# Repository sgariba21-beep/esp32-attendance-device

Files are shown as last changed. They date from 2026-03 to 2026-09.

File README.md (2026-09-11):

# ESP32 Fingerprint Attendance System

Ghanaian schools and institutions still take attendance on paper. A teacher calls a register, marks each name by hand, then copies the totals into another book or a spreadsheet. Roll-call takes class time and the handwritten tallies are easy to miscount and slow to total across a term. This system replaces the register with a fingerprint scan.

An ESP32 device with an R503 fingerprint sensor records each scan, and a Next.js dashboard backed by Supabase handles reporting and the day-to-day management of devices and members. One cloud Supabase project serves every institution, with each tenant's data isolated from the rest. The hardware and software are complete; the first institutional deployment is pending.

---

## Why This Exists

- Ghanaian schools and small institutions track attendance on paper or not at all; the affordable end of the market has no biometric option tied to a reporting dashboard.
- ZKTeco and similar incumbents ship standalone terminals with no multi-tenant cloud dashboard and no remote device management.
- The system is built around term and academic-year structure, with institution type configurable as school, office, or shop.
- Each device is built from off-the-shelf parts at about GHS 1,000.
- The firmware and dashboard are AGPL-3.0 on GitHub; institutions can self-host or use the managed hosted service.

---

## Real-World Deployment

- Status: hardware and software complete; first institutional deployment pending
- Site: [institution name], [town/region]
- Enrolled members: [N]
- Running since: [start date]

Device installed at [institution name]

---

## Architecture

```
┌─────────────────────────────┐
│       ESP32 Devices         │
│  R503 fingerprint sensor    │
│  One device per unit        │
└────────────┬────────────────┘
             │ HTTPS (x-device-secret / x-bootstrap-secret)
             ▼
┌─────────────────────────────┐
│  Supabase Edge Functions    │
│  (cloud)                    │
│  log-attendance             │
│  mark-absent (pg_cron)      │
│  get-enrollment-job         │
│  update-enrollment-job      │
│  register                   │
│  assignment-poll            │
└────────────┬────────────────┘
             │ service role
             ▼
┌─────────────────────────────┐
│   Supabase PostgreSQL       │
│   (cloud)                   │
│   Multi-tenant schema       │
│   RLS policies (defence-in- │
│   depth; dormant for svc    │
│   role access)              │
└─────────────────────────────┘
             ▲
             │ server-side only (service role)
┌────────────┴────────────────┐
│     Next.js Dashboard       │
│     Deployed on Vercel      │
│  All Supabase calls are     │
│  server-side (no browser    │
│  exposure of keys)          │
└─────────────────────────────┘
```

---

## Tech Stack

| Layer | Technology |
|---|---|
| Firmware | Arduino (ESP32), FreeRTOS, R503 fingerprint library, SSD1306 OLED (Adafruit SSD1306 + GFX) |
| Database | Supabase (cloud PostgreSQL + Auth + Storage + pg_cron) |
| Edge functions | Deno (Supabase Edge Functions) |
| Dashboard | Next.js App Router, shadcn/ui, TailwindCSS |
| Dashboard PWA | Installable web app — `manifest.webmanifest` + a minimal service worker (installability only, no offline cache) and an in-app install prompt |
| Hosting | Vercel (dashboard) |

> **Note on Next.js:** This project uses a version with breaking API changes from standard Next.js. Middleware lives in `frontend/proxy.ts`, not `middleware.ts`. Read `frontend/AGENTS.md` before writing any Next.js code.

---

## Hardware

### Components

| Component | Spec |
|---|---|
| Microcontroller | ESP32 (dual-core, 240 MHz) |
| Fingerprint Sensor | R503 Capacitive |
| RTC Module | DS3231 |
| Display (optional) | SSD1306 0.96" 128×64 I²C OLED @ address 0x3C — the firmware runs headless if it is absent or fails to init |
| Carrier PCB | Custom 2-layer KiCad interconnect board — no active parts; seats the ESP32 module and provides keyed connectors for the R503 (JST-SH), the RTC + OLED I²C group, and a JST-GH 5 V input. Source in [`hardware/PCBs/`](hardware/PCBs/) |
| Enclosure | 3D-printed base + lid (+ an OLED bezel variant for display builds). FreeCAD source and print-ready 3MF in [`hardware/CAD files/`](hardware/CAD%20files/) |

### Wiring

| Signal | ESP32 Pin |
|---|---|
| R503 TX → ESP32 RX | GPIO 16 |
| R503 RX → ESP32 TX | GPIO 17 |
| DS3231 SDA | GPIO 21 |
| DS3231 SCL | GPIO 22 |
| OLED SDA | GPIO 21 (shared I²C bus with the DS3231) |
| OLED SCL | GPIO 22 (shared I²C bus with the DS3231) |

---

## Firmware Architecture

Single sketch: `firmware/ClassAttendance_Current_RTC/ClassAttendance_Current_RTC.ino`. Three FreeRTOS tasks pinned across the two cores.

### Tasks

| Task | Core | Responsibility |
|---|---|---|
| `FingerprintTask` | 1 | Scan loop, match against the local fid map, LED feedback, enrollment execution, captive-portal launch on master-finger scan. Writes each scan to SPIFFS then signals `NetworkTask` via binary semaphore. |
| `NetworkTask` | 0 | Provisioning, waiting on scan semaphore from `FingerprintTask`, rotate-then-process SPIFFS queue flush to `log-attendance`, NTP→RTC sync, WiFi reconnect, and a server-reachability watchdog that reboots the device after a sustained inability to reach the backend. |
| `EnrollmentTask` | 0 | Polls `get-enrollment-job`, hands jobs to `FingerprintTask`, reports results durably (retried until acknowledged), acts on the decommission signal (wipes identity and reboots into provisioning). |

Inter-task communication:

- `memQueueSem` is a binary semaphore used only as a signal: `FingerprintTask` gives it after writing a scan to SPIFFS; `NetworkTask` waits on it (or a 15 s periodic timeout) before calling `flushQueue()`. There is no in-memory scan queue.
- Enrollment jobs pass from `EnrollmentTask` to `FingerprintTask` through `currentEnrollJob`, guarded by `enrollMutex` and signalled by `enrollSem`.
- `spiffsMutex` serialises every SPIFFS access across all three tasks.

### Display (OLED)

An optional SSD1306 128×64 panel on the shared I²C bus. `display.begin()` is attempted once in `setup()`; on failure `displayAvailable = false` and the firmware runs headless with no behaviour change. There is no dedicated display task — rendering is driven from a Core-0-safe mailbox. Tasks post card state (idle clock, scan verdict, enrollment step, master-finger confirm, provisioning, OTA) into the mailbox and never touch the `display` object directly. Tier-2 status (queue depth, dropped-record count, degraded / offline) is overlaid on the idle screen; the panel sleeps after 120 s idle and wakes on the next event. The per-institution `member_name_display` setting (fetched via `get-enrollment-job`, cached in SPIFFS with `config_rev`) controls how much of a member's name a scan card shows.

### Offline queue

- **Durability-first:** each scan is written to `/queue.txt` in SPIFFS synchronously inside `FingerprintTask` before any network attempt. The scan is never held only in RAM.
- **Rotate-then-process:** when `NetworkTask` flushes, it atomically renames `/queue.txt` → `/queue_inflight.txt` under the lock, then releases the lock. `FingerprintTask` can keep appending to a fresh `/queue.txt` while the network send runs without holding `spiffsMutex`.
- **Crash recovery:** if power is cut mid-flush, `/queue_inflight.txt` is orphaned. On the next boot, `recoverInflightQueue()` runs before tasks start and merges it back into `/queue.txt`.
- On flush, 5xx/429/network errors keep a record for retry; 4xx drops it.
- Caps: 1000 entries, 256 KB, 7-day age. Oldest records are trimmed first.

### Scan IDs

Each scan gets a `scan_id` of `scan-YYYYMMDDhhmmss-<member-sid>`, with the timestamp read from the DS3231 RTC. The RTC clock survives reboots and power loss and is synced from NTP on boot and after each reconnect.

### OTA

- On boot, with WiFi up and assignment not pending, the device waits a random jitter of 0–120 s (seeded from hardware entropy) before checking for updates. This prevents a fleet-wide power blip from hitting GitHub's 60 req/hr unauthenticated rate limit simultaneously.
- The device GETs `releases/latest` from the GitHub API. Release tags must be `firmware-v<major>.<minor>.<patch>`. The tag version is compared against the compiled-in `FIRMWARE_VERSION`; only a strictly newer version flashes.
- The release's `.bin` asset is streamed through the `Update` library. The sensor LED holds red while writing, and the device reboots into the new image on success.

---

## Database Schema

All dashboard data access uses `createAdminClient()` (service role — bypasses RLS). RLS policies exist as defence-in-depth and will become load-bearing if authenticated client access is introduced.

```sql
-- Institution registry (one row per tenant)
-- type: 'school' | 'office' | 'shop'
-- theme_primary: hex brand colour injected as CSS custom properties server-side (no FOUC)
-- theme_preset: curated palette key (e.g. 'indigo', 'rose') or 'custom'; null → platform default
-- device_secret: shared bootstrap secret — TRANSITIONAL. Will be removed once all
--   devices have been re-provisioned with per-device secrets (devices.device_secret).
-- tracked_weekdays: smallint[] of ISO weekday numbers (1=Mon … 7=Sun) attendance is
--   tracked on. Replaces the removed skip_weekends boolean. log-attendance ignores
--   scans on other days; mark-absent generates no rows for them.
-- time_format: '12h' | '24h' — dashboard clock rendering only; stored times stay UTC / 24h.
-- track_lateness / expected_start_time / late_grace_minutes and
--   track_early_leaving / expected_end_time / early_leave_grace_minutes:
--   optional per-institution punctuality thresholds that drive attendance.punctuality.
-- member_name_display: 'full' | 'first' | 'initial_last' | 'sid' | 'none' — how much of a
--   member's name the device OLED shows on a scan card (enrollment always shows the full name).
-- currency: ISO-4217 display currency for the retail module (formatting only, no FX).
-- sell_products / sell_services / loyalty_enabled: shop-module switches.
-- status: 'active' | 'suspended' | 'deactivated' — non-active tenants are gated to /suspended.
-- config_rev: bigint bumped by the institutions_touch trigger on any row change; the device
--   polls it to know its cached device_config is stale. updated_at is bumped by the same trigger.
institutions    (id, name, type, logo_url, label_member, label_members, label_group,
                 label_unit, label_period, label_staff, label_staff_plural,
                 track_students, track_staff, student_scan_mode, staff_scan_mode,
                 tracked_weekdays, timezone, time_format, track_lateness,
                 expected_start_time, late_grace_minutes, track_early_leaving,
                 expected_end_time, early_leave_grace_minutes, member_name_display,
                 currency, sell_products, sell_services, loyalty_enabled, status,
                 device_secret, config_rev, created_at, updated_at,
                 theme_primary, theme_preset)

-- Members (students, staff, customers, etc.) — scoped to institution
-- member_type: 'student' | 'staff'  (default 'student')
-- sid is UNIQUE PER INSTITUTION (institution_id, sid), not globally
-- device_id FK is ON DELETE SET NULL (device deletion preserves member records)
members         (id, sid, fullname, group_name, unit_name, fin1, fin2, status, member_type,
                 device_id→devices SET NULL, institution_id, created_at)

-- One ESP32 per unit — scoped to institution
-- device_secret: per-device secret issued at provisioning time by /assignment-poll
-- revoked: true blocks the device from logging attendance (instant lockout)
-- provisioning_token: issued by /register, required by /assignment-poll (H7)
devices         (id, group_name, unit_name, display_name, mac, provisioning_token,
                 device_secret, revoked, institution_id)

-- Academic periods — scoped to institution (nullable for office/shop-type institutions)
periods         (id, term, year, status, start_date, end_date, institution_id)

-- Attendance records — scoped to institution
-- status: 'present' | 'absent'
-- scan_type: 'present' | 'time_in' | 'time_out'  (CHECK constraint — 'absent' is a status, not a scan_type)
-- punctuality: 'on_time' | 'late' | 'early_leave' | null — verdict fixed at scan time from the
--   institution's thresholds; null when tracking is off or the row is a mark-absent placeholder
-- date/time are stored in the INSTITUTION's timezone (log-attendance + mark-absent agree)
-- scan_id is UNIQUE PER INSTITUTION (institution_id, scan_id); dedup also on (member_id, date, scan_type)
-- device_id FK is ON DELETE SET NULL
attendance      (id, member_id→members, period_id→periods, device_id→devices SET NULL,
                 date, time, status, scan_type, punctuality, scan_id, institution_id)

-- Remote fingerprint enrollment queue
-- command: 'register' | 'delete' | 'clearall' | 'register-master' | 'delete-master'
-- member_id: FK→members (renamed from student_id). NULL for clearall / register-master / delete-master.
-- allow_overwrite: operator confirmed overwriting an already-occupied sensor slot
--   (register / register-master only). The device refuses an occupied slot unless this is true.
-- dispatched_at / attempts / last_error: dispatch tracking. get-enrollment-job re-delivers a job
--   stuck in_progress past a timeout and auto-fails it (with last_error) after a capped number of
--   attempts. The enrollment_jobs_status_guard trigger makes 'completed' / 'failed' terminal.
-- device_id FK is ON DELETE SET NULL
enrollment_jobs (id, device_id→devices SET NULL, member_id→members, finger_slot,
                 command, status, fid, note, allow_overwrite, dispatched_at, attempts,
                 last_error, institution_id, created_at)

-- Holidays (date ranges) — scoped to institution
-- recurring: true = matched by month/day every year (year-wrap ranges supported)
holidays        (id, label, start_date, end_date, recurring, institution_id)

-- Dashboard user roles — scoped to institution (platform_admin has null institution_id)
-- assigned_device_id: FK that pins a session to one device. REQUIRED for teacher/staff
--   (unresolved → they see nothing); OPTIONAL for admin (bound → records + enrollment
--   scoped to that device; unbound → whole institution). Preferred over the legacy
--   assigned_unit string; backfilled by migration. Resolved by dal.ts resolveDeviceScope().
profiles        (id→auth.users, role, assigned_unit, assigned_device_id→devices SET NULL,
                 institution_id)

-- Deferred SPIFFS-wipe queue — no FK, survives device row deletion
device_resets   (device_id UUID, created_at)

-- Polling watermark — one row per institution, updated by triggers on attendance,
-- members, devices, and periods. The dashboard polls /api/changes every 12 s and
-- calls router.refresh() only when last_change_at has advanced. Replaces the
-- previous SSE-based realtime stream (eliminated REPLICA IDENTITY FULL WAL amplification).
institution_activity  (institution_id PK→institutions, last_change_at timestamptz)
```

### Migrations

All migrations are in `backend/supabase/migrations/`. They must be reviewed and applied manually — do not auto-apply to cloud.

---

## Auth & RBAC

Authentication uses Supabase Auth (server-side only — all Supabase calls go through Next.js server components and API routes, never from the browser).

### Account Types

| Role | Scope | Access |
|---|---|---|
| `platform_admin` | Cross-institution (no institution_id) | All pages, bypasses all role gates, operates via service role. Responsible for creating institutions and bootstrapping first super_admin per institution. |
| `super_admin` | Institution-scoped | All pages — devices, enrollment, promotion, academic, members, attendance, user management. Can manage users within their institution but cannot create platform_admins. |
| `admin` | Institution-scoped (optionally device-scoped) | Members, academic, promotion, attendance — no devices or enrollment. May optionally be pinned to a single device via `assigned_device_id`; when pinned, attendance/members and enrollment are scoped to that device, otherwise the whole institution. |
| `teacher` | Institution-scoped, unit-scoped | Read-only attendance and members, filtered to their `assigned_device_id` (FK, with `assigned_unit` string-match fallback for unbackfilled profiles). |
| `staff` | Institution-scoped, unit-scoped | Same as teacher — read-only attendance and members, filtered to their unit. The `/staff` roster page is not visible in the nav for this role. |
| `cashier` | Institution-scoped (shop type) | Sales, Clients, and Catalog pages only. Intended for retail staff at shop-type institutions. Cannot access attendance, members, devices, or admin pages. |

### How it works

- `frontend/lib/supabase/dal.ts` exports `verifySession()`, `requireRole(...roles)`, `getInstitution(institutionId)`, `resolveInstitutionScope(session, institutionParam?)`, and `resolveDeviceScope(session)` (returns `{ mode: 'all' | 'device' | 'none' }` — the single device a session is pinned to, if any).
- `verifySession()` and `getInstitution()` are both `cache()`-wrapped — one DB hit per render cycle regardless of how many components call them.
- `requireRole()` calls `verifySession()` and redirects to `/unauthorized` if the role doesn't match. `platform_admin` bypasses all role checks.
- `resolveInstitutionScope()` enforces tenant scoping: platform_admin may pass an explicit institution param; all other roles are always locked to their own `institution_id` regardless of query params.
- **Fail-closed:** an authenticated user with no `profiles` row (or no role) is redirected to `/unauthorized` — it does **not** default to any role. Public sign-up is disabled in Supabase Auth; accounts are created only via `/users` and `/onboarding`.
- **Tenant ownership:** because the dashboard uses the service role (RLS bypassed), every mutating server action verifies the target record belongs to the caller's institution via `lib/supabase/ownership.ts` (`ownsRecord`). `platform_admin` is cross-tenant by design.
- The dashboard layout calls `verifySession()` and passes `role` to the sidebar and mobile nav, which filter nav items by role.
- `teacher` and `staff` are always device-scoped via `assigned_device_id` (FK, preferred) or `assigned_unit` (legacy string); an unresolved assignment means they see nothing, never everything. `admin` may optionally carry the same binding. Attendance and member data — and the CSV export (`/api/attendance/export`) — is filtered server-side to that device before rendering.
- Run `node scripts/check-rbac.mjs` (from `frontend/`) to verify every page under `(dashboard)` has a `requireRole(` call. Exits 1 with a list if any are ungated.

### Creating the first super_admin (per institution)

After creating an institution in Supabase, insert a profile row for the Supabase Auth user:

```sql
insert into profiles (id, role, institution_id)
values ('<auth-user-uuid>', 'super_admin', '<institution-uuid>');
```

Additional accounts are managed through the `/users` page in the dashboard.

---

## Dashboard Pages

### Attendance & roster (all institution types)

| Route | Access | Description |
|---|---|---|
| `/` | All roles | Overview — today's present/absent counts, attendance rate, and a recent-activity feed (last 8 scans). `teacher`/`staff` see only their unit. `platform_admin` sees a cross-tenant summary: institution count, active members, devices online, and total scans today. |
| `/attendance` | All roles | Attendance records with date, period, member, unit, status, and type filters. Per-member stats panel. Results paginated at 50 rows. `teacher`/`staff` see only their unit; a teacher with no device assigned sees an empty-state prompt to contact their administrator. Time-in/time-out pairs shown on a single row, with **Late** / **Early** badges when the institution has punctuality thresholds enabled. CSV export available. |
| `/members` | All roles except cashier | Member roster (non-staff). `teacher`/`staff` see only their unit, no edit controls. |
| `/staff` | super_admin, admin, platform_admin | Staff member roster. Visible only when `track_staff = true`. |
| `/devices` | super_admin, platform_admin | ESP32 device registry and provisioning — assign unregistered devices to units, revoke devices. Search + institution filter for platform_admin. Devices only enter via physical provisioning (no manual create). |
| `/academic` | super_admin, admin, platform_admin | Academic periods and holidays. Nav label is "Academic" (school), "Periods & Holidays" (office), or "Closed Days" (shop — holidays only). Supports recurring (yearly) holidays matched by month/day. |
| `/enrollment` | super_admin, platform_admin | Fingerprint enrollment job queue — `register`, `delete`, `clearall`, `register-master`, `delete-master` commands sent to devices, with retry / cancel controls for failed or stuck jobs (jobs stranded `in_progress` are also re-delivered and self-healed server-side). Validates member institution + device assignment before dispatching. Institution column for platform_admin. |
| `/promotion` | super_admin, admin, platform_admin | Bulk year-end promotion — moves members to the next group, resets finger slots, deactivates final-year members. School-type institutions only. |
| `/settings` | super_admin, platform_admin | Institution config — name, logo, brand colour, type, label overrides, per-type scan modes, tracked weekdays (7-day selector, replaces skip_weekends), late-arrival / early-departure thresholds, timezone, 12h/24h time display, name-shown-on-device, and (shop) currency / offerings / loyalty toggles. |
| `/institutions` | platform_admin | All institutions with member/device counts. Edit or delete any institution (deletion fans out SPIFFS wipe to all assigned devices). |
| `/institutions/[id]` | platform_admin | Edit a specific institution's settings. |
| `/onboarding` | platform_admin | Create a new institution and its first super_admin account. Includes timezone selector (Africa/Accra default) and neutral label presets for shop-type institutions. |
| `/users` | super_admin, admin, platform_admin | Dashboard account management. `admin` can view the list and change their own password only. `super_admin`/`platform_admin` can create, edit, and delete accounts. |
| `/unauthorized` | — | Shown when a user navigates to a page their role cannot access. |
| `/suspended` | — | Shown when a user's institution is suspended/deactivated. Lives outside `(dashboard)` to avoid re-entering `verifySession`. Sign-out is the only available action. |

### Retail / loyalty (shop-type institutions only)

| Route | Access | Description |
|---|---|---|
| `/sales` | super_admin, admin, cashier | Record sales transactions. Line-item entry with catalog lookup, optional staff assignment, per-sale note. Low-stock warning surfaced as a non-blocking alert after a successful sale. |
| `/clients` | super_admin, admin, cashier | Client roster with visit history and loyalty point balance. Search by name or phone. |
| `/catalog` | super_admin, admin, cashier | Products and services catalog. Stock quantity tracked for products; low-stock threshold warnings on the Reports page. |
| `/rewards` | super_admin, admin | Loyalty reward redemption and tier management. Gated additionally by `loyalty_enabled` on the institution. |
| `/reports` | super_admin, admin | Sales analytics — daily/weekly takings, revenue by client and staff member, popular items, visit frequency, low-stock products, loyalty rewards issued. CSV export for takings, client revenue, and staff revenue. |

### Screenshots

Dark-mode captures of the dashboard live in [`images/`](images/) — one set per
institution type (38 pages in all). See [`images/README.md`](images/README.md)
for the full index.

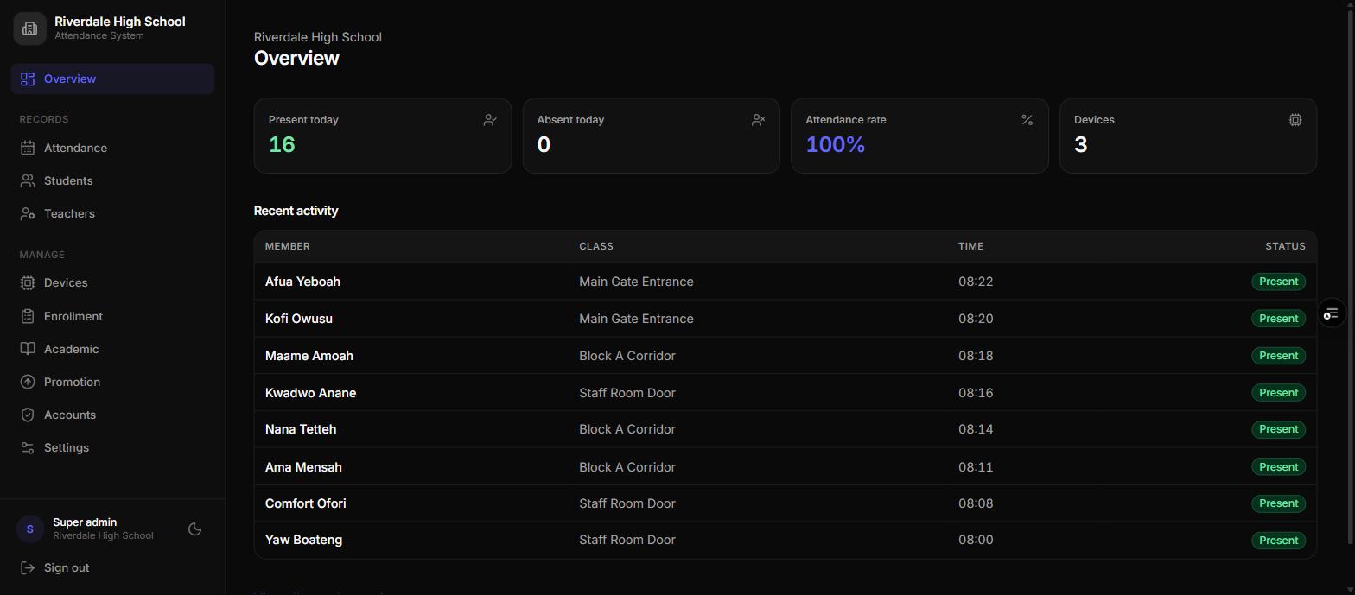
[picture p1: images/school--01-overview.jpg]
School — overview

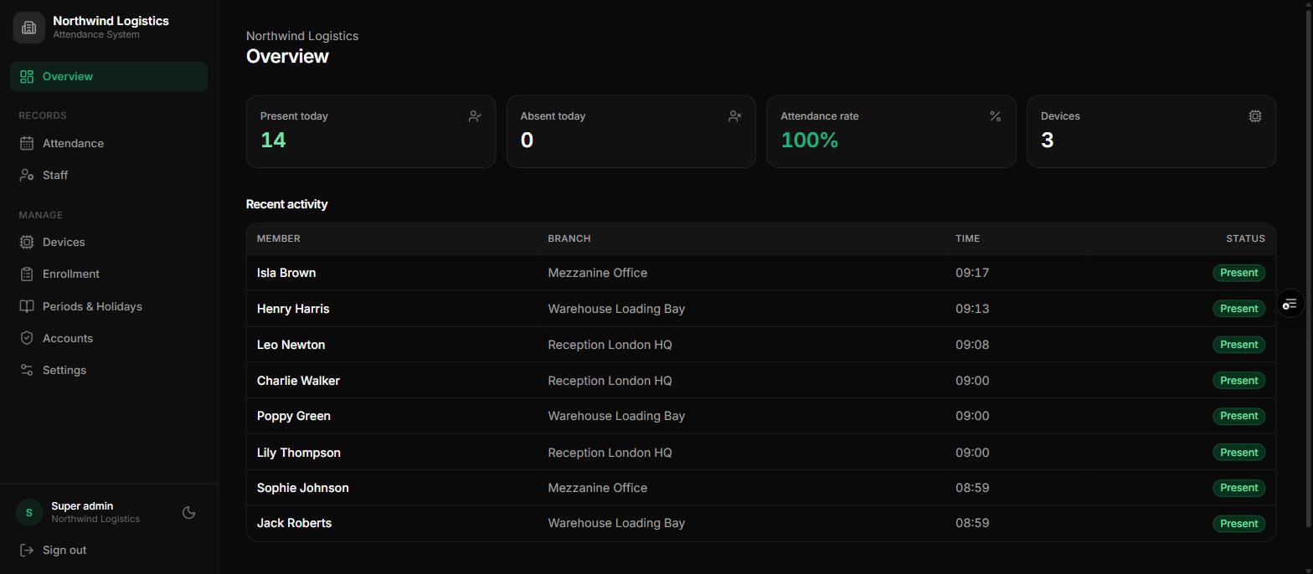
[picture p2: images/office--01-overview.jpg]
Office — overview

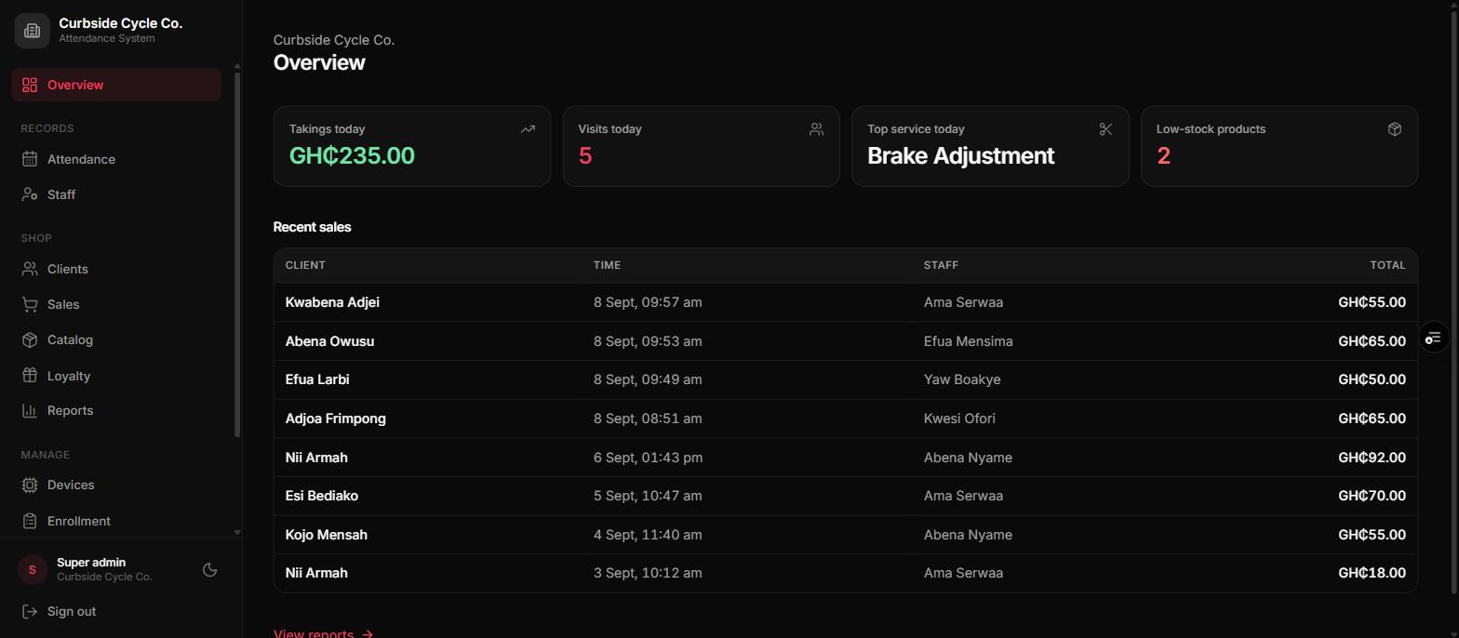
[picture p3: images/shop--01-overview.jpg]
Shop — overview with the retail module


> **Disclaimer — dummy data.** Every screenshot is taken from throwaway demo
> institutions (Riverdale High School, Northwind Logistics, Curbside Cycle Co.)
> created solely for documentation. All names, clients, sales, attendance
> records and figures shown are fabricated — not real people, and not the real
> institutions that use this system.

---

## Device Authentication & Provisioning

### Provisioning (new devices)

1. Device boots with no `device_identity.json` in SPIFFS.
2. Calls `POST /register` with its MAC address (`x-bootstrap-secret` header).
3. Receives a `device_id`, a `provisioning_token`, and `status: "pending"`. The device persists both to `provisioning.json` so a reboot keeps the token.
4. Shows yellow breathing LED and polls `POST /assignment-poll` every 5 s, sending `{ device_id, provisioning_token }`.
5. An admin assigns the device from the dashboard `/devices` page.
6. Poll returns `status: "assigned"` with `institution_id`, `device_secret` (per-device), `display_name` — **only if the provisioning_token matches** (otherwise 401).
7. Device writes `device_identity.json` to SPIFFS, deletes `provisioning.json`, and begins normal operation.

> **TLS:** the firmware validates server certificates (`certs.h` → `ROOT_CA_BUNDLE`, includes intermediates for WE1/Sectigo DV E36 — mbedTLS cannot do AIA fetching).
> The bootstrap secret lives in `secrets.h` (gitignored). Copy `secrets.example.h` → `secrets.h` and set the same value as the `BOOTSTRAP_SECRET` secret in Supabase Edge Functions.

### Normal operation

- Every scan: `POST /log-attendance` with `{ device_id, ... }` body and `x-device-secret: <per-device secret>` header. A transitional dual-path also accepts the legacy shared `institutions.device_secret` for devices not yet re-provisioned.
- Enrollment polling: `POST /get-enrollment-job` with `{ device_id }`, authenticated via per-device secret. A job left `in_progress` past a timeout (device rebooted, ack lost) is re-delivered, and auto-failed after a capped number of attempts.
- Enrollment result: `POST /update-enrollment-job` with `{ id, device_id, institution_id, status, ... }`, authenticated via per-device secret. `institution_id` is derived server-side from the device row — the body value is ignored. The device retries this report until it lands (firmware ≥ 1.10.0); the `enrollment_jobs_status_guard` trigger keeps a terminal `completed` / `failed` status from being pulled backwards by a late write.
- Decommission signal: if `get-enrollment-job` returns `decommissioned: true`, the device wipes its identity and reboots. The `device_resets` row persists until the device re-registers (not consumed on read — durable against race conditions).
- `pg_cron` calls `POST /mark-absent` daily with `x-cron-secret`. Processes institutions in batches of 8 concurrently. **Requires the `pg_net` extension** — enable it in the Supabase dashboard under Database → Extensions.

### Revoking a device

Set `devices.revoked = true` in the database. The device's next `log-attendance` call receives 401 immediately. For permanent decommission, also insert into `device_resets`.

### OTA

Firmware checks `https://api.github.com/repos/sgariba21-beep/esp32-attendance-device/releases/latest` on boot after a random jitter delay. Releases must be tagged `firmware-v<version>` (e.g. `firmware-v1.10.0`; current `FIRMWARE_VERSION` is `1.10.0`). The `.bin` asset is downloaded and flashed via the ESP32 `Update` library.

---

## Key Files

```
esp32-attendance-device/
├── README.md
├── docs/
│   ├── README.md                           ← index: which document is for whom, what to hand over
│   ├── for-clients/                        ← PDFs for institutions: role guides, type guides, privacy note
│   ├── for-operators/                      ← platform manual, technical docs, secret-rollout guide, e2e checklist
│   └── source/                             ← Markdown sources + build.py — edit these, not the PDFs
├── firmware/
│   └── ClassAttendance_Current_RTC/
│       ├── ClassAttendance_Current_RTC.ino ← ESP32 firmware (single sketch)
│       ├── certs.h                         ← ROOT_CA_BUNDLE (includes intermediates)
│       ├── secrets.example.h               ← template for secrets.h (gitignored)
│       └── secrets.h                       ← BOOTSTRAP_SECRET — gitignored, create from example
├── backend/
│   └── supabase/
│       ├── config.toml                     ← edge function config (verify_jwt = false for all)
│       ├── migrations/                     ← applied to cloud manually; do NOT auto-apply
│       └── functions/
│           ├── log-attendance/             ← dual-path auth: per-device + transitional shared secret
│           ├── mark-absent/                ← BATCH_SIZE=8 concurrent; recurring holiday support
│           ├── get-enrollment-job/         ← per-device auth; decommission signal is persistent
│           ├── update-enrollment-job/      ← per-device auth; institution derived from device row
│           ├── register/
│           └── assignment-poll/            ← issues per-device secret on first assignment
└── frontend/
    ├── proxy.ts                            ← Next.js middleware (NOT middleware.ts); matcher excludes
    │                                         /api, _next, and the PWA assets (manifest.webmanifest, sw.js, icons/)
    ├── next.config.ts                      ← sends Cache-Control: no-cache for /sw.js
    ├── AGENTS.md                           ← read before writing any Next.js code
    ├── scripts/
    │   ├── check-rbac.mjs                 ← CI guard: exits 1 if any dashboard page lacks requireRole
    │   └── generate-icons.mjs             ← regenerates the PWA icon set from the SVG source
    ├── app/
    │   ├── manifest.ts                    ← web app manifest, served at /manifest.webmanifest (platform branding only)
    │   ├── (auth)/login/                  ← password is NOT trimmed before submission
    │   ├── (dashboard)/
    │   │   ├── layout.tsx                 ← verifySession, generateMetadata (dynamic tab title)
    │   │   ├── (admin)/layout.tsx         ← route-group gate for admin-only pages
    │   │   ├── attendance/
    │   │   ├── members/
    │   │   ├── staff/
    │   │   ├── devices/
    │   │   ├── academic/
    │   │   ├── enrollment/
    │   │   ├── promotion/
    │   │   ├── settings/
    │   │   ├── institutions/[id]/
    │   │   ├── onboarding/
    │   │   ├── users/
    │   │   ├── sales/                     ← shop only; low-stock warning after sale
    │   │   ├── clients/                   ← shop only; visit history + loyalty balance
    │   │   ├── catalog/                   ← shop only; products + services
    │   │   ├── rewards/                   ← shop only; loyalty_enabled gate
    │   │   └── reports/                   ← shop only; takings, revenue, low-stock analytics
    │   ├── api/
    │   │   ├── signin/
    │   │   ├── signout/
    │   │   ├── enrollment-stream/         ← SSE stream for enrollment job updates (kept)
    │   │   ├── realtime-stream/           ← 410 tombstone — use /api/changes instead
    │   │   ├── changes/                   ← watermark poll endpoint (replaces SSE stream)
    │   │   ├── attendance/export/         ← CSV export with full filter parity
    │   │   └── reports/{takings,clients,staff}/export/  ← shop report CSV exports
    │   ├── suspended/                     ← institution suspended; sign-out only
    │   └── unauthorized/
    ├── lib/
    │   ├── types.ts                       ← shared TS types
    │   ├── theme.ts                       ← per-institution brand theming
    │   └── supabase/
    │       ├── dal.ts                     ← verifySession, requireRole, getInstitution,
    │       │                                 resolveInstitutionScope, resolveDeviceScope, UserRole
    │       └── server.ts                  ← createAuthClient, createAdminClient
    └── components/
        ├── sidebar.tsx
        ├── mobile-header.tsx
        ├── mobile-bottom-nav.tsx
        ├── theme-toggle.tsx
        ├── realtime-refresh.tsx           ← polls /api/changes every 12 s; router.refresh() on watermark advance
        ├── session-manager.tsx            ← inactivity timeout + sessionStorage guard
        ├── pwa/                           ← service-worker registration + in-app install prompt
        └── ui/
            └── single-select.tsx
```

---

## Phase Status

| Phase | Description | Status |
|---|---|---|
| 1 | Cloud deployment (single-tenant) | ✅ Complete |
| 2 | Multi-tenant schema + edge functions | ✅ Complete |
| 3 | Firmware provisioning flow | ✅ Complete |
| 4 | Frontend — de-brand, institution config, devices page, settings | ✅ Complete |
| 5 | Captive portal — WiFi-only | ✅ Complete |
| 6 | Retail / loyalty module — shop-type tenants, cashier role, sales/clients/catalog/rewards/reports | ✅ Complete |
| 7 | Security hardening — per-device secrets, SPIFFS-only durable queue, tenant isolation fixes, polling watermark | ✅ Complete |
| 8 | OLED display — device-side status screen: idle clock, scan / enrollment / portal / master-confirm cards, degraded & offline states | ✅ Complete |
| 9 | Reliability & reach — enrollment-job self-healing (re-delivery, retry/cancel, status guard), firmware server-reachability watchdog, per-institution tracked weekdays / time format / punctuality thresholds, installable PWA | ✅ Complete |

---

## Roadmap

- [x] Installable PWA (add-to-home-screen) — native iOS/Android app still TBD
- [ ] GES-formatted report exports
- [ ] SMS attendance notifications
- [ ] Analytics dashboard with term-over-term trends
- [ ] Offline-first mobile enrollment app
- [ ] Multi-device per unit support

---

## Contributing

See [CONTRIBUTING.md](CONTRIBUTING.md) for the repo layout and local setup steps for the frontend and firmware.

---

## License

AGPL-3.0. See [LICENSE](LICENSE).

Network use of a modified version requires releasing source under the same license. Contact sgariba21@gmail.com for commercial licensing or self-hosting arrangements.

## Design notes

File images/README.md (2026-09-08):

# Dashboard screenshots — demo institutions

Dark-mode captures of the live dashboard (`esp32-attendance-device-y9cs.vercel.app`),
one set per institution type. Taken 2026-09-08 against three throwaway demo
tenants seeded in the production Supabase project alongside the real ones (the
real institutions are untouched and never appear in these shots — every capture
was taken while signed in as the demo tenant's own `super_admin`, which the app
hard-scopes to that tenant). All 18 `shop--*` shots plus the two settings shots
were re-taken after the `7bd44ab` "drop salon vocabulary" cleanup reached the
live deployment, so nothing here reads "stylist".

Filenames: `<type>--<nn>-<page>.jpg`. JPEG because that is what the capture path
produces; ~1250–1570 px wide.

## The demo institutions

| Type | Name | Timezone | Currency | Brand | Admin login |
|---|---|---|---|---|---|
| `school` | Riverdale High School | Africa/Accra | GHS | Indigo `#6366f1` | `riverdale.admin@example.com` |
| `office` | Northwind Logistics | Europe/London | GBP | Emerald `#10b981` | `northwind.admin@example.com` |
| `shop`  | Curbside Cycle Co. | Africa/Accra | GHS | Rose `#f43f5e` | `curbside.admin@example.com` |

Each was created through the platform-admin **Create institution** flow, then
seeded via SQL: ~8–26 members, 3 devices, an active + a past period, 1–2
holidays, 5 enrolment jobs, and ~12–18 days of attendance history plus a partial
current day. Riverdale and Northwind track late arrivals / early departures;
Curbside adds the full retail module — 15 clients, 8 products, 6 services, 26
sales, 3 loyalty rules with 5 issuances.

## Inventory

### school/ — Riverdale High School (11)
| File | Page |
|---|---|
| `school--01-overview.jpg` | Overview |
| `school--02-attendance.jpg` | Attendance (records) |
| `school--03-students.jpg` | Students |
| `school--04-teachers.jpg` | Teachers |
| `school--05-devices.jpg` | Devices |
| `school--06-enrollment.jpg` | Enrollment |
| `school--07-academic-terms.jpg` | Academic → Terms |
| `school--08-academic-holidays.jpg` | Academic → Holidays |
| `school--09-promotion.jpg` | Promotion (empty state — see notes) |
| `school--10-accounts.jpg` | Accounts |
| `school--11-settings.jpg` | Settings (identity + branding) |

### office/ — Northwind Logistics (9)
| File | Page |
|---|---|
| `office--01-overview.jpg` | Overview |
| `office--02-attendance.jpg` | Attendance (records) |
| `office--03-staff.jpg` | Staff |
| `office--04-devices.jpg` | Devices |
| `office--05-enrollment.jpg` | Enrollment |
| `office--06-periods.jpg` | Periods & Holidays → Quarters |
| `office--07-holidays.jpg` | Periods & Holidays → Holidays |
| `office--08-accounts.jpg` | Accounts |
| `office--09-settings.jpg` | Settings (identity + branding) |

### shop/ — Curbside Cycle Co. (18)
| File | Page |
|---|---|
| `shop--01-overview.jpg` | Overview |
| `shop--02-attendance.jpg` | Attendance (records) |
| `shop--03-staff.jpg` | Staff |
| `shop--04-clients.jpg` | Clients |
| `shop--05-sales.jpg` | Sales |
| `shop--06-catalog-products.jpg` | Catalog → Products |
| `shop--07-catalog-services.jpg` | Catalog → Services |
| `shop--08-loyalty-rules.jpg` | Loyalty → Rules |
| `shop--09-loyalty-history.jpg` | Loyalty → History |
| `shop--10-reports-takings.jpg` | Reports → Takings |
| `shop--11-reports-by-staff.jpg` | Reports → By staff |
| `shop--12-reports-items.jpg` | Reports → Items |
| `shop--13-reports-low-stock.jpg` | Reports → Low stock |
| `shop--14-devices.jpg` | Devices |
| `shop--15-enrollment.jpg` | Enrollment |
| `shop--16-closed-days.jpg` | Closed Days |
| `shop--17-accounts.jpg` | Accounts |
| `shop--18-settings.jpg` | Settings (identity + branding; "Shop type tracks staff") |

## Notes

- **Promotion (school):** shows the "no devices set up" empty state. The
  promotion calculator derives the form ladder from *device* `group_name`s
  (expecting `Form 1`, `Form 2`, …); the demo's devices are named by physical
  location (`Main Gate`, `Block A`, …), so no ladder is inferred. Real content
  would need devices organised per year-group.
- **Accounts** pages show a single account each — the tenant's first
  `super_admin`. Additional accounts can only be added through the in-app
  "Add account" flow.
- `member_name_display` and a couple of `discount`-driven zero-total sales were
  left at defaults / tidied; nothing else was hand-corrected.

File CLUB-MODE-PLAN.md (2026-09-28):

# Club Mode — Session-Based Attendance

**Status:** Phases 1 and 2 **live in cloud** (2026-09-26) and verified end to end.
Phase 3 migrations **live in cloud** (2026-09-27); dashboard on `club-mode`.
Phase 4 backend **live in cloud** (2026-09-28): migration applied, `log-attendance` v17
and `get-enrollment-job` v16 deployed, verified over HTTPS. Firmware 1.11.0 built but
**not released** (no `firmware-v1.11.0` tag) and not yet tested on hardware.
**Target:** A 4th institution type, `club`, whose unit of attendance is a *meeting*
rather than a *day*.

<!-- Do NOT auto-apply any migration in this document to cloud. Review first. -->

---

## 1. The problem

The system today assumes every tenant takes attendance **every tracked weekday**.
That assumption is load-bearing in four places:

| Where | What it assumes |
|---|---|
| `attendance` unique constraint `(member_id, date, scan_type)` — [20260614140000](backend/supabase/migrations/20260614140000_add_scan_type_and_device_mode.sql) | One attendance event per member per day. Two meetings on the same day collide; the second is swallowed as a duplicate scan. |
| `institutions.tracked_weekdays` | Attendance happens on a fixed weekly pattern. Cannot express "2nd Saturday monthly", let alone "this one Thursday". |
| `log-attendance` weekday gate — [index.ts:164](backend/supabase/functions/log-attendance/index.ts:164) | A scan on an untracked day is **silently discarded**. An impromptu meeting's scans vanish. |
| `mark-absent` daily `pg_cron` | Every active member is marked absent on every tracked day. A club meeting weekly would accrue six false absences a week. |

A club, society, committee, co-op or training cohort meets weekly, monthly, or on
no schedule at all; may run for years or dissolve in a term; and wants to know
*who came to the meetings that actually happened*.

The fix is to make a **meeting** a first-class row that attendance hangs off.

---

## 2. Decisions already taken

Recorded so they are not relitigated at implementation time.

| Decision | Choice | Consequence |
|---|---|---|
| How a meeting starts | **Scheduled in the dashboard**, plus **opened at the device** by a master finger for impromptu ones | No first-scan auto-open. Phase 4 firmware is required only for the ad-hoc path. |
| How a meeting ends | Scheduled meetings carry their own end time; ad-hoc ones close on a second master press; hard end-of-day backstop | Needs a sweep job more frequent than the current daily cron. |
| Ad-hoc master press while offline | **Must work offline** (decided at Phase 1 start). Mechanism deferred to Phase 4 | Phase 1 deliberately adds no constraint that would preclude it — see §8 B. |
| Do absences exist | **Per-tenant setting** (`institutions.track_absences`) | Some clubs enforce attendance, some do not. One flag, not two code paths. |
| Scoping | **New institution type `club`** | Mirrors how `shop` was added. A school cannot host a club inside its own tenant — accepted. |
| Scan with no meeting open | **Reject**, device shows "No meeting open" | Device must know meeting state locally. See §6 and Open Decision A. |
| Periods / seasons | **Clubs have no periods** | Lifecycle handled by the existing `institutions.status` (`active` / `suspended` / `deactivated`). |
| Hardware | Device only, same as now | No manual / phone check-in path. Not in scope. |

---

## 3. Why this is safe for existing tenants

Every attendance row that exists today has `meeting_id IS NULL`. The day-keyed
unique constraint is replaced by two keys that use **NULL semantics** to tell the
modes apart:

```sql
-- daily-mode (school / office / shop): meeting_id is always NULL, and
-- NULLS NOT DISTINCT makes those NULLs equal -> exactly the old key.
-- club: one row per meeting per day.
unique nulls not distinct (member_id, date, scan_type, meeting_id)

-- club: one row per member per meeting per scan type. Default NULLS DISTINCT,
-- so daily rows (NULL meeting_id) never collide -> constrains club rows only.
unique (meeting_id, member_id, scan_type)
```

No backfill, no data migration, no behaviour change for any live tenant. This is
the property the whole plan turns on — if it stops holding, stop and re-plan.

> **Correction to the first draft of this plan.** It proposed *partial* indexes
> (`… where meeting_id is null`). That would have broken production:
> [mark-absent](backend/supabase/functions/mark-absent/index.ts) upserts with
> `onConflict: "member_id,date,scan_type"`, which PostgREST sends as
> `ON CONFLICT (member_id, date, scan_type) DO NOTHING`. Postgres only accepts a
> partial index as the conflict arbiter if the `ON CONFLICT` clause repeats its
> `WHERE` predicate, and PostgREST cannot send one — so every tenant's nightly
> absence run would have errored (error `42P10`), silently, because mark-absent
> reports per-institution failures as strings inside a `200`. Both keys above are
> non-partial, so PostgREST can target them by column list. `NULLS NOT DISTINCT`
> needs Postgres 15+; cloud runs 17. Verified locally — see §7 Phase 1.
>
> The old `(member_id, date, scan_type)` key is **kept** in Phase 1 for the same
> reason, and dropped in Phase 2 only after mark-absent is redeployed with the new
> conflict target.

Two further pieces of existing machinery this plan leans on:

- **The device already polls every 10 s.** `get-enrollment-job` is polled on
  `ENROLL_POLL_MS = 10000` ([firmware:68](firmware/ClassAttendance_Current_RTC/ClassAttendance_Current_RTC.ino:68))
  and its response already carries `device_config_*` fields behind a `config_rev`
  staleness check ([get-enrollment-job:118](backend/supabase/functions/get-enrollment-job/index.ts:118)).
  Meeting state rides on a channel that already exists.
- **Fingerprint roles are free-form strings.** `fidMapRole` is a per-fid `String`
  in the SPIFFS fid map ([firmware:222](firmware/ClassAttendance_Current_RTC/ClassAttendance_Current_RTC.ino:222)),
  persisted as `fid,uniqueId,role,name` CSV. A second master finger is a new role
  value plus one new branch at [firmware:2779](firmware/ClassAttendance_Current_RTC/ClassAttendance_Current_RTC.ino:2779) —
  not a redesign.

---

## 4. Data model

### 4.1 New table: `meetings`

```sql
meetings (
  id                   uuid primary key default gen_random_uuid(),
  institution_id       uuid not null references institutions(id) on delete cascade,
  device_id            uuid references devices(id) on delete set null,
  title                text,
  starts_at            timestamptz not null,  -- scheduled start, or open time for ad-hoc
  ends_at              timestamptz,           -- scheduled end; null on an open ad-hoc meeting
  opened_at            timestamptz,           -- actual
  closed_at            timestamptz,           -- actual
  origin               text not null check (origin in ('scheduled','device')),
  status               text not null check (status in ('scheduled','open','closed','cancelled')),
  absences_written_at  timestamptz,           -- idempotency guard for the close sweep
  created_at           timestamptz not null default now()
)
```

**Why `timestamptz` and not the `date` + `time` pair used by `attendance`?**
Because meeting assignment must be resolved by *instant containment* (§5), and the
existing local-wall-clock columns cannot express a range unambiguously across DST
or a timezone edit. `attendance.date` / `attendance.time` are **left exactly as they
are**, so every existing report, filter and CSV export keeps working untouched.

`device_id` uses `ON DELETE SET NULL`, matching the deliberate pattern on
`attendance` and `members` — deleting a device must never destroy history.

As built, the table also carries integrity CHECKs: `ends_at >= starts_at` (`>=` so
an ad-hoc meeting opened and closed in the same second is still closable); a
scheduled meeting must have `ends_at`; `status = 'open'` requires `opened_at`;
`status = 'closed'` requires `closed_at`; titles are NULL or 1–120 non-blank
characters. It deliberately does **not** check that `origin = 'device'` implies a
`device_id` — that would make `DELETE FROM devices` fail, because `SET NULL` would
violate it.

Also deliberately left out until Phase 4, because they depend on how the offline
master press is replayed (§8 B): "at most one open meeting per device", and an
idempotency key for replayed device events. *Phase 4:* the key is
`meetings.device_ref` with `UNIQUE (device_id, device_ref)`; "one open ad-hoc meeting
per device" is enforced by `device_meeting_event()` (a newer one closes an older one
at its open time), not by a constraint, because events may arrive in any order.

### 4.2 New table: `meeting_schedules` (Phase 3)

Recurrence rules, materialised into `meetings` rows ahead of time. Attendance
carries a real FK, so meetings cannot be computed on the fly.

```sql
meeting_schedules (
  id                uuid primary key default gen_random_uuid(),
  institution_id    uuid not null references institutions(id) on delete cascade,
  device_id         uuid references devices(id) on delete set null,
  title             text,
  freq              text not null check (freq in ('weekly','monthly_nth_weekday')),
  interval_n        smallint not null default 1,  -- every N weeks
  weekday           smallint check (weekday between 1 and 7),  -- ISO, 1 = Mon
  nth               smallint,                     -- monthly: 1..5, or -1 = last
  start_time        time not null,
  duration_minutes  integer not null default 120,
  active            boolean not null default true,
  created_at        timestamptz not null default now()
)
```

Deliberately **not** full RRULE. Weekly, every-N-weeks, and monthly-nth-weekday
cover the real cases; a general recurrence engine is a trap at this scale.

### 4.3 Altered: `attendance`

```sql
alter table attendance
  add column meeting_id uuid references meetings(id);   -- default NO ACTION
```

**Changed from the first draft, which used `ON DELETE CASCADE`.** Cascade would let
one mistaken delete silently erase a meeting's attendance. The FK now mirrors
`attendance.member_id` (NO ACTION): a meeting that has attendance **cannot be
deleted** until its rows are removed deliberately. The dashboard offers
`status = 'cancelled'` instead, and a "delete" of a meeting with scans must be an
explicit two-step (Phase 3).

NO ACTION rather than RESTRICT matters: NO ACTION is checked at the *end* of the
statement, so `DELETE FROM institutions` — which cascades to both `meetings` and
`attendance` — still succeeds. RESTRICT would fire mid-cascade and block it.

### 4.4 Altered: `institutions`

```sql
-- widen the type CHECK (the same move 20260620120000 made for 'shop')
check (type in ('school', 'office', 'shop', 'club'))

alter table institutions
  add column track_absences            boolean not null default true,
  add column meeting_preroll_minutes   integer not null default 30,
  add column meeting_postroll_minutes  integer not null default 30,
  add column meeting_autoclose_minutes integer not null default 240;
```

`track_absences` defaults `true`; `/onboarding` sets it `false` when creating a
`club`. As built it is **club-only**: the close sweep reads it, `mark-absent` does
not, so school / office / shop keep getting daily absences regardless. Extending it
to daily-mode tenants would be a separate, deliberate decision.

The minute columns carry sanity bounds: pre/post-roll `0–240`, auto-close `15–1440`.

Pre-roll and post-roll widen a scheduled meeting's acceptance window so early
arrivals and stragglers still count. Auto-close is the backstop for an ad-hoc
meeting nobody closed.

### 4.5 Watermark triggers

`meetings` must fire the existing `touch_institution_activity()` function
([20260628120200](backend/supabase/migrations/20260628120200_institution_activity_watermark.sql)),
or the dashboard's 12 s poll will not refresh when a meeting opens or closes:

```sql
create trigger trg_activity_meetings
after insert or update or delete on public.meetings
for each row execute function public.touch_institution_activity();
```

The function's deleted-institution guard
([20260904120000](backend/supabase/migrations/20260904120000_touch_institution_activity_skip_deleted_institution.sql))
already covers the `ON DELETE CASCADE` from institutions.

---

## 5. Meeting resolution — the core algorithm

For a scan from device `D` at instant `T` (parsed from the device timestamp by the
existing `parseInstant`, [log-attendance:17](backend/supabase/functions/log-attendance/index.ts:17)):

```
1. Candidate meetings := meetings where institution_id = D.institution_id
                           and (device_id = D.id or device_id is null)
                           and status in ('scheduled','open','closed')

2. Match the first whose window contains T:
     scheduled → starts_at - preroll  <=  T  <=  ends_at + postroll
     device    → opened_at            <=  T  <=  coalesce(closed_at, now())

3. No match → 200 with code "no_meeting_open" and no scan_type
   (NOT a 4xx — see "Response contract" in §7 Phase 2)

4. Insert attendance with meeting_id set, and date/time computed in the
   institution timezone exactly as today.
```

**This is the step that makes the offline queue correct.** Scans live in SPIFFS and
flush on reconnect — sometimes days later. Resolving against "whatever meeting is
open right now" would file a Saturday scan into Monday's meeting. Resolving by
timestamp containment files it correctly, and requires that **a scan be allowed to
land in an already-closed meeting**.

That in turn interacts with absences: if the close sweep already wrote an absent
placeholder, a late-arriving scan must overwrite it. The existing code already does
exactly this — the "overwrote absent placeholder" branch at
[log-attendance:293](backend/supabase/functions/log-attendance/index.ts:293) — so it is
a re-key from `date` to `meeting_id`, not new logic.

Overlapping meetings are prevented at write time: reject creating a meeting whose
window (including pre/post-roll) overlaps another for the same device. Simpler than
disambiguating at scan time.

---

## 6. How the device knows a meeting is open

The device renders scan verdicts **locally**, from the fid map — it does not wait for
a server response before showing a result, and it writes to SPIFFS before any network
attempt. So "reject with *No meeting open*" cannot be a server-side decision alone;
the device has to know.

Solution: extend the existing `get-enrollment-job` poll response with meeting state.
Bump `DEVICE_CONFIG_VERSION` from `1` to `2`
([get-enrollment-job:17](backend/supabase/functions/get-enrollment-job/index.ts:17)):

```jsonc
{
  "job": null,
  "device_config_ver": 2,
  "device_config_rev": 41,
  "device_config_meeting_open": true,
  "device_config_meeting_id": "…uuid…",
  "device_config_meeting_title": "Weekly Circle",  // truncated for the 128×64 OLED
  "device_config_meeting_ends_at": 1789234567      // epoch seconds, RTC-comparable
}
```

Worst-case latency between an organiser opening a meeting and the device accepting
scans is one poll interval — 10 s. Acceptable, but the OLED should show a
transitional state rather than a hard refusal during that window.

**Offline behaviour is the exception.** An offline device cannot know. It must accept
and queue the scan; the server resolves it by timestamp on flush, so scans for a
*scheduled* meeting land correctly and only genuinely orphaned scans are dropped.
This is deliberately inconsistent with the online path — see Open Decision A.

**As built (Phase 4)** the shape differs from the sketch above: the state rides in a
nested `meeting_state` object, so the flat `device_config_*` keys — and
`DEVICE_CONFIG_VERSION` — are unchanged and older firmware simply ignores it. The
device also does **not** refuse scans locally: online, the server's verdict
(`no_meeting_open`) comes back within the existing 4 s correlation window and is shown
as **NO MEETING**; offline, scans are saved (§8 A).

```jsonc
"meeting_state": {                 // clubs; other tenants get {"club": false}
  "club": true,
  "autoclose_min": 240,            // the idle rule the DEVICE applies (§8 B)
  "open_ref": "m66f7a3c1-3f2a",    // this device's ad-hoc meeting the server has open
  "open_opened_at": 1790550000,
  "live": {                        // resolve_meeting(now) for this device, or null
    "title": "Weekly Circle", "origin": "scheduled", "ref": null,
    "starts_at": 1790546400, "ends_at": 1790553600
  }
}
```

---

## 7. Phases

Each phase is independently reviewable. **Phase 3 is the value cut point:** a club
running scheduled meetings is fully functional with *no firmware change at all*. Only
impromptu meetings need Phase 4. Given devices are in the field and OTA is one-way,
this ordering is the point of the plan, not an accident of it.

### Phase 1 — Schema (invisible; zero behaviour change)

**Built, and applied to cloud** 2026-09-26 ~20:00 UTC via `apply_migration`, recorded
in the cloud history as `20260926200055`, `20260926200119`, `20260926200202`. Three
files in `backend/supabase/migrations/`, applied in order:

| File | Contents |
|---|---|
| `20260926120000_club_type_and_meeting_settings.sql` | Widen `institutions_type_check` to include `'club'`; add `track_absences`, `meeting_preroll_minutes`, `meeting_postroll_minutes`, `meeting_autoclose_minutes` |
| `20260926120100_meetings.sql` | `meetings` table + CHECKs + indexes, **and** its RLS policy, explicit grants, and watermark trigger |
| `20260926120200_attendance_meeting_id.sql` | `attendance.meeting_id` (NO ACTION FK); **adds** the two new unique keys; **keeps** the old one |

Deviations from the first draft of this plan, and why:

- **3 files, not 5.** RLS and the watermark trigger live in the same file as the
  table. This project auto-grants new tables to `anon` / `authenticated`, so applying
  the table without RLS — even briefly, between two files — would expose it through
  the Data API.
- **Explicit `GRANT`s to `service_role`.** Supabase stops auto-granting new public
  tables on 2026-10-30; applying after that without them would leave the edge
  functions with "permission denied for table meetings".
- **No constraint *swap* in Phase 1** — additive only (see §3). Nothing is dropped,
  so there is no window without dedup protection, and nothing to do `CONCURRENTLY`.
  (`CREATE INDEX CONCURRENTLY` also cannot run inside a transaction, which is how
  `apply_migration` and the SQL editor run a file.) Lock time is milliseconds at
  current volume (~1k attendance rows).

**Apply** each file as one unit, in order, via the SQL editor or `apply_migration`.

**Verify:**

```sql
-- old key kept, both new keys present (expect 3 rows)
select conname, pg_get_constraintdef(oid) from pg_constraint
 where conrelid = 'public.attendance'::regclass
   and conname in ('attendance_member_date_scan_type_unique',
                   'attendance_member_date_scan_type_meeting_key',
                   'attendance_meeting_member_scan_type_key');

-- every existing row is daily-mode (expect 0)
select count(*) from attendance where meeting_id is not null;

-- meetings is locked down (expect true / true)
select relrowsecurity from pg_class where oid = 'public.meetings'::regclass;
select has_table_privilege('service_role', 'public.meetings', 'insert');
```

**Tested** (2026-09-26) on PGlite — real Postgres (18.3) compiled to WASM — against
a replica of the live cloud schema generated from its catalog: exact columns,
defaults, constraints, indexes, trigger functions, and triggers for `institutions`,
`devices`, `members`, `periods`, `attendance`, `institution_activity`. Baseline data
was seeded on the *current* schema, then each file applied in its own transaction,
as in cloud. 43 checks, all passing, including: today's mark-absent statement still
dedups; the Phase 2 conflict target works both before and after the old key is
dropped; dropping the old key first reproduces `42P10`; the partial-index design
reproduces `42P10`; every meeting CHECK; meeting, device, and whole-institution
delete paths; the watermark trigger. A mutation run (CASCADE FK, plain UNIQUE
instead of `NULLS NOT DISTINCT`) fails 5 of the checks, so the suite does detect
regressions.

*Not* tested: a from-scratch `supabase db reset` of the full migration chain (local
Docker Desktop was crashing on start), and the PostgREST layer itself — the tests
issue the SQL PostgREST generates for `upsert(…, { onConflict, ignoreDuplicates })`,
not the HTTP call. Cloud runs Postgres 17; nothing used here differs between 17 and 18.

**Verified in cloud after apply:**
- All verify queries above pass: 3 keys, 0 rows with `meeting_id`, RLS on, grants in place.
- `EXPLAIN` (no `ANALYZE`, so nothing written) of mark-absent's exact statement
  resolves its conflict arbiter to `attendance_member_date_scan_type_unique`, so the
  nightly run is unaffected. The Phase 2 target
  `(member_id, date, scan_type, meeting_id)` already resolves to
  `attendance_member_date_scan_type_meeting_key`.
- Security advisors identical before and after. Performance advisors add only
  "unused index" notices for the three empty-table `meetings` indexes. There is no
  unindexed-FK notice for `attendance.meeting_id`: the club key covers it.
- `meetings` has no legacy `"service role full access"` policy, unlike older tables,
  and needs none: cloud `service_role` has `BYPASSRLS`.

### Phase 2 — Backend

**Built, tested, and deployed to cloud** (2026-09-26) — see the runbook below.
Purely server-side. Decisions taken at the start of Phase 2:

- **`toggle-meeting` and the poll's meeting fields moved to Phase 4.** Both exist
  only for firmware, and their contracts (device timestamps, replay idempotency,
  whether an offline device needs the upcoming schedule cached) are exactly what
  the offline master-press design decides (§8 B).
- **Meeting logic lives in Postgres**, not a new edge function: set-based,
  transactional, and testable against the replica. pg_cron calls the sweep
  directly — no pg_net hop, no cron secret.
- **Expected attendees** of a meeting are the members enrolled on its device
  (fingerprints live on the sensor — nobody else can physically scan in); for an
  unbound meeting, all active tracked members.
- **Club punctuality** is measured against the meeting's own `starts_at` /
  `ends_at` with the institution's grace minutes, at whole-minute granularity like
  the daily path. Ad-hoc meetings are never judged (no scheduled start).
- **Scheduled meetings never flip to `open`**: "live" means inside the window.
  Only device meetings use `open`.

| File | What it does |
|---|---|
| `20260926130000_meeting_functions.sql` | `resolve_meeting(institution, device, instant)` (§5 algorithm, overlap precedence: bound > unbound, core window > roll, latest start); `close_due_meetings(now)` sweep; device-delete guard trigger + `meetings.device_deleted_at` |
| `20260926130100_drop_old_attendance_dedup_key.sql` | Drops `attendance_member_date_scan_type_unique`. Guarded: refuses to run if the replacement key is missing |
| `20260926130200_close_meetings_cron.sql` | `cron.schedule('close-meetings', '*/15 * * * *', …)` |
| `20260926130300_close_due_meetings_whole_seconds.sql` | Replaces `close_due_meetings` with one change: absent rows' `time` truncated to whole seconds (found by the live test) |
| `functions/mark-absent/index.ts` | Skips `type = 'club'`; `onConflict: "member_id,date,scan_type,meeting_id"` with `meeting_id: null` explicit |
| `functions/log-attendance/club.ts` *(new)* | The whole club scan path. `index.ts` branches to it right after the timestamp conversion, before the weekday / holiday / period gates; the daily path is otherwise untouched |

**The sweep** (`close_due_meetings`): closes scheduled meetings once
`ends_at + post-roll` passes; closes ad-hoc meetings at the *earlier* of their idle
deadline (last scan + auto-close) and local midnight — `closed_at` is that moment,
not the sweep time, so offline scans taken before it still resolve in; then writes
absences for every closed, unprocessed meeting. It is the **only** writer of club
absences, so meetings closed by any path (sweep, dashboard, device) get them.
`absences_written_at` means "absence pass done" and is set even when nothing was
written, so turning `track_absences` on later never floods past meetings. Tenants
with a timezone Postgres doesn't recognise are skipped, not allowed to fail the run.

**The device-delete guard.** `meetings.device_id` is `SET NULL`, and NULL means
"unbound", which the resolver lets any device match. Unguarded, deleting a device
would turn every meeting it hosted — including historic ones — into a trap for
other devices' late-flushed scans. A deleted device can never authenticate again,
so the guard (a `BEFORE DELETE` trigger, because the `SET NULL` action runs before
any `AFTER` trigger could find the rows) stamps `device_deleted_at` on all its
meetings, which the resolver then never matches; cancels its future ones; closes
any under way; and marks their absence pass done unwritten (the same delete
SET-NULLs `members.device_id`, so who was expected is unknowable). It skips itself
mid-cascade from `DELETE FROM institutions`, like the watermark trigger does.

**Response contract with the device** (firmware ≥ 1.10.0, unchanged —
[firmware:653](firmware/ClassAttendance_Current_RTC/ClassAttendance_Current_RTC.ino:653),
[firmware:2108](firmware/ClassAttendance_Current_RTC/ClassAttendance_Current_RTC.ino:2108)):
`200` + `scan_type` → PRESENT / TIME IN / TIME OUT; `200` without `scan_type` →
NOT LOGGED; `4xx` → ERROR **and counted as lost data** in the OLED banner; `5xx` →
kept queued and retried. So "no meeting open" is `200` + `code: "no_meeting_open"`
(the first draft's 409 would have shown ERROR and inflated "N lost"), and a failed
meeting lookup is `500` so the scan is retried, not dropped. With today's firmware a
club therefore already gets a sensible device experience: scans inside a meeting
show PRESENT, scans outside show NOT LOGGED.

**Also fixed in passing:** `log-attendance`'s institution `select` was built by
string concatenation, which supabase-js types as `GenericStringError` — 16
pre-existing type errors. It is now one literal (identical at runtime), and all
three function files pass `deno check` with zero errors.

**Tested** (local — Docker Desktop is down, so PGlite + Deno):

- SQL on PGlite against the cloud replica, club tenant in Africa/Nairobi (UTC+3) to
  exercise real offset math: Phase 1 regression 43/43, Phase 2 69/69, twice. Covers
  window edges (pre/post-roll ±1 min), overlap precedence, early close, legacy
  no-device path, tenant isolation, every sweep branch (idle deadline, local
  midnight, absences on/off with no retro-flood, time_in_out, suspended tenant,
  invalid timezone), the device guard, and institution delete through the guard.
  A mutation run removing the resolver's deleted-device filter, the timezone guard,
  and the cascade guard fails 12 checks. The drop-key guard refuses to run without
  Phase 1 and leaves the old key intact.
- `club.ts`: 14 Deno unit tests with a recording fake client — every response the
  firmware can see, the legacy auth path, time-in/out sequencing per meeting,
  placeholder overwrite, duplicates, and error → 500.

**Deploy runbook — in this order; each step is safe on its own:**

| # | Step | Verify |
|---|---|---|
| 1 | Apply `20260926130000_meeting_functions.sql` | ✅ **done** 2026-09-26: grants, trigger, column in place; sweep on empty table returns zeros |
| 2 | Deploy `mark-absent` (`--no-verify-jwt`) | ✅ **v15.** Throwaway *daily* tenant tracking all 7 days; triggered via `pg_net` exactly as the cron does: `marked 1 absent`, no `insert error`; real tenants `day not tracked — skipped`; club test tenant skipped. Re-triggered: still one row (conflict path) |
| 3 | Apply `20260926130100_drop_old_attendance_dedup_key.sql` — **only after step 2** | ✅ Old key gone; re-triggered mark-absent: no error, still one row — daily dedup now rests on the `NULLS NOT DISTINCT` key alone |
| 4 | Apply `20260926130200_close_meetings_cron.sql` | ✅ `close-meetings` job active, runs as `postgres` |
| 5 | Deploy `log-attendance` (`--no-verify-jwt`; ships `index.ts` + `club.ts` + `deno.json`) | ✅ **v15.** Real HTTPS scans with a test device secret: daily scan overwrote its absent placeholder; duplicate and same-`scan_id` retry → `Duplicate scan ignored`; club scan inside a meeting → logged with `meeting_id`; between meetings → `no_meeting_open` (200); wrong secret → 401; unknown member → 404. The **first real cron run** (23:15 UTC) closed the past test meeting and wrote absences for both members; then a scan timestamped *inside* that closed meeting (a late offline flush) → `overwrote absent placeholder` in the right meeting |
| 5a | Apply `20260926130300_close_due_meetings_whole_seconds.sql` | ✅ Fix for a bug the live run exposed: sweep absences carried the meeting start's microseconds (`21:09:49.949243`) where every other row is `HH:MM:SS`. Now truncated; re-verified live (`23:16:48.148` start → `23:16:48`) and in PGlite (a check that fails without the fix) |
| 6 | Delete both test tenants | ✅ Cascaded cleanly through meetings, the device guard and the watermark trigger; nothing left; real data unchanged (3 tenants, 973 attendance rows) |
| 7 | Advisors before/after | ✅ Security lints identical to the pre-Phase-1 baseline; none mention the new functions |

Two gotchas for whoever deploys edge functions here:

- The Supabase MCP deploy tool **defaults to `verify_jwt: true`**. Devices send no
  JWT, so that default would lock every device out. Always pass `false` /
  `--no-verify-jwt`.
- Via the MCP deploy tool, `import_map_path` must be passed explicitly as
  `deno.json`; otherwise it reuses the previous version's absolute
  `file:///tmp/…` path and the deploy is rejected. The CLI reads it from
  `config.toml` and is unaffected.

### Phase 3 — Dashboard (the value cut point)

**Built and tested locally** (2026-09-27). **Migrations applied to cloud** 2026-09-27
~19:45 UTC via `apply_migration` (140000 then 140100). UI not yet deployed (Vercel prod
tracks `oled-integration`, not `club-mode`). Decisions at the
start of Phase 3: schedules are **end-and-recreate** (not editable), and the club
overview is **meeting-centred**.

**Database** — `20260926140000_meeting_schedules.sql` (+ `…140100` cron):

| Piece | What it does |
|---|---|
| `meeting_schedules` | Recurrence rule: weekly / every N weeks (1–12) / monthly Nth weekday (1st–4th, last); local start time + length; `starts_on` / optional `ends_on`; optional device. RLS, grants, watermark trigger in the same file |
| `meetings.schedule_id` | Which rule generated an occurrence; `UNIQUE (schedule_id, starts_at)` (one-offs unconstrained, NULLS DISTINCT) |
| `generate_scheduled_meetings(schedule?, now?, horizon=56)` | Materialises occurrences in the club's LOCAL time (`(day + time) AT TIME ZONE tz` — 10:00 stays 10:00 across DST). Never before today, never past `ends_on`, never an occurrence that has **already ended** (a schedule made at 09:00 for 08:00–09:00 today would otherwise be closed at once with everyone absent). `generated_through` means a deleted occurrence ("skip") is never re-created. Skips non-active tenants and unknown timezones |
| `end_meeting_schedule(schedule)` | Deactivates; deletes not-yet-started occurrences, cancels any that already hold a (pre-roll) scan; history untouched |
| `meeting_attendance_counts(institution, since)` | Present / absent per meeting, arrival rows only (time-in/out member counted once). Aggregated in Postgres because the Data API caps responses at 1000 rows — client-side counting would silently undercount |
| Device-delete guard (replaced) | Now also **deactivates** the device's schedules. `meeting_schedules.device_id` is SET NULL, not CASCADE: CASCADE was tried and failed in PGlite — the meetings.device_id SET NULL firing alongside it re-checks `schedule_id` against the just-deleted schedule |
| `generate-meetings` cron | Daily 00:10 UTC; the dashboard also generates a new schedule's first 8 weeks immediately |

**Dashboard:**

| Area | As built |
|---|---|
| `/meetings` *(new)* | Live-now cards (present / expected, Close now, Cancel, View scans), Upcoming (Edit, Cancel, Delete — "Skip" for a recurring occurrence), Recurring (End), Past 60 days (present / absent, status incl. "Closing…" while awaiting the sweep, Rename, Delete only if no attendance, link to its attendance). Refreshes every minute so meetings move section on their own |
| Meeting rules (server actions) | Can't create/move a meeting that has already ended; overlap check on core times per device (pre/post-roll overlaps are allowed — back-to-back meetings); only the title can change once a meeting has started; delete refused if attendance exists (offers Cancel); close only once started; close never writes absences (the sweep is the only writer). Device-pinned admins only see / act on their device's meetings. Local times ↔ UTC via `lib/zoned-time.ts`, which matches Postgres `AT TIME ZONE` exactly, DST gap and fold included |
| `/attendance` + CSV | Meeting filter + column for clubs; time-in/out pairing keyed by meeting (two meetings in one day no longer merge); Summary tab per meeting, with a rate only once the meeting's absence pass has run. Also fixed the file's 17 pre-existing rules-of-hooks errors (early return above the hooks) |
| Overview `/` | Clubs: Live now / Next meeting, Last meeting rate, pooled average over the last 10 rated meetings, active members, recent activity |
| `/settings` | Club type; Meetings section (record absences, early arrival, late check-in, auto-close — clamped to the DB bounds); weekday picker and fixed expected times hidden for clubs (lateness is measured from each meeting's own start / end) |
| `/onboarding` | Club / Society type; presets Member / Members / Group / Venue / Organiser(s); absences off by default |
| Nav, guards | Meetings for clubs (sidebar, mobile More sheet, header); Academic hidden and `/academic` redirects clubs to `/meetings`; `/promotion` refuses clubs |
| Devices | Delete confirmation says how many upcoming meetings will be cancelled and schedules stopped |

**Tested:** PGlite SQL — Phase 1 43/43, Phase 2 69/69 (before and after the Phase 3
schema), Phase 3 38/38 twice (weekly, fortnightly, first Monday, last Friday, New York
across the 1 Nov DST change, horizon rollover, skip-not-recreated, end schedule, counts,
device and institution delete). Deno unit tests for `zoned-time` + `meetings` 8/8
(incl. DST gap / fold matched against Postgres). `tsc` clean; `next build` passes (all
28 routes); ESLint 43 → 26 errors with nothing new. PostgREST query shapes validated
against the live API with the public key (and failing controls). *Not* tested: the
pages in a browser — they need a signed-in club account (see checklist, §11).

**Verified in cloud after apply:** RLS on with its one policy; all four functions
executable by `service_role` only (not `anon` / `authenticated`); device guard now
deactivates schedules; `generate-meetings` job active at `10 0 * * *` next to
`close-meetings` and `mark-absent-daily`. A smoke test in a rolled-back transaction
(throwaway New York club, 28 Oct): weekly Saturday 10:00 → 8 meetings, 31 Oct 14:00Z
then 7 Nov 15:00Z (DST change handled); last-Monday 19:00 → 1 inside the horizon
(30 Nov = 1 Dec 00:00Z); re-run created 0; a deleted occurrence was not re-created;
ending the weekly schedule removed 7; deleting the device cancelled the rest and
deactivated both schedules. Afterwards: no test rows, 3 tenants, 973 attendance rows
(unchanged); advisors unchanged.

### Phase 4 — Firmware and ad-hoc meetings

**Backend live** (2026-09-28, steps 1–2 of the deploy order below); firmware built,
not released. Decided at the start of Phase 4 (§8): **self-describing
events** for the offline press, **confirm-to-close** (open = one press; close = press,
then press again within 8 s), and offline scans with no known meeting are **saved**.

**How an ad-hoc meeting works.** The session-master press flips the device's own
state at once, online or offline, and names the meeting (`mtgRef`, e.g.
`m66f7a3c1-3f2a`: open epoch + random). The open event, the close event and *every
scan taken during the meeting* carry that ref and the open time through the ordinary
SPIFFS queue to `log-attendance`. Whichever reaches the server first creates the
meeting, so replay order, retries and lost replies can neither lose a meeting nor
create two, and the queue's re-append-at-the-end retry path needed no change. The
device applies the idle rule (last scan + `meeting_autoclose_minutes`) and the
local-midnight backstop itself, because only it sees scans still queued offline, and
reports the close stamped with the deadline. The server's sweep keeps only the
midnight backstop, for a device that died mid-meeting; a close only ever moves
`closed_at` earlier, so the device's later, truer close always wins.

**Database** — `20260928120000_device_meetings.sql`:

| Piece | What it does |
|---|---|
| `meetings.device_ref` | The device's id for the meeting; CHECK `^[A-Za-z0-9-]{4,64}$`; `UNIQUE (device_id, device_ref)` |
| `device_meeting_event(device, ref, opened_at, closed_at?)` | Create-if-missing, apply a close (`least()`), idempotent, advisory-locked per device. A new meeting closes an earlier still-open one at its open time; a late event for an earlier meeting is created closed at the later one's open time. `NULL` unless the device is in an **active club** |
| `resolve_device_scan(inst, device, at, ref, opened_at)` | Ensures the ref's meeting exists and files the scan there if its time is inside it (beating an overlapping scheduled meeting); otherwise `resolve_meeting` |
| `device_meeting_state(device, now?)` | The poll's `meeting_state` (§6) |
| `close_due_meetings` | Step (b) is now the **midnight backstop only** (idle rule moved to the device). Step (b) runs in a `MATERIALIZED` CTE: flattened into the UPDATE, the planner evaluated `AT TIME ZONE` before the timezone filter and one bad zone failed the whole sweep (caught by the Phase 2 regression suite) |
| `enrollment_jobs.command` | + `register-session-master`, `delete-session-master` |

**Edge functions:**

| Function | Change |
|---|---|
| `log-attendance` | `meeting_action: open\|close` events (need `device_id`, `meeting_ref`, `meeting_opened_at`, `timestamp` → 400 otherwise; 200 `not_club` / `meeting_ignored` when there's nothing to do; 500 on RPC error so the device retries). Scans may carry `meeting_ref` + `meeting_opened_at` → `resolve_device_scan` (a malformed ref is ignored, never loses the scan) |
| `get-enrollment-job` | `meeting_state` on every poll (one RPC for club devices; `{club:false}` for others, no query). `register-session-master` jobs carry their name like master jobs. Fixed a pre-existing `deno check` error (`job.member` cast) |

**Firmware 1.11.0:**

| Item | As built |
|---|---|
| `session_master` role | New `fidMapRole` value; enrolled by `register-session-master`, removed by `delete-session-master` |
| Press | First press: **OPENED** (or **END MTG?** if one is open → same finger within 8 s → **CLOSED · N present**; another finger cancels and is processed normally; timeout → **KEPT OPEN**). Refuses with **SCHEDULED · title · Until HH:MM** while a scheduled meeting is live (per a poll < 90 s old, or not yet past its end), **NO CLUB** for a non-club device, **NO CLOCK** on an RTC that was never set. The config master's double press → portal is untouched |
| Meeting state | `/meeting_state.json` (tmp + rename): open, ref, open time, last scan, fids seen, acked, club flag, auto-close minutes. Survives reboots; wiped on decommission |
| Reconcile with the poll | `open_ref` = our ref → acked; acked and then missing → closed/cancelled in the dashboard → **CLOSED · Closed in dashboard**, nothing queued. An open ref newer than anything we know (state lost) is adopted so the finger can close it |
| Auto-close | Earlier of (last scan or open) + auto-close minutes and local midnight, stamped with that deadline → **CLOSED · Meeting auto-closed** |
| Idle screen | Clubs get a meeting line: `Open 18:05 - 12 in` / `Till 20:00 Weekly Circle` / `No meeting` (under the offline banner when that shows) |
| Verdict | Server code `no_meeting_open` → **NO MEETING** (was NOT LOGGED) |
| Size | 1,261,112 bytes = 96% of the 1,310,720-byte app partition (+10.4 KB; ~49 KB left) |

**Dashboard:** `/enrollment` offers **Reg. / Del. session master** for club devices only
(per device, so a platform admin across tenants sees them where they apply; the
server action refuses them for non-clubs). Slot-occupancy checks cover session masters
too. Meetings opened at the device already appear on `/meetings` as "Ad-hoc meeting"
(Phase 3), with Close now / Cancel reaching the device within one poll.

**Tested:** PGlite — Phases 1–3 suites before the migration (43/69/38), Phase 2 again
after it with the idle-close expectations switched to the midnight backstop (70/70),
Phase 3 after it (38/38), Phase 4 72/72 twice (idempotent open, scan-before-open,
close-before-open, delayed events between meetings, `least()` closes, clamp, scheduled
overlap, dashboard close / cancel, non-club / suspended / unassigned devices, poll
state, midnight backstop with absences and a late device close, device delete,
grants). Deno: 24/24 (`club_test.ts`: + ref validation, `resolve_device_scan` routing,
event handling); `deno check` clean on both functions. Firmware compiles (arduino-cli,
ESP32 core 3.3.7, same FQBN as the IDE build) with no new warnings; the device-side
midnight arithmetic matched a reference on 56 cases across ±14 h zones. `tsc` clean;
ESLint unchanged (the enrollment folder's 4 errors are the pre-existing ones).
*Not* tested: anything on real hardware (§11).

**Deploy order** (each step safe on its own):

1. Apply `20260928120000_device_meetings.sql` — additive; the sweep change only
   affects device meetings, and none exist yet.
2. Deploy `log-attendance` and `get-enrollment-job` (`--no-verify-jwt`). Current
   firmware ignores `meeting_state` and never sends events or refs.
3. Release firmware: tag `firmware-v1.11.0`. OTA compares against the compiled-in
   version and only flashes a strictly newer one. A 1.10 device that receives a
   session-master job fails it as `unknown-cmd` — harmless.

**Deployed 2026-09-28 ~00:00 UTC:** step 1 via `apply_migration`; step 2 via
`supabase functions deploy … --no-verify-jwt --use-api` (uploads the exact repo files;
`log-attendance` v17 after a follow-up that makes the event reply name the meeting's
resulting state — a late replayed open of a closed meeting had answered "Meeting
opened"). Both `verify_jwt=false`. **Verified in cloud:**
- Database: column, key, widened CHECK, grants (service_role only), new sweep in
  place; a rolled-back smoke test (scan-before-open, idempotent open, poll state, close,
  later close ignored, school device → `{club:false}` and no meeting).
- Over HTTPS with throwaway "ZZ E2E" club + school tenants (deleted afterwards): poll
  before / while open / after close carried the right `meeting_state`; open event →
  replayed open → same meeting; scan with the ref → PRESENT in it; the same scan
  retried → duplicate; close event → closed at the device's time; a late replayed open
  left it closed; a scan with no meeting → `no_meeting_open`; bad ref and unknown
  action → 400; wrong secret → 401; school poll → `{"club": false}`, school event →
  `not_club`.
- Afterwards: 4 tenants, 973 attendance rows, 0 meetings (unchanged); security
  advisors unchanged. No real device polled in the preceding 24 h, so live-fleet
  traffic on the new versions is still to be observed.

---

## 8. Open decisions

**A — Online/offline inconsistency in scan refusal.**
Online, the device refuses a scan when no meeting is open. Offline, it accepts and
queues. This is the least-lossy option and preserves the durability-first design, but
it means the same action gives two different results depending on WiFi. The
alternative — refuse when offline too — loses every scan of a meeting held during an
outage. *Recommendation:* accept the inconsistency, and make the OLED say
"Queued — offline" so it is visible rather than silent.
*Decided at Phase 4 start: save it* (the existing **SAVED · Offline** card). Online,
the refusal is the server's verdict (**NO MEETING**), not a local check.

**B — How the ad-hoc master press works offline.** *Decided: it must work offline.*
*Mechanism decided at Phase 4 start: self-describing events* — the device names the
meeting and every open / close / scan message carries the name and open time, so any
of them can create it (§7 Phase 4). How it answers each point below: events go through
the scan queue with RTC timestamps; `UNIQUE (device_id, device_ref)` + create-if-
missing is the idempotency; ordering stops mattering because a scan can create its
own meeting; the device tracks "open" itself; the device owns the idle / midnight
close and the server keeps only a midnight backstop, with closes merged by `least()`;
a scan's own meeting beats an overlapping scheduled one, and the session master won't
open over a scheduled meeting it knows is live. The original questions:

- **Queueing.** Open/close presses become durable SPIFFS events, like scans, and are
  replayed on reconnect with their RTC timestamps — so `toggle-meeting` must accept
  a device timestamp, not stamp `now()`.
- **Idempotency.** A replayed press whose ack was lost must not open a second
  meeting. Likely a device-generated event id (as `scan_id` does for scans), stored
  on `meetings`.
- **Ordering.** Scans taken during an offline meeting are queued *after* its open
  event and must land inside it. Either replay controls before scans, or rely on
  timestamp resolution (§5) and allow a scan to arrive before its meeting exists
  (a short server-side retry, or leave it queued on the device until the meeting
  exists).
- **Local state.** Offline, the device must track "meeting open" itself so it
  accepts scans, which also resolves most of Open Decision A.
- **Reconciliation.** The server may auto-close or end-of-day-close a meeting that
  the device, offline, still thinks is open; or a scheduled meeting may overlap an
  offline ad-hoc one.

Phase 1 was built to leave all of this open: it adds no "one open meeting per
device" constraint and no idempotency column. Both are additive when this is
decided.

---

## 9. Risks and gotchas

- **The old-key drop (Phase 2 step 2)** is the step that can break production:
  applied before mark-absent is redeployed, every tenant's nightly absence run fails
  with `42P10`, reported only inside a `200` response. Follow the Phase 2 order.
- **Deleting a meeting with attendance is refused by the database** (NO ACTION FK).
  Intended — the UI must offer Cancel rather than surface a raw FK error.
- **A deleted host device would turn its meetings into unbound ones** — *resolved in
  Phase 2* by the device-delete guard and `meetings.device_deleted_at` (§7 Phase 2).
  The residual cost: a device deleted mid-meeting leaves that meeting without
  absences.
- **Offline ad-hoc meetings vs the server's auto-close.** The sweep closes an ad-hoc
  meeting at its idle deadline using only the scans the *server* has seen. If a
  device opens a meeting online and then loses WiFi for longer than
  `meeting_autoclose_minutes`, scans it keeps taking offline land after the
  meeting's `closed_at` and are rejected when they flush. *Resolved in Phase 4:* the
  device applies the idle rule itself; the server keeps only the midnight backstop.
  Residual: a device offline *across* local midnight still has its meeting cut at
  midnight — by both sides, consistently.
- **DST and timezone edits.** Meeting windows are `timestamptz`; a tenant changing
  `institutions.timezone` shifts the local rendering of already-scheduled meetings.
  Decide whether existing rows re-anchor or hold their instant — probably hold, and
  warn in `/settings`.
- **Meetings with `device_id IS NULL`** (institution-wide) match any device in the
  tenant. Fine for single-device clubs; revisit if a club ever runs two devices at one
  meeting.
- **10 s poll latency** means an organiser who opens a meeting in the dashboard and
  immediately scans may be refused once. Show a transitional OLED state.
- **`DEVICE_CONFIG_VERSION` 1 → 2**: old firmware must tolerate unknown fields, and new
  firmware must tolerate a `ver: 1` server during a partial rollout. Check the existing
  parse path before assuming it degrades gracefully. *Avoided in Phase 4:* the version
  is unchanged; meeting state is a separate nested `meeting_state` key that 1.10
  ignores, and 1.11 keeps its last view when a server doesn't send it.
- **Flash headroom.** 1.11.0 is 96% of the 1.25 MB OTA app partition (~49 KB left).
  The next big firmware feature may need a partition-scheme change, which cannot be
  done over OTA.

---

## 10. Explicitly out of scope

- Manual / phone check-in with no device.
- Clubs nested inside a school tenant (a school wanting a club needs a second tenant).
- Seasons or periods for clubs.
- Full RRULE recurrence.
- Any change to school / office / shop behaviour.

---

## 11. Per-phase test checklist

**Phase 1** — after applying to cloud: run the §7 Phase 1 verify queries; the next
nightly `mark-absent` run returns `marked N absent` / `all tracked members present`
for every tenant, with no `insert error`; a school scan still logs, and a duplicate
scan is still rejected.

**Phase 2** — scan inside a scheduled window lands with `meeting_id`; scan outside
returns `no_meeting_open`; **a scan whose timestamp is 3 days old lands in the correct
closed meeting, not the current one**; a late scan overwrites its absent placeholder;
two meetings on one day both accept the same member; `mark-absent` skips club tenants.

**Phase 3** — automated checks are in §7 Phase 3. Browser click-test, as a platform
admin and then as the new club's super admin (needs the Phase 3 migrations applied, and
a dashboard pointed at cloud — local `.env.local` targets a local Supabase stack):

1. Onboarding: create a Club / Society — labels come out Member / Group / Venue /
   Organiser; Settings shows the Meetings section, no weekday picker, absences off.
2. Nav: Meetings present; Academic absent; `/academic` redirects to `/meetings`;
   `/promotion` → unauthorized.
3. Create a one-off meeting starting in ~5 minutes → it appears under Upcoming, then
   (within a minute of its pre-roll opening) under Live now.
4. Try to create one that overlaps it on the same device → "Overlaps …" error; one
   that already ended → refused.
5. Create a weekly recurring meeting → "N meetings scheduled"; they list under
   Upcoming with the recurring icon; Skip one; End the schedule → future ones gone.
6. Scan in on a real device during the live meeting → present count rises (≤ 12 s);
   Close now → "Closing…" in Past, then Closed with absences within 15 min (if on).
7. Attendance page: Meeting filter narrows to that meeting; Meeting column shows its
   name; Summary shows one row per meeting; CSV has a Meeting column.
8. Overview: Live now / Next meeting / Last meeting / Average cards.
9. Devices: the delete dialog for the club's device mentions the upcoming meetings.
10. A school tenant: nothing changed — no Meetings, Academic present, attendance and
    overview exactly as before.

`check-rbac.mjs` still exits 1 on `app/(dashboard)/page.tsx` — pre-existing (the
overview deliberately uses `verifySession()` so every role can see it); `/meetings`
passes.

**Phase 4** — on a real device running 1.11.0, in a club tenant, after the migration
and both edge functions are live:

1. Enrollment → **Reg. session master** is offered for the club's device only; enrol
   a finger → the job completes.
2. Session master once → **OPENED**; within ~12 s `/meetings` shows a live "Ad-hoc
   meeting"; the idle line reads `Open HH:MM - 0 in`.
3. Member scans → **PRESENT**, the live count rises, the idle line counts them.
4. Session master → **END MTG?**; wait 8 s → **KEPT OPEN**. Again, then again within
   8 s → **CLOSED · N present**; `/meetings` shows it closed.
5. With no meeting open, a member scan → **NO MEETING** (not NOT LOGGED).
6. The *config* master: double press still opens the captive portal.
7. **Offline:** disconnect WiFi (or the router's uplink). Open with the session master,
   scan 2 members (**SAVED · Offline**), close it. Reconnect → the queue drains and
   the meeting appears with its offline open/close times and both members present.
8. **Offline longer than auto-close** (the old §9 failure): set auto-close to 15 min,
   open online, go offline, scan a member every ~10 min for 30 min, reconnect → one
   meeting, still open, every scan inside it (the old server rule would have closed
   it 15 min after the last scan it had seen).
9. Power-cycle mid-meeting → still open after boot (idle line), and closes normally.
10. Close from the dashboard (**Close now**) while it's open → the device shows
    **CLOSED · Closed in dashboard** within ~10 s.
11. Set Settings → auto-close to 15 min, open, scan once, wait 16 min → the device
    shows **Meeting auto-closed**; `/meetings` shows it ended 15 min after the scan.
12. During a scheduled meeting's window, session master → **SCHEDULED · title · Until
    HH:MM**, nothing opened.
13. A school device on 1.11.0: scanning, the idle screen and the portal are unchanged
    (no meeting line).

Add the passing cases to [docs/for-operators/e2e-testing-checklist.md](docs/for-operators/e2e-testing-checklist.md)
as each phase lands.

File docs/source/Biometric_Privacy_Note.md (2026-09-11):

# Biometric Privacy Note
:kicker: Policy note
:subtitle: How fingerprints are captured, stored, and protected -- and how to have them removed
:audience: Institution administrators, data-protection officers, and anyone asked to enrol
:version: Version 2.0 | September 2026
:accent: #0f766e
:series: privacy
:output: clients

<<<TOC>>>

## 1. In short

>> The system identifies people by fingerprint without ever keeping a picture of one, and without putting fingerprint data in the cloud.

::: can What the system keeps
- A mathematical template of the finger, inside the scanner's sensor chip
- A slot number (1--127) in the cloud, saying which sensor slot belongs to which person
- Attendance records: who scanned, where, and when
:::
::: cannot What it never keeps
- A fingerprint image -- anywhere, at any time
- Any fingerprint data in the cloud database
- A way to read a template back out of the sensor
:::

You can decline to enrol, and you can ask for your fingerprint to be deleted at any time (section 5).

## 2. What happens when you enrol

1. An administrator starts an enrollment for you on the dashboard. It's sent to the scanner for your class, team, or department.
2. You place the same finger on the sensor twice. Two captures make the template reliable.
3. The sensor's own chip turns the image into a template -- a compact numeric description of the ridge pattern -- and discards the image at once. The image is never stored, sent, or logged.
4. The template is saved in the sensor's memory under a slot number.
5. The scanner tells the dashboard whether it worked. That report contains no fingerprint data.

When you scan later, the sensor compares your finger with the templates it holds and answers with a slot number. Only that number travels further.

## 3. What is stored, and where

<!-- cols: 26 40 34 -->
| Where | What is stored | What is not |
| --- | --- | --- |
| The scanner's sensor chip | Fingerprint templates, in the sensor's own internal format | Images |
| The scanner's memory | A list linking each slot number to a person: their ID, role, and name | Templates or images |
| The cloud database -- people | Two slot numbers per person, e.g. *3* and *7* | Templates, images, or anything derived from them |
| The cloud database -- attendance | Who, when, which scanner, and the scan's reference | Any biometric data |

**The cloud holds only small whole numbers that point to sensor slots.** Even someone with full access to the database could not rebuild a fingerprint from them.

## 4. How it is protected

- **Templates can't be exported.** The sensor stores them in a proprietary format, and the scanner's software can only enrol, search, and delete -- never read a template out.
- **Each scanner has its own secret key.** The server accepts records only from scanners that present it, so one compromised scanner exposes nothing about the others.
- **Lost or stolen scanners can be blocked** by the platform operator instantly, and told to wipe themselves the next time they connect.
- **All traffic is encrypted.** Scanners check the server's identity before sending anything.
- **Each institution's data is kept apart.** Staff of one institution can't see another's people or records, and a scan can only ever be matched within its own institution.
- **Names on screen are adjustable.** Your institution can show a full name, a first name, initials, an ID, or nothing on the scanner's screen after a scan -- useful where a queue can read it.

## 5. Your choices and rights

<!-- cols: 22 78 -->
| Right | How it works |
| --- | --- |
| **Be informed** | You should be told, before enrolling, what this note describes: the template stays on the sensor, and only a slot number goes to the cloud. |
| **Access** | An administrator can show you which slot numbers are linked to you. There is no fingerprint data to show beyond that. |
| **Deletion** | An administrator opens your record and presses **Delete** beside each fingerprint. The scanner erases that template from the sensor and the slot number is removed from the database. |
| **Objection** | You may decline to enrol. The system has no check-in without a fingerprint, so your institution will record your attendance another way -- a paper register, for example. |

> [!NOTE] Being marked **Inactive** -- as leavers are -- stops your attendance being recorded but does not erase your fingerprints. Ask for deletion as well if you want them removed.

## 6. How long things are kept

<!-- cols: 30 70 -->
| Data | Kept until |
| --- | --- |
| **Fingerprint templates** | Deleted as above, overwritten by a new enrollment in the same slot, or erased when an administrator runs **Clear all** on that scanner. |
| **Attendance records** | Your institution decides. The platform doesn't delete them automatically. |
| **Scans waiting to upload** | Normally minutes. A scanner that stays offline keeps them for up to 7 days (or 1,000 scans), then drops the oldest. |
| **The scanner's local log** | Rotated automatically once it reaches its size limit. |

> [!WARNING] When a school promotes its students, their links to last year's scanners are cleared, but the templates themselves stay on those scanners until the slots are reused. Institutions should run **Clear all** on each scanner after promotion, and before any scanner is retired, moved, or passed to another organisation.

## 7. Questions and requests

For questions, or to ask for your fingerprint to be deleted, speak to your institution's administrator first. You can also contact the platform operator at sgariba21@gmail.com.

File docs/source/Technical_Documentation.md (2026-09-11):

# Technical Documentation
:kicker: Technical reference
:subtitle: Multi-tenant biometric attendance and retail platform -- firmware, backend, and dashboard
:audience: Developers and the platform operator
:version: Version 3.1 | September 2026 | Firmware 1.10.0
:accent: #334155
:series: technical
:output: operators
:toc_depth: 2

<<<TOC>>>

<<<PAGEBREAK>>>

## 1. Project overview

>> The ESP32 Fingerprint Attendance System is a multi-tenant biometric attendance and retail platform. ESP32 scanners with an R503 capacitive fingerprint sensor record attendance at the unit level -- a classroom, an office section, a shop counter. A Next.js dashboard backed by one cloud Supabase project provides reporting, device provisioning, remote enrollment, institution configuration, and -- for shop tenants -- a point-of-sale and loyalty module.

The system replaces paper roll-calls with a tamper-resistant fingerprint scan. Records are timestamped in the institution's own timezone; absences are filled in automatically each evening by a scheduled job. Scanners keep working through WiFi outages by queueing scans to on-board flash.

### 1.1 Key capabilities

- **Biometric identification** -- R503 capacitive sensor, up to 127 fingerprint slots per scanner, on-sensor matching in about 0.3 s.
- **Multi-tenant** -- one deployment serves any number of school, office, and shop institutions with strict per-tenant isolation.
- **Per-member-type scan modes** -- present / absent (one scan marks the day) or time in / time out (paired scans), set separately for students and staff.
- **Punctuality** -- optional late-arrival and early-departure thresholds stamp each scan `on_time`, `late`, or `early_leave`.
- **Tracked weekdays** -- an explicit Monday-to-Sunday set; scans on untracked days are ignored and generate no absences.
- **Offline resilience** -- every scan is written to SPIFFS before any network attempt; a rotate-then-process queue survives reboots and power loss.
- **Automatic absence marking** -- pg_cron invokes `mark-absent` daily; it respects holidays, tracked weekdays, and periods.
- **On-device OLED** -- an optional SSD1306 128 x 64 screen shows a live status card; the firmware runs headless without it.
- **Remote enrollment** -- jobs queued on the dashboard are collected, executed, and reported by the scanner; stuck jobs are re-delivered and self-heal.
- **OTA updates** -- scanners check GitHub Releases at boot (after a random delay) and install a strictly newer build.
- **Academic calendar** -- terms or periods, plus recurring and one-off holidays.
- **Retail and loyalty** (shops) -- clients, a products-and-services catalog, point of sale, and a punch-card loyalty module with redemption at the till.
- **Role-based access** -- six roles with institution- and device-scoped visibility.
- **Installable PWA** -- the dashboard installs to a home screen or desktop.

## 2. System architecture

Three tiers: the ESP32 firmware, the Supabase backend (PostgreSQL, Edge Functions, pg_cron), and the Next.js dashboard on Vercel. Scanners talk only to the edge functions, over HTTPS. The dashboard talks only to PostgreSQL, server-side, through the service role.

### 2.1 Components

<!-- cols: 22 30 48 -->
| Tier | Technology | Role |
| --- | --- | --- |
| ESP32 firmware | Arduino / FreeRTOS, one sketch | Scan, queue to flash, drive the OLED, provision, and self-update over HTTPS |
| R503 sensor | UART, capacitive | Capture, template storage, and matching -- entirely on the sensor |
| DS3231 RTC | I2C | Wall-clock time across reboots and outages; re-synced from NTP on boot and reconnect |
| SSD1306 OLED | I2C, optional | Status display; shares the I2C bus with the RTC |
| Supabase Edge Functions | Deno / TypeScript | HTTPS API for provisioning, attendance, enrollment, and the daily absence job |
| Supabase PostgreSQL | PostgreSQL 17, pg_cron, pg_net | Multi-tenant store; schedules and drives absence marking |
| Next.js dashboard | App Router, shadcn/ui, Tailwind CSS | The admin interface; all Supabase access server-side |
| Vercel | Hosting | Dashboard deployment |

### 2.2 Data flow for one scan

1. A finger is scanned. The R503 matches it to a stored template and returns a slot number (FID) and a confidence score.
2. The firmware resolves the FID to a member through `fid_map.csv`, appends the scan to `/queue.txt` in SPIFFS, and signals the network task.
3. The network task renames `/queue.txt` to `/queue_inflight.txt` and POSTs each record to `/log-attendance` with the scanner's `x-device-secret` header.
4. `/log-attendance` authenticates the scanner, resolves the member within its institution, applies tracked-weekday, scan-mode, and punctuality rules, deduplicates, and inserts an `attendance` row.
5. A trigger bumps `institution_activity.last_change_at`. The dashboard polls `/api/changes` every 12 s and refreshes only when that watermark advances.
6. Each evening pg_cron calls `mark-absent` through `net.http_post()`, which inserts absences for every active member with no present scan that day, per institution and timezone.

## 3. Hardware

A scanner is built from off-the-shelf modules on a custom passive carrier PCB, in a 3D-printed enclosure. Unit cost is roughly GHS 1,000.

### 3.1 Bill of materials

<!-- cols: 20 45 35 -->
| Item | Part / spec | Notes |
| --- | --- | --- |
| Microcontroller | ESP32 dev module -- dual-core Xtensa LX6, 240 MHz, 4 MB flash, WiFi | Seats in two 15-pin headers on the carrier |
| Fingerprint sensor | R503 capacitive -- UART, 127 slots, ~0.3 s match, ring LED | 6-pin JST-SH 1.0 mm cable |
| RTC module | DS3231 -- I2C, TCXO, battery-backed, +/-2 ppm | 6-pin 2.54 mm header; shares I2C with the OLED |
| Display (optional) | SSD1306 0.96" 128 x 64 OLED, I2C address 0x3C | Firmware runs headless if absent |
| Carrier PCB | Custom 2-layer interconnect board (KiCad) | No active parts |
| Enclosure | 3D-printed base and lid, plus an OLED bezel variant | FDM, PLA or PETG |
| Power | 5 V USB supply into the carrier's JST-GH 1.25 mm input | 3V3 comes from the ESP32 module's regulator |

### 3.2 Carrier PCB

A 2-layer KiCad design in `hardware/PCBs/Attendance System_v1/`, with an earlier revision in `_v0`. It has no active silicon and no regulator of its own: it seats the ESP32 module and provides keyed, polarised connectors so the sensor, RTC, OLED, and power can't be mis-plugged. It distributes 5 V, 3V3, and GND and routes the UART to the R503 and the shared I2C bus.

<!-- cols: 14 38 48 -->
| Ref | Connector | Purpose |
| --- | --- | --- |
| J1 / J2 | 2 x 1x15, 2.54 mm pin socket | ESP32 dev-module headers |
| J3 | 1x6, JST-SH 1.0 mm vertical | R503 sensor -- VCC, TX, RX, GND, touch |
| J4 | 1x6, 2.54 mm pin socket | DS3231 + SSD1306 -- shared SDA/SCL, 3V3, GND; DS3231 32K and SQW broken out |
| J5 | 1x2, JST-GH 1.25 mm vertical | 5 V power input |

The DS3231's 32K and SQW outputs are broken out but unused by the firmware.

### 3.3 Enclosure

Designed in FreeCAD (`hardware/CAD files/Fingerprint Device Enclosure.FCStd`), exported to 3MF, and sliced in Bambu Studio:

- **Base** -- holds the carrier PCB and ESP32; the front face carries the R503 aperture and the power-cable entry.
- **Lid** -- closes over the base; the overall envelope is about 80 x 74 x 50 mm.
- **OLED outer shell** -- a framed window, about 36 x 35 x 7 mm, for the display on OLED builds.

Print in PLA or PETG. The sensor sits flush behind the front aperture and the lid clips on.

### 3.4 Wiring

<!-- cols: 50 50 -->
| Signal | ESP32 pin |
| --- | --- |
| R503 TX -> ESP32 RX | GPIO 16 |
| R503 RX -> ESP32 TX | GPIO 17 |
| DS3231 and OLED SDA | GPIO 21 (shared I2C bus) |
| DS3231 and OLED SCL | GPIO 22 (shared I2C bus) |

The R503 runs on hardware UART `Serial2` at 8N1. The DS3231 (0x68) and SSD1306 (0x3C) share one bus brought up with `Wire.begin(21, 22)`.

## 4. Firmware

One Arduino sketch: `firmware/ClassAttendance_Current_RTC/ClassAttendance_Current_RTC.ino`, `FIRMWARE_VERSION` 1.10.0. Three FreeRTOS tasks are pinned across the two cores.

### 4.1 Task model

<!-- cols: 20 8 72 -->
| Task | Core | Responsibility |
| --- | --- | --- |
| FingerprintTask | 1 | Scan loop, FID resolution, LED feedback, enrollment execution, and launching the captive portal on a confirmed master-finger scan. Writes each scan to SPIFFS, then signals NetworkTask. |
| NetworkTask | 0 | Provisioning, the queue flush to `/log-attendance`, NTP-to-RTC sync, WiFi reconnect, and the reachability watchdog (4.4). |
| EnrollmentTask | 0 | Polls `/get-enrollment-job` every 10 s, hands jobs to FingerprintTask, reports results until acknowledged, and acts on the decommission signal. |

`memQueueSem`, a binary semaphore, signals "a scan was persisted"; there is no in-RAM scan queue. Enrollment jobs pass through `currentEnrollJob` under `enrollMutex`, and `spiffsMutex` serialises every SPIFFS access. Display state crosses cores through a mailbox -- tasks never touch the display object directly.

### 4.2 Offline queue

- Each scan is written to `/queue.txt` synchronously, inside FingerprintTask, before any network attempt.
- On flush, NetworkTask atomically renames `/queue.txt` to `/queue_inflight.txt` under the lock and releases it, so new scans append to a fresh file while the send runs.
- If power fails mid-flush, `recoverInflightQueue()` merges the orphaned in-flight file back into `/queue.txt` on the next boot, before tasks start.
- A 2xx drops the record. 5xx, 429, and network errors keep it for retry. Any other 4xx -- the server answered and rejected the payload -- drops it and doesn't count against reachability.
- Caps: 1,000 entries, 256 KB, and 7 days; the oldest records go first, in a sweep every 5 minutes.

Each scan carries a `scan_id` of the form `scan-YYYYMMDDhhmmss-<member-sid>`, timestamped from the DS3231. It is unique per institution and also deduplicated on member, date, and scan type.

### 4.3 OLED display

If `display.begin()` succeeds, the render path draws a size-2 headline on row 0 and size-1 lines on rows 24, 36, and 48 of the 128 x 64 panel:

- **Idle** -- the clock, the device's display name, and its link state: `Online`, `Offline`, or `No server` (WiFi associated but HTTPS failing). A degraded banner on row 48 shows the queue depth and any dropped records.
- **Scan verdicts** -- `SCANNED` while awaiting the server, then `PRESENT`, `TIME IN`, `TIME OUT`, or `NOT LOGGED` (accepted but not counted); `SAVED` / Offline when queued; `COOLDOWN`, `NO MATCH`, `NOT MAPPED`, `SCAN ERROR`.
- **Enrollment** -- `PRESS 1/2`, `REMOVE`, `PRESS 2/2`, `ENROLLED`, and the failures `MISMATCH`, `TIMED OUT`, `BAD SCAN`, `OCCUPIED`, `STORE FAIL`.
- **Master finger** -- `CONFIRM?`, `CONFIRMED`, `CANCELLED`.
- **Lifecycle** -- `PENDING` with the MAC, `REJECTED`, `REVOKED`, `RESET`, `SETUP`, and `OTA UPDATE`.

The name on a scan card follows the institution's `member_name_display` setting. The panel sleeps after 120 s idle and wakes on the next event. If it is missing or fails to initialise, every draw is a no-op.

### 4.4 Server-reachability watchdog

On a live WiFi link, `postJSON*()` feeds a health counter. After 5 consecutive failed POSTs the scanner is "server unreachable": it forces a WiFi re-association every 60 s, and after 5 minutes unreachable it calls `ESP.restart()` to clear a wedged network stack. A 4xx counts as reachable. An unrecoverable TLS-arena or low-heap condition also triggers a reboot.

### 4.5 SPIFFS layout

<!-- cols: 36 64 -->
| File | Contents |
| --- | --- |
| `/device_identity.json` | `device_id`, `institution_id`, the per-device `device_secret`, and `display_name`, written after assignment |
| `/provisioning.json` | `device_id` and `provisioning_token` during the pending window; deleted once assigned |
| `/fid_map.csv` | `fid,uniqueId,role,name` -- the slot-to-member map used to resolve a scan |
| `/queue.txt`, `/queue_inflight.txt` | The durable attendance queue and its in-flight rotation |
| `/scan_log.txt` | A rolling, size-capped local scan log |
| Device config cache | Per-institution device settings such as `member_name_display`, with their `config_rev` |
| WiFi credentials | The SSID and password captured by the captive portal |

## 5. Network and security

### 5.1 TLS certificate validation

Every HTTPS connection uses `WiFiClientSecure` with `setCACert(ROOT_CA_BUNDLE)`. The bundle in `certs.h` must contain each host's full chain -- root **and** intermediates -- because mbedTLS on the ESP32 can't fetch missing intermediates (no AIA).

<!-- cols: 34 66 -->
| Host | Chain in the bundle |
| --- | --- |
| Supabase (`*.supabase.co`) | leaf -> WE1 (Google Trust Services) -> GlobalSign ECC Root CA R4 |
| GitHub API (`api.github.com`) | leaf -> Sectigo Public Server Auth CA DV E36 -> Sectigo Root E46 |
| GitHub release CDN | leaf -> R12 (Let's Encrypt) -> ISRG Root X1 (the root alone suffices) |

### 5.2 Authentication secrets

<!-- cols: 30 31 39 -->
| Secret | Stored | Used for |
| --- | --- | --- |
| `BOOTSTRAP_SECRET` | `secrets.h` (gitignored, compiled in); edge-function secret | `x-bootstrap-secret` on `/register` and `/assignment-poll` -- before assignment only |
| `device_secret` | SPIFFS `/device_identity.json`; `devices.device_secret` | `x-device-secret` on every operational call. A transitional path still accepts the legacy shared `institutions.device_secret`. |
| `provisioning_token` | SPIFFS `/provisioning.json`; `devices.provisioning_token` | Binds `/assignment-poll` to the scanner that registered, preventing secret harvesting |
| `CRON_SECRET` | Supabase Vault (`cron_secret`) and the edge-function secret | `x-cron-secret` on `/mark-absent`. Kong strips the Authorization header, so a Bearer token can't be used. |
| `SUPABASE_SERVICE_ROLE_KEY` | Vercel environment | The dashboard's server-side admin client |

### 5.3 Tenant isolation

The dashboard uses the service role, so RLS is bypassed and isolation is enforced in application code. `resolveInstitutionScope()` locks every non-platform role to its own `institution_id` and ignores query parameters; every mutating server action calls `ownsRecord(table, id, session)` before touching a row. `platform_admin` is cross-tenant by design. RLS policies exist as dormant defence in depth. On the device side, `/log-attendance` resolves the member only within the authenticated scanner's institution, so a scan can't cross tenants.

## 6. Database schema

All tables are in `public`. `institution_id` is the tenant key on every scoped table, with `ON DELETE CASCADE`. Migrations live in `backend/supabase/migrations/` and are applied to cloud by hand after review.

### 6.1 Core tables

<!-- cols: 24 40 36 -->
| Table | Key columns | Notes |
| --- | --- | --- |
| `institutions` | id, name, type, timezone, `label_*`, student and staff scan modes, `tracked_weekdays`, `time_format`, lateness and early-leave settings, `member_name_display`, currency, `sell_products`, `sell_services`, `loyalty_enabled`, status, `device_secret`, `config_rev`, theme | One row per tenant; type is school, office, or shop. `config_rev` is bumped by a trigger on any change, and scanners poll it to refresh cached config. |
| `members` | id, sid, fullname, group_name, unit_name, fin1, fin2, status, member_type, device_id, institution_id | member_type is student or staff; sid is unique per institution; device_id is `ON DELETE SET NULL`. |
| `devices` | id, group_name, unit_name, display_name, mac, provisioning_token, device_secret, revoked, institution_id | One scanner per institution, group, and unit. `display_name` is generated from group and unit. `revoked = true` gives an instant 401. |
| `periods` | id, term, year, status, start_date, end_date, institution_id | Academic or reporting periods. |
| `attendance` | id, member_id, period_id, device_id, date, time, status, scan_type, punctuality, scan_id, institution_id | status is present or absent; scan_type is present, time_in, or time_out; punctuality is on_time, late, early_leave, or null. Date and time are in the institution's timezone. |
| `enrollment_jobs` | id, device_id, member_id, finger_slot, command, status, fid, note, allow_overwrite, dispatched_at, attempts, last_error, institution_id, created_at | command is register, delete, clearall, register-master, or delete-master. A status guard makes completed and failed terminal. |
| `holidays` | id, label, start_date, end_date, recurring, institution_id | Recurring holidays match by month and day every year, including ranges that wrap the year end. |
| `profiles` | id (-> auth.users), role, assigned_unit, assigned_device_id, institution_id, member_id | Dashboard roles. `assigned_device_id` is required for teacher and staff and optional for admin. |
| `device_resets` | device_id, created_at | Deferred-wipe queue. No foreign key, so it survives device deletion; not consumed on read. |
| `institution_activity` | institution_id, last_change_at | Polling watermark maintained by triggers; backs `/api/changes`. |

### 6.2 Retail and loyalty tables (shops)

<!-- cols: 30 70 -->
| Table | Purpose |
| --- | --- |
| `clients` | Customers: name and phone, the phone unique per tenant. Separate from members; no fingerprint. |
| `products`, `services` | Sellable catalog items, soft-deleted through `active`; products also carry stock. |
| `client_attendance` | One visit row per client per day. |
| `transactions`, `transaction_items` | A sale and its lines. Lines snapshot the item name and unit price. Written atomically by the create-sale function, with discount and reward linkage. |
| `rewards` | Loyalty rules: reward kind and payload, condition type, threshold, window, repeatable. |
| `rewards_log` | Issuance and redemption records. `transaction_id` links a redeemed reward to its sale; a guard prevents double redemption. |

## 7. Provisioning and operation

### 7.1 First boot of a new scanner

1. It boots with no `/device_identity.json`. On the very first boot it also clears SPIFFS and restarts.
2. It connects to saved WiFi, or opens the captive portal `Attendance-Setup` at 192.168.4.1.
3. It syncs time over NTP into the DS3231.
4. It POSTs its MAC to `/register` with `x-bootstrap-secret`. The function creates an unassigned `devices` row and returns `device_id`, a `provisioning_token`, and `pending`. The scanner saves both and breathes yellow.
5. It polls `/assignment-poll` every 5 s with its id and token.
6. The platform admin assigns it to an institution on the Devices page.
7. `/assignment-poll` returns `assigned`, the `institution_id`, the per-device `device_secret`, and the display name -- only if the token matches.
8. The scanner writes `/device_identity.json`, deletes `/provisioning.json`, and enters normal operation. The super admin then gives it a group and unit.

### 7.2 Normal operation

- **Every scan:** queued to SPIFFS, then POSTed to `/log-attendance` with `x-device-secret`.
- **Enrollment:** `/get-enrollment-job` every 10 s; results POSTed to `/update-enrollment-job` and retried until acknowledged.
- **Configuration:** `/get-enrollment-job` also returns `member_name_display`, the display name, and `config_rev`; the scanner refreshes its cache when `config_rev` advances.
- **OTA:** checked at boot after a 0--120 s random delay (section 10).
- **Master finger:** one scan shows `CONFIRM?`; a second scan of the same finger within 8 s reopens the captive portal.

### 7.3 Enrollment job lifecycle

A job is created `pending`. `/get-enrollment-job` hands it to the scanner and moves it to `in_progress`, stamping `dispatched_at` and incrementing `attempts`. The scanner enrols the finger and POSTs the result; `/update-enrollment-job` moves it to `completed` with the FID, or `failed` with `last_error`. If the result is lost -- flaky TLS, or a reboot between `storeModel()` and the POST -- the job is re-delivered on a later poll, and auto-failed after a capped number of attempts. The `enrollment_jobs_status_guard` trigger stops a late or raced write from pulling a terminal job back to `in_progress`. The dashboard offers Retry and Cancel for stuck jobs, and Re-queue (optionally with overwrite) for failed ones.

### 7.4 Revocation and decommissioning

Set `devices.revoked = true` for an instant lockout: the scanner's next `/log-attendance` call gets a 401. For a permanent wipe, insert a `device_resets` row -- deleting a device on the dashboard does this. `/get-enrollment-job` then returns `decommissioned: true` on every poll (the row isn't consumed, so it survives races), and the scanner wipes its identity and reboots into provisioning.

## 8. Edge functions

Six Deno functions under `backend/supabase/functions/`. All are configured `verify_jwt = false` and do their own authentication.

<!-- cols: 21 19 22 38 -->
| Function | Caller | Auth | Purpose |
| --- | --- | --- | --- |
| `/register` | Scanner, first boot | `x-bootstrap-secret` | Create an unassigned device row and issue a provisioning token |
| `/assignment-poll` | Scanner, while pending | `x-bootstrap-secret` + token | Once assigned, return the device secret, institution, and display name |
| `/log-attendance` | Scanner, every scan | `x-device-secret` | Authenticate, resolve the member in-tenant, apply the rules, dedupe, insert |
| `/get-enrollment-job` | Scanner, every 10 s | `x-device-secret` | Return the next job and device config; re-deliver stuck jobs; signal decommission |
| `/update-enrollment-job` | Scanner, after enrolling | `x-device-secret` | Record completed or failed, and the FID; institution derived from the device row |
| `/mark-absent` | pg_cron, 21:00 UTC daily | `x-cron-secret` | Insert absences per institution and timezone; batches of 8 institutions; needs pg_net |

The cron job reads the project URL and cron secret from Vault (`supabase_project_url`, `cron_secret`) each time it fires, so no credential appears in migration history.

## 9. Dashboard

Next.js App Router, on a version with breaking changes from stock Next.js: middleware lives in `frontend/proxy.ts`, not `middleware.ts`. Every Supabase call is server-side through the service role.

### 9.1 Roles and scope

<!-- cols: 17 27 56 -->
| Role | Scope | Access |
| --- | --- | --- |
| `platform_admin` | Every institution | All pages; creates institutions and their first super admin. |
| `super_admin` | One institution | Every page, including devices, enrollment, settings, and accounts. |
| `admin` | One institution, or one device | People, periods, promotion, attendance, the shop module; views accounts and changes only their own password. Device-bound admins are scoped to that device and may register or delete fingerprints on it. |
| `teacher` / `staff` | One device | Read-only attendance and roster for that device. An unresolved assignment shows an empty state, never everything. |
| `cashier` | One shop | Clients, sales, and the catalog (view only). |

`dal.ts` exports `verifySession()`, `requireRole(...)`, `getInstitution()`, `resolveInstitutionScope()`, and `resolveDeviceScope()`. `verifySession()` is `cache()`-wrapped and sends suspended or deactivated tenants to `/suspended`. `node scripts/check-rbac.mjs` fails CI if any dashboard page lacks a `requireRole(` call.

### 9.2 Pages

<!-- cols: 30 70 -->
| Route | Description |
| --- | --- |
| `/` | Overview -- today's present and absent counts, rate, and recent scans; takings and stock for shops; a cross-tenant summary for platform admins. |
| `/attendance` | Records, Summary, and By-member tabs; date, period, type, status, member, and unit filters; Late / Early badges; CSV export. |
| `/members`, `/staff` | Rosters with add, CSV import, edit, fingerprints, and activate / deactivate. |
| `/devices` | Pending assignment (platform), pending setup, configure, rename, delete. |
| `/academic` | Periods and holidays -- "Academic", "Periods & Holidays", or "Closed Days" by type. |
| `/enrollment` | Job queue: register, delete, clear all, register and delete master; Retry, Cancel, Re-queue, overwrite. |
| `/promotion` | Year-end bulk promotion; schools only. |
| `/settings` | Identity, branding, labels, scan modes, tracked weekdays, punctuality, timezone, time format, name on device, and shop modules. |
| `/sales`, `/clients`, `/catalog`, `/rewards`, `/reports` | The retail and loyalty module; shops only. |
| `/institutions`, `/onboarding` | Tenant management; platform admins only. |
| `/users` | Accounts: email search and role filter. |
| `/unauthorized`, `/suspended` | Role-denied and tenant-suspended screens. |

### 9.3 Installable PWA

A web manifest (`app/manifest.ts`, served as `/manifest.webmanifest`) and a minimal service worker (`public/sw.js`) make the dashboard installable. The worker only passes requests through -- it never caches, so the authenticated dashboard can't serve stale data -- and is itself served no-cache. `proxy.ts` excludes `/api` and the PWA assets so a signed-out browser can still read them. The in-app install prompt lives in `components/pwa/`.

## 10. OTA firmware updates

At boot, with WiFi up and no assignment pending, the scanner waits a random 0--120 s (from hardware entropy) so a fleet-wide power cut doesn't hit GitHub's unauthenticated rate limit at once. It then fetches `releases/latest` from `api.github.com/repos/sgariba21-beep/esp32-attendance-device`.

Tags must be `firmware-v<major>.<minor>.<patch>` (`OTA_TAG_PREFIX`). Only a version strictly newer than the compiled `FIRMWARE_VERSION` installs. The release's first `.bin` asset is streamed through the ESP32 `Update` library while the sensor light breathes red, and the scanner reboots into the new image. The API and CDN hosts must be in the TLS bundle (section 5.1).

## 11. Key file locations

<!-- cols: 50 50 -->
| Path | Purpose |
| --- | --- |
| `firmware/ClassAttendance_Current_RTC/ClassAttendance_Current_RTC.ino` | The firmware sketch |
| `firmware/ClassAttendance_Current_RTC/certs.h` | TLS root and intermediate bundle |
| `firmware/ClassAttendance_Current_RTC/secrets.h` | `BOOTSTRAP_SECRET` -- gitignored; copy from `secrets.example.h` |
| `hardware/PCBs/Attendance System_v1/` | Carrier PCB (KiCad); `_v0` is the earlier revision |
| `hardware/CAD files/` | Enclosure source (FreeCAD) and print-ready 3MF parts |
| `backend/supabase/functions/` | The six edge functions |
| `backend/supabase/migrations/` | Schema migrations -- applied to cloud by hand |
| `backend/supabase/config.toml` | Edge-function config (`verify_jwt = false` for all) |
| `frontend/proxy.ts` | Next.js middleware (not `middleware.ts`) |
| `frontend/lib/supabase/dal.ts` | Session, role, and scope helpers |
| `frontend/lib/supabase/ownership.ts` | `ownsRecord()` -- the per-tenant ownership check |
| `frontend/app/manifest.ts`, `frontend/public/sw.js` | PWA manifest and service worker |
| `docs/source/` | Sources for this document and every manual, plus the build script |
| `docs/for-clients/`, `docs/for-operators/` | The built PDFs, and the operator runbooks |

> [!NOTE] This document is built from `docs/source/Technical_Documentation.md`. Update it whenever firmware contracts, the schema, or the edge-function API change, then rebuild with `python build.py`.

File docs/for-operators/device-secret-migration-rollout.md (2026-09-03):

# Device-Secret Migration Rollout Guide (T20m)

<!-- Do NOT auto-apply to cloud; run after review. -->

This guide covers the safe sequence for migrating from the shared `institutions.device_secret`
to per-device secrets (`devices.device_secret`). Follow these steps in order; out-of-order
deployment will cause devices to fail log-attendance until they complete re-provisioning.

---

## Background

**Before this migration:** every device in an institution shared the same secret stored in
`institutions.device_secret`. A compromised device exposed the secret for all devices in
that institution.

**After this migration:** each device has a unique `devices.device_secret` issued at
provisioning time (during `/assignment-poll`). The shared secret is kept as a fallback during
the transition period and removed once all devices are re-provisioned.

---

## Step 1 — Apply backend migrations (schema)

Apply the migration files in timestamp order. **Do not apply to cloud automatically.**

```
20260628120000_per_device_secret.sql          -- adds devices.device_secret, devices.revoked
20260628120100_profiles_assigned_device_fk.sql -- adds profiles.assigned_device_id + backfill
20260628120200_institution_activity_watermark.sql -- polling watermark triggers
20260628120300_realtime_cleanup.sql           -- remove REPLICA IDENTITY FULL from unused tables
```

Review each file header, then apply via the Supabase SQL editor or `supabase db push` in a
maintenance window.

**Verify:**
```sql
-- Each should return the new column
select id, device_secret, revoked from devices limit 5;
select id, assigned_device_id from profiles limit 5;
select * from institution_activity;
```

---

## Step 2 — Deploy updated edge functions

Deploy all six edge functions in one shot (they are backwards-compatible with both old
firmware and new firmware during the transition):

```
assignment-poll      -- issues per-device secret on first assignment
log-attendance       -- dual-path: device_id header path + legacy institution secret path
get-enrollment-job   -- authenticates via devices.device_secret
update-enrollment-job -- authenticates via devices.device_secret + derives institution from device
mark-absent          -- batched (BATCH_SIZE=8), no auth change
register             -- MAC-based device registration, x-bootstrap-secret (unchanged, redeploy for parity)
```

The `log-attendance` function supports **both** auth paths simultaneously during the rollout:
- New firmware: sends `device_id` in body + `x-device-secret: <per-device-secret>` header
- Old firmware: sends `institution_id` in body + `x-device-secret: <shared-secret>` header

Do not remove the legacy path until all devices are re-provisioned.

---

## Step 3 — OTA firmware update

Tag a new firmware release on GitHub Releases with the `firmware-v<major>.<minor>.<patch>`
prefix (matches `OTA_TAG_PREFIX` in the sketch) and attach the new binary.
Devices will check for updates on the next boot (after a randomised 0–120 s jitter).

New firmware changes relevant to this migration:
- `queueAndSignal()` replaces `sendOrQueuePayload()` — SPIFFS-only queue, no memory queue
- Attendance payload now includes `device_id`
- `reportEnrollUpdate` payload now includes `device_id`
- `pollAssignment()` stores the per-device secret it receives from `/assignment-poll`

Monitor serial logs for `"Assigned! institution_id="` to confirm devices received their
per-device secrets. Devices that are already assigned will **not** automatically get a
per-device secret via OTA alone — they need re-provisioning (Step 4).

---

## Step 4 — Re-provision each device (delete + re-add in dashboard)

For each device that is already assigned (i.e., `devices.device_secret IS NULL`):

1. In the dashboard, go to **Devices** → select the device → **Delete**.
   - This triggers the decommission flow: the device wipes its identity on next
     `get-enrollment-job` poll and reboots into provisioning mode.
2. Power-cycle the device if it doesn't self-reboot within ~2 minutes.
3. The device will call `/register` (new MAC-based registration) and wait for assignment.
4. In the dashboard, **Add device** with the same display name / group / unit, then assign it.
5. On next `/assignment-poll`, the device receives its unique `devices.device_secret` and
   stores it in SPIFFS. `log-attendance` will now use the per-device path.

**Batch re-provisioning:** process one institution at a time. Devices continue scanning with
the legacy path while awaiting re-provisioning.

---

## Step 5 — Remove the transitional (legacy) path

Once `devices.device_secret IS NULL` returns zero rows for all institutions:

```sql
select count(*) from devices where device_secret is null and revoked = false;
-- Must return 0 before proceeding
```

Then remove the legacy fallback in `log-attendance/index.ts` (the `TRANSITION` block) and
redeploy the function. At this point, any old-firmware device will start getting 401s —
ensure all devices have received the OTA before removing the transition path.

---

## Rollback

- If edge function deploy causes issues: re-deploy the previous function versions from git.
- If a device gets stuck in provisioning loop: check `devices` table for duplicate MACs;
  delete the orphaned row and let the device re-register.
- Schema migrations cannot be automatically rolled back — keep the `devices.device_secret`
  column even if reverting edge functions (it is nullable and harmless if unused).

---

## Revoking a compromised device

```sql
-- Immediately blocks the device from logging attendance
update devices set revoked = true where id = '<device-uuid>';
```

The device will receive a 401 on its next scan. To permanently decommission, also insert
into `device_resets` (the get-enrollment-job path returns `decommissioned: true` persistently
once a row exists there).

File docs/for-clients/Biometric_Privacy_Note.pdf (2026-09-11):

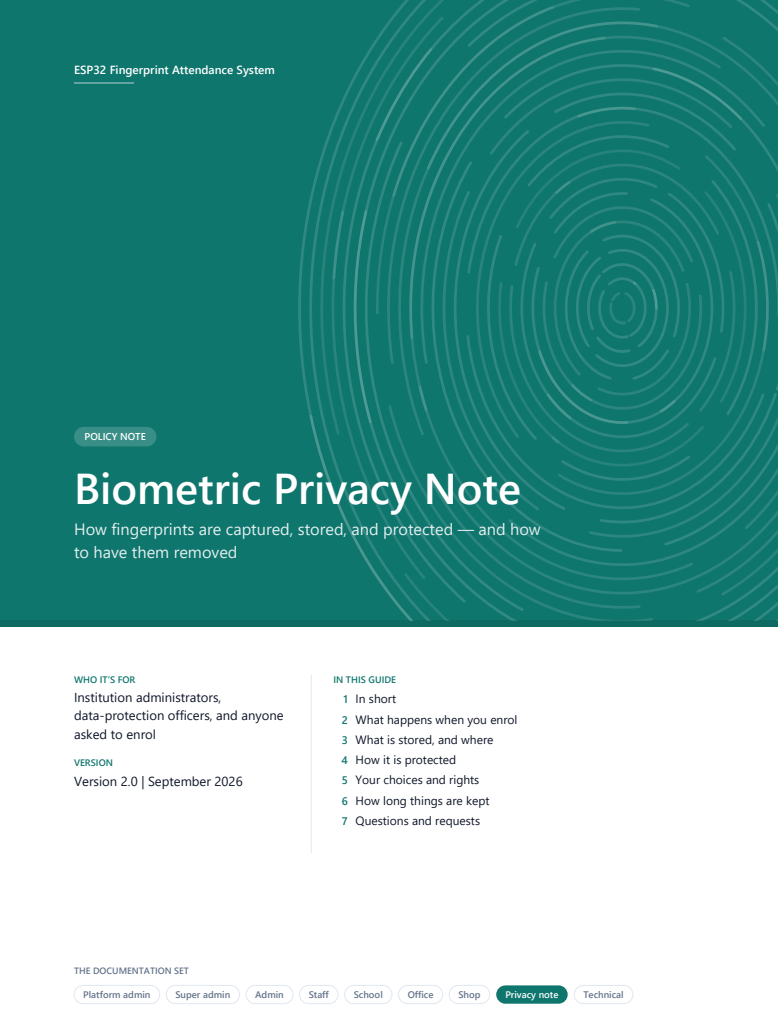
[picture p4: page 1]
VERSION Version 2.0 | September 2026; Platform admin; Super admin; Admin; Staff; School; Office; Shop; Privacy note; Technical

ESP32 Fingerprint Attendance System

POLICY NOTE
Biometric Privacy Note

How fingerprints are captured, stored, and protected — and how
to have them removed

WHO IT’S FOR
Institution administrators,
data-protection officers, and anyone
asked to enrol

IN THIS GUIDE
1 In short
2 What happens when you enrol
3 What is stored, and where
4 How it is protected
5 Your choices and rights
6 How long things are kept
7 Questions and requests

THE DOCUMENTATION SET

## Contents

## 1 In short

The system identifies people by fingerprint without ever keeping a picture of one, and without putting fingerprint data in the cloud.

What the system keeps

A mathematical template of the finger, inside the scanner's sensor chip

A slot number (1–127) in the cloud, saying which sensor slot belongs to which person

Attendance records: who scanned, where, and when

What it never keeps

A fingerprint image — anywhere, at any time

Any fingerprint data in the cloud database

A way to read a template back out of the sensor

You can decline to enrol, and you can ask for your fingerprint to be deleted at any time (section 5).

## 2 What happens when you enrol

1 An administrator starts an enrollment for you on the dashboard. It's sent to the scanner for your class, team, or department.

2 You place the same finger on the sensor twice. Two captures make the template reliable.

3 The sensor's own chip turns the image into a template — a compact numeric description of the ridge pattern — and discards the image at once. The image is never stored, sent, or logged.

4 The template is saved in the sensor's memory under a slot number.

5 The scanner tells the dashboard whether it worked. That report contains no fingerprint data.

When you scan later, the sensor compares your finger with the templates it holds and answers with a slot number. Only that number travels further.

Biometric Privacy Note

ESP32 Fingerprint Attendance System | Page 1 of 3

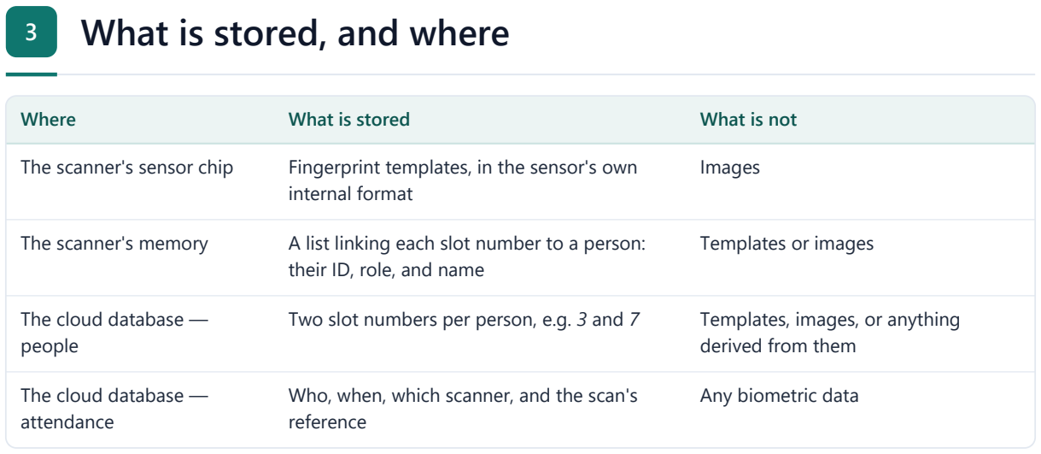
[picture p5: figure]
3 What is stored, and where; Where; What is stored; What is not; internal format; Images; their ID, role, and name; Templates or images; The cloud database — people; derived from them; The cloud database — attendance; reference; Any biometric data

The scanner's sensor chip | Fingerprint templates, in the sensor's own
The scanner's memory | A list linking each slot number to a person:
Two slot numbers per person, e.g. 3 and 7 | Templates, images, or anything

Who, when, which scanner, and the scan's

The cloud holds only small whole numbers that point to sensor slots. Even someone with full access to the database could not rebuild a fingerprint from them.
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

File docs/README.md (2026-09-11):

# Documentation

Everything written about the system, sorted by who reads it. The PDFs are
generated -- to change one, edit its source in [`source/`](source/) and rebuild.

```
docs/
├── for-clients/     hand these to institutions
├── for-operators/   for whoever runs the platform
└── source/          Markdown sources + the build script
```
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

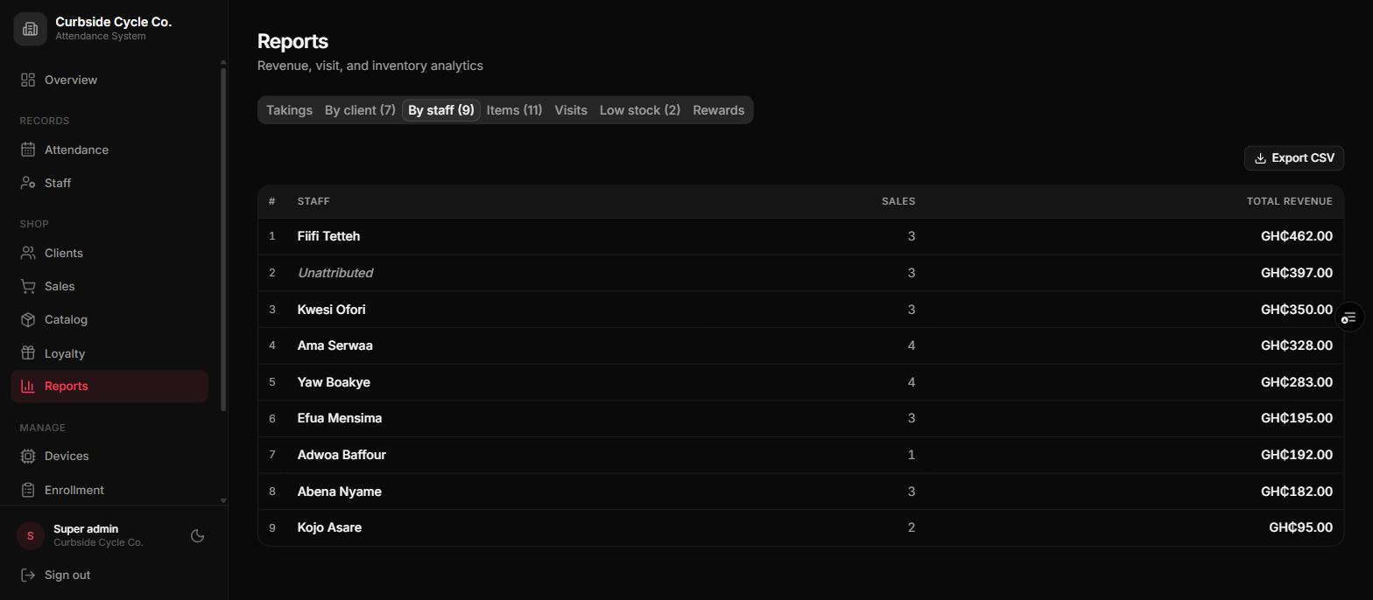
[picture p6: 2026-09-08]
images/shop--11-reports-by-staff.jpg

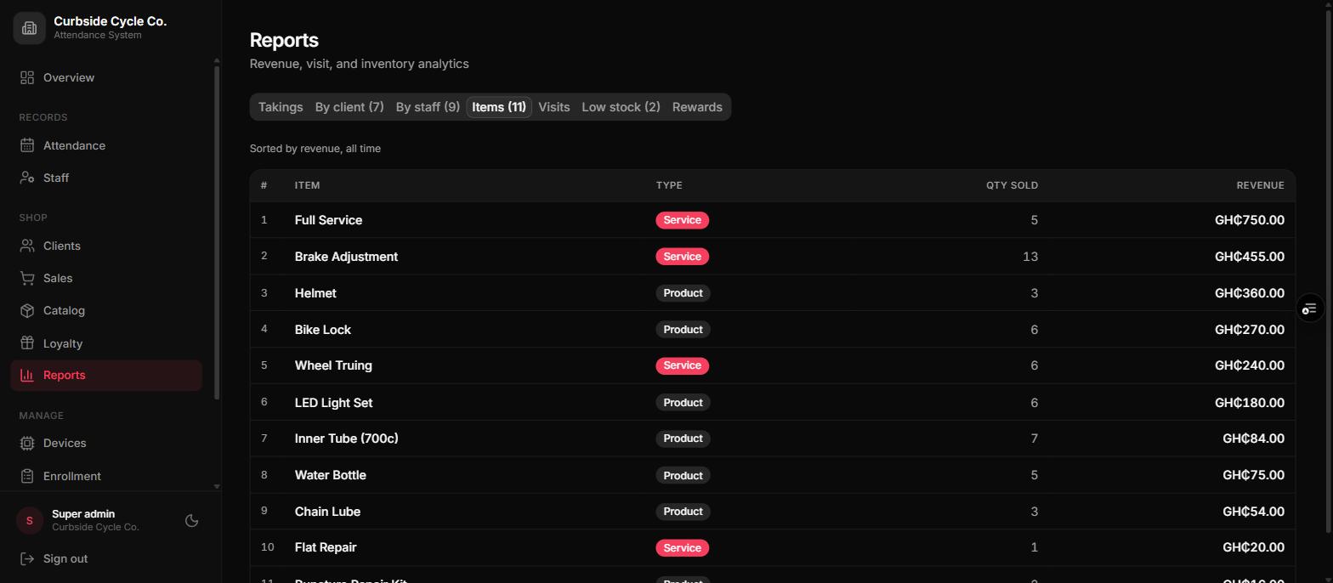
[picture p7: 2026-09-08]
images/shop--12-reports-items.jpg

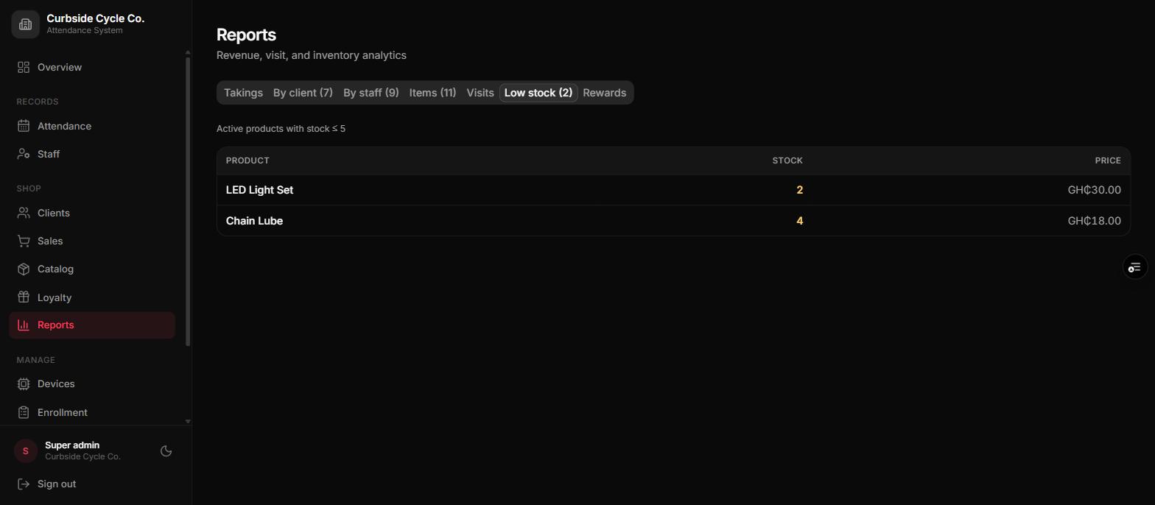
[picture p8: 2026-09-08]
images/shop--13-reports-low-stock.jpg

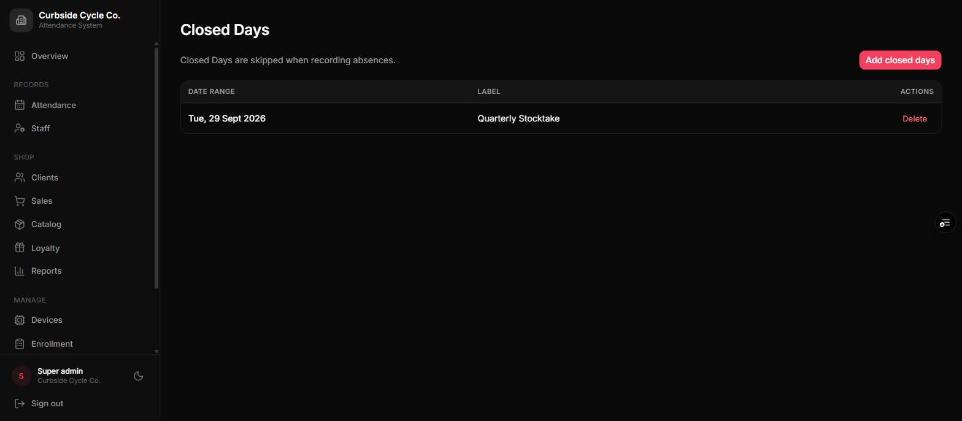
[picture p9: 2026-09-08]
images/shop--16-closed-days.jpg

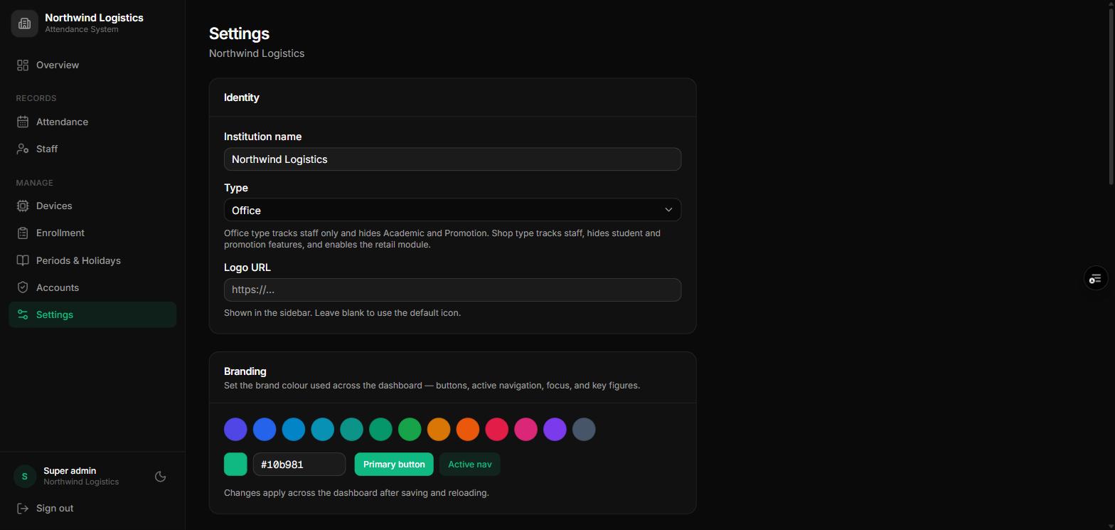
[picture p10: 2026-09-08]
images/office--09-settings.jpg

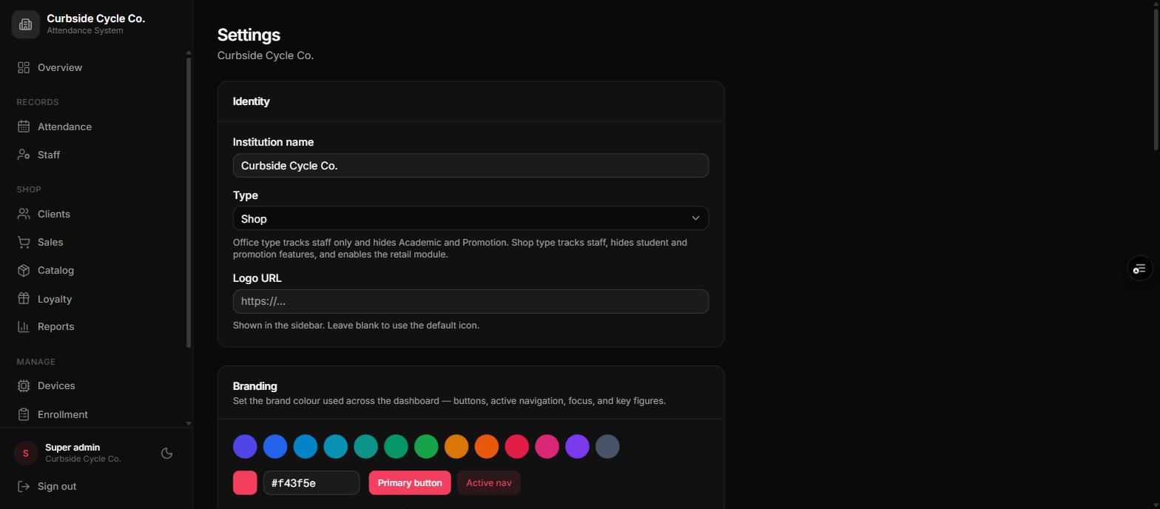
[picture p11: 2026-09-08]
images/shop--18-settings.jpg

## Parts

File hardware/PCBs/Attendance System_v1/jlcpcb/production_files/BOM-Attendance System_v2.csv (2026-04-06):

Comment | Designator | Footprint | LCSC | Quantity
Conn_01x06_Socket | J3 | JST_SH_BM06B-SRSS-TB_1x06-1MP_P1.00mm_Vertical |  | 1
Conn_01x15_Socket | J2 | PinSocket_1x15_P2.54mm_Vertical |  | 1
Conn_01x15_Socket | J1 | PinSocket_1x15_P2.54mm_Vertical |  | 1
Conn_01x02_Socket | J5 | JST_GH_BM02B-GHS-TBT_1x02-1MP_P1.25mm_Vertical |  | 1
Conn_01x06_Socket | J4 | PinSocket_1x06_P2.54mm_Vertical |  | 1

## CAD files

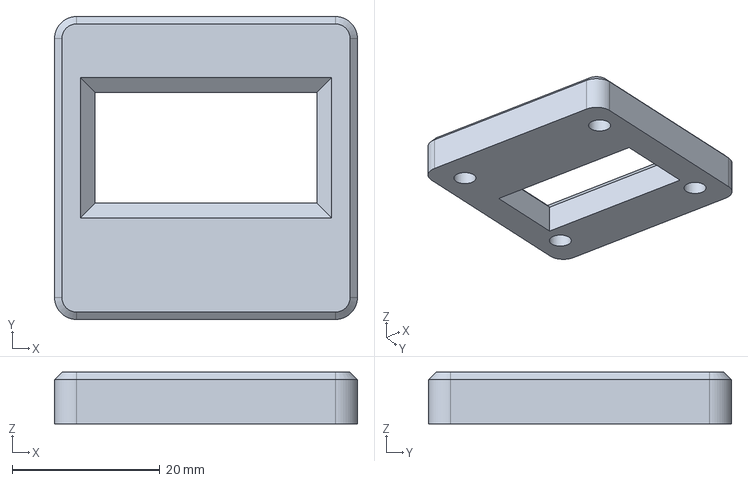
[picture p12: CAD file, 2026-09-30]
hardware/CAD files/Fingerprint Device Enclosure.FCStd
41.0 x 41.0 x 7.00 mm

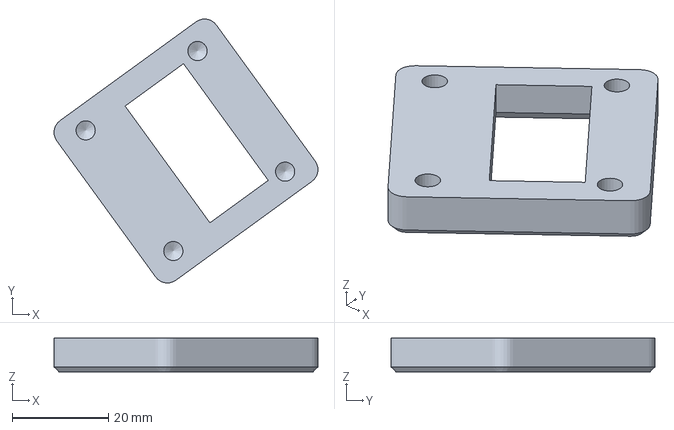
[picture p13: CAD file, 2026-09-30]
hardware/CAD files/Fingerprint Device Enclosure-OLED_Outer_Shell.3mf
54.9 x 54.9 x 7.00 mm

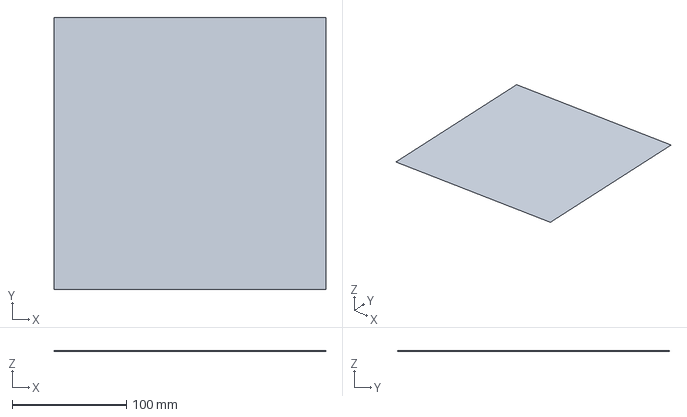
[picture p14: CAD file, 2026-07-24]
hardware/CAD files/Fingerprint Device Enclosure-Base.3mf
237.8 x 237.8 x 0.2 mm

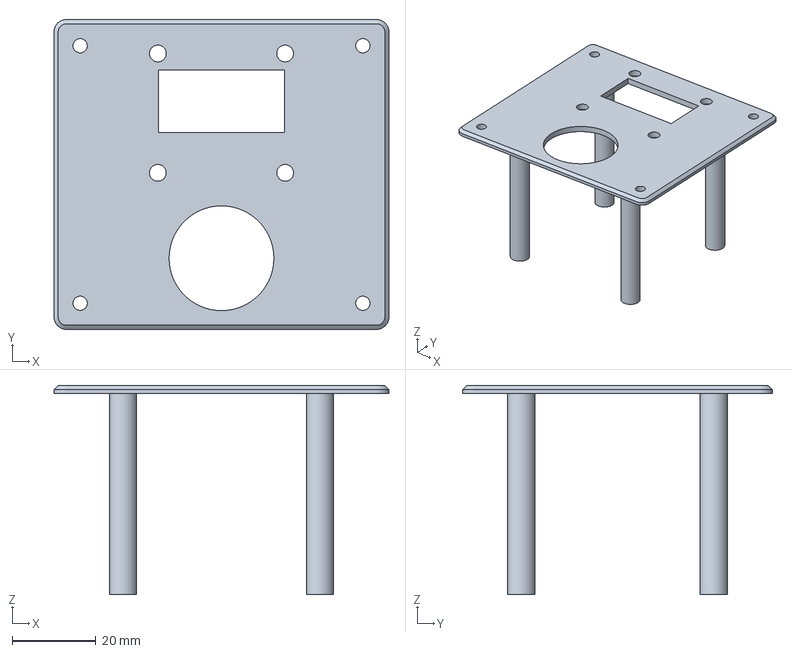
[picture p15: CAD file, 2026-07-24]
hardware/CAD files/Fingerprint Device Enclosure-Lid.3mf
80.0 x 74.0 x 50.0 mm

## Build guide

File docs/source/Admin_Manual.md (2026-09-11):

# Administrator Manual
:kicker: Role guide
:subtitle: Running the day-to-day: people, periods, holidays, attendance, and year-end
:audience: Administrators within an institution
:version: Version 3.0 | September 2026
:accent: #1d4ed8
:series: admin
:output: clients

<<<TOC>>>

## 1. At a glance

>> As an admin you keep the records right from day to day: you add and update people, set up periods and holidays, check and export attendance, and run the year-end promotion in a school. Device set-up, settings, and accounts belong to your super admin.

::: can
- Add, edit, import, and deactivate members and staff
- Manage periods and holidays (or closed days)
- View, filter, and export attendance
- Run year-end promotion (schools)
- In a shop: clients, sales, catalog, loyalty, reports
- See the account list and change your own password
:::
::: cannot
- Set up, rename, or delete scanners
- Change institution settings or labels
- Create, edit, or delete accounts
- Change anyone else's password
- Enrol fingerprints -- unless your account is tied to one unit (section 5)
:::

> [!TIP] This guide covers what your **role** can do. Read it alongside the guide for your kind of organisation -- the School, Office, or Shop manual -- which explains how the system fits your day.

### 1.1 Two kinds of admin account

Your super admin chose one of these when creating your account:

<!-- cols: 30 70 -->
| Account | What you see and manage |
| --- | --- |
| **Whole institution** | Every unit's people and records. This is the usual kind. |
| **Tied to one unit** | Only that unit's people and records -- and you can enrol fingerprints on its scanner. A padlock chip on the Attendance page shows which unit. |

### 1.2 Words used in this guide

Your institution may have renamed these under Settings, so your screens might say *Student*, *Form*, *Class*, or *Term* instead.

<!-- cols: 20 50 30 -->
| Word | Meaning | A school might say |
| --- | --- | --- |
| **Member** | A person whose attendance is recorded | Student |
| **Staff** | People on the second roster, if your institution keeps one | Teacher |
| **Group** | A set of units | Form, Grade, or Year |
| **Unit** | One place people scan -- each has its own scanner | Class |
| **Period** | A stretch of time you report on | Term |
| **Active** | Included in attendance and absence marking | -- |

## 2. Signing in and finding your way

1. Open the dashboard address your super admin gave you.
2. Enter your email and password, then press **Sign in**.

The first page is **Overview**: today's present and absent counts, the attendance rate, and the most recent scans. The menu on the left groups everything else under **Records**, **Shop** (shops only), and **Manage**, and shows only pages your role can open.

On a phone, the menu is a bar along the bottom -- **Overview**, **Attendance**, your roster, and **More**. Press **Install app** in the menu to add the dashboard to your home screen; on an iPhone use Safari's Share icon, then **Add to Home Screen**.

> [!NOTE] The dashboard signs you out after **10 minutes** without activity, and when you close the browser. Pages refresh by themselves as new scans arrive.

## 3. Members and staff

Go to **Members** (or **Staff** for the second roster -- both work the same way).

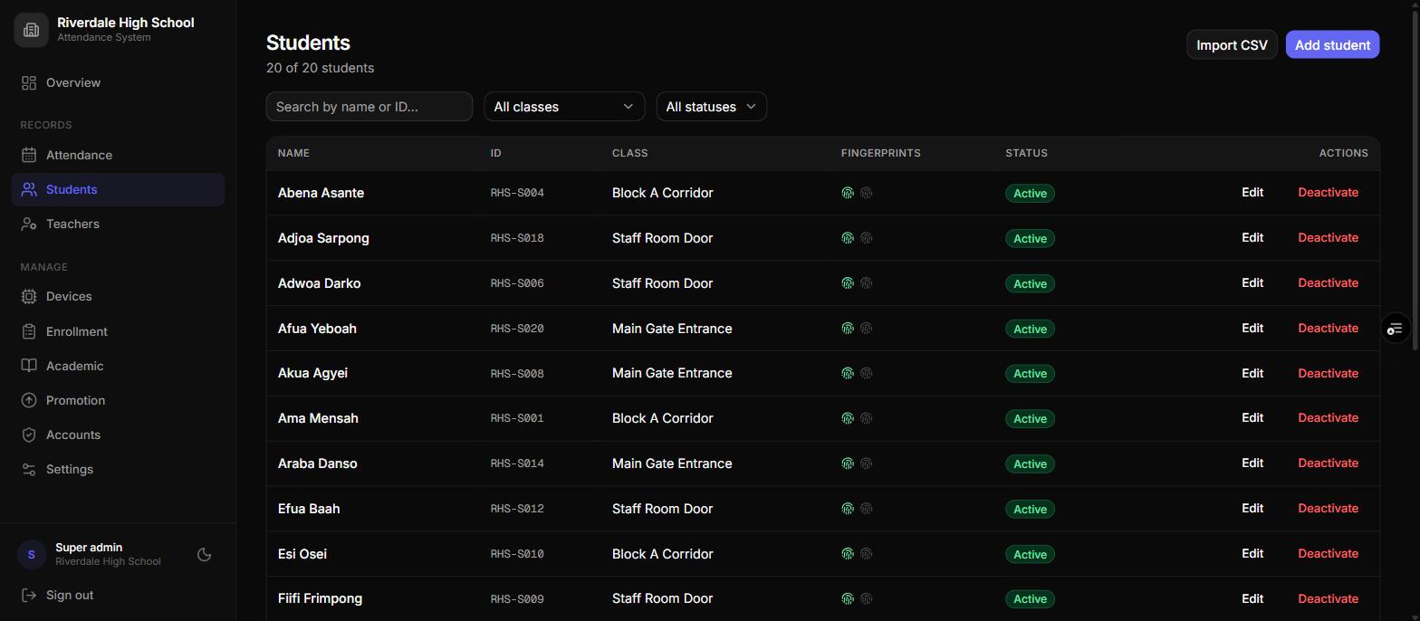
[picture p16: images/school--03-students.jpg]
The Members page, here renamed Students. Screenshots use demo data in dark mode.


### 3.1 Adding one person

1. Press **Add member**.
2. Enter their **Full name** and **ID** -- the school or staff number you already use.
3. Choose their **Unit**. The list shows each scanner as group and unit, e.g. *Form 2 Science*.
4. Press **Add member**.

The next screen offers to enrol fingerprints straight away. If your account is tied to their unit you can do it there (section 5); otherwise press **Done** and ask your super admin to enrol them.

### 3.2 Importing a spreadsheet

1. Press **Import CSV**, then download the template.
2. Fill in one row per person with the columns `sid` (ID), `fullname`, and the unit.
3. Write the unit the way the dashboard shows it, e.g. *Form 2 Science*. The unit name alone also works when it's unique.
4. Upload the file. A preview marks each row as ready or explains the problem -- a missing field, or a unit it can't find -- before anything is saved.
5. Confirm.

> [!NOTE] **Imported people start Inactive**, because they have no fingerprints yet. Activate each person once they're enrolled -- only active people are counted in attendance and absence marking.

### 3.3 Editing someone

Press the edit icon on their row to change the name, ID, or unit. The **Fingerprints** panel shows which sensor slots hold their fingers.

### 3.4 Leavers

Press **Deactivate** on their row. They stop being marked absent from that day, and their full history stays available in reports and exports. Press **Activate** to bring them back.

There is no delete button for people -- deactivating keeps the history, which you'll want for reports.

## 4. Periods and holidays

The page is called **Academic** in a school, **Periods & Holidays** in an office, and **Closed Days** in a shop (holidays only).

### 4.1 Periods

1. Press **Add term** (the button uses your institution's word for a period).
2. Enter the **Term** name, the **Year** -- e.g. *2026* or *2025/2026* -- and the start and end dates.
3. Save, then press **Set active** on its row.

Keep exactly one period active. Each scan is filed under whichever period was active at the time, and reports default to it.

### 4.2 Holidays

1. Open the **Holidays** tab and press **Add holiday**.
2. Enter a **Label** and a **Start date**. Add an **End date** for a break of several days.
3. Tick **Repeats every year** for fixed dates such as Independence Day. Leave it unticked for dates that move, such as Easter.
4. Save.

Nobody is marked absent on a holiday. Weekends don't need adding -- your super admin sets which weekdays count under **Days tracked** in Settings.

> [!TIP] Add the whole period's holidays when you create the period. A missed holiday produces a full roster of false absences that someone then has to explain.

## 5. Enrolling fingerprints (unit-tied admins)

If your account is tied to one unit, **Enrollment** appears in your menu and you can register or delete fingerprints on that unit's scanner. Otherwise your super admin does this.

1. Press **New job**.
2. Choose **Register**, the person, and **Finger 1** or **Finger 2**. The sensor slot is filled in for you.
3. Queue the job, then have the person at the scanner.
4. They press the finger when the screen says "PRESS 1/2", lift it at "REMOVE", and press the same finger again at "PRESS 2/2".
5. "ENROLLED" on the screen and **Completed** on the dashboard mean it worked.

You can also do this from the person's edit screen: the **Fingerprints** panel has an enrol button for an empty finger and **Delete** for a stored one. The Super Administrator Manual covers failed and stuck jobs in detail.

## 6. Attendance

Go to **Attendance**.

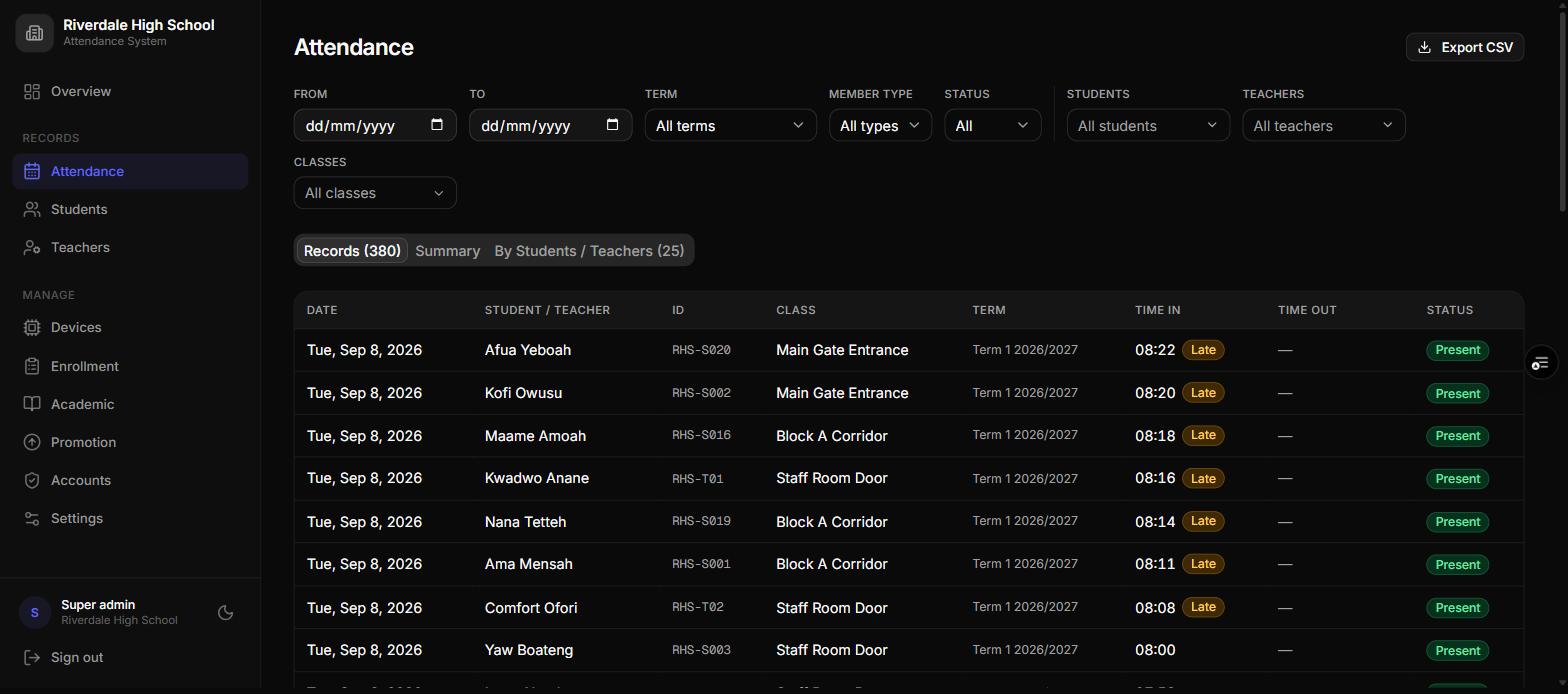
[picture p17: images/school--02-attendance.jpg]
The Attendance page with its filters and tabs.


<!-- cols: 22 78 -->
| Tab | What it shows |
| --- | --- |
| **Records** | One row per person per day: date, name, ID, unit, period, time or time in / time out, and status. |
| **Summary** | Present and absent totals, and the attendance percentage, per unit and period. |
| **By member** | Each person's days present and absent, their rate, and when they were last seen. |

Narrow the list with **From** / **To**, **Period**, **Member type**, **Status**, and the people and unit pickers. If your institution flags punctuality, late arrivals carry a **Late** badge and early departures an **Early** badge.

To export, set your filters and press **Export CSV**. The file opens in Excel or Google Sheets and contains exactly what the filters show.

> [!NOTE] Nobody marks absences by hand. Each evening the system adds an **Absent** record for every active person who didn't scan, skipping holidays and untracked weekdays. Scans saved by an offline scanner upload later and correct those records.

## 7. Year-end promotion (schools)

**Promotion** moves every active student up one group -- *Form 1* to *Form 2*, and so on. Students in the final group are deactivated instead.

1. Go to **Promotion** and read the preview: each card shows how many students move from one group to the next.
2. Check the warning list. A student is skipped if there's no scanner for their next group with the same unit name -- ask your super admin to set it up first.
3. Press **Apply promotion**, read the summary, and press **Confirm**.

> [!WARNING] Promotion can't be undone. **Export the year's attendance first.** Promoted students' fingerprint links are cleared, so each one must be **enrolled again** on their new class's scanner before they can scan.

The School Manual explains how the dashboard works out the order of groups.

## 8. Shop duties

In a shop your menu also has **Clients**, **Sales**, **Catalog**, **Loyalty**, and **Reports**. The Shop Manual covers them in full:

- **Clients** -- your customers, keyed by a unique phone number, with visit history and loyalty progress
- **Sales** -- record what was sold, to whom, and by which staff member
- **Catalog** -- products and services, with prices and product stock
- **Loyalty** -- reward rules, and issuing rewards to clients who have earned them
- **Reports** -- takings, top clients, revenue per staff member, best sellers, visits, low stock, and rewards

## 9. Accounts

**Accounts** lists everyone who can sign in to your institution's dashboard. Search by email or filter by role.

To change **your own** password, press the key icon on your row and enter a new one of at least 8 characters. Everything else on this page -- new accounts, role changes, other people's passwords -- is done by your super admin.

## 10. The scanner, at a glance

::: screens
PRESENT | Ama Mensah | **Recorded.** May say "TIME IN" or "TIME OUT".
SAVED | Ama Mensah | Offline | **Saved offline**; uploads when the internet returns.
NOT LOGGED | Ama Mensah | **Not counted** -- holiday, untracked day, or duplicate.
NO MATCH | **Not recognised.** Try again, finger flat.
NOT MAPPED | See admin | **No person linked** to that finger on this scanner.
08:14 | Form 2 Science | Offline | 3 queued | **No internet.** 3 scans waiting to upload.
:::

| Light | Meaning |
| --- | --- |
| Solid blue | Ready and online |
| Solid purple | Ready, but no WiFi |
| Green flash | Scan accepted |
| Red flash | Not recognised |
| Solid yellow | Waiting for a finger during enrollment |
| Breathing yellow | Waiting to be set up |
| Breathing red | Installing an update -- do not unplug |

## 11. Getting help

<!-- cols: 50 50 -->
| Problem | Who to ask |
| --- | --- |
| Someone needs fingerprints enrolled | Your super admin (or you, if tied to their unit) |
| A scanner isn't working or shows an odd screen | Your super admin |
| A new account, a role change, or someone else's password | Your super admin |
| A setting or label needs changing | Your super admin |
| A whole day shows everyone absent | Check holidays first, then ask your super admin to check the scanner |

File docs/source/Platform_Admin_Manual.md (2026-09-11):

# Platform Administrator Manual
:kicker: Operator guide
:subtitle: Deploying, onboarding, and maintaining the attendance platform
:audience: The platform administrator -- the developer or operator who runs the service
:version: Version 3.0 | September 2026 | Firmware 1.10.0
:accent: #b45309
:series: platform
:output: operators
:toc_depth: 2

<<<TOC>>>

<<<PAGEBREAK>>>

## 1. Introduction

>> This manual is for whoever runs the platform: one cloud deployment that serves every institution. You deploy the backend and dashboard, build and flash scanners, onboard institutions, and keep secrets and certificates current.

`platform_admin` is the only role that sees every institution. Protect its credentials accordingly. For the design behind what follows -- schema, edge-function contracts, firmware internals -- see the **Technical Documentation** alongside this manual.

### 1.1 Roles at a glance

<!-- cols: 22 38 40 -->
| Role | Scope | Created by |
| --- | --- | --- |
| `platform_admin` | Every institution | You, in SQL (section 3.3) |
| `super_admin` | One institution, full control | You at onboarding; then other super admins |
| `admin` | One institution, or one unit of it | A super admin |
| `teacher` / `staff` | One unit, read-only | A super admin |
| `cashier` | One shop: clients, sales, catalog | A super admin |

### 1.2 Institution types

<!-- cols: 16 42 42 -->
| Type | Adds | Hides |
| --- | --- | --- |
| `school` | Academic terms, year-end promotion | -- |
| `office` | Periods and holidays | Promotion |
| `shop` | Clients, sales, catalog, loyalty, reports, the cashier role | Promotion, academic terms, the student roster |

## 2. How the system fits together

Three tiers, all yours:

- **ESP32 firmware** -- one Arduino sketch, flashed over USB once and updated over the air after that
- **Supabase** -- PostgreSQL 17, six Deno edge functions, pg_cron, and pg_net
- **Next.js dashboard** -- on Vercel; every Supabase call runs server-side, so no key ever reaches a browser

All traffic is HTTPS. Scanners validate server certificates against a CA bundle compiled into the firmware (section 4.3).

### 2.1 How scanners authenticate

Each scanner holds its **own** secret, issued when it is first assigned and stored in `devices.device_secret`. A compromised scanner exposes only itself. `devices.revoked = true` is the server-side kill switch: the edge functions refuse that scanner immediately, whether or not the physical unit is ever wiped.

> [!NOTE] Older builds shared one `institutions.device_secret` per institution. That column survives only as a transitional fallback until every scanner has re-provisioned -- see `docs/for-operators/device-secret-migration-rollout.md`.

## 3. Initial deployment

### 3.1 Supabase

1. Create a Supabase project.
2. Enable the **pg_net** and **pg_cron** extensions (Database -> Extensions). The nightly absence job can't call `net.http_post()` without pg_net.
3. Store the two values the nightly job reads from Vault at run time:

```sql
select vault.create_secret('https://<ref>.supabase.co', 'supabase_project_url');
select vault.create_secret('<a long random string>', 'cron_secret');
```

4. Run every migration in `backend/supabase/migrations/`, in filename order. The last cron migration schedules `mark-absent-daily` at **21:00 UTC**.
5. Deploy the edge functions and set their secrets. `CRON_SECRET` must equal the Vault `cron_secret`; `BOOTSTRAP_SECRET` must equal the one in the firmware's `secrets.h`.

```bash
cd backend/supabase
supabase functions deploy --project-ref <ref>
supabase secrets set --project-ref <ref> BOOTSTRAP_SECRET=<value> CRON_SECRET=<value>
```

`SUPABASE_URL` and `SUPABASE_SERVICE_ROLE_KEY` are provided to functions automatically.

> [!WARNING] Migrations carry a "do not apply to cloud blind" header for a reason. Read each one before applying -- several widen a constraint that must land before the matching dashboard deploy, and a few are order-sensitive.

> [!NOTE] `mark-absent` works out "today" in each institution's own timezone, so it must run after the last scan of the day and before local midnight everywhere you operate. 21:00 UTC suits West Africa and Europe; reschedule in a new migration if you onboard institutions far from UTC.

### 3.2 Vercel

1. Import the repository into Vercel with `frontend` as the root directory, and confirm which branch Production deploys from.
2. Set exactly three environment variables: `NEXT_PUBLIC_SUPABASE_URL`, `NEXT_PUBLIC_SUPABASE_ANON_KEY`, and `SUPABASE_SERVICE_ROLE_KEY`.
3. Deploy.

### 3.3 Your platform admin account

Create your user in Supabase Auth, copy its UUID, and give it the platform role:

```sql
insert into profiles (id, role) values ('<your-auth-user-uuid>', 'platform_admin');
```

A platform admin has no institution. Signed in, you see **Institutions** and **Create institution** in the menu, and every page can be filtered by institution.

## 4. Firmware

### 4.1 Prerequisites

- Arduino IDE 2.x with the Espressif **ESP32** board package
- Libraries: **Adafruit Fingerprint Sensor Library**, **RTClib**, **Adafruit GFX Library**, **Adafruit SSD1306**, and **ArduinoJson** (version 7)
- WiFi, HTTPS, the web server, DNS, SPIFFS, and OTA updates come with the ESP32 core -- nothing extra to install
- A USB cable

### 4.2 secrets.h

Copy `firmware/ClassAttendance_Current_RTC/secrets.example.h` to `secrets.h` (gitignored). It defines one value, which must match the edge functions' `BOOTSTRAP_SECRET`:

```c
#define BOOTSTRAP_SECRET "your_bootstrap_secret_here"
```

**There is no compile-time WiFi.** A factory-fresh scanner broadcasts `Attendance-Setup` (password `setup1234`) with a setup page at `192.168.4.1`, and whoever is on site enters the real network. You never need a client's WiFi password to build their scanner. After that first boot, only an enrolled master finger can reopen the portal.

> [!WARNING] Enrol a master finger on every scanner before it leaves your hands, and make sure the client enrols their own. Without one, a WiFi change means the scanner comes back to you for reflashing -- the most common avoidable support call.

### 4.3 certs.h

`certs.h` holds `ROOT_CA_BUNDLE`, the PEM bundle mbedTLS validates against. It must contain every certificate in each chain, not just the roots:

<!-- cols: 45 55 -->
| Certificate | Needed for |
| --- | --- |
| WE1 (Google Trust Services) intermediate | Supabase |
| GlobalSign ECC Root CA R4 | Supabase |
| Sectigo Public Server Auth CA DV E36 | GitHub API -- OTA release checks |
| Sectigo Public Server Auth Root E46 | GitHub API |
| ISRG Root X1 | GitHub's download CDN -- OTA binaries |

**mbedTLS can't fetch missing intermediates (no AIA).** If a server omits one from its handshake and it isn't in the bundle, the connection fails with a misleading "connection refused". To capture a live chain when refreshing, in PowerShell:

```powershell
$req = [Net.HttpWebRequest]::Create("https://<ref>.supabase.co")
$req.GetResponse() | Out-Null
$req.ServicePoint.Certificate
```

### 4.4 Flashing

1. Open `ClassAttendance_Current_RTC.ino`.
2. Board: **ESP32 Dev Module**. Select the COM port.
3. Upload.
4. Watch the Serial Monitor at 115200 baud to confirm it boots.

The current version is **1.10.0**. Bump `FIRMWARE_VERSION` on every release -- OTA compares against it (section 7).

## 5. Onboarding an institution

### 5.1 Creating it

1. Go to **Create institution**.
2. Enter the **Name**, choose the **Type** -- School, Office, or Shop / Retail -- and set the **Timezone** (an IANA name such as *Africa/Accra*).
3. Choose which member types are tracked and each one's scan mode. All of this can be changed later in Settings.
4. Enter the first super admin's **Full name**, **Email**, and a **Temporary password** of at least 8 characters.
5. Press **Create**.

Everything else -- labels, currency, branding, modules, holidays -- the super admin sets up. Hand over the dashboard address, the credentials, and the right manuals (section 5.3).

### 5.2 Attaching scanners

Scanners only ever enter the system by powering on: a new one calls `/register` and waits, showing "PENDING" and breathing yellow.

1. Go to **Devices**. New scanners are listed under **Pending assignment**, by MAC address.
2. Press **Assign** and choose the institution. The scanner receives its own secret on its next poll and turns solid blue.
3. The institution's super admin then sees it under **Pending setup** and gives it a group and unit.

To take a scanner out of service, see section 6.1.

### 5.3 What to hand each client

The client PDFs are in `docs/for-clients/`.

<!-- cols: 16 84 -->
| Type | Give them |
| --- | --- |
| School | `School_Manual.pdf`, `Super_Admin_Manual.pdf`, `Admin_Manual.pdf`, `Staff_Manual.pdf`, `Biometric_Privacy_Note.pdf` |
| Office | `Office_Manual.pdf`, `Super_Admin_Manual.pdf`, `Admin_Manual.pdf`, `Staff_Manual.pdf`, `Biometric_Privacy_Note.pdf` |
| Shop | `Shop_Manual.pdf`, `Super_Admin_Manual.pdf`, `Admin_Manual.pdf`, `Biometric_Privacy_Note.pdf` |

The type guide explains *what the system does for their kind of organisation*; the role guides explain *what each login can do*. The privacy note answers the question every school and data-protection officer asks about fingerprints.

### 5.4 Creating a super admin by hand

If you'd rather use SQL: create the user in Supabase Auth, copy the UUID, then

```sql
insert into profiles (id, role, institution_id)
values ('<uuid>', 'super_admin', '<institution-uuid>');
```

### 5.5 Institution lifecycle

<!-- cols: 20 80 -->
| Status | Effect |
| --- | --- |
| `active` | Normal operation. |
| `suspended` | Temporary -- e.g. non-payment. Every user is sent to `/suspended`. Toggled from the **Institutions** page. |
| `deactivated` | Long-term offboarding. Behaves like `suspended`; data is kept for export. Set it in SQL. |

Suspension is enforced in the dashboard's `verifySession()`, not by RLS, because the dashboard reads through the service role. It doesn't touch scanners -- they carry on and resume normally when the institution is reactivated.

**Deleting** an institution, from its page under **Institutions**, takes three confirmations. It removes all its people, attendance, periods, holidays, enrollment jobs, and accounts, and queues a wipe for each of its scanners. It can't be undone.

## 6. Secrets and scanner security

### 6.1 Per-scanner secrets

Each scanner's secret is minted by `assignment-poll` when it is first assigned, stored in `devices.device_secret`, and kept on the scanner in SPIFFS.

- **Block a scanner now:** set `devices.revoked = true`. Its next call is refused (401) and its screen shows "REVOKED".
- **Wipe and re-provision it:** delete it from the **Devices** page (or insert a `device_resets` row). On its next poll it erases its identity and registers again as new, then receives a fresh secret when reassigned.

Prefer revoking over a hard delete when a scanner is lost or stolen: revocation is immediate, whereas the wipe only lands if the scanner ever connects again.

### 6.2 BOOTSTRAP_SECRET

Compiled into the firmware and used only before a scanner is assigned. To rotate it, update `secrets.h` and the functions' `BOOTSTRAP_SECRET` together, then reflash or release over the air. Already-assigned scanners are unaffected; unassigned ones on the old value can't register until updated.

### 6.3 CRON_SECRET

The cron job reads the secret from Vault each time it fires, so there's nothing to reschedule. Update the `cron_secret` entry in Vault and set the same value as the functions' `CRON_SECRET`, in that order and close together.

## 7. Over-the-air releases

Scanners check GitHub Releases each time they boot, after a random 0--120 second delay so a power cut doesn't send them all at once. They install only a strictly newer version.

1. In Arduino IDE: **Sketch -> Export Compiled Binary**.
2. Create a GitHub release tagged `firmware-v<version>` -- e.g. `firmware-v1.11.0` -- higher than the current `FIRMWARE_VERSION`.
3. Attach the compiled `.bin`. The scanner installs the release's first `.bin` asset, so attach exactly one.
4. Scanners update on their next boot.

There's no forced push. During the update the screen shows "OTA UPDATE" and "Do not unplug", and the light breathes red.

## 8. Database

- **Migrations** live in `backend/supabase/migrations/`. Apply new ones in the SQL editor, in filename order, after reading them. Never re-run old ones except when building a fresh database.
- **Backups:** Supabase takes daily backups on Pro and above, with point-in-time restore from its dashboard. For extra safety, take on-demand `pg_dump` exports with the connection string.
- **Raw data:** the SQL and table editors have full service-role access. There is no undo for destructive SQL.

## 9. Troubleshooting

<!-- cols: 30 28 42 -->
| Symptom | Likely cause | Fix |
| --- | --- | --- |
| "Bootstrap HTTP client error: connection refused" | TLS chain failure | Check `certs.h` has every intermediate (section 4.3). Try `setInsecure()` briefly to prove reachability. |
| 404 "Device not found" on the provisioning poll | No `devices` row for that MAC, or no `provisioning_token` | Check the table; confirm the provisioning-token migration ran. |
| mark-absent: "schema net does not exist" | pg_net not enabled | Enable it under Database -> Extensions. |
| mark-absent returns 401 | Vault `cron_secret` and the functions' `CRON_SECRET` differ | Set them to the same value (section 6.3). |
| No absences appear at all | Cron job missing, or Vault secrets absent | Check `select * from cron.job` and the Vault entries. |
| "unauthorized" after signing in | No `profiles` row, or the wrong role | Insert or correct the profile for that auth user. |
| Users sent to `/suspended` | `institutions.status` isn't `active` | Set it back to `active` if that wasn't intended. |
| Scanner stuck on "PENDING" | Never assigned | Assign it under **Devices -> Pending assignment**. |
| Scanner shows "REJECTED" or "REVOKED" | Its secret is refused, or `revoked` is true | Check `devices.revoked`; re-provision if needed. |
| Idle screen says "No server" | WiFi works but HTTPS calls fail | Usually TLS or DNS. It re-associates every 60 s and reboots after 5 minutes unreachable; scans stay queued. |
| Re-registers after every SPIFFS clear | The clear ran after `loadProvisioning()` cached the id | The clear must be the first thing in `setup()`, followed by `ESP.restart()`. |
| OTA fails fetching GitHub releases | ISRG Root X1 or a Sectigo certificate missing | Ensure all five certificates are in `ROOT_CA_BUNDLE`. |
| Enrollment jobs fail as "OCCUPIED" after promotion | Old prints still on the sensor | The job's **+ overwrite** action, or a **Clear all** job on that scanner. |

## 10. Pre-handover checklist

Run through this before you leave a client's site.

- [ ] Institution created with the right **type** and **timezone**
- [ ] Super admin signed in and changed the temporary password
- [ ] Settings done: labels, scan modes, days tracked, punctuality, time display, branding (and currency and modules for a shop)
- [ ] Current period active, and its holidays or closed days entered
- [ ] Every scanner assigned, configured with a group and unit, and showing solid blue
- [ ] **A master finger enrolled on every scanner** -- and the client knows whose it is
- [ ] The client has enrolled at least one person themselves, unaided
- [ ] A real scan recorded and found on the dashboard
- [ ] For shops: catalog loaded, a test sale recorded, and a cashier login working
- [ ] Manuals and the privacy note handed over (section 5.3)
- [ ] The client knows how to reach you

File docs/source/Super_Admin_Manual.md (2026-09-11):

# Super Administrator Manual
:kicker: Role guide
:subtitle: Scanners, enrollment, settings, and accounts -- full control of your institution
:audience: Super administrators -- the owner account of an institution
:version: Version 3.0 | September 2026
:accent: #4338ca
:series: super_admin
:output: clients
:toc_depth: 2

<<<TOC>>>

<<<PAGEBREAK>>>

## 1. At a glance

>> As super admin you own your institution's set-up: its scanners, its fingerprints, its settings, and who can sign in. Everything an admin can do, you can do too.

::: can
- Set up, rename, and delete scanners
- Enrol and delete fingerprints, including master fingers
- Add, import, edit, and deactivate people
- Manage periods, holidays, and tracked weekdays
- View and export all attendance
- Change settings, labels, branding, and modules
- Create, edit, and delete accounts -- including other super admins
:::
::: cannot Only your platform administrator can
- Add a brand-new scanner to your institution
- Reflash a scanner, or update its firmware
- Block a lost or stolen scanner instantly
- Restore access if every super admin is locked out
- Create or remove whole institutions
:::

> [!TIP] This guide covers what your **role** can do. Read it alongside the guide for your kind of organisation -- the School, Office, or Shop manual.

### 1.1 Words used in this guide

You can rename most of these under **Settings -> Custom labels** (section 10). This guide uses the defaults.

<!-- cols: 20 50 30 -->
| Word | Meaning | A school might say |
| --- | --- | --- |
| **Member** | A person whose attendance is recorded | Student |
| **Staff** | People on the second roster, if you keep one | Teacher |
| **Group** | A set of units | Form, Grade, or Year |
| **Unit** | One place people scan -- one scanner per unit | Class |
| **Period** | A stretch of time you report on | Term |
| **Enrollment** | Saving someone's fingerprint on a scanner | -- |
| **Master finger** | An admin's finger that reopens a scanner's WiFi setup | -- |

## 2. Signing in and finding your way

Open the dashboard address, enter your email and password, and press **Sign in**. There is no self-service password reset: another super admin can reset yours from **Accounts**, or your platform administrator can if you're the only one.

The Overview page -- today's counts and the latest scans. Screenshots use demo data in dark mode.

The menu groups pages under **Records**, **Shop** (shops only), and **Manage**:

<!-- cols: 30 70 -->
| Page | What it's for |
| --- | --- |
| **Overview** | Today's present and absent counts, attendance rate, and the latest scans. Shops see takings, visits, and stock warnings. |
| **Attendance** | Every attendance record, with filters, totals, and CSV export. |
| **Members** and **Staff** | Your rosters. |
| **Clients**, **Sales**, **Catalog**, **Loyalty**, **Reports** | The retail module -- shops only. |
| **Devices** | Your scanners. |
| **Enrollment** | Fingerprint jobs sent to scanners. |
| **Academic** | Periods and holidays. Called **Periods & Holidays** in an office and **Closed Days** in a shop. |
| **Promotion** | Year-end promotion -- schools only. |
| **Accounts** | Who can sign in, and with which role. |
| **Settings** | Names, labels, branding, attendance rules, and modules. |

On a phone, the menu becomes a bottom bar with **More** for everything else. **Install app** in the menu adds the dashboard to a home screen (on an iPhone: Safari's Share icon, then **Add to Home Screen**). For security, the dashboard signs you out after **10 minutes** without activity and when the browser closes.

## 3. First-time set-up, in order

Work through these once. Later steps depend on earlier ones.

1. **Settings** -- name, logo, timezone, labels, what you track, and the days you track (section 10).
2. **Periods and holidays** -- create the current period, press **Set active**, and add its holidays (section 7).
3. **Scanners** -- give each new scanner its group and unit (section 4.1).
4. **WiFi** -- connect each scanner to your network on site (section 4.4).
5. **Master finger** -- enrol one on every scanner before anything else goes wrong (section 4.5).
6. **People** -- add them one by one or import a spreadsheet (section 5).
7. **Fingerprints** -- enrol everyone, then activate them (section 6).
8. **Accounts** -- create logins for your admins, teachers or supervisors, and cashiers (section 11).

## 4. Scanners

### 4.1 How a new scanner joins

A new scanner can't join your institution by itself -- your platform administrator attaches it first. The whole journey looks like this:

1. The scanner is powered on for the first time. Its screen shows "PENDING" with its hardware address, and the light breathes yellow.
2. Your platform administrator assigns it to your institution. The light turns solid blue.
3. It appears on your **Devices** page under **Pending setup**, marked *Not configured*.
4. Press **Configure** and enter its **Group** and **Unit** -- e.g. *Form 2* and *Science*. The preview shows how it will be named.
5. Press **Save changes**. The scanner shows its new name on screen within a minute, and you can now add people to that unit.

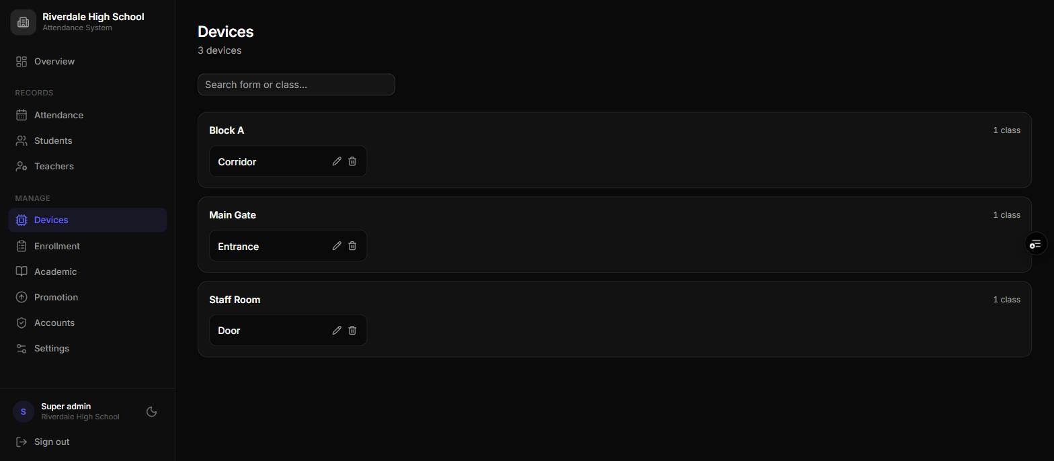
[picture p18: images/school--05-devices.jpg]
The Devices page: scanners grouped by group, each with edit and delete icons.


> [!TIP] Name groups so they sort in order -- *Form 1*, *Form 2*, *Form 3* -- and reuse the same unit names in every group, e.g. *Science* and *Arts*. Year-end promotion relies on both (section 9).

### 4.2 Renaming a scanner

Press the pencil icon on its tile, change the group or unit, and press **Save changes**. The name on the scanner's screen follows automatically.

### 4.3 Deleting a scanner

Press the bin icon on its tile and confirm with **Delete device**.

> [!WARNING] Everyone assigned to that scanner loses their unit and can't scan until you give them a new one. The physical scanner wipes its identity on its next connection and starts again as a new, unassigned device. Attendance history is kept. Only delete a scanner you are retiring or rebuilding.

### 4.4 First-time WiFi setup

A factory-fresh scanner has no WiFi saved, so it opens its own setup network the first time it boots.

1. Power on the scanner. The screen shows "SETUP" and the light blinks purple.
2. On a phone or laptop, join the WiFi network **Attendance-Setup** with the password **setup1234**.
3. If a setup page doesn't open by itself, browse to `http://192.168.4.1`.
4. Enter your WiFi name and password and press **Save & Connect**. The scanner saves them and restarts.
5. Reconnect your phone to your normal WiFi.

The setup network only opens by itself on that very first boot. After that, only a master finger can reopen it. Keep the setup password within your admin team.

### 4.5 Enrolling a master finger -- do this on day one

A master finger is an admin's finger that reopens WiFi setup later -- when you move a scanner or change your WiFi password. It never records attendance.

1. Go to **Enrollment** and press **New job**.
2. Choose the command **Reg. master**.
3. Choose the scanner, and type a **Name** for whose finger it is, e.g. *Principal*.
4. Queue the job. At the scanner, press the finger when asked, lift it, and press it again.

> [!WARNING] Enrol a master finger on **every** scanner while it still has a working connection. Without one, a WiFi change means the scanner has to go back to your platform administrator to be reflashed.

### 4.6 Changing the WiFi later

1. At the scanner, scan the master finger. The screen shows "CONFIRM?".
2. Scan the same finger again within 8 seconds. The screen shows "CONFIRMED" and the light flashes yellow five times. A different finger, or waiting too long, cancels safely.
3. The **Attendance-Setup** network opens. Follow steps 2--5 of section 4.4.

### 4.7 What the screen tells you

When nobody is scanning, the screen shows the clock, the scanner's name, and its connection. The third line matters most when something is wrong:

::: screens
08:14 | Form 2 Science | Online | **Online.** Everything is working.
08:14 | Form 2 Science | No server | **No server.** WiFi works but the server can't be reached; scans are saved.
08:14 | Form 2 Science | Offline | 3 queued | **Offline.** Three scans are saved and will upload.
PENDING | 24:6F:28:A1:B2:C3 | **Not yet assigned.** Contact your platform administrator.
SETUP | Attendance-Setup | 192.168.4.1 | **WiFi setup is open** (section 4.4).
OTA UPDATE | Do not unplug | **Updating.** Leave it on; it restarts by itself in 1--3 minutes.
:::

After a scan:

<!-- cols: 34 66 -->
| Screen shows | What it means |
| --- | --- |
| "SCANNED" and a name | Recognised; checking with the server. Resolves within a second or two. |
| "PRESENT", "TIME IN", or "TIME OUT" | Recorded. |
| "SAVED", a name, and "Offline" | Recognised with no internet. Stored and uploaded automatically later. |
| "NOT LOGGED" | The server accepted the scan but didn't count it -- a holiday, an untracked weekday, no active period, or already recorded today. |
| "COOLDOWN" and a name | Same person scanned again within a minute. Normal. |
| "NO MATCH" | Fingerprint not recognised. Try again; if it keeps happening, re-enrol that finger. |
| "NOT MAPPED" and "See admin" | The finger is stored on the sensor but no person is linked to it on this scanner -- usually after promotion or a deleted person. Re-enrol or delete that slot. |
| "SCAN ERROR" | The scan couldn't be processed. Try again. |
| "REJECTED" or "REVOKED" | The server refuses this scanner. Contact your platform administrator. |
| "RESET" and "Re-provisioning" | The scanner was deleted and is wiping itself to start again. |

### 4.8 What the light tells you

| Light | Meaning |
| --- | --- |
| Solid blue | Ready and online. Normal. |
| Solid purple | Ready, but no WiFi. Scans are saved for later. |
| Blinking purple | WiFi setup is open. |
| Green flash | Scan accepted, or a task succeeded. |
| Red flash | Not recognised, or a task failed. |
| Solid yellow | Waiting for a finger -- during enrollment, or for the second master scan. |
| Five quick yellow flashes | Master finger confirmed; WiFi setup is opening. |
| Breathing yellow | Waiting to be assigned by your platform administrator. |
| Breathing red | Installing a firmware update -- do not unplug. |

## 5. Members and staff

### 5.1 Adding one person

1. Go to **Members** (or **Staff**) and press **Add member**.
2. Enter their **Full name**, their **ID**, and choose their **Unit**.
3. Press **Add member**. The next screen offers **Enroll fingerprints now?** -- queue Finger 1 and Finger 2 from there, or press **Done** and do it later.

### 5.2 Importing a spreadsheet

Press **Import CSV** and download the template. Fill in one row per person with the columns `sid` (ID), `fullname`, and the unit -- written as the dashboard shows it, e.g. *Form 2 Science*. Upload it: a preview flags any row with a missing field or a unit it can't match before anything is saved.

> [!NOTE] **Imported people start Inactive**, because they have no fingerprints yet. Enrol each person, then press **Activate**. Only active people count towards attendance and absence marking.

### 5.3 Editing, fingerprints, and leavers

Press the edit icon to change a person's name, ID, or unit. The **Fingerprints** panel lists their stored fingers by sensor slot: **Delete** removes one from the scanner; an empty finger can be enrolled from there.

To retire someone, press **Deactivate**. They stop being marked absent and their history is kept. People are never deleted from the dashboard.

## 6. Fingerprint enrollment

Enrollment is remote: you queue a job on the dashboard, and the scanner picks it up within about ten seconds and walks the person through it.

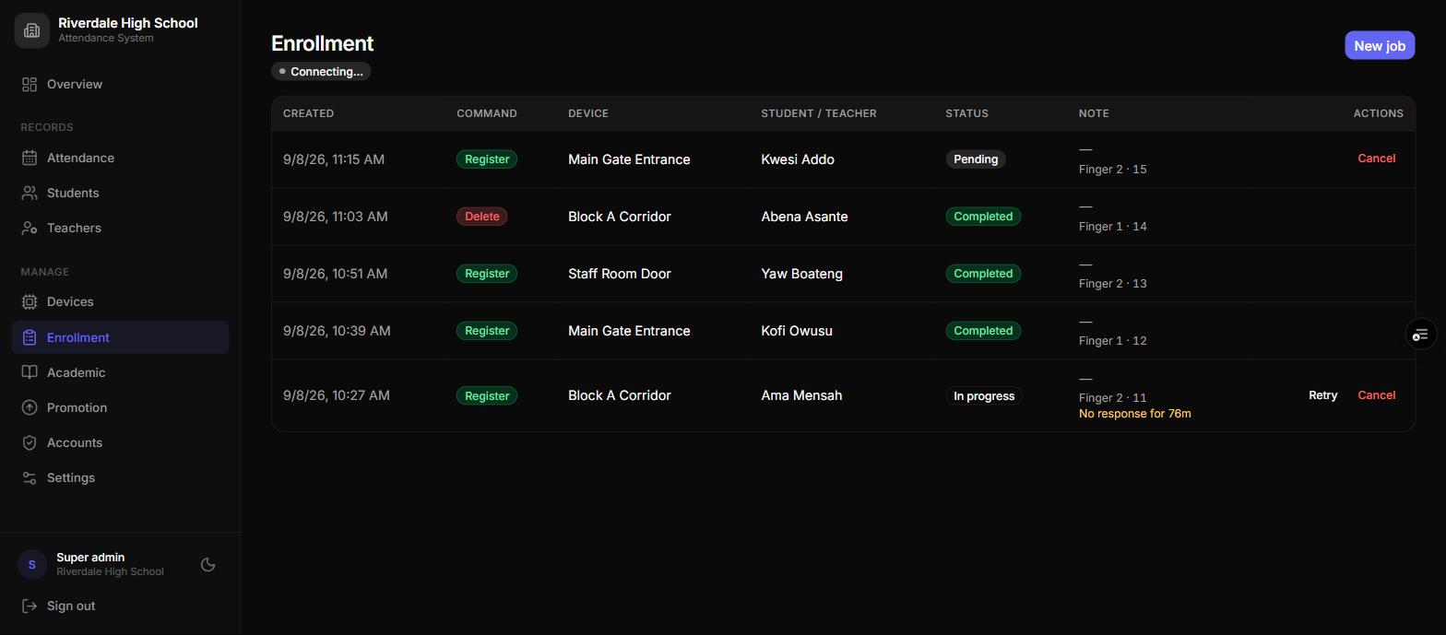
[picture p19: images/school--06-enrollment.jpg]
The Enrollment page. The row at the bottom shows a stuck job with its Retry and Cancel actions.


### 6.1 Queuing a job

Press **New job** and fill in:

<!-- cols: 28 72 -->
| Field | What to enter |
| --- | --- |
| **Command** | What the scanner should do -- see the table below. |
| **Device** | The scanner the person will use -- their unit's scanner. |
| **Member** | Who is enrolling. For a master finger you type a **Name** instead. |
| **Finger slot** | **Finger 1** or **Finger 2**. Enrol two fingers so a cut or plaster doesn't lock someone out. |
| **Sensor slot (1--127)** | Where the print is stored on the sensor. Filled in with the next free slot -- leave it. |
| **Allow overwriting an occupied slot** | Only tick this when you are deliberately replacing a stored print. You'll be asked to confirm. |

<!-- cols: 22 78 -->
| Command | What it does |
| --- | --- |
| **Register** | Saves a new fingerprint for a person. |
| **Delete** | Removes one stored fingerprint from the scanner. |
| **Reg. master** | Saves a master finger (section 4.5). |
| **Del. master** | Removes the master finger. |
| **Clear all** | Erases **every** fingerprint on that scanner, including the master. |

### 6.2 At the scanner

The person must be at the scanner while the job runs. The screen guides them:

::: screens 4
PRESS 1/2 | Kofi Owusu | **Press** the finger flat.
REMOVE | Kofi Owusu | **Lift** the finger.
PRESS 2/2 | Kofi Owusu | **Press** the same finger again.
ENROLLED | Kofi Owusu | **Done.** The light flashes green.
:::

If it goes wrong, the screen says why: "MISMATCH" (the two presses weren't the same finger), "TIMED OUT" (nobody pressed in time), "BAD SCAN" (a poor image), or "OCCUPIED" (the slot already holds a print and overwriting wasn't allowed).

### 6.3 Job status and fixing problems

<!-- cols: 22 78 -->
| Status | Meaning |
| --- | --- |
| **Pending** | Waiting for the scanner to collect it. |
| **In progress** | The scanner has it; the person should be scanning. |
| **Completed** | The fingerprint is saved. |
| **Failed** | It didn't work. The **Note** column says why. |

<!-- cols: 36 64 -->
| You see | Do this |
| --- | --- |
| "No response for 12m" under a job | The scanner lost the job or its connection. Press **Retry** to send it again, or **Cancel**. |
| **Pending** for a long time | The scanner is off or offline. Check its screen; **Cancel** if you queued it by mistake. |
| **Failed** | Press **Re-queue** to try again once the person is back at the scanner. |
| **Failed** with an occupied slot | Press **+ overwrite** to retry and replace what's in that slot -- only if that print no longer belongs to anyone. |

The badge beside the page title shows whether the page is receiving live updates.

## 7. Periods, holidays, and tracked days

- **Periods:** press **Add term**, enter the name, year, and dates, save, then press **Set active** on its row. Keep exactly one active -- each scan is filed under the active period.
- **Holidays:** on the **Holidays** tab press **Add holiday**, enter a label and dates, and tick **Repeats every year** for fixed dates. Nobody is marked absent on a holiday.
- **Tracked days:** under **Settings -> Days tracked**, select the weekdays that count. Scans on other days are ignored and no absences are added, so a Monday-to-Friday institution simply leaves Saturday and Sunday unselected.

## 8. Attendance

**Attendance** has three tabs -- **Records**, **Summary** (totals per unit and period), and **By member** (each person's totals and last scan) -- and filters for dates, period, member type, status, people, and units. With punctuality flags on, late arrivals carry a **Late** badge and early departures an **Early** badge. **Export CSV** downloads exactly what the filters show.

> [!NOTE] Each evening the system adds an **Absent** record for every active person who didn't scan, skipping holidays and untracked days. Scans saved by an offline scanner upload later and correct those records.

## 9. Year-end promotion (schools)

**Promotion** moves every active student to the next group -- students in the last group are deactivated instead. The dashboard works out the order by sorting your group names (*Form 1* before *Form 2* before *Form 10*), and moves each student to the scanner with the **same unit name** in the next group. A student whose next group has no matching unit is skipped and listed as a warning.

1. Go to **Promotion** and review the preview and any warnings.
2. Add any missing scanners first, so nobody is skipped.
3. Export the year's attendance.
4. Press **Apply promotion**, then **Confirm**.

> [!WARNING] Promotion can't be undone, and it clears promoted students' fingerprint links -- **every promoted student must be enrolled again** on their new scanner. Their old prints stay on last year's scanners, so a new enrollment may fail as "OCCUPIED": use **+ overwrite** on that job, or run **Clear all** on each scanner first and then re-enrol everyone, including the master finger.

## 10. Settings

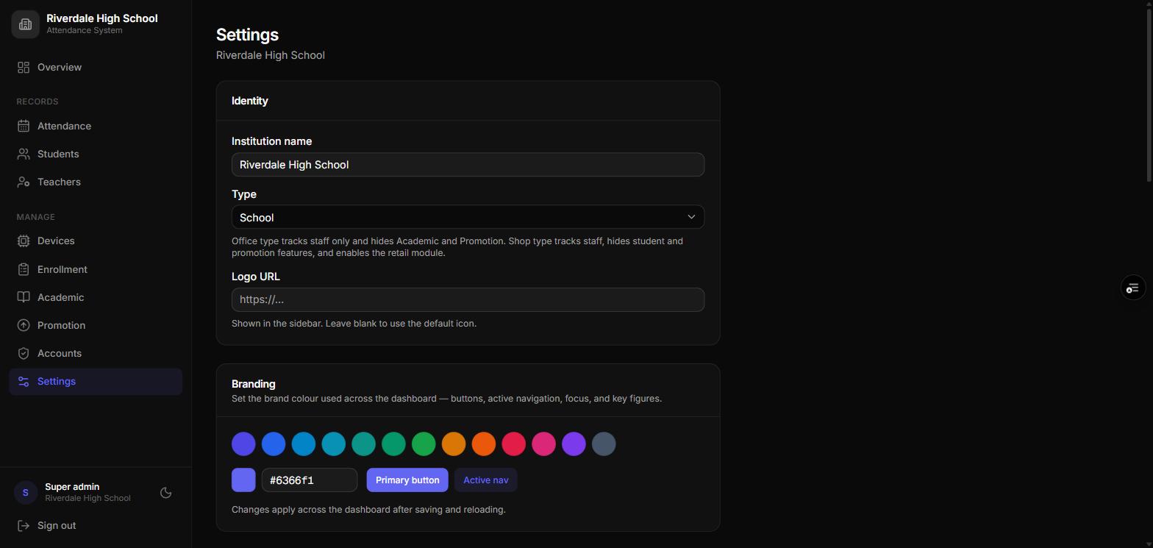
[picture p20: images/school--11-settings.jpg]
Settings, showing the Identity and Branding sections.


<!-- cols: 30 70 -->
| Setting | What it controls |
| --- | --- |
| **Institution name** | Shown at the top of the menu. |
| **Type** | School, Office, or Shop -- decides which pages and modules exist. Talk to your platform administrator before changing it on a live institution. |
| **Logo URL** | A web link to your logo image, shown in the menu. Leave blank for the default icon. |
| **Branding** | Pick a preset colour or enter your own. Colours buttons, active menu items, and key figures after you save and reload. |
| **Custom labels** | Your own words for Member, Group, Unit, Period, and Staff -- used everywhere, including CSV headings. |
| **Track students** / **Track staff** | Which rosters exist, each with a **Scan mode**: *Present / Absent* (one scan a day) or *Time In / Time Out* (first scan in, second out). |
| **Days tracked** | The weekdays that count. Untracked days record nothing and generate no absences. |
| **Flag late arrivals** | Set an **Expected start time** and a **Grace period**. Arrivals after start plus grace are marked **Late**. |
| **Flag early departures** | Set an **Expected end time** and a **Grace period**. Time-out scans before end minus grace are marked **Early**. Time In / Time Out mode only. |
| **Timezone** | When your day starts and ends -- e.g. *Africa/Accra*. |
| **Time display** | 24-hour (13:30) or 12-hour (1:30 PM) on the dashboard. Exports always stay 24-hour. |
| **Name shown on device screen during a scan** | Full name, first name, initial + last name, ID number only, or no name. Enrollment always shows the full name. |
| **Currency**, **Sell services**, **Sell products**, **Enable loyalty rewards** | The retail module -- shops only. See the Shop Manual. |

> [!TIP] "Name shown on device screen" is a privacy control. Where a queue can read the screen, *first name* or *initial + last name* avoids showing everyone's full name.

## 11. Accounts

### 11.1 Creating an account

1. Go to **Accounts** and press **Add account**.
2. Enter their **Email** and an initial **Password** of at least 8 characters.
3. Choose a **Role** (see below).
4. For a teacher or staff account, choose their **Assigned unit** -- it limits everything they see. For an admin it's optional: leave it blank for the whole institution, or pick a unit to limit them to it.
5. For a cashier, you can link the login to their **Staff** record, so the person who clocks in and the person at the till are the same entry.
6. Press **Add account** and give them the address and password.

### 11.2 Roles

<!-- cols: 22 78 -->
| Role | What they can do |
| --- | --- |
| **Super Admin** | Everything in this guide. |
| **Admin** | People, periods, holidays, attendance, promotion, and the shop module. Sees Accounts but can only change their own password. Tied to a unit, they can also enrol fingerprints on its scanner. |
| **Teacher** or **Staff** | Read-only attendance and roster for their assigned unit. Schools call the role *Teacher*; offices and shops *Staff*. |
| **Cashier** | Shops only: clients, sales, and viewing the catalog. No reports, staff, or settings. |

### 11.3 Managing accounts

- **Edit** (pencil) changes someone's role, assigned unit, or linked staff record. Email addresses can't be changed -- create a new account instead.
- **Change password** (key icon) works on your own account and on any admin, teacher, staff, or cashier account. Another super admin changes their own.
- **Delete** (bin icon) removes the account and its access immediately.

You can't delete your own account, and the dashboard won't delete or demote your institution's last super admin.

## 12. Getting help

Everything in this guide you can do yourself. Contact your platform administrator for:

- A new scanner that needs attaching to your institution
- A scanner showing "REJECTED" or "REVOKED", or one that never leaves "PENDING"
- A scanner that needs reflashing -- for example, WiFi changed and no master finger was enrolled
- A lost or stolen scanner that must be blocked straight away
- Access for your only super admin account

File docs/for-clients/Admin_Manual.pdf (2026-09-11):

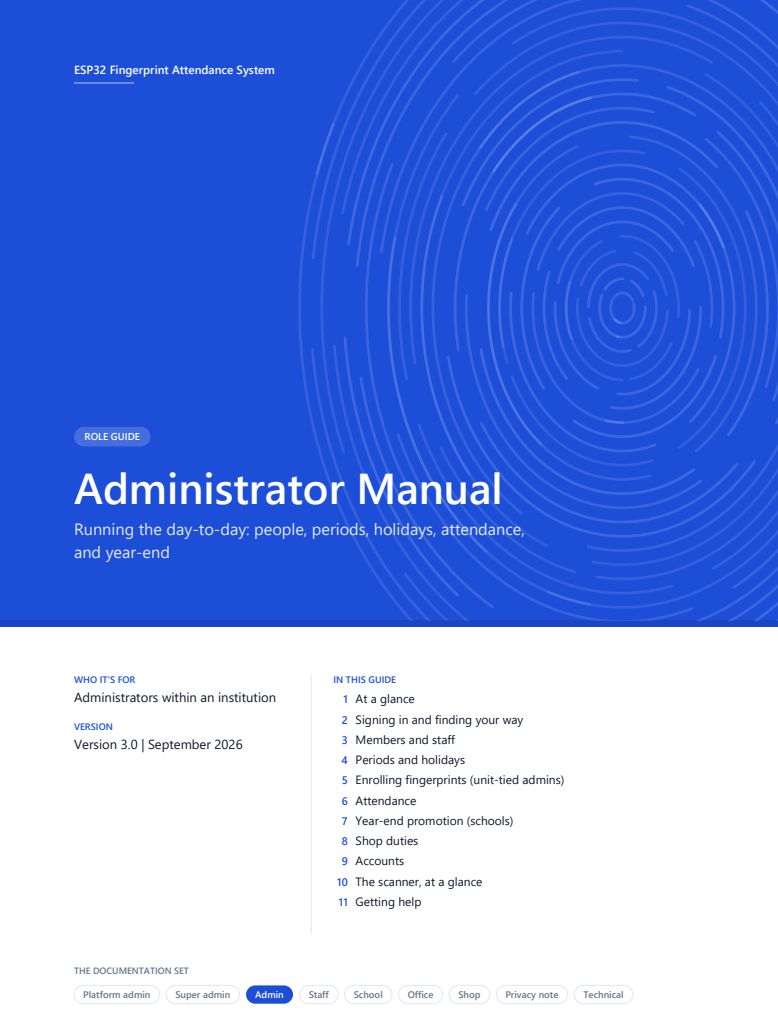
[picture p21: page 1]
Administrator Manual; ROLE GUIDE; VERSION Version 3.0 | September 2026; Platform admin; Super admin; Admin; Staff; School; Office; Shop; Privacy note; Technical

ESP32 Fingerprint Attendance System

Running the day-to-day: people, periods, holidays, attendance,
and year-end

WHO IT’S FOR
Administrators within an institution

IN THIS GUIDE
1 At a glance
2 Signing in and finding your way
3 Members and staff
4 Periods and holidays
5 Enrolling fingerprints (unit-tied admins)
6 Attendance
7 Year-end promotion (schools)
8 Shop duties
9 Accounts
10 The scanner, at a glance
11 Getting help

THE DOCUMENTATION SET

## Contents

## 1 At a glance

As an admin you keep the records right from day to day: you add and update people, set up periods and holidays, check and export attendance, and run the year-end promotion in a school. Device set-up, settings, and accounts belong to your super admin.

You can

Add, edit, import, and deactivate members and staff

Manage periods and holidays (or closed days)

View, filter, and export attendance

Run year-end promotion (schools)

In a shop: clients, sales, catalog, loyalty, reports

See the account list and change your own password

You can’t

Set up, rename, or delete scanners

Change institution settings or labels

Create, edit, or delete accounts

Change anyone else's password

Enrol fingerprints — unless your account is tied to one unit (section 5)

TIP
This guide covers what your role can do. Read it alongside the guide for your kind of organisation — the School, Office, or Shop manual — which explains how the system fits your day.

### 1.1 Two kinds of admin account

Your super admin chose one of these when creating your account:

Administrator Manual

ESP32 Fingerprint Attendance System | Page 1 of 7

Account | What you see and manage
Whole institution | Every unit's people and records. This is the usual kind.
Tied to one unit | Only that unit's people and records — and you can enrol fingerprints on its
scanner. A padlock chip on the Attendance page shows which unit.

### 1.2 Words used in this guide

Your institution may have renamed these under Settings, so your screens might say Student, Form, Class, or Term instead.

Word | Meaning | A school might say
Member | A person whose attendance is recorded | Student
Staff | People on the second roster, if your institution keeps one | Teacher
Group | A set of units | Form, Grade, or Year
Unit | One place people scan — each has its own scanner | Class
Period | A stretch of time you report on | Term
Active | Included in attendance and absence marking | —

## 2 Signing in and finding your way

1 Open the dashboard address your super admin gave you.

2 Enter your email and password, then press Sign in.

The first page is Overview: today's present and absent counts, the attendance rate, and the most recent scans. The menu on the left groups everything else under Records, Shop (shops only), and Manage, and shows only pages your role can open.

On a phone, the menu is a bar along the bottom — Overview, Attendance, your roster, and More. Press Install app in the menu to add the dashboard to your home screen; on an iPhone use Safari's Share icon,

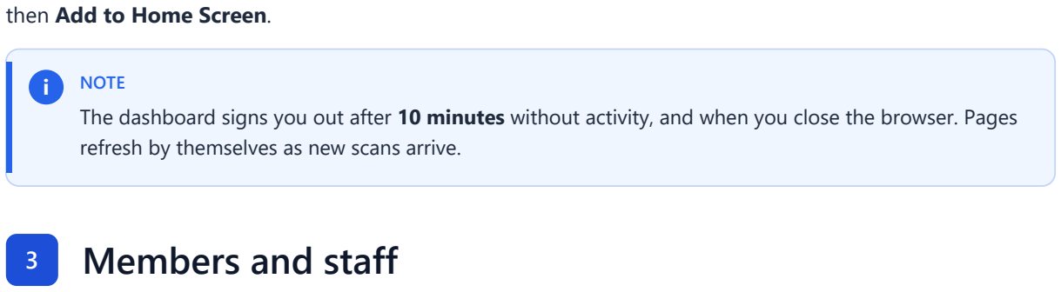
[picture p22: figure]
then Add to Home Screen.; NOTE; 3 Members and staff

The dashboard signs you out after 10 minutes without activity, and when you close the browser. Pages refresh by themselves as new scans arrive.

Go to Members (or Staff for the second roster — both work the same way).

Administrator Manual | At a glance

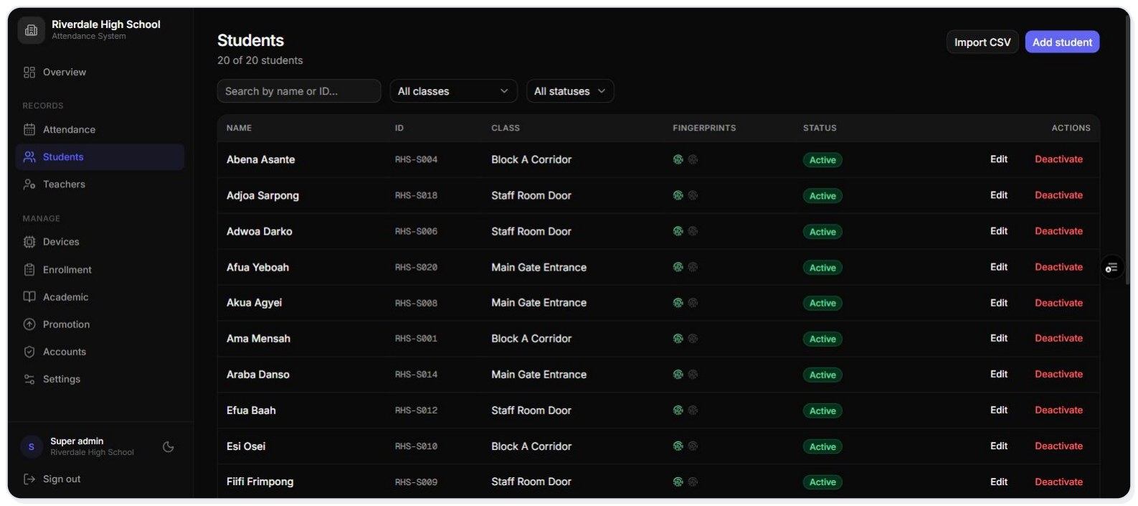
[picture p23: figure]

Figure 1 The Members page, here renamed Students. Screenshots use demo data in dark mode.

### 3.1 Adding one person

1 Press Add member.

2 Enter their Full name and ID — the school or staff number you already use.

3 Choose their Unit. The list shows each scanner as group and unit, e.g. Form 2 Science.

4 Press Add member.

The next screen offers to enrol fingerprints straight away. If your account is tied to their unit you can do it there (section 5); otherwise press Done and ask your super admin to enrol them.

### 3.2 Importing a spreadsheet

1 Press Import CSV, then download the template.

2 | Fill in one row per person with the columns | sid | (ID), | fullname | , and the unit.

3 Write the unit the way the dashboard shows it, e.g. Form 2 Science. The unit name alone also works
| when it's unique.

4 Upload the file. A preview marks each row as ready or explains the problem — a missing field, or a unit
| it can't find — before anything is saved.

5 Confirm.

i

NOTE
Imported people start Inactive, because they have no fingerprints yet. Activate each person once they're enrolled — only active people are counted in attendance and absence marking.

### 3.3 Editing someone

Press the edit icon on their row to change the name, ID, or unit. The Fingerprints panel shows which sensor slots hold their fingers.

Administrator Manual | Members and staff

### 3.4 Leavers

Press Deactivate on their row. They stop being marked absent from that day, and their full history stays available in reports and exports. Press Activate to bring them back.

There is no delete button for people — deactivating keeps the history, which you'll want for reports.

## 4 Periods and holidays

The page is called Academic in a school, Periods & Holidays in an office, and Closed Days in a shop (holidays only).

### 4.1 Periods

1 Press Add term (the button uses your institution's word for a period).

2 Enter the Term name, the Year — e.g. 2026 or 2025/2026 — and the start and end dates.

3 Save, then press Set active on its row.

Keep exactly one period active. Each scan is filed under whichever period was active at the time, and reports default to it.

### 4.2 Holidays

1 Open the Holidays tab and press Add holiday.

2 Enter a Label and a Start date. Add an End date for a break of several days.

3 Tick Repeats every year for fixed dates such as Independence Day. Leave it unticked for dates that move, such as Easter.

4 Save.

Nobody is marked absent on a holiday. Weekends don't need adding — your super admin sets which weekdays count under Days tracked in Settings.

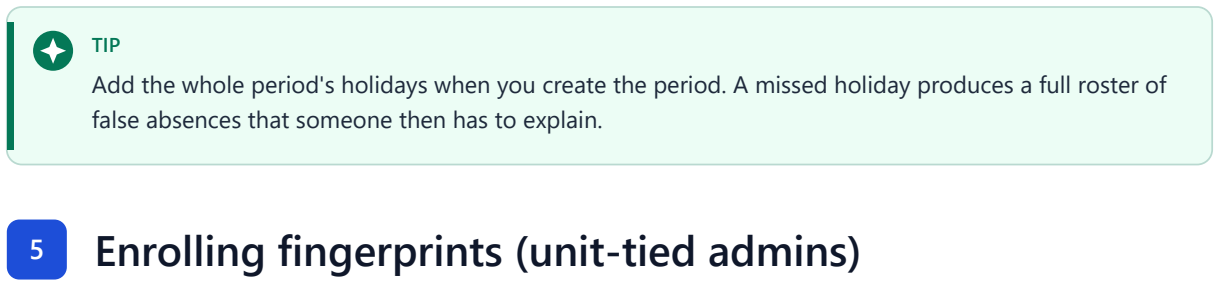
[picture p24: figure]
TIP

Add the whole period's holidays when you create the period. A missed holiday produces a full roster of false absences that someone then has to explain.

## 5 Enrolling fingerprints (unit-tied admins)

If your account is tied to one unit, Enrollment appears in your menu and you can register or delete fingerprints on that unit's scanner. Otherwise your super admin does this.

1 Press New job.

2 Choose Register, the person, and Finger 1 or Finger 2. The sensor slot is filled in for you.

3 Queue the job, then have the person at the scanner.

Administrator Manual | Members and staff

4 | They press the finger when the screen says | PRESS 1/2 | , lift it at | REMOVE | , and press the same finger
again at | PRESS 2/2 | .
5 | ENROLLED | on the screen and Completed on the dashboard mean it worked.

You can also do this from the person's edit screen: the Fingerprints panel has an enrol button for an empty finger and Delete for a stored one. The Super Administrator Manual covers failed and stuck jobs in detail.

## 6 Attendance

Go to Attendance.

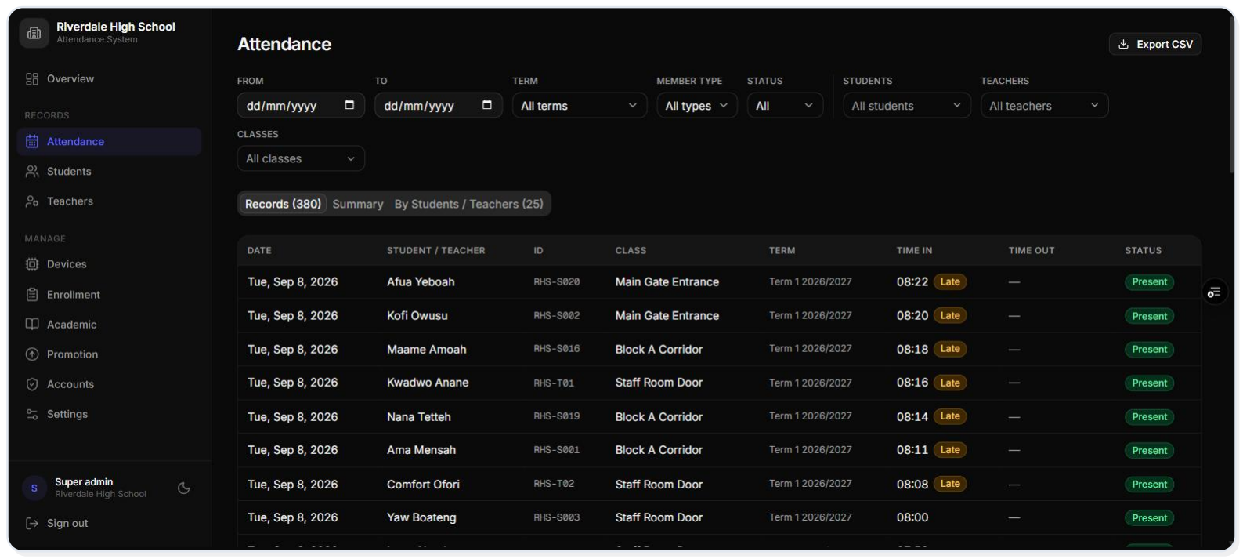
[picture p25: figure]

Figure 2 The Attendance page with its filters and tabs.

Tab | What it shows
Records | One row per person per day: date, name, ID, unit, period, time or time in / time out, and status.
Summary | Present and absent totals, and the attendance percentage, per unit and period.
By member | Each person's days present and absent, their rate, and when they were last seen.

Narrow the list with From / To, Period, Member type, Status, and the people and unit pickers. If your institution flags punctuality, late arrivals carry a Late badge and early departures an Early badge.

To export, set your filters and press Export CSV. The file opens in Excel or Google Sheets and contains exactly what the filters show.

i

NOTE
Nobody marks absences by hand. Each evening the system adds an Absent record for every active person who didn't scan, skipping holidays and untracked weekdays. Scans saved by an offline scanner upload later and correct those records.
Administrator Manual | Enrolling fingerprints (unit-tied admins)

## 7 Year-end promotion (schools)

Promotion moves every active student up one group — Form 1 to Form 2, and so on. Students in the final group are deactivated instead.

1 Go to Promotion and read the preview: each card shows how many students move from one group to the next.

2 Check the warning list. A student is skipped if there's no scanner for their next group with the same unit name — ask your super admin to set it up first.

3 Press Apply promotion, read the summary, and press Confirm.

!

IMPORTANT
Promotion can't be undone. Export the year's attendance first. Promoted students' fingerprint links are cleared, so each one must be enrolled again on their new class's scanner before they can scan.

The School Manual explains how the dashboard works out the order of groups.

## 8 Shop duties

In a shop your menu also has Clients, Sales, Catalog, Loyalty, and Reports. The Shop Manual covers them in full:

- Clients — your customers, keyed by a unique phone number, with visit history and loyalty progress
- Sales — record what was sold, to whom, and by which staff member
- Catalog — products and services, with prices and product stock
- Loyalty — reward rules, and issuing rewards to clients who have earned them
- Reports — takings, top clients, revenue per staff member, best sellers, visits, low stock, and rewards

## 9 Accounts

Accounts lists everyone who can sign in to your institution's dashboard. Search by email or filter by role.

To change your own password, press the key icon on your row and enter a new one of at least 8 characters. Everything else on this page — new accounts, role changes, other people's passwords — is done by your super admin.

Administrator Manual | Attendance

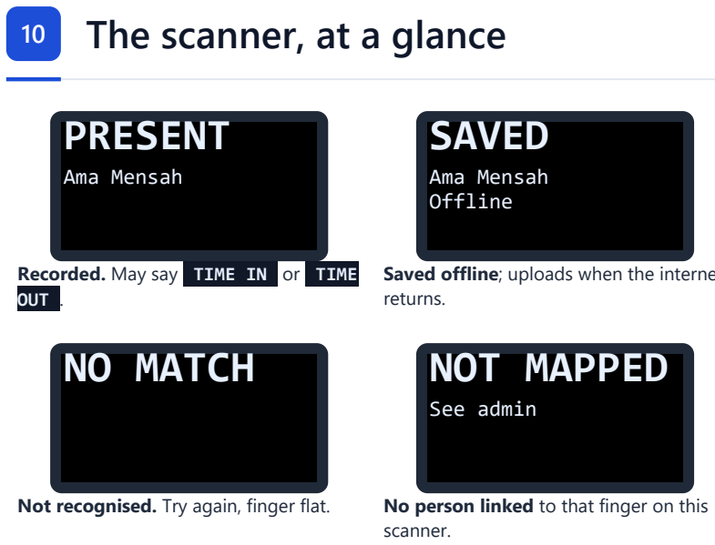
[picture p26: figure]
10 The scanner, at a glance; PRESENT; Ama Mensah; Recorded. May say; TIME IN; TIME; OUT; SAVED; Ama Mensah Offline; returns.; NO MATCH; Not recognised. Try again, finger flat.; See admin; No person linked to that finger on this scanner.

Saved offline; uploads when the internet

# NOT LOGGED

Ama Mensah

Not counted — holiday, untracked day, or duplicate.

# NOT MAPPED

08:14

Form 2 Science
Offline
3 queued

No internet. 3 scans waiting to upload.

Light | Meaning
Solid blue | Ready and online
Solid purple | Ready, but no WiFi
Green flash | Scan accepted
Red flash | Not recognised
Solid yellow | Waiting for a finger during enrollment
Breathing yellow | Waiting to be set up
Breathing red | Installing an update — do not unplug

## 11 Getting help

Problem | Who to ask
Someone needs fingerprints enrolled | Your super admin (or you, if tied to their unit)
A scanner isn't working or shows an odd screen | Your super admin
A new account, a role change, or someone else's password | Your super admin
A setting or label needs changing | Your super admin
A whole day shows everyone absent | Check holidays first, then ask your super admin to check the scanner
Administrator Manual | Accounts

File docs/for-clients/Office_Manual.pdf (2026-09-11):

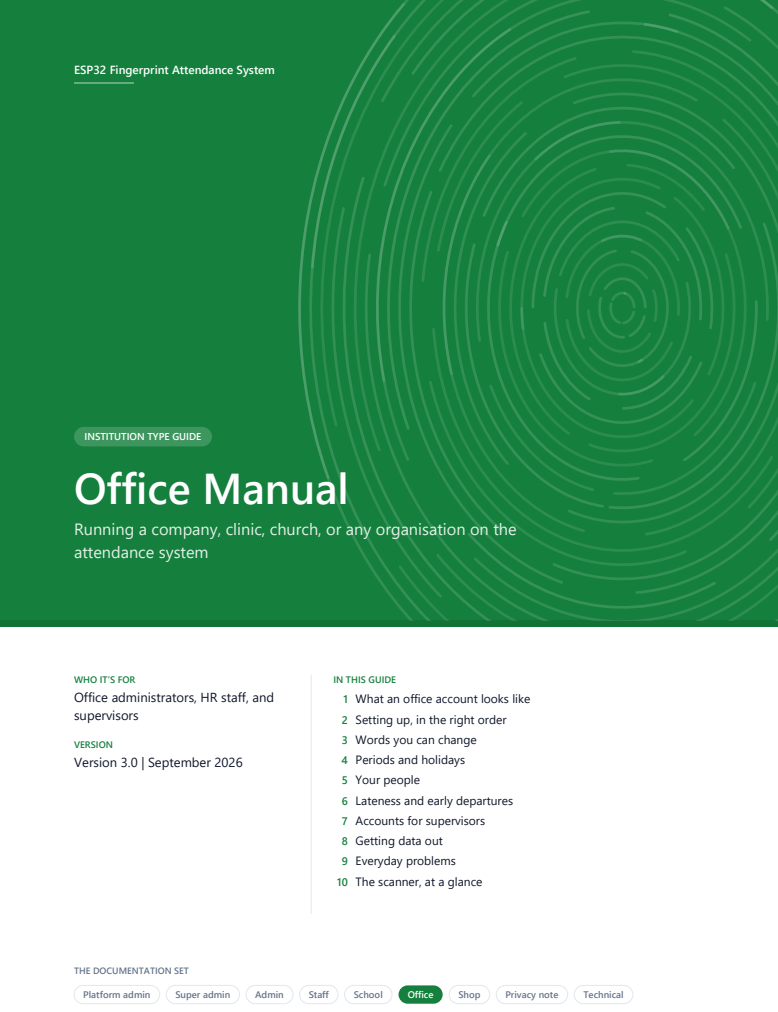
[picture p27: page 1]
VERSION Version 3.0 | September 2026; Platform admin; Super admin; Admin; Staff; School; Office; Shop; Privacy note; Technical

ESP32 Fingerprint Attendance System

INSTITUTION TYPE GUIDE
Office Manual

Running a company, clinic, church, or any organisation on the
attendance system

WHO IT’S FOR
Office administrators, HR staff, and
supervisors

IN THIS GUIDE
1 What an office account looks like
2 Setting up, in the right order
3 Words you can change
4 Periods and holidays
5 Your people
6 Lateness and early departures
7 Accounts for supervisors
8 Getting data out
9 Everyday problems
10 The scanner, at a glance

THE DOCUMENTATION SET

## Contents

## 1 What an office account looks like

An office account records the people who work for you by fingerprint. It's the general-purpose type — for a company, clinic, NGO, church, factory, or any organisation that needs a reliable record of who was in, and when.

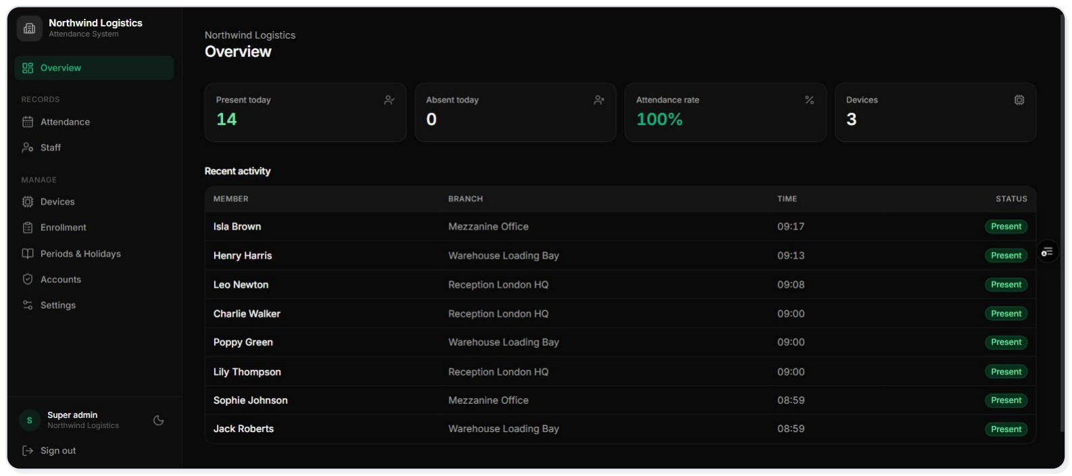
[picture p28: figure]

Figure 1 The Overview page of a demo office. Screenshots use demo data in dark mode.

Your menu has:

- Overview — present and absent today, the attendance rate, and the latest scans
- Attendance — every record, with filters, totals, and export
- Staff and / or Members — your people

Office Manual

ESP32 Fingerprint Attendance System | Page 1 of 7

- Devices and Enrollment — the scanners and the fingerprints on them
- Periods & Holidays — reporting periods and non-working days
- Accounts and Settings

There are no academic terms and no year-end promotion — those are school-only.

### 1.1 Two ways to record a day

Set under Settings → Scan mode. It's the most important choice you'll make.

Mode | How it works | Choose it when
Present / Absent | One scan marks the person present for the day. | You only need to know who came in.
Time In / Time Out | The first scan is arrival, the second is departure. Both appear on one row. | You need hours, lateness, or early departures.

You can set a different mode for each roster — members and staff.

TIP
Start with Present / Absent unless you have a concrete reason to track hours. It's quicker at the door, and you can switch later.

## 2 Setting up, in the right order

### 1 Settings — name, logo, timezone, scan mode, and Days tracked (leave Saturday and Sunday

unselected if you're a Monday-to-Friday operation).

2 Periods & Holidays — create your current reporting period, press Set active, and add public holidays.

3 Devices — give each scanner its department and location, e.g. Operations and Warehouse.

4 Staff — add your people, or import them from a spreadsheet.

5 Enrollment — enrol each person's fingerprints, then activate them.

6 Accounts — create logins for HR, department heads, and supervisors.

!

IMPORTANT
Choose your scan mode before you enrol anyone. Switching mid-period leaves two different shapes of record in the same report.

## 3 Words you can change

The defaults are Member, Group, Unit, and Period. Rename them under Settings → Custom labels:

Office Manual | What an office account looks like

Default | An office usually says
Member / Members | Employee / Employees
Group | Department or Division
Unit | Team, Branch, or Site
Period | Quarter, Month, or Year

The new words appear everywhere, including CSV headings. Nothing about the data changes.

### 3.1 One roster or two

Two rosters are available, each switched on under Settings:

- Most offices use one roster for everybody — turn on Track staff only. The Members page then disappears.
- Use both for two genuinely different groups — say, a clinic's employees on one roster and volunteers on the other, each with its own scan mode.

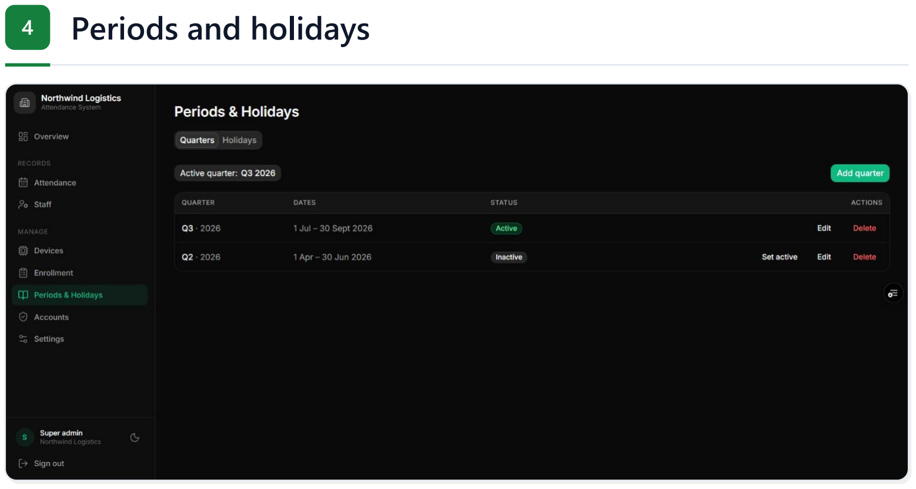
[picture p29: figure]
4 Periods and holidays

Figure 2 Periods & Holidays in a demo office, with the period renamed Quarter.

### 4.1 Periods

A period is simply a reporting bucket — a quarter, a month, or a year, whatever matches how you report. Press Add on the first tab, enter a name, year, and dates, save, then press Set active on its row. Keep exactly one active; each scan is filed under it.

### 4.2 Holidays

On the Holidays tab, add every non-working day: public holidays, company shutdowns, stocktaking days. Nobody is marked absent on them. Tick Repeats every year for fixed dates; leave it unticked for dates that move.

Office Manual | Words you can change

Days tracked in Settings handles weekends for you — leave the days you're closed unselected instead of adding them as holidays.

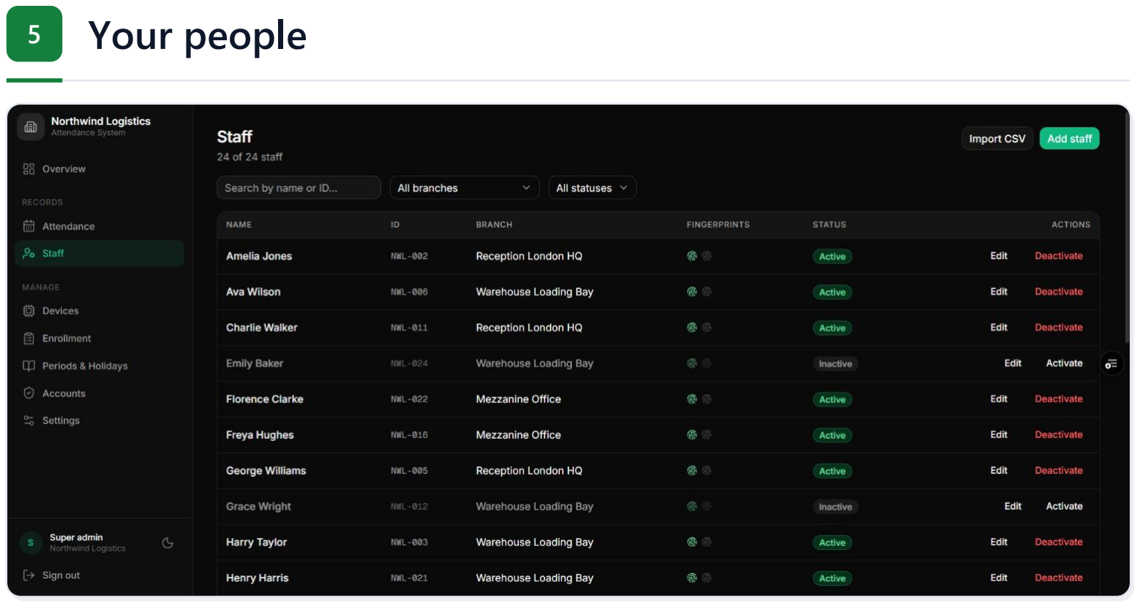
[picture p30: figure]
5 Your people

Figure 3 A demo office's Staff page.

### 5.1 Adding one person

Go to Staff and press Add. Enter the full name and ID, and choose their unit — listed as department and location. The dashboard then offers to enrol their fingerprints straight away.

### 5.2 Importing a spreadsheet

1 Press Import CSV and download the template.

2 | Fill in one row per person: | sid | (staff number), | fullname | , and the unit as the dashboard shows it.

3 Upload and review the preview, which flags any row it can't use before anything is saved.

4 Confirm.

Imported people start Inactive because they have no fingerprints yet. Enrol each one, then press Activate.

### 5.3 Leavers

Press Deactivate on their row on their last day. Their history is kept and they stop being marked absent. People are never deleted.

i

NOTE
If you forget to deactivate a leaver, they collect an absence every working day, which distorts your reports until someone notices.
Office Manual | Periods and holidays

## 6 Lateness and early departures

Under Settings, two optional switches turn the attendance record into a punctuality record:

Setting | What it does
Flag late arrivals | Set an Expected start time and a Grace period in minutes. Anyone whose first scan is after start plus grace gets a Late badge.
Flag early departures | Set an Expected end time and a Grace period. A time-out scan before end minus grace gets an Early badge. Only works in Time In / Time Out mode.

For example, with a start of 08:00 and 10 minutes' grace, a scan at 08:09 is on time and 08:11 is late.

## 7 Accounts for supervisors

Give department heads and shift supervisors a Staff account assigned to their unit. They can see and export their own team's attendance and nothing else, and can't change anything.

For a supervisor who should also manage their team's records — adding people, enrolling fingerprints on their scanner — create an Admin account assigned to that unit instead. Leave the unit blank for an HR admin who covers everyone.

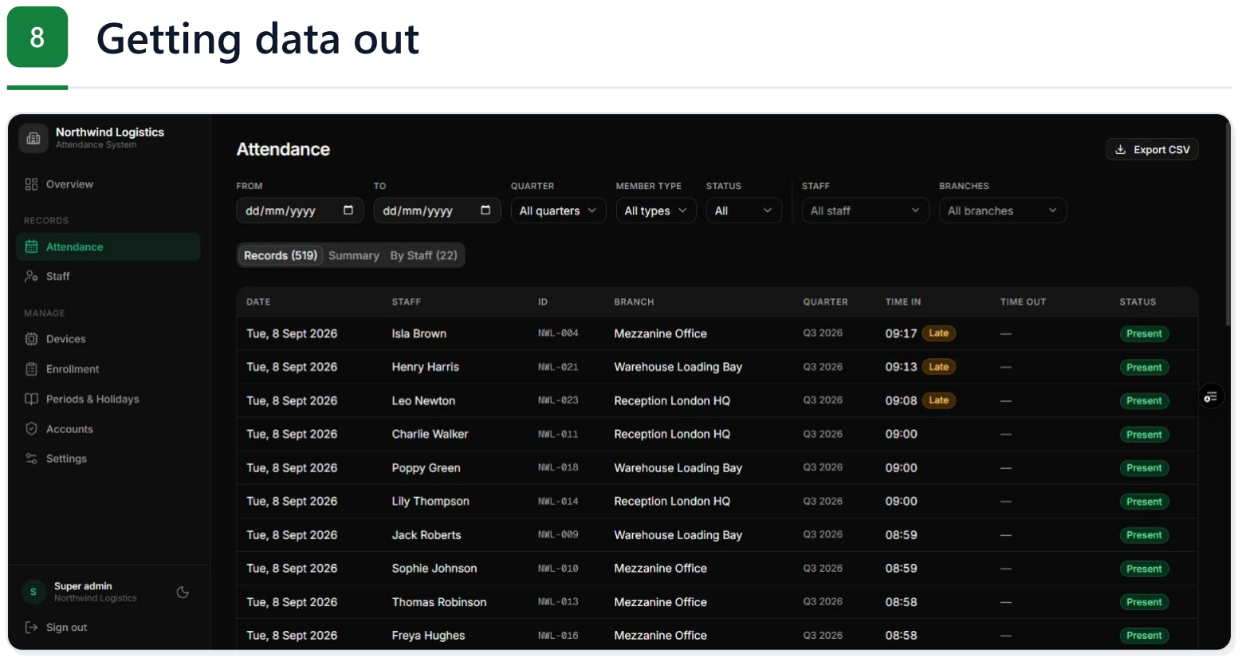
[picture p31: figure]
8 Getting data out

Figure 4 The Attendance page: filters across the top, then the Records, Summary, and By member tabs.

Go to Attendance, set the filters — dates, period, member type, status, people, units — and press Export CSV. The file opens in Excel or Google Sheets.

This is how attendance feeds payroll: filter to the pay period and the department, export, and hand the file over. In Time In / Time Out mode both times are on the same row, so hours are a simple subtraction in the

Office Manual | Your people

spreadsheet.

Summary gives each unit's present and absent totals and attendance percentage per period; By member gives each person's totals and last scan.

## 9 Everyday problems

Problem | What to do
Everyone is absent on a working day | A holiday was entered by mistake, or the scanner was off all day. Check
| both.
Everyone is absent on a weekend | Saturday or Sunday is still selected under Days tracked. Unselect it.
Someone was at work but shows absent | They didn't scan, or the scan failed — | NO MATCH | on the screen means
| it didn't count.
A time out but no time in | Their first scan of the day didn't register.
The scanner says | NOT LOGGED | Accepted but not counted: a holiday, an untracked day, or already
| recorded.
A leaver still shows absences | They were never deactivated.
A supervisor sees nothing | Their account has no unit, or the wrong one.
An import rejects rows | A field is missing, or a unit doesn't match your scanners.

## 10 The scanner, at a glance

# TIME IN

Kwame Boateng

Arrival recorded. | TIME OUT | at the
end of the day.

# SAVED

Kwame Boateng
Offline

Saved offline; uploads when the internet returns.

# NOT LOGGED

Kwame Boateng

Not counted — holiday, untracked day, or duplicate.

# COOLDOWN

Kwame Boateng

Scanned twice in a minute. The second scan is ignored.

# NO MATCH

Not recognised. Try again, finger flat.

# PENDING

24:6F:28:A1:B2:C3

Not set up yet — see your super admin.

Office Manual | Getting data out

Light | Meaning
Green flash | Scan accepted
Red flash | Not recognised
Solid yellow | Waiting for a finger during enrollment
Breathing yellow | Waiting to be set up
Breathing red | Installing an update — do not unplug

TIP
COOLDOWN protects Time In / Time Out mode: a nervous double-scan at the door can't accidentally clock someone out a second after they clocked in.
Office Manual | The scanner, at a glance

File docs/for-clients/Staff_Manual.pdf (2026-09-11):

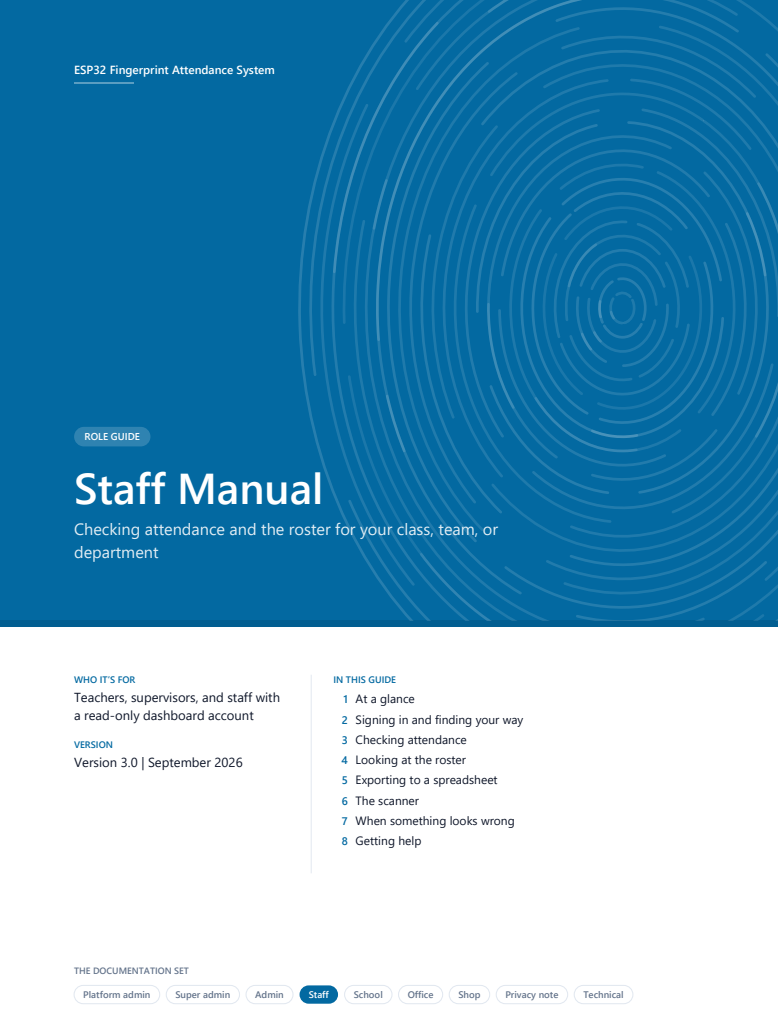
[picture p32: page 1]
Staff Manual; ROLE GUIDE; VERSION Version 3.0 | September 2026; Platform admin; Super admin; Admin; Staff; School; Office; Shop; Privacy note; Technical

ESP32 Fingerprint Attendance System

Checking attendance and the roster for your class, team, or
department

WHO IT’S FOR
Teachers, supervisors, and staff with
a read-only dashboard account

IN THIS GUIDE
1 At a glance
2 Signing in and finding your way
3 Checking attendance
4 Looking at the roster
5 Exporting to a spreadsheet
6 The scanner
7 When something looks wrong
8 Getting help

THE DOCUMENTATION SET

## Contents

## 1 At a glance

Your account lets you see attendance and the roster for one unit — your class, team, section, or department. It cannot change anything, so you can explore freely without breaking anything.

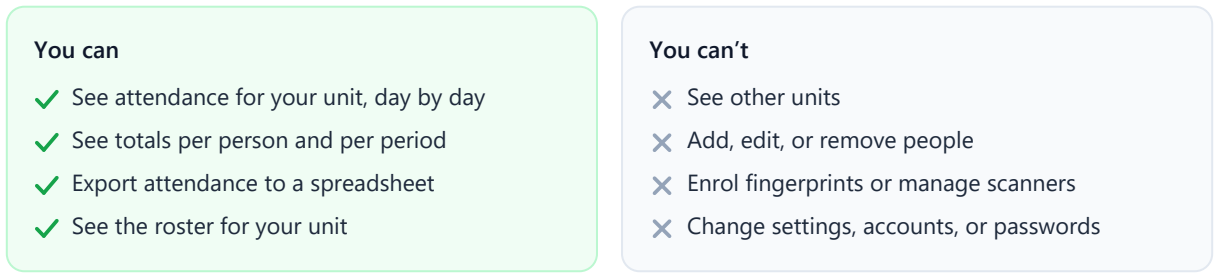
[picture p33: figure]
You can; See totals per person and per period; Export attendance to a spreadsheet; See the roster for your unit; You can’t; See other units; Add, edit, or remove people; Enrol fingerprints or manage scanners; Change settings, accounts, or passwords

See attendance for your unit, day by day

Your admin and super admin set up your account and can do everything in the right-hand list. Section 8 says who to ask for what.

### 1.1 Words used in this guide

Each institution can rename the dashboard's main words, so your screens may say Students or Class where this guide says Member or Unit. The meaning is the same.

Word | Meaning | A school might say
Member | A person whose attendance is recorded | Student
Unit | One place people scan — each unit has its own scanner | Class
Group | A set of units | Form, Grade, or Year
Period | A stretch of time you report on | Term
Scan | Placing a finger on the scanner | —

Staff Manual

ESP32 Fingerprint Attendance System | Page 1 of 6

## 2 Signing in and finding your way

1 Open the dashboard address your admin gave you.

2 Enter your email and password.

3 Press Sign in.

There is no sign-up page and no "forgot password" link. If you can't sign in, ask your super admin to reset your password.

### 2.1 What you'll see

The menu shows only the pages your account can open:

- Overview — today at a glance: how many are present and absent, the attendance rate, and the latest scans
- Attendance — every record for your unit, with filters, totals, and export
- Members — the roster for your unit (your institution may call this page Students, Employees, or similar)

Pages update themselves within a few seconds when new scans arrive, so there's no need to reload.

### 2.2 On a phone

On a phone the menu becomes a bar along the bottom of the screen: Overview, Attendance, your roster, and More.

To keep the dashboard on your home screen like an app, press Install app at the bottom of the menu. On an iPhone, open the dashboard in Safari, tap the Share icon, then choose Add to Home Screen.

i

NOTE
For security, the dashboard signs you out after 10 minutes without activity, and whenever you close the browser. Just sign in again.

The moon icon next to your name switches between light and dark mode.

## 3 Checking attendance

Press Attendance. A small padlock chip in the filter bar shows the unit your account is locked to.

Staff Manual | At a glance

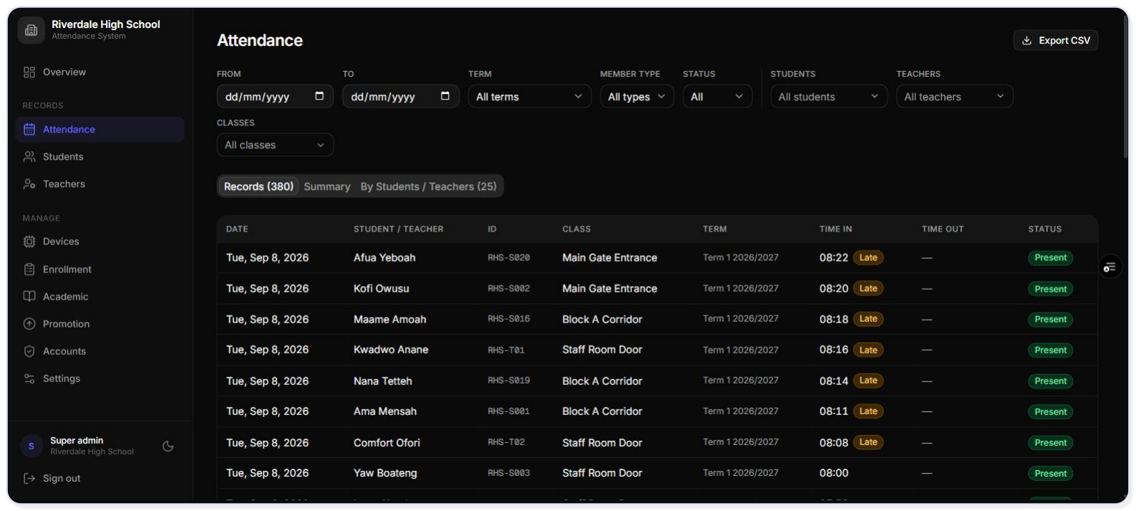
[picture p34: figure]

Figure 1 The Attendance page. Screenshots in this guide use demo data in dark mode — your names, colours, and menu will differ.

The page has three tabs:

Tab | What it shows
Records | One row per person per day: date, name, ID, unit, period, time, and status. Where your institution records arrival and departure, both times share one row.
Summary | Present and absent totals, and the attendance percentage, for each unit and period.
By member | One row per person: days present, days absent, attendance rate, and when they were last seen.

### 3.1 Narrowing the list

The filters above the tabs apply to all three:

Filter | Use it to
From and To | Show one stretch of dates.
Period | Show one term or reporting period.
Member type | Show members or staff only, where your institution tracks both.
Status | Show only Present or only Absent records.
Members | Pick one or more people by name.
Staff Manual | Checking attendance

### 3.2 Reading a record

You see | It means
Present | They scanned that day.
Absent | They didn't scan on a day that counts. Added automatically each evening.
Time In and Time Out | Their first and second scans of the day, where your institution records arrival and departure.
Late badge | They arrived after the expected start time plus the grace period.
Early badge | They left before the expected end time minus the grace period.

i

NOTE
Nobody marks absences by hand. Each evening the system adds an Absent record for every active person who didn't scan, skipping holidays and days your institution doesn't track. If a scanner was offline, its saved scans upload later and correct those records.

## 4 Looking at the roster

Press Members to see everyone assigned to your unit, with their name, ID, and whether they are Active or Inactive. Search by name or ID, and use the status filter to include inactive people.

You can't edit the roster. If a name or ID is wrong, or someone is missing, tell your admin.

## 5 Exporting to a spreadsheet

1 Go to Attendance.

2 Set the filters you want — for example From and To for this month.

3 Press Export CSV.

4 Open the downloaded file in Excel or Google Sheets.

The file follows your filters and only ever contains your unit.

## 6 The scanner

Each unit has a fingerprint scanner with a small screen and a coloured light around the sensor. You don't manage it, but knowing what it shows helps you answer "did my scan work?" on the spot.

Staff Manual | Checking attendance

08:14

Form 2 Science
Online

Ready. The clock, the device's name, and its connection.

# SCANNED

Ama Mensah

Checking with the server — about a second.

# PRESENT

Ama Mensah

Recorded. May also say | TIME IN | or
TIME OUT | .

# SAVED

Ama Mensah
Offline

Saved offline. It uploads by itself when the internet returns.

# NOT LOGGED

Ama Mensah

Not counted, e.g. a holiday, an untracked day, or already recorded today.

# COOLDOWN

Ama Mensah

Scanned twice within a minute. Nothing to do.

# NO MATCH

Not recognised. Try again with the finger flat and still.

# NOT MAPPED

See admin

Known finger, no person linked on this device. Tell your admin.

# OTA UPDATE

Do not unplug

Updating. Leave it powered on; it restarts by itself.

Light | Meaning
Solid blue | Ready and online
Solid purple | Ready, but no WiFi — scans are saved and upload later
Green flash | Scan accepted
Red flash | Not recognised
Breathing yellow | Waiting to be set up by an administrator
Breathing red | Installing an update — do not unplug

TIP
A scanner that has lost its internet connection keeps working. It stores every scan and uploads them when the connection returns, so an outage never costs anyone a day's attendance.
Staff Manual | The scanner

## 7 When something looks wrong

Problem | What to do
Someone is marked absent but was there | Ask what the screen said when they scanned. | NO MATCH | means the
scan didn't count. Tell your admin — you can't edit records.
Everyone is absent on one day | The day may be missing from the holiday list, or the scanner was off all
| day. Tell your admin.
A person is missing from the roster | They haven't been added yet, or they're assigned to another unit.
You see no records at all | Your account may not be linked to a unit. Ask your super admin to check
| it.
You were signed out | Normal after 10 minutes without activity. Sign in again.

## 8 Getting help

You need | Ask
A new password | Your super admin
A name, ID, or roster change | Your admin
A scanner looked at | Your admin — say what the screen and light show
Access to a different unit | Your super admin
Staff Manual | The scanner

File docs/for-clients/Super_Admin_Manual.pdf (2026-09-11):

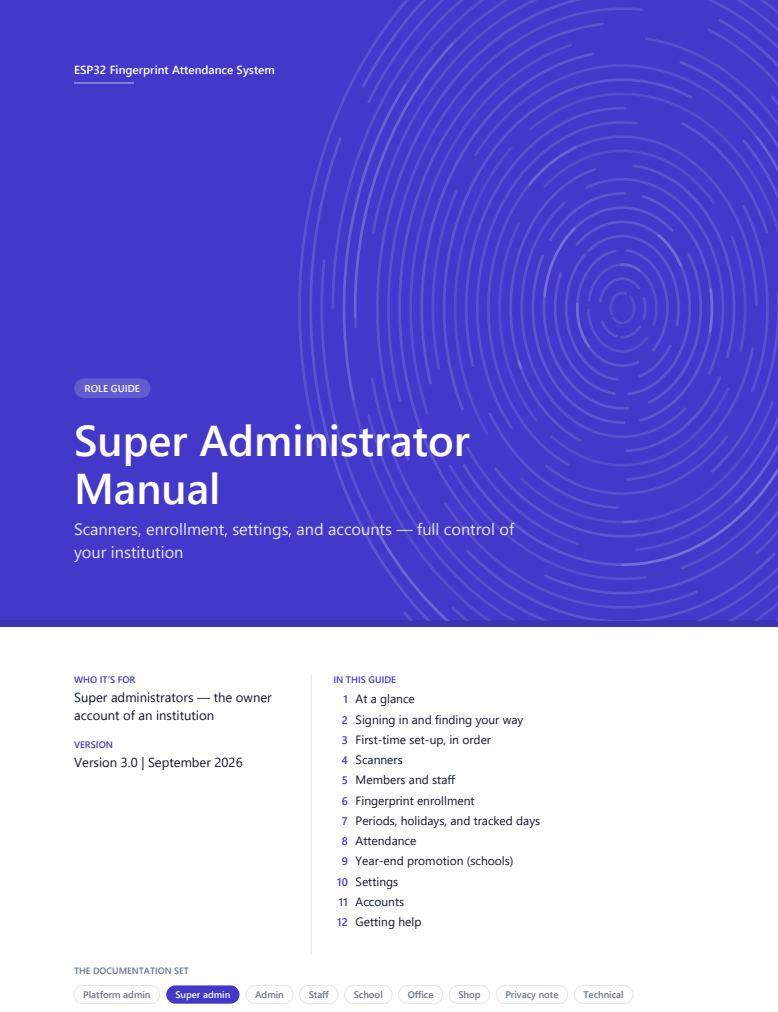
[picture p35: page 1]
Super Administrator Manual; ROLE GUIDE; VERSION Version 3.0 | September 2026; Platform admin; Super admin; Admin; Staff; School; Office; Shop; Privacy note; Technical

ESP32 Fingerprint Attendance System

Scanners, enrollment, settings, and accounts — full control of
your institution

WHO IT’S FOR
Super administrators — the owner
account of an institution

IN THIS GUIDE
1 At a glance
2 Signing in and finding your way
3 First-time set-up, in order
4 Scanners
5 Members and staff
6 Fingerprint enrollment
7 Periods, holidays, and tracked days
8 Attendance
9 Year-end promotion (schools)
10 Settings
11 Accounts
12 Getting help

THE DOCUMENTATION SET

## Contents

Super Administrator Manual

ESP32 Fingerprint Attendance System | Page 1 of 13

## 1 At a glance

As super admin you own your institution's set-up: its scanners, its fingerprints, its settings, and who can sign in. Everything an admin can do, you can do too.

You can

Set up, rename, and delete scanners

Enrol and delete fingerprints, including master fingers

Add, import, edit, and deactivate people

Manage periods, holidays, and tracked weekdays

View and export all attendance

Change settings, labels, branding, and modules

Create, edit, and delete accounts — including other super admins

Only your platform administrator can

Add a brand-new scanner to your institution

Reflash a scanner, or update its firmware

Block a lost or stolen scanner instantly

Restore access if every super admin is locked out

Create or remove whole institutions

TIP
This guide covers what your role can do. Read it alongside the guide for your kind of organisation — the School, Office, or Shop manual.

### 1.1 Words used in this guide

You can rename most of these under Settings → Custom labels (section 10). This guide uses the defaults.

Word | Meaning | A school might say
Member | A person whose attendance is recorded | Student
Staff | People on the second roster, if you keep one | Teacher
Group | A set of units | Form, Grade, or Year
Unit | One place people scan — one scanner per unit | Class
Period | A stretch of time you report on | Term
Enrollment | Saving someone's fingerprint on a scanner | —
Master finger | An admin's finger that reopens a scanner's WiFi setup | —

## 2 Signing in and finding your way

Open the dashboard address, enter your email and password, and press Sign in. There is no self-service password reset: another super admin can reset yours from Accounts, or your platform administrator can if you're the only one.

Super Administrator Manual | Contents

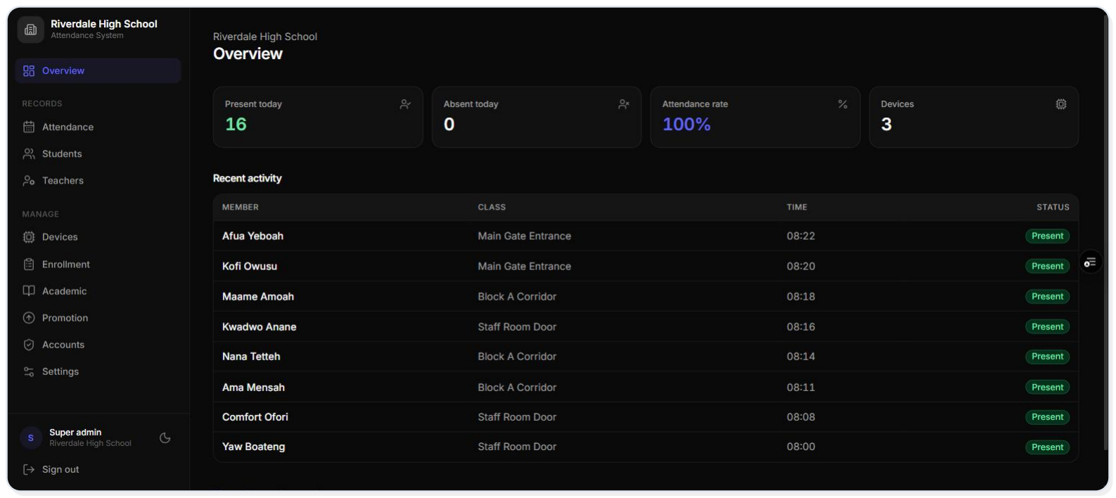
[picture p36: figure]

Figure 1 The Overview page — today's counts and the latest scans. Screenshots use demo data in dark mode.

The menu groups pages under Records, Shop (shops only), and Manage:

Page | What it's for
Overview | Today's present and absent counts, attendance rate, and the latest scans. Shops see takings, visits, and stock warnings.
Attendance | Every attendance record, with filters, totals, and CSV export.
Members and Staff | Your rosters.
Clients, Sales, Catalog, Loyalty, Reports | The retail module — shops only.
Devices | Your scanners.
Enrollment | Fingerprint jobs sent to scanners.
Academic | Periods and holidays. Called Periods & Holidays in an office and Closed Days in a shop.
Promotion | Year-end promotion — schools only.
Accounts | Who can sign in, and with which role.
Settings | Names, labels, branding, attendance rules, and modules.

On a phone, the menu becomes a bottom bar with More for everything else. Install app in the menu adds the dashboard to a home screen (on an iPhone: Safari's Share icon, then Add to Home Screen). For security, the dashboard signs you out after 10 minutes without activity and when the browser closes.

## 3 First-time set-up, in order

Work through these once. Later steps depend on earlier ones.

Super Administrator Manual | Signing in and finding your way

1 Settings — name, logo, timezone, labels, what you track, and the days you track (section 10).

2 Periods and holidays — create the current period, press Set active, and add its holidays (section 7).

3 Scanners — give each new scanner its group and unit (section 4.1).

4 WiFi — connect each scanner to your network on site (section 4.4).

5 Master finger — enrol one on every scanner before anything else goes wrong (section 4.5).

6 People — add them one by one or import a spreadsheet (section 5).

7 Fingerprints — enrol everyone, then activate them (section 6).

8 Accounts — create logins for your admins, teachers or supervisors, and cashiers (section 11).

## 4 Scanners

### 4.1 How a new scanner joins

A new scanner can't join your institution by itself — your platform administrator attaches it first. The whole journey looks like this:

1 | The scanner is powered on for the first time. Its screen shows | PENDING | with its hardware address, and
| the light breathes yellow.

2 Your platform administrator assigns it to your institution. The light turns solid blue.

3 It appears on your Devices page under Pending setup, marked Not configured.

4 Press Configure and enter its Group and Unit — e.g. Form 2 and Science. The preview shows how it will
| be named.

5 Press Save changes. The scanner shows its new name on screen within a minute, and you can now add
| people to that unit.

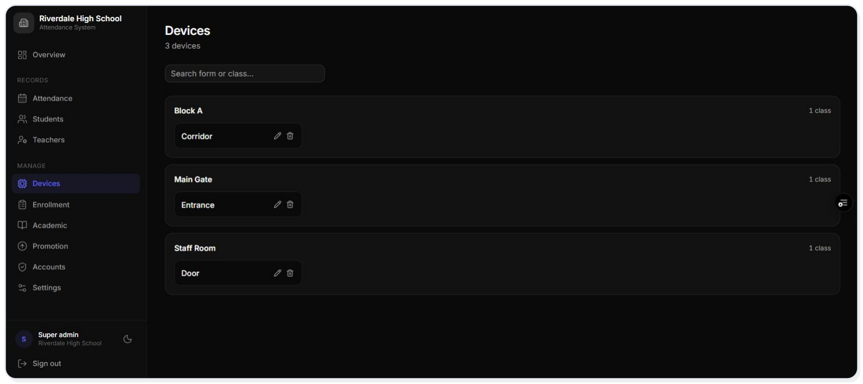
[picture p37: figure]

Figure 2 The Devices page: scanners grouped by group, each with edit and delete icons.

Super Administrator Manual | First-time set-up, in order

TIP
Name groups so they sort in order — Form 1, Form 2, Form 3 — and reuse the same unit names in every group, e.g. Science and Arts. Year-end promotion relies on both (section 9).

### 4.2 Renaming a scanner

Press the pencil icon on its tile, change the group or unit, and press Save changes. The name on the scanner's screen follows automatically.

### 4.3 Deleting a scanner

Press the bin icon on its tile and confirm with Delete device.

!

IMPORTANT
Everyone assigned to that scanner loses their unit and can't scan until you give them a new one. The physical scanner wipes its identity on its next connection and starts again as a new, unassigned device. Attendance history is kept. Only delete a scanner you are retiring or rebuilding.

### 4.4 First-time WiFi setup

A factory-fresh scanner has no WiFi saved, so it opens its own setup network the first time it boots.

1 | Power on the scanner. The screen shows | SETUP | and the light blinks purple.

2 On a phone or laptop, join the WiFi network Attendance-Setup with the password setup1234.

3 | If a setup page doesn't open by itself, browse to | http://192.168.4.1 | .

4 Enter your WiFi name and password and press Save & Connect. The scanner saves them and restarts.

5 Reconnect your phone to your normal WiFi.

The setup network only opens by itself on that very first boot. After that, only a master finger can reopen it. Keep the setup password within your admin team.

### 4.5 Enrolling a master finger — do this on day one

A master finger is an admin's finger that reopens WiFi setup later — when you move a scanner or change your WiFi password. It never records attendance.

1 Go to Enrollment and press New job.

2 Choose the command Reg. master.

3 Choose the scanner, and type a Name for whose finger it is, e.g. Principal.

4 Queue the job. At the scanner, press the finger when asked, lift it, and press it again.

!

IMPORTANT
Enrol a master finger on every scanner while it still has a working connection. Without one, a WiFi change means the scanner has to go back to your platform administrator to be reflashed.
Super Administrator Manual | Scanners

### 4.6 Changing the WiFi later

1 | At the scanner, scan the master finger. The screen shows | CONFIRM? | .
2 | Scan the same finger again within 8 seconds. The screen shows | CONFIRMED | and the light flashes yellow
five times. A different finger, or waiting too long, cancels safely.

3 The Attendance-Setup network opens. Follow steps 2–5 of section 4.4.

### 4.7 What the screen tells you

When nobody is scanning, the screen shows the clock, the scanner's name, and its connection. The third line matters most when something is wrong:
08:14

Form 2 Science
Online

Online. Everything is working.

08:14

Form 2 Science
No server

No server. WiFi works but the server can't be reached; scans are saved.

08:14

Form 2 Science
Offline
3 queued

Offline. Three scans are saved and will upload.

# PENDING

24:6F:28:A1:B2:C3

Not yet assigned. Contact your platform administrator.

# SETUP

Attendance-Setup
192.168.4.1

WiFi setup is open (section 4.4).

# OTA UPDATE

Do not unplug

Updating. Leave it on; it restarts by itself in 1–3 minutes.

After a scan:

Screen shows | What it means
SCANNED | and a name | Recognised; checking with the server. Resolves within a second or two.
PRESENT | , | TIME IN | , or | TIME OUT | Recorded.
SAVED | , a name, and "Offline" | Recognised with no internet. Stored and uploaded automatically later.
NOT LOGGED | The server accepted the scan but didn't count it — a holiday, an untracked
| | | | | weekday, no active period, or already recorded today.
COOLDOWN | and a name | Same person scanned again within a minute. Normal.
NO MATCH | Fingerprint not recognised. Try again; if it keeps happening, re-enrol that
| | | | | finger.
NOT MAPPED | and "See admin" | The finger is stored on the sensor but no person is linked to it on this scanner
| | | | | — usually after promotion or a deleted person. Re-enrol or delete that slot.
SCAN ERROR | The scan couldn't be processed. Try again.
REJECTED | or | REVOKED | The server refuses this scanner. Contact your platform administrator.
RESET | and "Re-provisioning" | The scanner was deleted and is wiping itself to start again.
Super Administrator Manual | Scanners

### 4.8 What the light tells you

Light | Meaning
Solid blue | Ready and online. Normal.
Solid purple | Ready, but no WiFi. Scans are saved for later.
Blinking purple | WiFi setup is open.
Green flash | Scan accepted, or a task succeeded.
Red flash | Not recognised, or a task failed.
Solid yellow | Waiting for a finger — during enrollment, or for the second master scan.

Five quick yellow
flashes | Master finger confirmed; WiFi setup is opening.
Breathing yellow | Waiting to be assigned by your platform administrator.
Breathing red | Installing a firmware update — do not unplug.

## 5 Members and staff

### 5.1 Adding one person

1 Go to Members (or Staff) and press Add member.

2 Enter their Full name, their ID, and choose their Unit.

3 Press Add member. The next screen offers Enroll fingerprints now? — queue Finger 1 and Finger 2 from there, or press Done and do it later.

### 5.2 Importing a spreadsheet

Press Import CSV and download the template. Fill in one row per person with the columns | sid | (ID),
fullname | , and the unit — written as the dashboard shows it, e.g. Form 2 Science. Upload it: a preview flags
any row with a missing field or a unit it can't match before anything is saved.

i

NOTE
Imported people start Inactive, because they have no fingerprints yet. Enrol each person, then press Activate. Only active people count towards attendance and absence marking.

### 5.3 Editing, fingerprints, and leavers

Press the edit icon to change a person's name, ID, or unit. The Fingerprints panel lists their stored fingers by sensor slot: Delete removes one from the scanner; an empty finger can be enrolled from there.

To retire someone, press Deactivate. They stop being marked absent and their history is kept. People are never deleted from the dashboard.

Super Administrator Manual | Scanners

## 6 Fingerprint enrollment

Enrollment is remote: you queue a job on the dashboard, and the scanner picks it up within about ten seconds and walks the person through it.

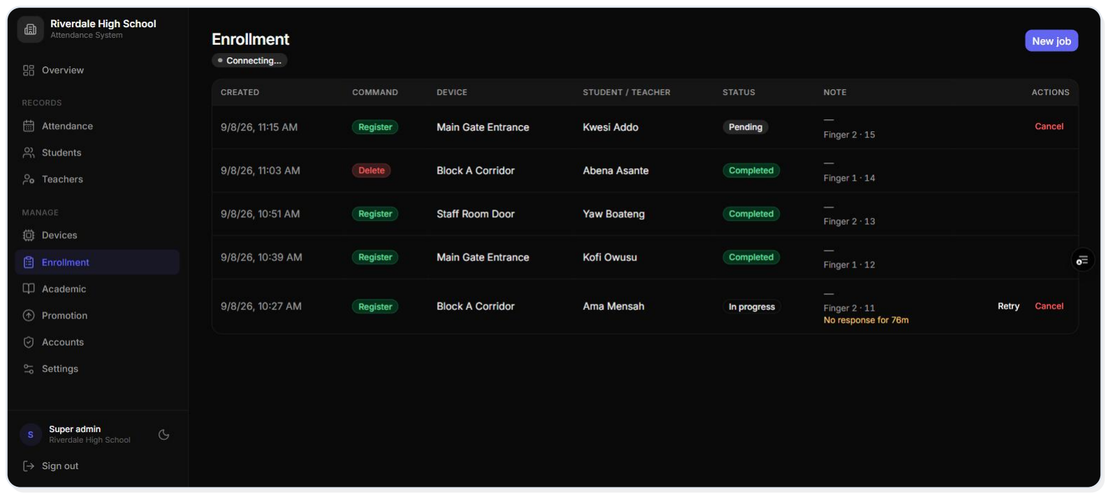
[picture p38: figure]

Figure 3 The Enrollment page. The row at the bottom shows a stuck job with its Retry and Cancel actions.

### 6.1 Queuing a job

Press New job and fill in:

Field | What to enter
Command | What the scanner should do — see the table below.
Device | The scanner the person will use — their unit's scanner.
Member | Who is enrolling. For a master finger you type a Name instead.
Finger slot | Finger 1 or Finger 2. Enrol two fingers so a cut or plaster doesn't lock someone out.
Sensor slot (1–127) | Where the print is stored on the sensor. Filled in with the next free slot — leave it.
Allow overwriting an occupied slot | Only tick this when you are deliberately replacing a stored print. You'll be asked to confirm.
Command | What it does
Register | Saves a new fingerprint for a person.
Delete | Removes one stored fingerprint from the scanner.
Reg. master | Saves a master finger (section 4.5).
Del. master | Removes the master finger.
Clear all | Erases every fingerprint on that scanner, including the master.
Super Administrator Manual | Members and staff

### 6.2 At the scanner

The person must be at the scanner while the job runs. The screen guides them:

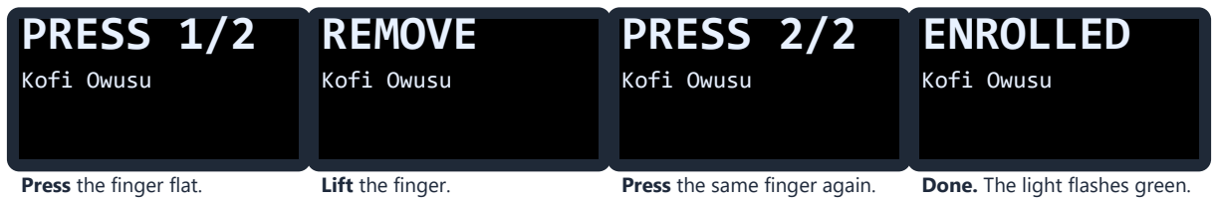
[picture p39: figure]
PRESS 1/2; Kofi Owusu; Press the finger flat.; REMOVE; Lift the finger.; PRESS 2/2; Press the same finger again.; ENROLLED; Done. The light flashes green.

If it goes wrong, the screen says why: | MISMATCH | (the two presses weren't the same finger), | TIMED OUT
(nobody pressed in time), | BAD SCAN | (a poor image), or | OCCUPIED | (the slot already holds a print and
overwriting wasn't allowed).

### 6.3 Job status and fixing problems

Status | Meaning
Pending | Waiting for the scanner to collect it.
In progress | The scanner has it; the person should be scanning.
Completed | The fingerprint is saved.
Failed | It didn't work. The Note column says why.
You see | Do this
"No response for 12m" under a job | The scanner lost the job or its connection. Press Retry to send it again, or Cancel.
Pending for a long time | The scanner is off or offline. Check its screen; Cancel if you queued it by mistake.
Failed | Press Re-queue to try again once the person is back at the scanner.
Failed with an occupied slot | Press + overwrite to retry and replace what's in that slot — only if that print no longer belongs to anyone.

The badge beside the page title shows whether the page is receiving live updates.

## 7 Periods, holidays, and tracked days

- Periods: press Add term, enter the name, year, and dates, save, then press Set active on its row. Keep exactly one active — each scan is filed under the active period.
- Holidays: on the Holidays tab press Add holiday, enter a label and dates, and tick Repeats every year for fixed dates. Nobody is marked absent on a holiday.
- Tracked days: under Settings → Days tracked, select the weekdays that count. Scans on other days are ignored and no absences are added, so a Monday-to-Friday institution simply leaves Saturday and Sunday unselected.
Super Administrator Manual | Fingerprint enrollment

## 8 Attendance

Attendance has three tabs — Records, Summary (totals per unit and period), and By member (each person's totals and last scan) — and filters for dates, period, member type, status, people, and units. With punctuality flags on, late arrivals carry a Late badge and early departures an Early badge. Export CSV downloads exactly what the filters show.

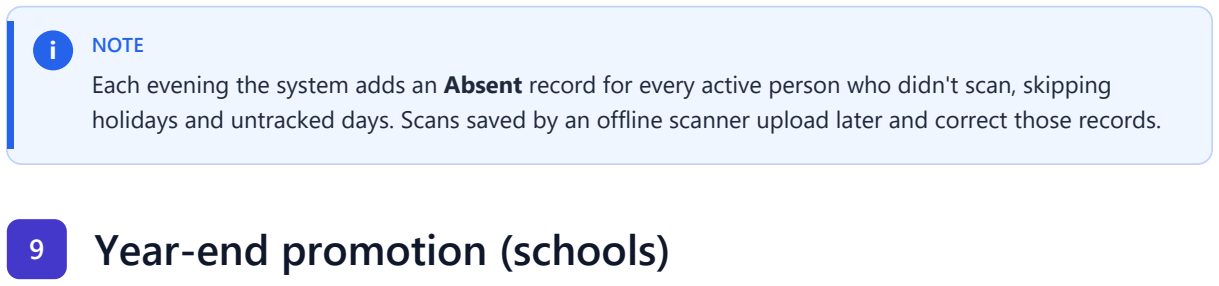
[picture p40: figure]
NOTE; 9 Year-end promotion (schools)

Each evening the system adds an Absent record for every active person who didn't scan, skipping holidays and untracked days. Scans saved by an offline scanner upload later and correct those records.

Promotion moves every active student to the next group — students in the last group are deactivated instead. The dashboard works out the order by sorting your group names (Form 1 before Form 2 before Form 10), and moves each student to the scanner with the same unit name in the next group. A student whose next group has no matching unit is skipped and listed as a warning.

1 Go to Promotion and review the preview and any warnings.

2 Add any missing scanners first, so nobody is skipped.

3 Export the year's attendance.

4 Press Apply promotion, then Confirm.

!

IMPORTANT
Promotion can't be undone, and it clears promoted students' fingerprint links — every promoted student must be enrolled again on their new scanner. Their old prints stay on last year's scanners, so a
new enrollment may fail as | OCCUPIED | : use + overwrite on that job, or run Clear all on each scanner
first and then re-enrol everyone, including the master finger.
Super Administrator Manual | Periods, holidays, and tracked days

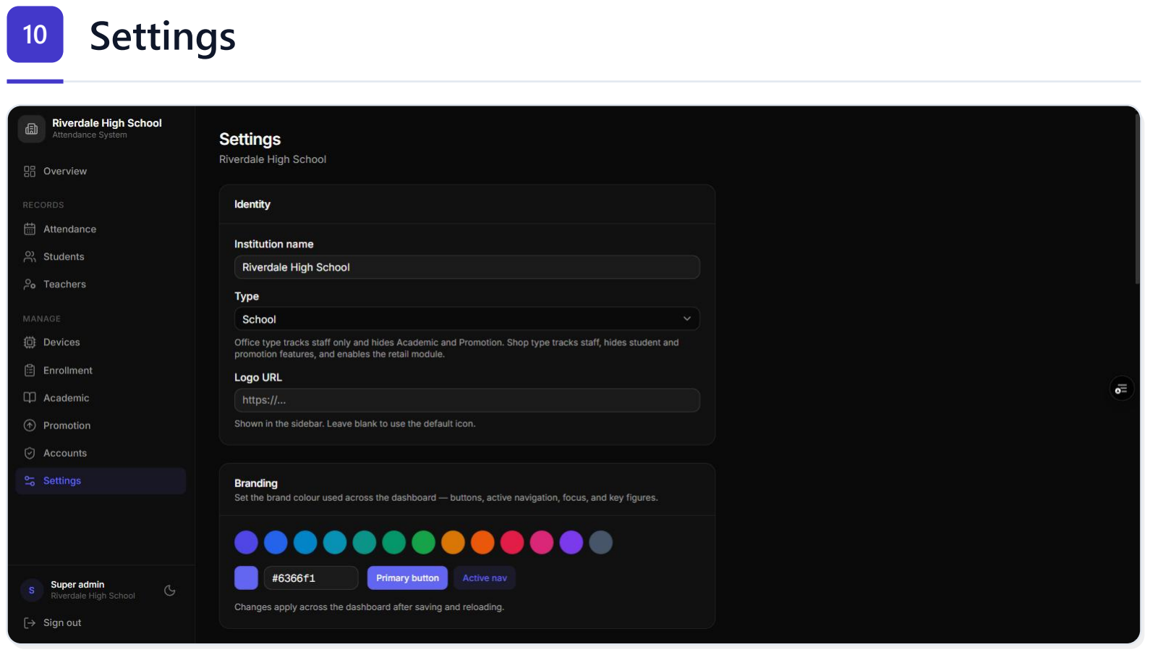
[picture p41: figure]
10 Settings

Figure 4 Settings, showing the Identity and Branding sections.

Setting | What it controls
Institution name | Shown at the top of the menu.
Type | School, Office, or Shop — decides which pages and modules exist. Talk to your platform administrator before changing it on a live institution.
Logo URL | A web link to your logo image, shown in the menu. Leave blank for the default icon.
Branding | Pick a preset colour or enter your own. Colours buttons, active menu items, and key figures after you save and reload.
Custom labels | Your own words for Member, Group, Unit, Period, and Staff — used everywhere, including CSV headings.
Track students / Track staff | Which rosters exist, each with a Scan mode: Present / Absent (one scan a day) or Time In / Time Out (first scan in, second out).
Days tracked | The weekdays that count. Untracked days record nothing and generate no absences.
Flag late arrivals | Set an Expected start time and a Grace period. Arrivals after start plus grace are marked Late.
Flag early departures | Set an Expected end time and a Grace period. Time-out scans before end minus grace are marked Early. Time In / Time Out mode only.
Timezone | When your day starts and ends — e.g. Africa/Accra.
Time display | 24-hour (13:30) or 12-hour (1:30 PM) on the dashboard. Exports always stay 24-hour.
Super Administrator Manual | Year-end promotion (schools)

Setting | What it controls
Name shown on device screen during a scan | Full name, first name, initial + last name, ID number only, or no name. Enrollment always shows the full name.
Currency, Sell services, Sell products, Enable loyalty rewards | The retail module — shops only. See the Shop Manual.

TIP
"Name shown on device screen" is a privacy control. Where a queue can read the screen, first name or initial + last name avoids showing everyone's full name.

## 11 Accounts

### 11.1 Creating an account

1 Go to Accounts and press Add account.

2 Enter their Email and an initial Password of at least 8 characters.

3 Choose a Role (see below).

4 For a teacher or staff account, choose their Assigned unit — it limits everything they see. For an admin it's optional: leave it blank for the whole institution, or pick a unit to limit them to it.

5 For a cashier, you can link the login to their Staff record, so the person who clocks in and the person at the till are the same entry.

6 Press Add account and give them the address and password.

### 11.2 Roles

Role | What they can do
Super Admin | Everything in this guide.
Admin | People, periods, holidays, attendance, promotion, and the shop module. Sees Accounts but can only change their own password. Tied to a unit, they can also enrol fingerprints on its scanner.
Teacher or Staff | Read-only attendance and roster for their assigned unit. Schools call the role Teacher; offices and shops Staff.
Cashier | Shops only: clients, sales, and viewing the catalog. No reports, staff, or settings.

### 11.3 Managing accounts

- Edit (pencil) changes someone's role, assigned unit, or linked staff record. Email addresses can't be changed — create a new account instead.
- Change password (key icon) works on your own account and on any admin, teacher, staff, or cashier account. Another super admin changes their own.
Super Administrator Manual | Settings

- Delete (bin icon) removes the account and its access immediately.

You can't delete your own account, and the dashboard won't delete or demote your institution's last super admin.

## 12 Getting help

Everything in this guide you can do yourself. Contact your platform administrator for:

- A new scanner that needs attaching to your institution
- A scanner showing | REJECTED | or | REVOKED | , or one that never leaves | PENDING
- A scanner that needs reflashing — for example, WiFi changed and no master finger was enrolled
- A lost or stolen scanner that must be blocked straight away
- Access for your only super admin account
Super Administrator Manual | Accounts

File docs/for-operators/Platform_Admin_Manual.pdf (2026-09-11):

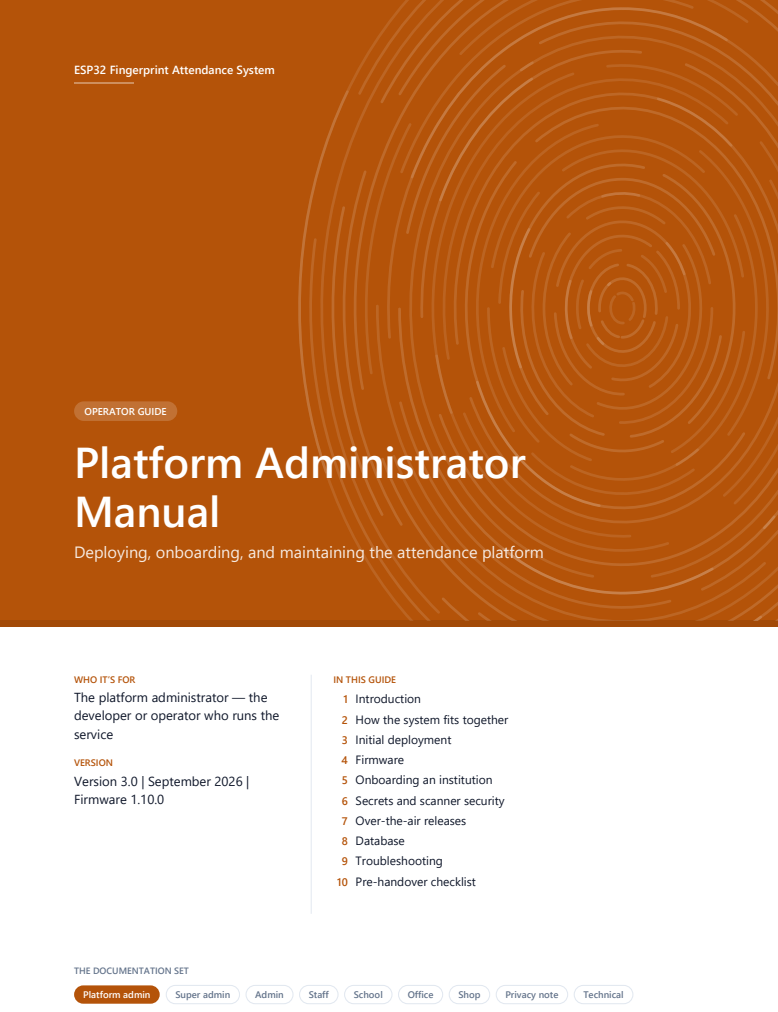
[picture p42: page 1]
Platform Administrator Manual; OPERATOR GUIDE; VERSION Version 3.0 | September 2026 |; Firmware 1.10.0; Platform admin; Super admin; Admin; Staff; School; Office; Shop; Privacy note; Technical

ESP32 Fingerprint Attendance System

Deploying, onboarding, and maintaining the attendance platform

WHO IT’S FOR
The platform administrator — the
developer or operator who runs the
service

IN THIS GUIDE
1 Introduction
2 How the system fits together
3 Initial deployment
4 Firmware
5 Onboarding an institution
6 Secrets and scanner security
7 Over-the-air releases
8 Database
9 Troubleshooting
10 Pre-handover checklist

THE DOCUMENTATION SET

## Contents

Platform Administrator Manual

ESP32 Fingerprint Attendance System | Page 1 of 10

## 1 Introduction

This manual is for whoever runs the platform: one cloud deployment that serves every institution. You deploy the backend and dashboard, build and flash scanners, onboard institutions, and keep secrets and certificates current.

platform_admin is the only role that sees every institution. Protect its credentials accordingly. For the design behind what follows — schema, edge-function contracts, firmware internals — see the Technical Documentation alongside this manual.

### 1.1 Roles at a glance

Role | | | Scope | Created by
platform_admin | Every institution | You, in SQL (section 3.3)
super_admin | One institution, full control | You at onboarding; then other super admins
admin | | | One institution, or one unit of it | A super admin
teacher | / | staff | One unit, read-only | A super admin
cashier | | | One shop: clients, sales, catalog | A super admin

### 1.2 Institution types

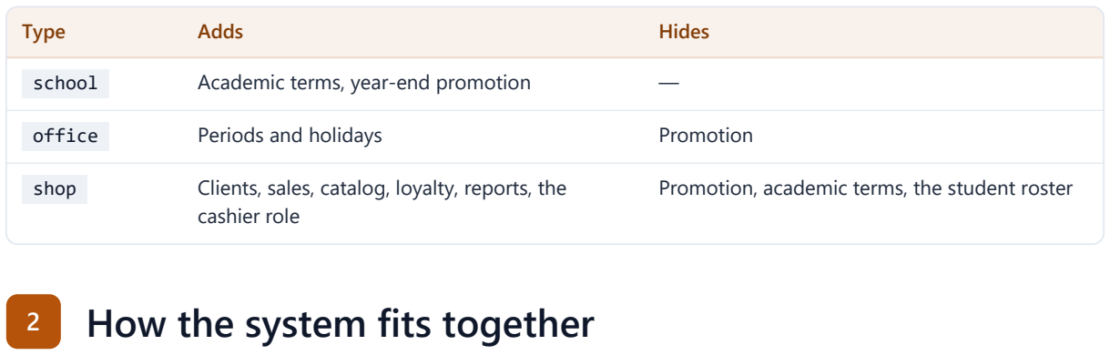
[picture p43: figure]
Type; Adds; Hides; school; Academic terms, year-end promotion; office; Periods and holidays; Promotion; cashier role; 2 How the system fits together

shop | Clients, sales, catalog, loyalty, reports, the
Promotion, academic terms, the student roster

Three tiers, all yours:

- ESP32 firmware — one Arduino sketch, flashed over USB once and updated over the air after that
- Supabase — PostgreSQL 17, six Deno edge functions, pg_cron, and pg_net
- Next.js dashboard — on Vercel; every Supabase call runs server-side, so no key ever reaches a browser

All traffic is HTTPS. Scanners validate server certificates against a CA bundle compiled into the firmware (section 4.3).

### 2.1 How scanners authenticate

Each scanner holds its own secret, issued when it is first assigned and stored in | devices.device_secret | . A
compromised scanner exposes only itself. | devices.revoked = true | is the server-side kill switch: the edge
functions refuse that scanner immediately, whether or not the physical unit is ever wiped.
Platform Administrator Manual | Contents

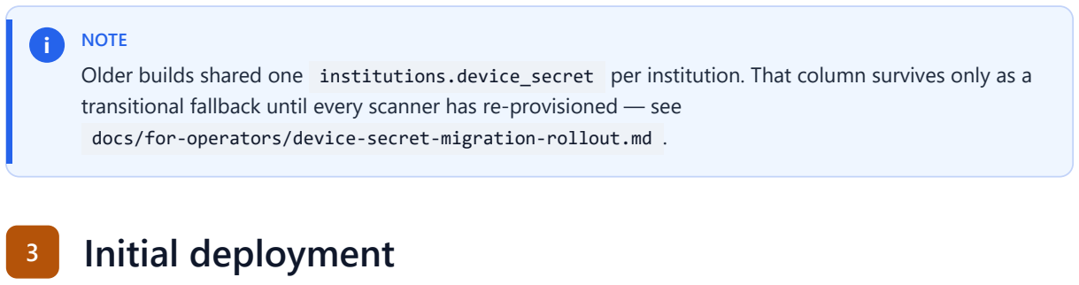
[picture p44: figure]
NOTE; docs/for-operators/device-secret-migration-rollout.md; 3 Initial deployment

Older builds shared one | institutions.device_secret | per institution. That column survives only as a
transitional fallback until every scanner has re-provisioned — see

### 3.1 Supabase

1 Create a Supabase project.

2 Enable the pg_net and pg_cron extensions (Database → Extensions). The nightly absence job can't call

net.http_post() without pg_net.

### 3 Store the two values the nightly job reads from Vault at run time:

SQL select vault.create_secret('https://<ref>.supabase.co', 'supabase_project_url');

select vault.create_secret('<a long random string>', 'cron_secret');

4 | Run every migration in | backend/supabase/migrations/ | , in filename order. The last cron migration
schedules | mark-absent-daily | at 21:00 UTC.
5 | Deploy the edge functions and set their secrets. | CRON_SECRET | must equal the Vault | cron_secret | ;
BOOTSTRAP_SECRET | must equal the one in the firmware's | secrets.h | .

BASH
cd backend/supabase
supabase functions deploy --project-ref <ref>
supabase secrets set --project-ref <ref> BOOTSTRAP_SECRET=<value> CRON_SECRET=<value>
SUPABASE_URL | and | SUPABASE_SERVICE_ROLE_KEY | are provided to functions automatically.

!

IMPORTANT
Migrations carry a "do not apply to cloud blind" header for a reason. Read each one before applying — several widen a constraint that must land before the matching dashboard deploy, and a few are order-sensitive.

i

NOTE
mark-absent works out "today" in each institution's own timezone, so it must run after the last scan of the day and before local midnight everywhere you operate. 21:00 UTC suits West Africa and Europe; reschedule in a new migration if you onboard institutions far from UTC.
Platform Administrator Manual | How the system fits together

### 3.2 Vercel

1 | Import the repository into Vercel with | frontend | as the root directory, and confirm which branch
Production deploys from.
2 | Set exactly three environment variables: | NEXT_PUBLIC_SUPABASE_URL | ,
NEXT_PUBLIC_SUPABASE_ANON_KEY | , and | SUPABASE_SERVICE_ROLE_KEY | .

3 Deploy.

### 3.3 Your platform admin account

Create your user in Supabase Auth, copy its UUID, and give it the platform role:

SQL insert into profiles (id, role) values ('<your-auth-user-uuid>', 'platform_admin');

A platform admin has no institution. Signed in, you see Institutions and Create institution in the menu, and every page can be filtered by institution.

## 4 Firmware

### 4.1 Prerequisites

- Arduino IDE 2.x with the Espressif ESP32 board package
- Libraries: Adafruit Fingerprint Sensor Library, RTClib, Adafruit GFX Library, Adafruit SSD1306, and ArduinoJson (version 7)
- WiFi, HTTPS, the web server, DNS, SPIFFS, and OTA updates come with the ESP32 core — nothing extra to install
- A USB cable

### 4.2 secrets.h

Copy | firmware/ClassAttendance_Current_RTC/secrets.example.h | to | secrets.h | (gitignored). It defines one
value, which must match the edge functions' | BOOTSTRAP_SECRET | :

C
#define BOOTSTRAP_SECRET "your_bootstrap_secret_here"

There is no compile-time WiFi. A factory-fresh scanner broadcasts | Attendance-Setup | (password
setup1234 | ) with a setup page at | 192.168.4.1 | , and whoever is on site enters the real network. You never
need a client's WiFi password to build their scanner. After that first boot, only an enrolled master finger can reopen the portal.

!

IMPORTANT
Enrol a master finger on every scanner before it leaves your hands, and make sure the client enrols their own. Without one, a WiFi change means the scanner comes back to you for reflashing — the most common avoidable support call.
Platform Administrator Manual | Initial deployment

### 4.3 certs.h

certs.h | holds | ROOT_CA_BUNDLE | , the PEM bundle mbedTLS validates against. It must contain every
certificate in each chain, not just the roots:
Certificate | Needed for
WE1 (Google Trust Services) intermediate | Supabase
GlobalSign ECC Root CA R4 | Supabase
Sectigo Public Server Auth CA DV E36 | GitHub API — OTA release checks
Sectigo Public Server Auth Root E46 | GitHub API
ISRG Root X1 | GitHub's download CDN — OTA binaries

mbedTLS can't fetch missing intermediates (no AIA). If a server omits one from its handshake and it isn't in the bundle, the connection fails with a misleading "connection refused". To capture a live chain when refreshing, in PowerShell:

POWERSHELL $req = [Net.HttpWebRequest]::Create("https://<ref>.supabase.co")

$req.GetResponse() | Out-Null
$req.ServicePoint.Certificate

### 4.4 Flashing

1 | Open | ClassAttendance_Current_RTC.ino | .

2 Board: ESP32 Dev Module. Select the COM port.

3 Upload.

4 Watch the Serial Monitor at 115200 baud to confirm it boots.

The current version is 1.10.0. Bump | FIRMWARE_VERSION | on every release — OTA compares against it (section
7).

## 5 Onboarding an institution

### 5.1 Creating it

1 Go to Create institution.

2 Enter the Name, choose the Type — School, Office, or Shop / Retail — and set the Timezone (an IANA name such as Africa/Accra).

3 Choose which member types are tracked and each one's scan mode. All of this can be changed later in Settings.

4 Enter the first super admin's Full name, Email, and a Temporary password of at least 8 characters.

5 Press Create.

Platform Administrator Manual | Firmware

Everything else — labels, currency, branding, modules, holidays — the super admin sets up. Hand over the dashboard address, the credentials, and the right manuals (section 5.3).

### 5.2 Attaching scanners

Scanners only ever enter the system by powering on: a new one calls | /register | and waits, showing
PENDING | and breathing yellow.

1 Go to Devices. New scanners are listed under Pending assignment, by MAC address.

2 Press Assign and choose the institution. The scanner receives its own secret on its next poll and turns solid blue.

3 The institution's super admin then sees it under Pending setup and gives it a group and unit.

To take a scanner out of service, see section 6.1.

### 5.3 What to hand each client

The client PDFs are in | docs/for-clients/ | .
Type | Give them
School | School_Manual.pdf | , | Super_Admin_Manual.pdf | , | Admin_Manual.pdf | ,
Staff_Manual.pdf | , | Biometric_Privacy_Note.pdf
Office | Office_Manual.pdf | , | Super_Admin_Manual.pdf | , | Admin_Manual.pdf | ,
Staff_Manual.pdf | , | Biometric_Privacy_Note.pdf
Shop | Shop_Manual.pdf | , | Super_Admin_Manual.pdf | , | Admin_Manual.pdf | ,
Biometric_Privacy_Note.pdf

The type guide explains what the system does for their kind of organisation; the role guides explain what each login can do. The privacy note answers the question every school and data-protection officer asks about fingerprints.

### 5.4 Creating a super admin by hand

If you'd rather use SQL: create the user in Supabase Auth, copy the UUID, then

SQL insert into profiles (id, role, institution_id)

values ('<uuid>', 'super_admin', '<institution-uuid>');

### 5.5 Institution lifecycle

Status | Effect
active | Normal operation.
suspended | Temporary — e.g. non-payment. Every user is sent to | /suspended | . Toggled from the
Institutions page.
deactivated | Long-term offboarding. Behaves like | suspended | ; data is kept for export. Set it in SQL.
Platform Administrator Manual | Onboarding an institution

Suspension is enforced in the dashboard's | verifySession() | , not by RLS, because the dashboard reads
through the service role. It doesn't touch scanners — they carry on and resume normally when the institution is reactivated.

Deleting an institution, from its page under Institutions, takes three confirmations. It removes all its people, attendance, periods, holidays, enrollment jobs, and accounts, and queues a wipe for each of its scanners. It can't be undone.

## 6 Secrets and scanner security

### 6.1 Per-scanner secrets

Each scanner's secret is minted by | assignment-poll | when it is first assigned, stored in
devices.device_secret | , and kept on the scanner in SPIFFS.
- Block a scanner now: set | devices.revoked = true | . Its next call is refused (401) and its screen shows
REVOKED | .
- Wipe and re-provision it: delete it from the Devices page (or insert a | device_resets | row). On its next
poll it erases its identity and registers again as new, then receives a fresh secret when reassigned.

Prefer revoking over a hard delete when a scanner is lost or stolen: revocation is immediate, whereas the wipe only lands if the scanner ever connects again.

### 6.2 BOOTSTRAP_SECRET

Compiled into the firmware and used only before a scanner is assigned. To rotate it, update | secrets.h | and
the functions' | BOOTSTRAP_SECRET | together, then reflash or release over the air. Already-assigned scanners are
unaffected; unassigned ones on the old value can't register until updated.

### 6.3 CRON_SECRET

The cron job reads the secret from Vault each time it fires, so there's nothing to reschedule. Update the
cron_secret | entry in Vault and set the same value as the functions' | CRON_SECRET | , in that order and close
together.

## 7 Over-the-air releases

Scanners check GitHub Releases each time they boot, after a random 0–120 second delay so a power cut doesn't send them all at once. They install only a strictly newer version.

1 In Arduino IDE: Sketch → Export Compiled Binary.

2 | Create a GitHub release tagged | firmware-v<version> | — e.g. | firmware-v1.11.0 | — higher than the
current | FIRMWARE_VERSION | .
3 | Attach the compiled | .bin | . The scanner installs the release's first | .bin | asset, so attach exactly one.

4 Scanners update on their next boot.

Platform Administrator Manual | Onboarding an institution

There's no forced push. During the update the screen shows | OTA UPDATE | and "Do not unplug", and the light
breathes red.

## 8 Database

- Migrations live in | backend/supabase/migrations/ | . Apply new ones in the SQL editor, in filename order,
after reading them. Never re-run old ones except when building a fresh database.
- Backups: Supabase takes daily backups on Pro and above, with point-in-time restore from its dashboard.
For extra safety, take on-demand | pg_dump | exports with the connection string.
- Raw data: the SQL and table editors have full service-role access. There is no undo for destructive SQL.
Platform Administrator Manual | Over-the-air releases

## 9 Troubleshooting

Symptom | Likely cause | Fix

"Bootstrap HTTP client error:
connection refused"
TLS chain failure | Check | certs.h | has every intermediate
(section 4.3). Try | setInsecure() | briefly to
prove reachability.

404 "Device not found" on the provisioning poll

No | devices | row for that
MAC, or no
provisioning_token

Check the table; confirm the provisioning-token migration ran.

mark-absent: "schema net does
not exist"
pg_net not enabled | Enable it under Database → Extensions.
mark-absent returns 401 | Vault | cron_secret | and the
functions' | CRON_SECRET
| differ

Set them to the same value (section 6.3).

No absences appear at all | Cron job missing, or Vault
secrets absent
Check | select * from cron.job | and the
Vault entries.
"unauthorized" after signing in | No | profiles | row, or the
wrong role

Insert or correct the profile for that auth user.

Users sent to | /suspended | institutions.status | isn't
| | active
Set it back to | active | if that wasn't intended.
Scanner stuck on | PENDING | Never assigned | Assign it under Devices → Pending assignment.
Scanner shows | REJECTED | or
REVOKED | | Its secret is refused, or
revoked | is true
Check | devices.revoked | ; re-provision if
| | | needed.
Idle screen says "No server" | WiFi works but HTTPS calls fail | Usually TLS or DNS. It re-associates every 60 s
| | | and reboots after 5 minutes unreachable; scans stay queued.

Re-registers after every SPIFFS
clear | | The clear ran after loadProvisioning() cached the id
The clear must be the first thing in | setup() | ,
followed by | ESP.restart() | .

OTA fails fetching GitHub
releases

ISRG Root X1 or a Sectigo
certificate missing

Ensure all five certificates are in ROOT_CA_BUNDLE .

Enrollment jobs fail as
OCCUPIED | after promotion
Old prints still on the sensor | The job's + overwrite action, or a Clear all job
on that scanner.

## 10 Pre-handover checklist

Run through this before you leave a client's site.

Institution created with the right type and timezone

Platform Administrator Manual | Database

Super admin signed in and changed the temporary password

Settings done: labels, scan modes, days tracked, punctuality, time display, branding (and currency and modules for a shop)

Current period active, and its holidays or closed days entered

Every scanner assigned, configured with a group and unit, and showing solid blue

A master finger enrolled on every scanner — and the client knows whose it is

The client has enrolled at least one person themselves, unaided

A real scan recorded and found on the dashboard

For shops: catalog loaded, a test sale recorded, and a cashier login working

Manuals and the privacy note handed over (section 5.3)

The client knows how to reach you

Platform Administrator Manual | Pre-handover checklist

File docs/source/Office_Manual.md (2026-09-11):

# Office Manual
:kicker: Institution type guide
:subtitle: Running a company, clinic, church, or any organisation on the attendance system
:audience: Office administrators, HR staff, and supervisors
:version: Version 3.0 | September 2026
:accent: #15803d
:series: office
:output: clients

<<<TOC>>>

## 1. What an office account looks like

>> An office account records the people who work for you by fingerprint. It's the general-purpose type -- for a company, clinic, NGO, church, factory, or any organisation that needs a reliable record of who was in, and when.

The Overview page of a demo office. Screenshots use demo data in dark mode.

Your menu has:

- **Overview** -- present and absent today, the attendance rate, and the latest scans
- **Attendance** -- every record, with filters, totals, and export
- **Staff** and / or **Members** -- your people
- **Devices** and **Enrollment** -- the scanners and the fingerprints on them
- **Periods & Holidays** -- reporting periods and non-working days
- **Accounts** and **Settings**

There are no academic terms and no year-end promotion -- those are school-only.

### 1.1 Two ways to record a day

Set under **Settings -> Scan mode**. It's the most important choice you'll make.

<!-- cols: 24 44 32 -->
| Mode | How it works | Choose it when |
| --- | --- | --- |
| **Present / Absent** | One scan marks the person present for the day. | You only need to know who came in. |
| **Time In / Time Out** | The first scan is arrival, the second is departure. Both appear on one row. | You need hours, lateness, or early departures. |

You can set a different mode for each roster -- members and staff.

> [!TIP] Start with **Present / Absent** unless you have a concrete reason to track hours. It's quicker at the door, and you can switch later.

## 2. Setting up, in the right order

1. **Settings** -- name, logo, timezone, scan mode, and **Days tracked** (leave Saturday and Sunday unselected if you're a Monday-to-Friday operation).
2. **Periods & Holidays** -- create your current reporting period, press **Set active**, and add public holidays.
3. **Devices** -- give each scanner its department and location, e.g. *Operations* and *Warehouse*.
4. **Staff** -- add your people, or import them from a spreadsheet.
5. **Enrollment** -- enrol each person's fingerprints, then activate them.
6. **Accounts** -- create logins for HR, department heads, and supervisors.

> [!WARNING] Choose your scan mode **before** you enrol anyone. Switching mid-period leaves two different shapes of record in the same report.

## 3. Words you can change

The defaults are Member, Group, Unit, and Period. Rename them under **Settings -> Custom labels**:

<!-- cols: 34 66 -->
| Default | An office usually says |
| --- | --- |
| Member / Members | Employee / Employees |
| Group | Department or Division |
| Unit | Team, Branch, or Site |
| Period | Quarter, Month, or Year |

The new words appear everywhere, including CSV headings. Nothing about the data changes.

### 3.1 One roster or two

Two rosters are available, each switched on under **Settings**:

- Most offices use **one** roster for everybody -- turn on **Track staff** only. The Members page then disappears.
- Use both for two genuinely different groups -- say, a clinic's employees on one roster and volunteers on the other, each with its own scan mode.

## 4. Periods and holidays

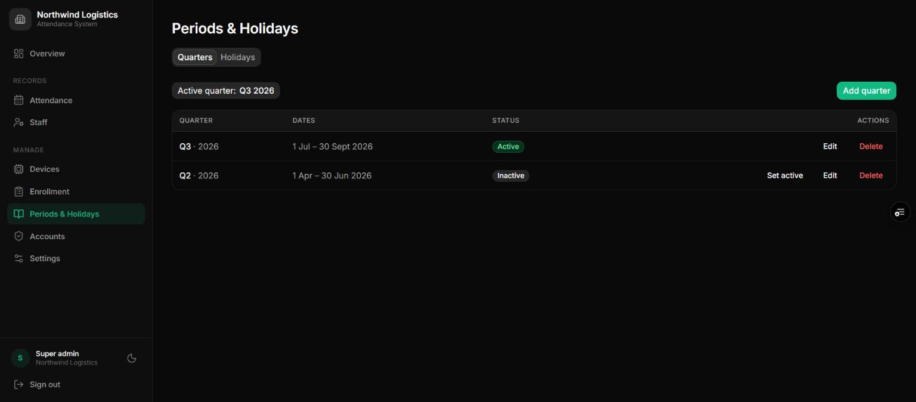
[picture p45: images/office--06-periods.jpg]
Periods & Holidays in a demo office, with the period renamed Quarter.


### 4.1 Periods

A period is simply a reporting bucket -- a quarter, a month, or a year, whatever matches how you report. Press **Add** on the first tab, enter a name, year, and dates, save, then press **Set active** on its row. Keep exactly one active; each scan is filed under it.

### 4.2 Holidays

On the **Holidays** tab, add every non-working day: public holidays, company shutdowns, stocktaking days. Nobody is marked absent on them. Tick **Repeats every year** for fixed dates; leave it unticked for dates that move.

**Days tracked** in Settings handles weekends for you -- leave the days you're closed unselected instead of adding them as holidays.

## 5. Your people

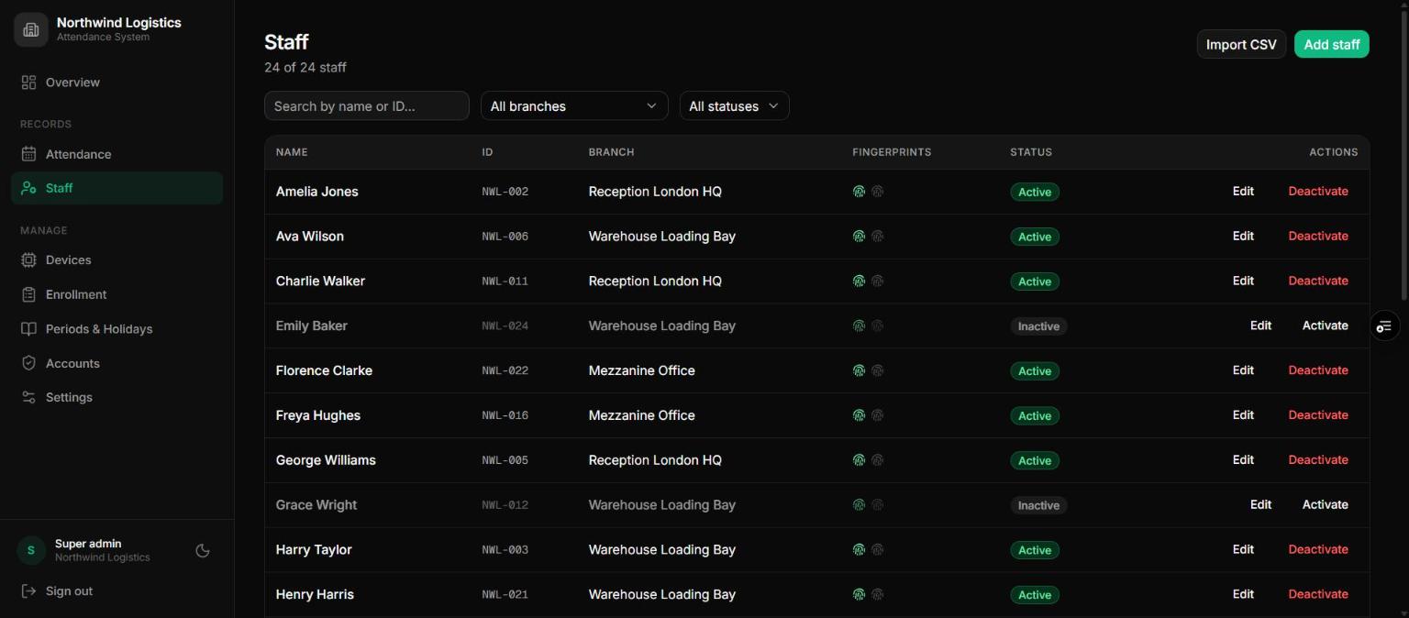
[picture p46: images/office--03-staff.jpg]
A demo office's Staff page.


### 5.1 Adding one person

Go to **Staff** and press **Add**. Enter the full name and ID, and choose their unit -- listed as department and location. The dashboard then offers to enrol their fingerprints straight away.

### 5.2 Importing a spreadsheet

1. Press **Import CSV** and download the template.
2. Fill in one row per person: `sid` (staff number), `fullname`, and the unit as the dashboard shows it.
3. Upload and review the preview, which flags any row it can't use before anything is saved.
4. Confirm.

**Imported people start Inactive** because they have no fingerprints yet. Enrol each one, then press **Activate**.

### 5.3 Leavers

Press **Deactivate** on their row on their last day. Their history is kept and they stop being marked absent. People are never deleted.

> [!NOTE] If you forget to deactivate a leaver, they collect an absence every working day, which distorts your reports until someone notices.

## 6. Lateness and early departures

Under **Settings**, two optional switches turn the attendance record into a punctuality record:

<!-- cols: 30 70 -->
| Setting | What it does |
| --- | --- |
| **Flag late arrivals** | Set an **Expected start time** and a **Grace period** in minutes. Anyone whose first scan is after start plus grace gets a **Late** badge. |
| **Flag early departures** | Set an **Expected end time** and a **Grace period**. A time-out scan before end minus grace gets an **Early** badge. Only works in Time In / Time Out mode. |

For example, with a start of 08:00 and 10 minutes' grace, a scan at 08:09 is on time and 08:11 is late.

## 7. Accounts for supervisors

Give department heads and shift supervisors a **Staff** account assigned to their unit. They can see and export their own team's attendance and nothing else, and can't change anything.

For a supervisor who should also manage their team's records -- adding people, enrolling fingerprints on their scanner -- create an **Admin** account assigned to that unit instead. Leave the unit blank for an HR admin who covers everyone.

## 8. Getting data out

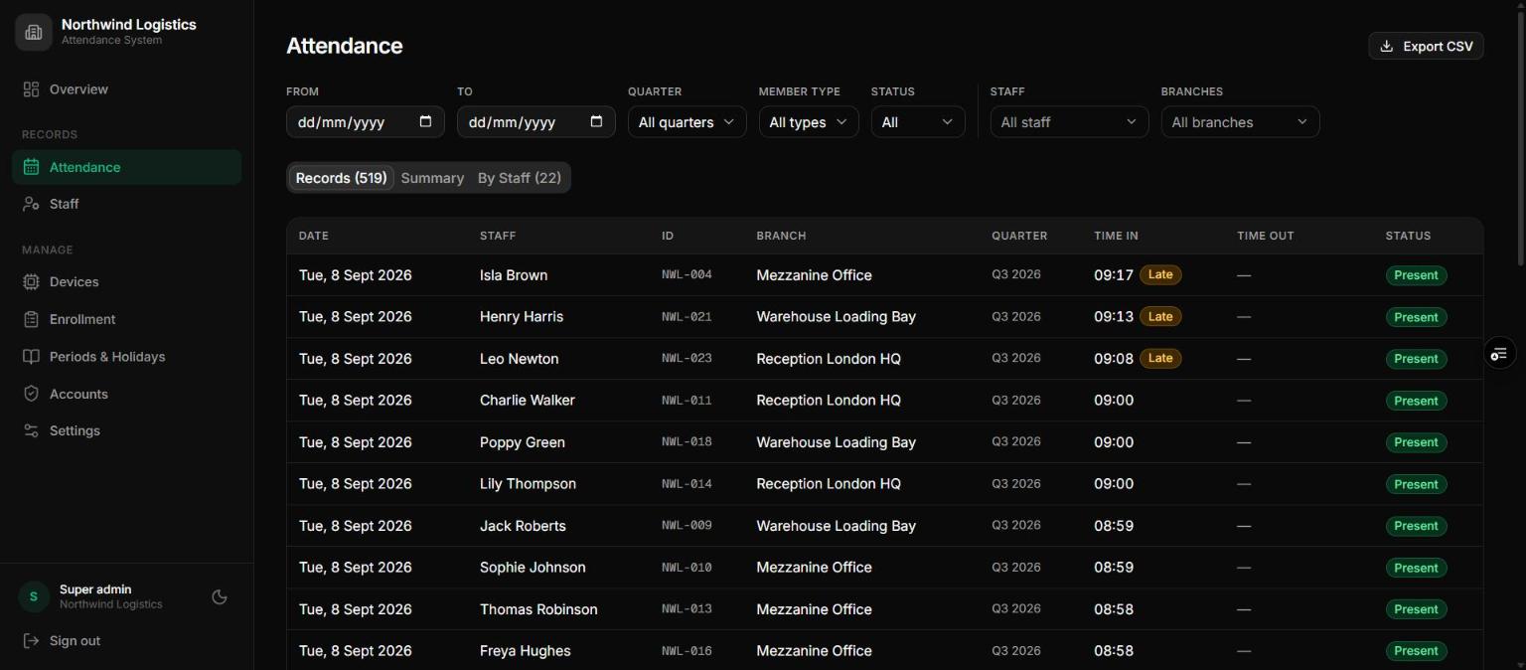
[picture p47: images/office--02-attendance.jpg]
The Attendance page: filters across the top, then the Records, Summary, and By member tabs.


Go to **Attendance**, set the filters -- dates, period, member type, status, people, units -- and press **Export CSV**. The file opens in Excel or Google Sheets.

This is how attendance feeds payroll: filter to the pay period and the department, export, and hand the file over. In Time In / Time Out mode both times are on the same row, so hours are a simple subtraction in the spreadsheet.

**Summary** gives each unit's present and absent totals and attendance percentage per period; **By member** gives each person's totals and last scan.

## 9. Everyday problems

<!-- cols: 38 62 -->
| Problem | What to do |
| --- | --- |
| Everyone is absent on a working day | A holiday was entered by mistake, or the scanner was off all day. Check both. |
| Everyone is absent on a weekend | Saturday or Sunday is still selected under **Days tracked**. Unselect it. |
| Someone was at work but shows absent | They didn't scan, or the scan failed -- "NO MATCH" on the screen means it didn't count. |
| A time out but no time in | Their first scan of the day didn't register. |
| The scanner says "NOT LOGGED" | Accepted but not counted: a holiday, an untracked day, or already recorded. |
| A leaver still shows absences | They were never deactivated. |
| A supervisor sees nothing | Their account has no unit, or the wrong one. |
| An import rejects rows | A field is missing, or a unit doesn't match your scanners. |

## 10. The scanner, at a glance

::: screens
TIME IN | Kwame Boateng | **Arrival recorded.** "TIME OUT" at the end of the day.
SAVED | Kwame Boateng | Offline | **Saved offline**; uploads when the internet returns.
NOT LOGGED | Kwame Boateng | **Not counted** -- holiday, untracked day, or duplicate.
COOLDOWN | Kwame Boateng | **Scanned twice** in a minute. The second scan is ignored.
NO MATCH | **Not recognised.** Try again, finger flat.
PENDING | 24:6F:28:A1:B2:C3 | **Not set up yet** -- see your super admin.
:::

| Light | Meaning |
| --- | --- |
| Solid blue | Ready and online |
| Solid purple | Ready, but no WiFi |
| Green flash | Scan accepted |
| Red flash | Not recognised |
| Solid yellow | Waiting for a finger during enrollment |
| Breathing yellow | Waiting to be set up |
| Breathing red | Installing an update -- do not unplug |

> [!TIP] "COOLDOWN" protects Time In / Time Out mode: a nervous double-scan at the door can't accidentally clock someone out a second after they clocked in.

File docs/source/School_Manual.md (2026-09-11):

# School Manual
:kicker: Institution type guide
:subtitle: Running a school, college, or training centre on the attendance system
:audience: Heads, school administrators, and class teachers
:version: Version 3.0 | September 2026
:accent: #6d28d9
:series: school
:output: clients

<<<TOC>>>

## 1. What a school account looks like

>> A school account records **students** -- and, if you like, **teachers and staff** -- by fingerprint. It is the only type with academic terms and year-end promotion, and the register completes itself: nobody marks anyone absent by hand.

The Overview page of a demo school: today's counts and the latest scans. Screenshots use demo data in dark mode.

Your menu has:

- **Overview** -- present and absent today, the attendance rate, and the latest scans
- **Attendance** -- every scan record, with filters, totals, and export
- **Students** and **Teachers** -- your rosters (the default words are *Members* and *Staff*; see section 3)
- **Devices** and **Enrollment** -- the scanners and the fingerprints on them
- **Academic** -- terms and holidays
- **Promotion** -- moving everyone up at the end of the year
- **Accounts** and **Settings**

Which of these each person sees depends on their role -- see the role guides for super admins, admins, and staff.

### 1.1 How a school day is recorded

1. A student places a finger on their class's scanner. It recognises them and shows "PRESENT".
2. The dashboard shows the scan within seconds, filed under today and the active term.
3. Each evening, every active student who didn't scan gets an **Absent** record -- except on holidays and on weekdays you don't track.

> [!NOTE] Absences appear that evening, not during the day. If a scanner was offline, its saved scans upload when it reconnects and turn those absences back into present.

## 2. Setting up, in the right order

1. **Settings** -- name, logo, timezone, and **Days tracked** (leave Saturday and Sunday unselected unless you hold weekend classes). Rename the labels to your school's words (section 3).
2. **Academic** -- create the current term, press **Set active**, and add its holidays (section 4).
3. **Devices** -- give each scanner its group and class, e.g. *Form 2* and *Science*.
4. **Students** -- add them one by one or import each class from a spreadsheet (section 5).
5. **Enrollment** -- enrol each student's fingerprints, then activate them.
6. **Accounts** -- create logins for your admins and class teachers (section 6).

> [!WARNING] Create the term **before** the first scan. Every record is tied to the term active when the scan happened, and scans taken with no active term are hard to report on later.

> [!TIP] Name your scanners' groups so they sort in order -- *Form 1*, *Form 2*, *Form 3* or *JHS 1*, *JHS 2*, *JHS 3* -- and use the **same class names in every form**. Promotion depends on it (section 7).

## 3. Words you can change

The dashboard's default words are Member, Group, Unit, Period, and Staff. Most schools rename them under **Settings -> Custom labels**:

<!-- cols: 34 66 -->
| Default | A school usually says |
| --- | --- |
| Member / Members | Student / Students |
| Group | Form, Grade, or Year |
| Unit | Class, Stream, or Section |
| Period | Term or Semester |
| Staff | Teacher |

The new words appear everywhere -- menus, page titles, column headings, and CSV exports. Nothing about the data changes, so you can adjust them at any time.

## 4. Terms and holidays

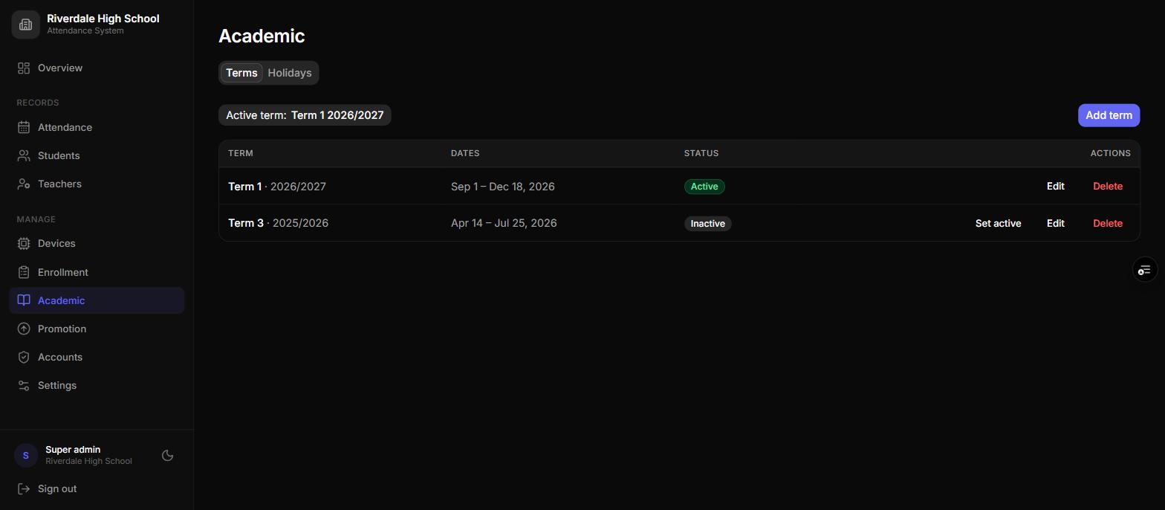
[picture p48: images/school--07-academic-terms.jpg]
The Academic page with its Terms and Holidays tabs.


### 4.1 Terms

1. Go to **Academic** and press **Add term**.
2. Enter the **Term** (e.g. *Term 1*), the **Year** (e.g. *2026* or *2025/2026*), and the start and end dates.
3. Save, then press **Set active** on its row.

**Keep exactly one term active.** It's what each scan is filed under and what reports default to. At the end of a term, create the next one and press **Set active** on it.

### 4.2 Holidays

On the **Holidays** tab, press **Add holiday** and add every non-teaching day: mid-term breaks, public holidays, and staff training days. Give a start date, and an end date for a break of several days. Nobody is marked absent on those dates.

Tick **Repeats every year** for holidays on a fixed date, such as Independence Day. Leave it unticked for dates that move, such as Easter, and add those each year.

> [!TIP] Enter next term's holidays when you create the term. A missed holiday produces a full register of false absences that someone then has to explain to parents.

## 5. Students

A demo school's Students page.

### 5.1 Adding one student

Go to **Students** and press **Add student**. Enter the full name and ID, and choose their class -- listed as form and class, e.g. *Form 2 Science*. After saving, the dashboard offers to enrol their fingerprints straight away.

### 5.2 Importing a whole class

1. Press **Import CSV** and download the template.
2. Fill in one row per student: `sid` (their ID), `fullname`, and the class as the dashboard shows it, e.g. *Form 2 Science*.
3. Upload it. A preview shows which rows are ready and which have a problem before anything is saved.
4. Confirm.

**Imported students start Inactive**, because they have no fingerprints yet. Enrol each one, then press **Activate** -- only active students are counted in attendance and absence marking.

### 5.3 Leavers

Press **Deactivate** on a student's row. Their history is kept and they stop being marked absent. Students are never deleted, so past registers stay complete.

## 6. Teachers and class scoping

Give each class teacher a **Teacher** account, assigned to their class under **Accounts**. They can then see and export their own class's register and roster -- and nothing else. They can't change anything.

If you track teachers' own attendance too, turn on **Track staff** in Settings. Teachers then appear on the **Teachers** page and scan like students.

For a head of year who should manage one class, create an **Admin** account assigned to that class. They can manage its records and enrol fingerprints on its scanner.

## 7. Year-end promotion

**Promotion** moves every active student up one form, in one step. Students in the final form are deactivated instead of promoted.

### 7.1 How the dashboard works out who goes where

The dashboard sorts your form names in natural order -- *Form 2* comes before *Form 10* -- and moves each student to the scanner with the **same class name** in the next form:

<!-- cols: 30 30 40 -->
| Now in | Moves to | Because |
| --- | --- | --- |
| Form 1 Science | Form 2 Science | Next form, same class name |
| Form 2 Arts | Form 3 Arts | Next form, same class name |
| Form 3 Science | *Deactivated* | Form 3 is the final form |
| Form 1 Business | *Skipped* | There is no *Form 2 Business* scanner |

Skipped students are listed in a warning on the Promotion page. Set up the missing scanner first and they'll be included.

### 7.2 Running it

1. Finish the year's reports, then **export the full year's attendance**.
2. Go to **Promotion** and review each card: how many students move from which form to which.
3. Resolve any skipped students.
4. Press **Apply promotion**, check the summary, and press **Confirm**.

> [!WARNING] Promotion is bulk and **irreversible**. It also clears promoted students' fingerprint links, so **every promoted student must be enrolled again** on their new class's scanner before they can scan.

### 7.3 After promotion

Last year's prints are still stored on the old scanners, so re-enrolling a student can fail with "OCCUPIED" when their new slot is already in use. Either press **+ overwrite** on the failed job, or start clean: run a **Clear all** job on each scanner, re-enrol its master finger, then enrol the new class. Plan this for the first days of term, before registers matter.

## 8. Reading attendance

- **Records** is the daily register: one row per student per day. With **Flag late arrivals** on in Settings, students who scan after your start time plus the grace period carry a **Late** badge.
- **Summary** gives present and absent totals and the attendance percentage for each class and term -- handy for termly reports.
- **By student** gives each student's totals, rate, and last scan -- the quickest way to spot persistent absence.

Use the **Term** and **Classes** filters, then **Export CSV** to take any view into a spreadsheet.

## 9. Everyday problems

<!-- cols: 36 64 -->
| Problem | What to do |
| --- | --- |
| A whole class is absent on one day | A holiday is missing, or the scanner was off all day. Add the holiday; check the scanner's screen. |
| A student was in school but shows absent | They didn't scan, or the scan failed -- "NO MATCH" on the screen means it didn't count. |
| The scanner says "NOT LOGGED" | The scan was accepted but not counted: a holiday, an untracked weekday, no active term, or already recorded today. |
| A new student can't scan | Their fingerprint isn't enrolled yet, or they're still Inactive. |
| Records aren't tied to a term | No term was active at the time. Create one and press **Set active**. |
| A teacher sees nothing | Their account has no class assigned, or the wrong one. |
| An import rejects rows | A field is missing, or a class doesn't match your scanners' names. |
| Students skipped at promotion | No scanner exists for their next form with the same class name. |

## 10. The scanner, at a glance

::: screens
PRESENT | Ama Mensah | **Recorded.** The light flashes green.
SAVED | Ama Mensah | Offline | **Saved offline**; uploads when the internet returns.
NOT LOGGED | Ama Mensah | **Not counted** -- holiday, untracked day, or duplicate.
COOLDOWN | Ama Mensah | **Scanned twice** in a minute. Normal.
NO MATCH | **Not recognised.** Try again, finger flat.
PENDING | 24:6F:28:A1:B2:C3 | **Not set up yet** -- see your super admin.
:::

| Light | Meaning |
| --- | --- |
| Solid blue | Ready and online |
| Solid purple | Ready, but no WiFi |
| Green flash | Scan accepted |
| Red flash | Not recognised |
| Solid yellow | Waiting for a finger during enrollment |
| Breathing yellow | Waiting to be set up |
| Breathing red | Installing an update -- do not unplug |

> [!TIP] A scanner that has lost WiFi keeps working. It stores scans and uploads them when the connection returns, so a router outage never costs you a day's register.

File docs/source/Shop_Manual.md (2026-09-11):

# Shop Manual
:kicker: Institution type guide
:subtitle: For shops, salons, barbershops, and other retail or service businesses
:audience: Shop owners, managers, and cashiers
:version: Version 3.0 | September 2026
:accent: #be185d
:series: shop
:output: clients
:toc_depth: 2

<<<TOC>>>

## 1. What the system does for a shop

>> A shop account does two separate jobs. They share one login and one dashboard, but neither depends on the other -- you can use either half on its own.

<!-- cols: 22 42 36 -->
| Half | What it covers | How records are made |
| --- | --- | --- |
| **Staff attendance** | Your own employees -- stylists, barbers, sales assistants, mechanics | A fingerprint scan at the scanner |
| **Retail** | Your customers, sales, stock, and loyalty rewards | Typed into the dashboard by a cashier or manager |

> [!NOTE] Customers never touch the fingerprint scanner -- only your employees are enrolled. A customer's visit is recorded when a sale is made for them, or when someone presses **Log visit** on their row.

A demo shop's Overview: takings, visits, the top service today, stock warnings, and recent sales. Screenshots use demo data in dark mode.

### 1.1 What you'll find in the menu

- **Overview** -- takings and visits today, the top service, low-stock warnings, and the latest sales
- **Attendance** and **Staff** -- your employees' attendance and roster
- **Clients** -- your customer list
- **Sales** -- record and review sales
- **Catalog** -- the products and services you sell *(shown when you sell either)*
- **Loyalty** -- reward rules and the history of rewards given *(shown when loyalty is on)*
- **Reports** -- takings, best clients, revenue per staff member, best sellers, visits, stock, and rewards
- **Devices**, **Enrollment**, **Closed Days**, **Accounts**, **Settings** -- set-up and administration

Each role sees only what it's allowed to use -- section 10 has the full list.

## 2. Setting up, in the right order

1. **Settings** -- currency, timezone, shop name and logo, and which modules you use: products, services, loyalty (section 3).
2. **Closed Days** -- your public holidays and any dates you'll be shut.
3. **Catalog** -- the services and products you sell, with prices.
4. **Staff** -- your employees.
5. **Enrollment** -- each employee's fingerprints, at the scanner.
6. **Accounts** -- logins for your manager and cashiers.
7. **Clients** -- add customers as they come in; there's no need to load them in advance.
8. **Loyalty** -- once the catalog is in, your reward rules.

> [!TIP] Do steps 1--3 before you record a single sale. Each sale keeps the prices and currency of the moment it was recorded, so getting them right first saves you correcting history later.

## 3. Settings that matter for a shop

Found under **Settings**. Only a super admin can change them.

<!-- cols: 28 72 -->
| Setting | What it does |
| --- | --- |
| **Currency** | The currency every amount is shown in -- GHS, NGN, and others. Display only: it doesn't convert existing figures, so choose it once and leave it. |
| **Sell products** | Off hides the Products tab and product lines on sales. Turn it off if you only sell services. |
| **Sell services** | Off hides the Services tab and service lines. Turn it off if you only sell products. |
| **Enable loyalty rewards** | Off hides the Loyalty page and reward suggestions. History is kept and returns if you switch it back on. |
| **Timezone** | When "today" starts and ends for visits, takings, and staff absences. |
| **Days tracked** | The weekdays staff attendance counts. Most shops trade at weekends, so leave Saturday (and Sunday) selected. For one-off dates you're shut, use **Closed Days**. |
| **Track staff** | Must be on for employee attendance. |

> [!NOTE] Turning off **Sell products** or **Sell services** only hides them from new sales. Past sales keep their items and prices and still appear correctly in Reports.

## 4. Clients

**Clients** are your customers -- a separate list from **Staff**. A client has no fingerprint.

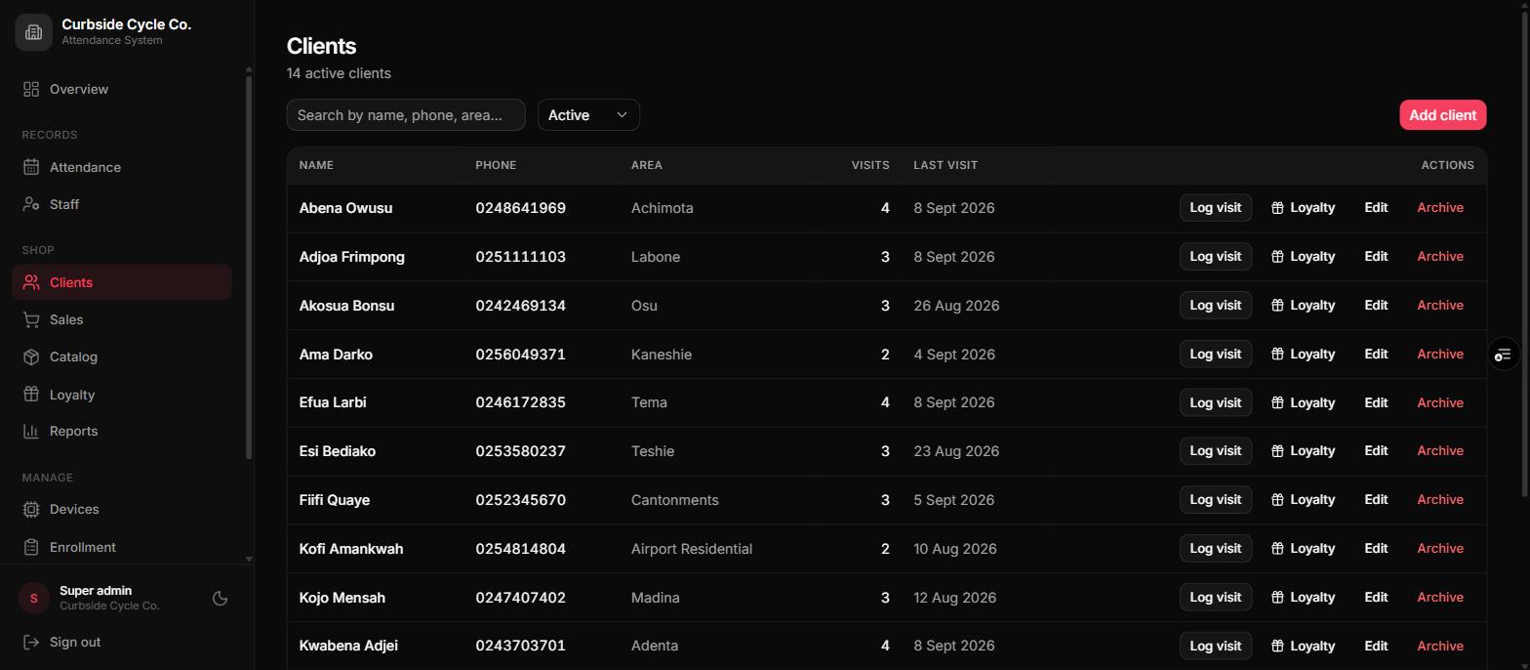
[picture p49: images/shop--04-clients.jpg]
The Clients page, with visits, last visit, loyalty, and the row actions.


### 4.1 Adding a client

1. Go to **Clients** and press **Add client**.
2. Enter the **Name** and **Phone number**, and optionally their area.
3. Save.

**The phone number is required and unique** -- it's what ties a customer to their visits and loyalty progress. Type it as `0XXXXXXXXX` or `+233XXXXXXXXX`; the dashboard stores both the same way, so the same number can't be entered twice.

### 4.2 Working with a client

<!-- cols: 26 74 -->
| Action | What it does |
| --- | --- |
| **Log visit** | Records that they came in today and opens a new sale for them. If today's visit is already logged, it says so. |
| **Loyalty progress** (gift icon) | How close they are to each reward, and anything they've already earned. |
| **Visit history** | Every day they've been in. |
| **Edit** | Change the name, phone, or area. |
| **Archive** | Hides them from the active list, keeping all their history. Admins only. |

A client counts **one visit per day**, however many sales they make that day -- which keeps visit-based rewards fair. Use the status filter to see archived clients.

## 5. Catalog -- products and services

**Catalog** holds everything you can put on a sale, in two tabs.

<!-- cols: 24 38 38 -->
| | **Products** | **Services** |
| --- | --- | --- |
| Examples | Shampoo, clippers, inner tubes | Haircut, retwist, puncture repair |
| Has a price | Yes | Yes |
| Has stock | Yes -- counts down with each sale | No |

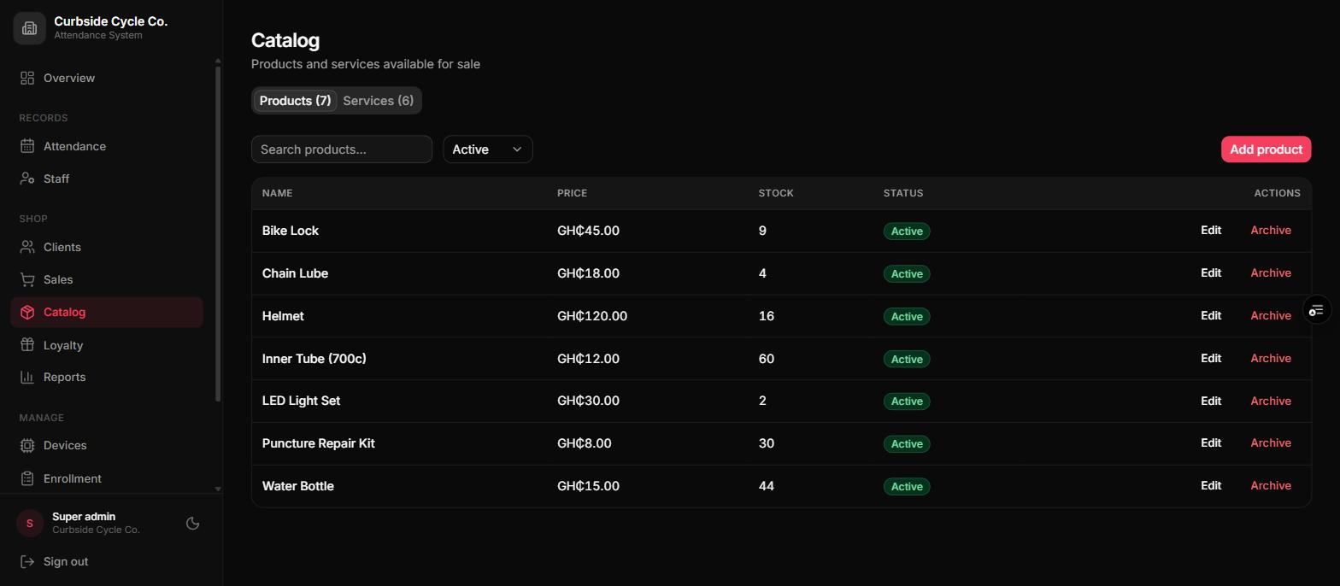
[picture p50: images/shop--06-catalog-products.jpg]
The Catalog's Products tab.


### 5.1 Adding and changing items

Press **Add product** or **Add service**, enter the name and price (and, for a product, the stock you hold now), and save. Two active items on the same tab can't share a name; archiving an item frees its name.

To change a price, edit the item. **The new price applies to future sales only** -- every past sale keeps the price it was recorded at, so your takings never shift under you.

Press **Archive** to take an item off sale. It stays attached to every past sale that used it. Items are never deleted.

### 5.2 Stock

Product stock counts down automatically with each sale. It may go below zero -- the dashboard won't block a sale because the count says none are left, since the count may simply be out of date. Correct it by editing the product and entering the real figure. **Reports -> Low stock** lists every product with 5 or fewer left.

Cashiers can see the catalog but not change it.

## 6. Recording a sale

This is the main daily task. Go to **Sales** and press **New sale** (or press **Log visit** on a client's row).

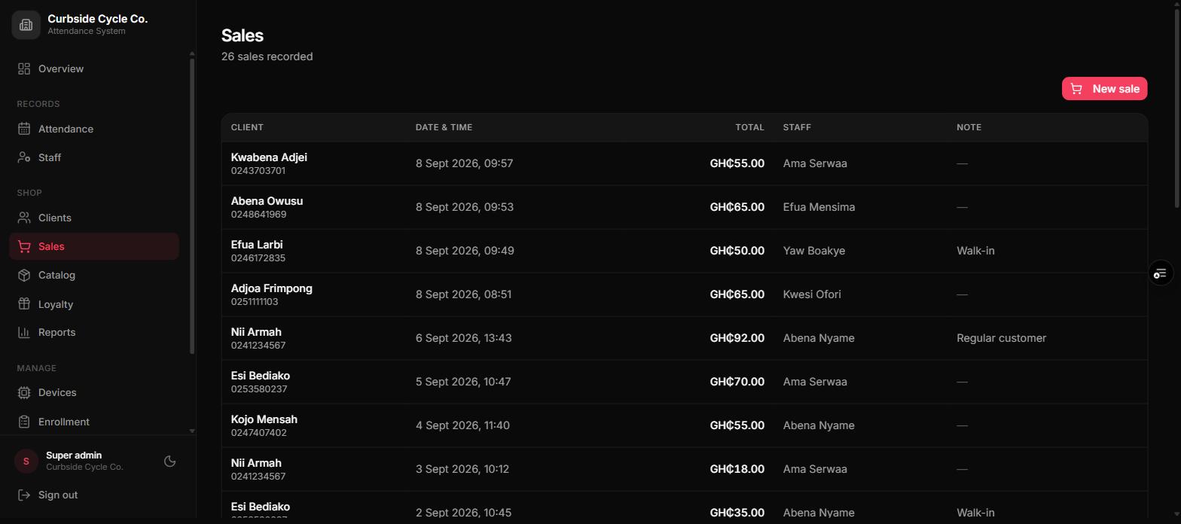
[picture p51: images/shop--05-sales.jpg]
The Sales page, newest first.


1. **Client** -- required. Start typing to find them; add them on the Clients page first if they're new.
2. **Rewards** -- if the client has earned anything, it appears here by itself (section 7.3).
3. **Staff** -- optional: who served them. Fill it in if you want **Reports -> By staff** to be meaningful.
4. **Items** -- one line per product or service, with the quantity.
5. **Price** -- to give a discount by hand, change the price on that line.
6. **Note** -- optional, e.g. *Client paid in cash*.
7. Press **Record sale**.

Recording a sale does three things at once: it saves the sale, counts today as a visit for that client, and reduces stock for any products sold.

> [!NOTE] Each line keeps the item's name and price **as they were at that moment**. Renaming or repricing a catalog item later never changes a recorded sale.

## 7. Loyalty rewards

**Loyalty** is a punch-card system. You set a target, the dashboard counts towards it from real sales and visits, and a reward appears at the till the moment a client qualifies -- nobody has to remember or check.

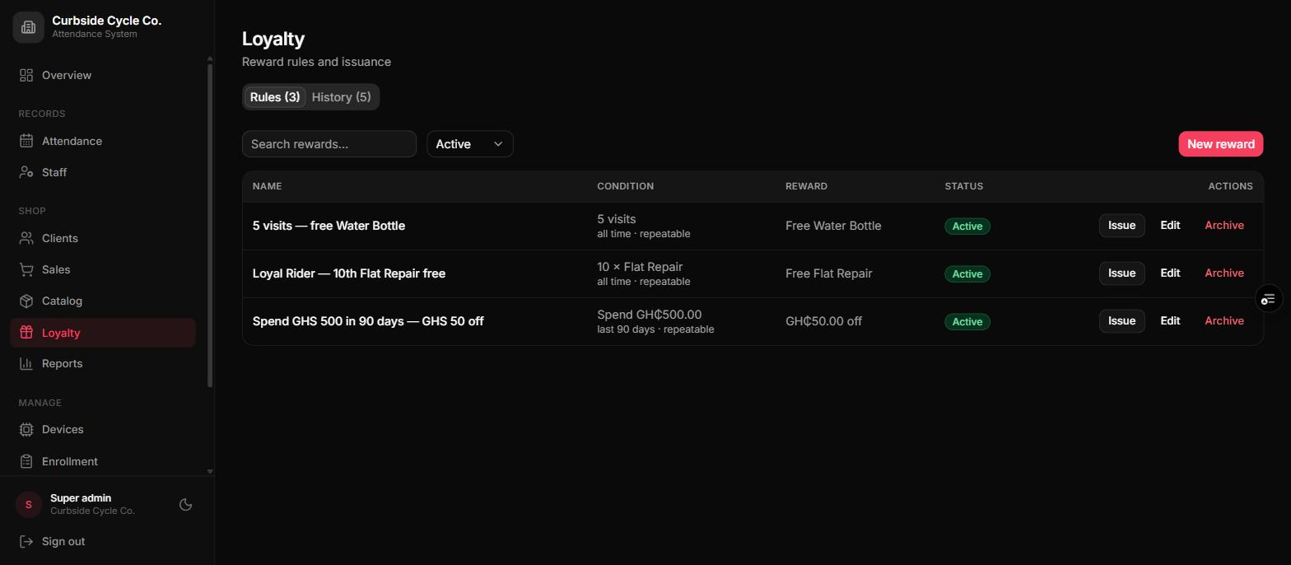
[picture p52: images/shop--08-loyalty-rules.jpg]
Loyalty -> Rules: each rule's condition and reward.


### 7.1 Building a rule

Press **New reward** and fill in three parts.

**Name** -- write it the way you'd say it, e.g. *Free wash every 10 retwists*.

**Condition -- when is it earned?**

<!-- cols: 32 68 -->
| Count | Meaning |
| --- | --- |
| **Number of services** | Service lines sold -- optionally one particular service. |
| **Number of products** | Product lines sold -- optionally one particular product. |
| **Number of visits** | Days the client came in. |
| **Total amount spent** | Money spent, in your currency. |

Then set the target number and the **Counting window**:

- **Since last reward issued (punch-card)** -- the usual choice. The count starts again each time they earn it.
- **All time** -- counts their whole history.
- **Rolling window (days)** -- counts only the last so many days.

Leave **Repeatable (resets and can be earned again)** ticked so regulars can earn it again and again.

**Reward -- what do they get?** A **Free service**, a **Free product**, a **Discount** of a fixed amount, or **Custom** -- any reward described in words.
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

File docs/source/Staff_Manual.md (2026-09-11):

# Staff Manual
:kicker: Role guide
:subtitle: Checking attendance and the roster for your class, team, or department
:audience: Teachers, supervisors, and staff with a read-only dashboard account
:version: Version 3.0 | September 2026
:accent: #0369a1
:series: staff
:output: clients

<<<TOC>>>

## 1. At a glance
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

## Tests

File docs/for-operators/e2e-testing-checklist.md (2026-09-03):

# E2E Testing Checklist

Tests to run after applying all migrations, deploying edge functions, and flashing new firmware.
Mark each ✅ as it passes. Tests are grouped by area and ordered by dependency.

---

## 1. Device auth & revocation (T1e, T11)

- [ ] **New provisioning:** factory-reset a device (clear SPIFFS), power on → serial logs show
  `"No device identity found"` → registers → polls → receives `device_secret` (not the shared
  institution secret). Confirm `devices.device_secret IS NOT NULL` in Supabase.

- [ ] **Per-device scan auth:** scan a finger → check Supabase `attendance` table. Record should
  have `device_id` set to the device's UUID (not null).

- [ ] **Revoke device:** set `devices.revoked = true` for the device. Scan a finger. Edge function
  should return 401 and the scan must NOT appear in `attendance`.

- [ ] **Decommission durability (T11):** insert a row in `device_resets` for the device.
  Wait for `get-enrollment-job` poll. Verify the device wipes identity and reboots. Power-cycle
  and observe the device re-registers. Confirm `device_resets` row still exists (not deleted on
  read) — a second poll before re-registration should still return `decommissioned: true`.

- [ ] **Legacy fallback path:** a device running old firmware (no `device_id` in payload) with
  the institution's shared secret should still log attendance successfully during the transition
  period.

---

## 2. SPIFFS queue durability & race (T2, T12)

- [ ] **Offline queue:** disconnect WiFi (or block with a bad SSID), scan 3 fingers. Reconnect.
  Verify all 3 scans appear in `attendance` within the next flush interval (≤15 s).

- [ ] **Crash recovery:** scan a finger → immediately cut power while the green LED is on.
  Restore power. Verify `queue_inflight.txt` is not present in SPIFFS (merged on boot) and the
  scan eventually reaches `attendance`.

- [ ] **Concurrent append:** scan two fingers in quick succession (< 500 ms apart). Verify both
  arrive in `attendance` with correct `scan_id` (no duplicate, no lost record).

- [ ] **FingerprintTask writes before network:** confirm in serial log that `"[queue] Persisted
  to SPIFFS"` appears **before** `"flushQueue: sent OK"` for every scan.

- [ ] **QUEUE_MAX_SPIFFS_ENTRIES cap:** queue more than `QUEUE_MAX_SPIFFS_ENTRIES` records
  offline. On reconnect, verify the oldest are dropped and the cap is logged as
  `"flushQueue: cap enforced"`.

---

## 3. Tenant isolation & RBAC (T4, T5, T6, T20)

- [ ] **Cross-tenant scan rejection:** POST a log-attendance request with a valid `device_id`
  from institution A but a member `sid` from institution B. Verify the edge function returns
  a non-200 (member not found in scope).

- [ ] **update-enrollment-job scoping (T4):** submit an enrollment update for a member in
  institution B using a device from institution A's `device_secret`. The edge function should
  reject (403 or 404 — device not found with that secret).

- [ ] **Staff page visibility (T20):** log in as a `teacher` role user. Navigate to `/staff`.
  Should redirect to `/unauthorized` or return 403 — teachers must not see the staff list.

- [ ] **Admin route gate (T5):** log in as a `teacher`. Attempt to navigate to `/devices`,
  `/users`, `/institutions`, `/enrollment`, `/onboarding`. Each should redirect to
  `/unauthorized`.

- [ ] **check-rbac.mjs passes:** run `node scripts/check-rbac.mjs` from the `frontend/`
  directory. Should exit 0 with no ungated pages reported.

- [ ] **resolveInstitutionScope (T6):** as a non-platform user with no `institution_id`, any
  page calling `resolveInstitutionScope` should redirect to `/unauthorized` rather than
  querying with a null institution filter.

---

## 4. Polling watermark (T3f, T3p, T16)

- [ ] **Watermark trigger:** make a change (add attendance record, update a member). Verify
  `institution_activity.last_change_at` is updated for that institution.

- [ ] **No spurious refresh:** open the dashboard. Wait 30 s with no changes. Verify no
  unnecessary `router.refresh()` calls (check browser network tab — no `/api/changes`
  follow-up refetch cascade).

- [ ] **Refresh on change:** make a change in a second tab. Within 12 s the first tab should
  refresh and display the updated data.

- [ ] **410 tombstone:** GET `/api/realtime-stream`. Should return HTTP 410 with body
  `"Gone — use /api/changes"`.

- [ ] **Realtime cleanup (T16):** confirm `members`, `devices`, `periods`, `attendance`,
  `holidays` are no longer in the `supabase_realtime` publication. `enrollment_jobs` should
  still be present (enrollment-stream uses it).

---

## 5. mark-absent cron (T15)

- [ ] **Batch concurrency:** with ≥9 institutions in the database, trigger `mark-absent` manually
  with the `x-cron-secret: <CRON_SECRET>` header (Kong strips `Authorization` before it reaches
  the function — a Bearer token returns 401). Verify serial/log output shows batches of 8
  processed concurrently, not sequentially one-by-one.

- [ ] **Absent records created:** after a period ends with no attendance, verify absent records
  appear in `attendance` for enrolled members.

- [ ] **Idempotency:** run `mark-absent` twice for the same period. Absent records should not
  be duplicated (the function should skip already-marked members).

---

## 6. Onboarding & UX (T17, T18, T21, T22, T23)

- [ ] **Timezone (T17):** create a new institution via onboarding with timezone set to
  `Africa/Lagos`. Verify `institutions.timezone = 'Africa/Lagos'` in Supabase.

- [ ] **Shop labels (T18):** create a `shop` type institution. Verify the `label_member` is
  `'Customer'` (or the configured neutral label) and NOT `'Student'`.

- [ ] **Forgot password (T21):** on the login page, verify "Forgot your password?" text with a
  `mailto:sgariba21@gmail.com` link is visible and opens the mail client when clicked.

- [ ] **Password whitespace (T22):** create a password that starts with a space (e.g.
  `" MyPassword"`). Verify login succeeds — the password is NOT trimmed before submission.

- [ ] **Low-stock warning (T23):** sell a product that has `stock = 1`. After the
  sale, the dialog should stay open and show a warning about negative/zero stock. Clicking
  "Close" dismisses it. The sale record IS created despite the warning. (This warning was
  silently dead until the rewards-redemption pass — the query selected a nonexistent
  `stock_quantity` column instead of `stock`; confirm it now actually fires.)

---

## 7. Firmware (T9, T14)

- [ ] **Identity race (T9):** on a newly-provisioned device, scan a finger immediately after
  the green "assigned" LED blink. The attendance record should correctly carry the new
  `institution_id`, not an empty string. (Tests the compiler barrier before
  `pendingAssignment = false`.)

- [ ] **OTA jitter (T14):** power-cycle 3 devices simultaneously. Check serial logs — each
  should print `"OTA: boot jitter Xms"` with a different value. Verify no device gets HTTP
  429 from GitHub.

- [ ] **OTA no-downgrade:** set `OTA_REPO_API` to point to a release with an older version
  tag. Verify the device prints `"OTA: No newer firmware available."` and does NOT flash.

---

## 8. Teacher scoping (T8)

- [ ] **FK path:** for a teacher with `assigned_device_id` set (backfilled by migration
  `20260628120100`), the attendance page should show only records from that device's group.

- [ ] **String-match fallback:** for a teacher with `assigned_device_id = null` but a valid
  `assigned_unit` string, the attendance page should still filter correctly via the
  group/unit name match.

- [ ] **No device assigned:** for a teacher with neither FK nor string match, the attendance
  page should show an empty state message: "Your account isn't assigned to a unit yet —
  contact your administrator."

---

## 9. Enrollment (T4f)

- [ ] **Wrong institution:** attempt to enroll a member whose `institution_id` doesn't match
  the device's institution. The enrollment action should return an error before writing to
  the sensor.

- [ ] **Inactive member:** attempt to enroll a member with `status != 'active'`. Should be
  rejected with a clear error message.

- [ ] **Device mismatch:** attempt to enroll a member assigned to device A using device B's
  enrollment job. Should be rejected.

---

## 10. Rewards redemption (applies migrations `20260823150417_rewards_redemption_link`, `20260823150444_create_sale_fn_v2`, `20260823150629_create_sale_revoke_public`, `20260823152205_create_sale_fn_atomic_redeem_guard`, `20260823152412_rewards_log_enforce_non_repeatable`)

- [ ] **Free service, existing line:** build a rule a client has already earned (e.g. visit
  count). Open Sales, pick that client, add the target service to the cart at its normal
  price, then press **Apply** on the offer. The line's price should zero out and lock —
  quantity and price fields become uneditable, catalog select becomes uneditable.

- [ ] **Free service, no existing line:** same as above but do NOT add the service first.
  Apply should add a new locked line at qty 1 / price 0.

- [ ] **Undo:** after Apply (either path above), press **Undo**. A line that existed before
  should return to its original editable price; a line Apply added should disappear entirely.

- [ ] **Discount:** apply a discount-kind reward. Verify the footer shows "Subtotal X − reward Y"
  above the final total, and the final total is subtotal minus the reward value (never below
  zero if the reward exceeds the subtotal).

- [ ] **Custom reward:** apply a custom-kind reward. Verify its description text is appended to
  the sale Note field.

- [ ] **Record the sale.** After submit, confirm in Supabase:
  - `transactions.discount_total` matches the discount applied (0 if none).
  - `transaction_items` for the free line has `reward_id` set to the reward's id and
    `unit_price = 0`.
  - `rewards_log` has a new row (or an existing row updated) with `transaction_id` set to the
    new transaction's id.

- [ ] **Reward disappears after redemption:** reopen Sales for the same client. The
  just-redeemed reward should no longer appear as an offer (unless the client re-earned it).

- [ ] **Pending / IOU redemption:** issue a reward standalone from the Clients page (not via a
  sale) so `rewards_log.transaction_id` is null. Open Sales for that client — the offer should
  appear labelled "already earned." Apply and record a sale. Confirm the SAME `rewards_log` row
  got `transaction_id` set (no duplicate row was created).

- [ ] **Double-redeem guard:** attempt to redeem the same pending IOU from two sales in quick
  succession (two browser tabs, or two rapid submits). Only one should succeed; the second
  should fail with a clear error, not silently double-write.

- [ ] **Losing a redemption race doesn't still charge the discount (bug fix):** this is the
  scenario the guard above exists to prevent — confirm specifically that the FAILED sale in that
  test was not recorded at all (no `transactions` row, no stock decrement), not just that the
  reward wasn't double-attached. Before the fix, the losing side's sale still completed at the
  discounted price even though its reward redemption silently failed to attach.

- [ ] **Non-repeatable reward can't be double-granted (bug fix):** for a non-repeatable reward,
  fire two `issueReward` calls for the same client in quick succession (two tabs on the Clients
  Loyalty dialog). Only one should succeed; the second should get a clear "already issued"
  error, not a second `rewards_log` row.

- [ ] **Sales panel hides an offer whose catalog target is archived (bug fix):** build a
  free_product/free_service reward, have a client earn it (fresh eligibility, or issue it
  standalone so it's pending), then archive the target product/service in Catalog. Reopen Sales
  for that client — the offer should NOT appear, in neither the freshly-eligible nor the
  "already earned" list. Un-archive the item and confirm it reappears.

- [ ] **Sales panel hides a pending IOU whose rule was archived (bug fix):** issue a reward
  standalone (pending, unredeemed), then archive the reward rule itself in Loyalty. Reopen Sales
  for that client — the IOU should not appear. It should still count toward Reports' Outstanding
  figure even while hidden from the till.

- [ ] **Cashier can issue and apply:** log in as a `cashier` role user. Confirm they can press
  "Issue reward" from the Clients page Loyalty dialog, and Apply a reward in Sales — both
  without an admin.

- [ ] **Ineligible client blocked:** attempt to issue a reward (via the Rules-tab Issue dialog)
  to a client who has NOT earned it. That client should not appear in the picker at all.

- [ ] **Rolling-window repeatable rule doesn't over-issue (bug fix):** build a repeatable
  `rolling_days` rule (e.g. "spend 500 in any 30 days"). Have a client hit the threshold once,
  issue it, then confirm they read as NOT eligible again the same day, even though the
  qualifying spend is still inside the 30-day window. They should only become eligible again
  after NEW spend past the issuance date.

- [ ] **Reports — redeemed vs outstanding:** after a mix of redeemed and standalone (unredeemed)
  issuances, open Reports → Rewards. Confirm the Redeemed and Outstanding columns match reality,
  and the outstanding-count badge above the table is correct.

---

## 11. Tracked weekdays, time format & punctuality (migration `20260830120000`)

- [ ] **Tracked weekdays:** in Settings, deselect Wed from "Days tracked" and save. Scan on a
  Wednesday → verify no attendance row is written and `mark-absent` creates no rows for that
  Wednesday. Re-select Wed and confirm normal behaviour returns.

- [ ] **Weekend tracking:** select Sat + Sun in "Days tracked". Verify scans and absences are
  generated on the weekend (the old skip_weekends special-case is gone).

- [ ] **Time display:** set Settings → Time display to 12-hour. Verify attendance times and the
  recent-scans feed render as `1:30 PM`; confirm the CSV export still contains 24-hour `HH:MM:SS`.

- [ ] **Late arrival:** enable "Flag late arrivals", set an expected start time and a grace
  window. A scan after `start + grace` gets `attendance.punctuality = 'late'` and a **Late**
  badge; a scan before it reads `on_time` with no badge. A `mark-absent` placeholder leaves
  `punctuality` NULL.

- [ ] **Early departure:** enable "Flag early departures" for a member type on Time In / Time Out
  mode. A `time_out` scan before `end - grace` gets `punctuality = 'early_leave'` and an
  **Early** badge. Confirm it is inert for a Present / Absent member type.

## 12. Enrollment job reliability (migrations `20260902120000`, `20260902130000`)

- [ ] **member_id rename:** create a register job. Confirm `enrollment_jobs.member_id` is set
  (not `student_id`) and the device (firmware ≥ 1.10.0) enrolls the correct member.

- [ ] **Occupied-slot refusal:** target a sensor slot that physically holds a template but reads
  as free server-side. With `allow_overwrite = false` the device refuses and reports `failed`
  with a `last_error`. Re-dispatch with the overwrite confirmation checked → it enrols.

- [ ] **Stuck-job self-heal:** dispatch a job, then kill the device before it POSTs
  `update-enrollment-job`. Verify `get-enrollment-job` re-delivers the job after the timeout,
  `attempts` increments, and after the cap the job is auto-failed with `last_error`.

- [ ] **Status guard:** once a job is `completed` / `failed`, a late `update-enrollment-job`
  write (or a raced `in_progress` write) does not move it back — the terminal status sticks,
  but `note` / `fid` / `last_error` still update.

- [ ] **Dashboard retry / cancel:** on a failed or stuck row on `/enrollment`, use **Retry** and
  **Cancel** and confirm each does what it says.

## 13. Installable PWA (`app/manifest.ts`, `public/sw.js`, `proxy.ts`)

- [ ] **Manifest reachable unauthenticated:** logged out, GET `/manifest.webmanifest` and
  `/sw.js` → both return 200 (not a 307 to `/login`).

- [ ] **Install prompt:** in Chrome/Edge, load the dashboard and confirm the in-app "Install
  app" affordance appears and installs to the home screen / desktop.

- [ ] **No stale caching:** after installing, deploy a change and reopen the installed app →
  the new version loads (the service worker never caches; `/sw.js` is served `no-cache`).

---

*Last updated: 2026-09-03. Run this checklist on each significant release.*

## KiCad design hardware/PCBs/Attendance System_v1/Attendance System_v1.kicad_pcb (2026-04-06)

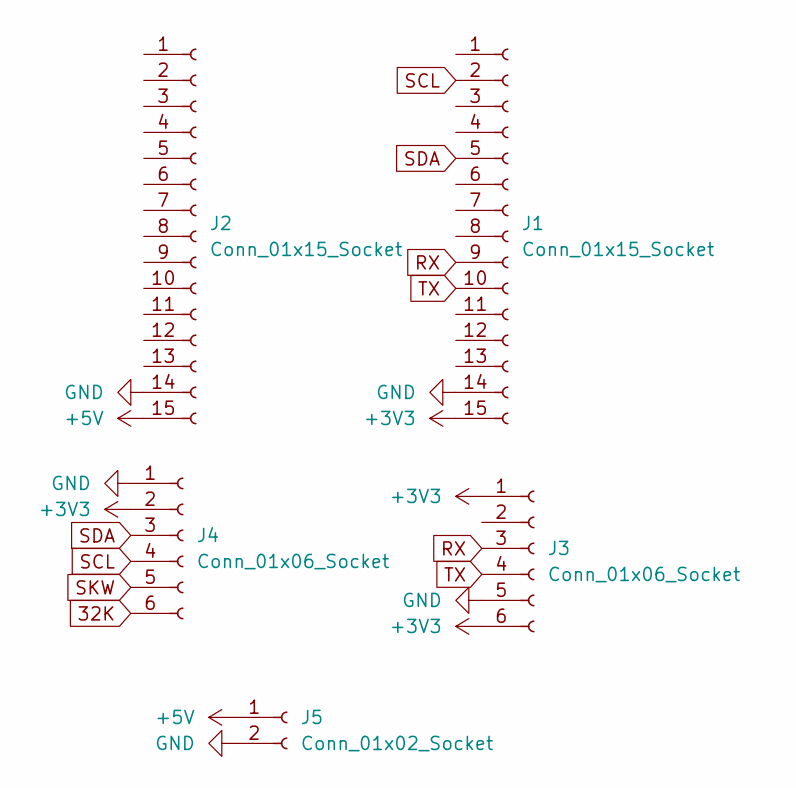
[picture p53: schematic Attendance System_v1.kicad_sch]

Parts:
J1, J2: Conn_01x15_Socket; PinSocket_1x15_P2.54mm_Vertical
J3: Conn_01x06_Socket; JST_SH_BM06B-SRSS-TB_1x06-1MP_P1.00mm_Vertical
J4: Conn_01x06_Socket; PinSocket_1x06_P2.54mm_Vertical
J5: Conn_01x02_Socket; JST_GH_BM02B-GHS-TBT_1x02-1MP_P1.25mm_Vertical

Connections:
32K: J4.6
+3V3: J1.15, J3.1, J3.6, J4.2
+5V: J2.15, J5.1
GND: J1.14, J2.14, J3.5, J4.1, J5.2
RX: J1.9, J3.3
SCL: J1.2, J4.4
SDA: J1.5, J4.3
SKW: J4.5
TX: J1.10, J3.4

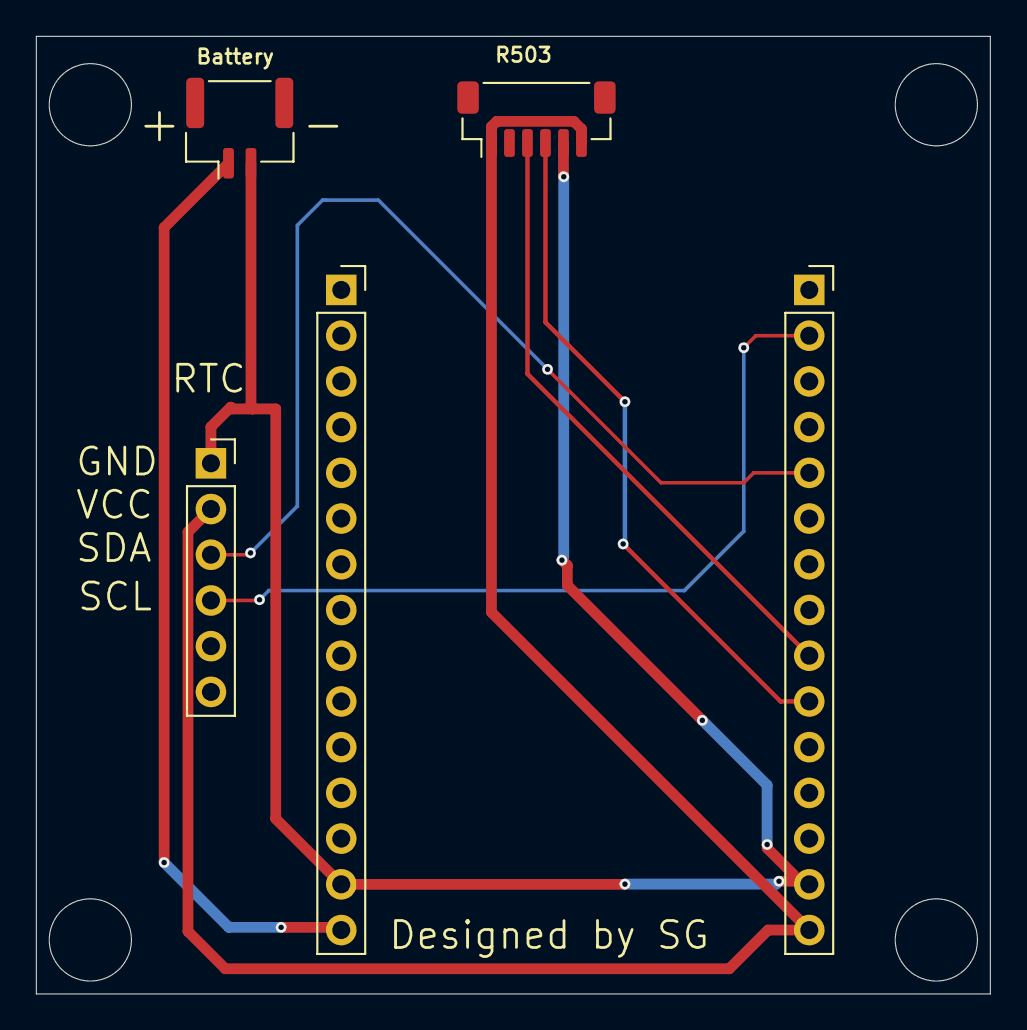
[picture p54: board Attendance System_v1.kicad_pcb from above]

Board: 2 copper layers, 53.0 x 53.2 mm, 5 parts (0 on the bottom side), 7 nets.

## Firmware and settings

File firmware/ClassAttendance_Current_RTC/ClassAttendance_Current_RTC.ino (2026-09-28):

/*
  ESP32 Attendance client — R503 fingerprint edition (dual-core optimized)
  WITH enrollment polling + master-triggered enrollment mode + fid mapping in SPIFFS
  (LED: fingerprint-only feedback — green/red briefly)

  Device identity (device_id, institution_id, device_secret, display_name) is
  provisioned at runtime via /register → /assignment-poll, then stored in SPIFFS.
  No compile-time class/institution coupling.
*/

/* ========= CONFIG ========== */

// Cloud Supabase edge function endpoints (same URL for every institution)
const char* SUPABASE_URL        = "https://lxpemewonievaazboyez.supabase.co/functions/v1/log-attendance";
const char* ENROLL_GET_URL      = "https://lxpemewonievaazboyez.supabase.co/functions/v1/get-enrollment-job";
const char* ENROLL_UPD_URL      = "https://lxpemewonievaazboyez.supabase.co/functions/v1/update-enrollment-job";
const char* REGISTER_URL        = "https://lxpemewonievaazboyez.supabase.co/functions/v1/register";
const char* ASSIGNMENT_POLL_URL = "https://lxpemewonievaazboyez.supabase.co/functions/v1/assignment-poll";

// Bootstrap secret (x-bootstrap-secret, used only on /register + /assignment-poll)
// and the TLS root CA bundle now live in separate per-deployment headers kept OUT
// of source control / filled before flashing:
//   secrets.h → #define BOOTSTRAP_SECRET "..."      (rotated; matches Supabase env)
//   certs.h   → const char* ROOT_CA_BUNDLE = "..."  (TLS certificate validation, C4)
// See secrets.example.h and certs.h for setup instructions.
#include "secrets.h"
#include "certs.h"

// SPIFFS file written by NetworkTask after dashboard assignment
#define DEVICE_IDENTITY_FILE "/device_identity.json"
// SPIFFS file holding device_id + provisioning_token while awaiting assignment (H7),
// so a reboot during the pending window does not lose the token.
#define PROVISIONING_FILE "/provisioning.json"
// Per-institution device_config cache (Phase 2 OLED), so scan-card rendering (and
// later the idle clock) survives a reboot without WiFi. Written atomically: to the
// .tmp path first, then renamed over the live file -- same idiom flushQueue uses
// for the identical partial-write risk. See loadDeviceConfig()/saveDeviceConfig().
#define DEVICE_CONFIG_FILE     "/device_config.json"
#define DEVICE_CONFIG_TMP_FILE "/device_config.tmp"
// Club mode (1.11.0): this device's ad-hoc meeting, so a reboot mid-meeting
// (or offline) keeps it open. Same tmp-then-rename write as device_config.
#define MEETING_STATE_FILE     "/meeting_state.json"
#define MEETING_STATE_TMP_FILE "/meeting_state.tmp"

/* ========= OTA CONFIG ========= */
#define FIRMWARE_VERSION  "1.11.0"        // increment on each flash (1.11.0: club mode -- session-master finger opens/closes ad-hoc meetings, offline too; NO MEETING verdict)
#define OTA_REPO_API      "https://api.github.com/repos/sgariba21-beep/esp32-attendance-device/releases/latest"
#define OTA_TAG_PREFIX    "firmware-v"    // was "OLAG-v" before Phase 3
/* ============================== */

/* Fingerprint UART pins */
#define R503_RX_PIN 16
#define R503_TX_PIN 17
#define R503_BAUD   57600

/* LED control constants */
#define FINGERPRINT_LED_OFF       0x00
#define FINGERPRINT_LED_ON        0x01
#define FINGERPRINT_LED_FLASHING  0x02
#define FINGERPRINT_LED_BREATHING 0x03

#define FINGERPRINT_LED_RED    0x01
#define FINGERPRINT_LED_BLUE   0x02
#define FINGERPRINT_LED_PURPLE 0x03
#define FINGERPRINT_LED_GREEN  0x04
#define FINGERPRINT_LED_WHITE  0x06
#define FINGERPRINT_LED_YELLOW 0x05

/* Constants */
#define MAX_FID 127
#define SCAN_COOLDOWN_MS 60000UL
#define ENROLL_POLL_MS 10000UL
#define ENROLL_POLL_FAST_MS 2000UL
#define QUEUE_FILE         "/queue.txt"
#define QUEUE_INFLIGHT_FILE "/queue_inflight.txt"  // T2/T12: rotate-then-process
#define FID_MAP_FILE "/fid_map.csv"   // fid,uniqueId,role,name
#define WIFI_CREDS_FILE "/wifi_creds.json"
#define AP_SSID  "Attendance-Setup"
#define AP_PASS  "setup1234"
#define DNS_PORT 53
#define QUEUE_MAX_ENTRIES   200
#define QUEUE_MAX_AGE_MS    (7UL * 24 * 3600 * 1000)
#define QUEUE_MAX_SPIFFS_ENTRIES      1000
#define QUEUE_MAX_SPIFFS_BYTES        (256UL * 1024UL)
#define QUEUE_SPIFFS_TRIM_INTERVAL_MS (5UL * 60UL * 1000UL)

#define SCAN_LOG_FILE "/scan_log.txt"
#define SCAN_LOG_MAX_BYTES (200UL * 1024UL)

/* SSD1306 OLED (Phase 3). Same I2C bus as the DS3231 RTC (0x68) -- no address
 * clash at 0x3C. Display owner is Core 1 (FingerprintTask) only; see
 * renderDisplayIfDirty(). */
#define SCREEN_WIDTH  128
#define SCREEN_HEIGHT 64
#define OLED_ADDR     0x3C
#define DISPLAY_SLEEP_MS (120UL * 1000UL)

/* ============ END CONFIG ================ */

#include <WiFi.h>
#include "esp_wifi.h"
#include <WiFiClientSecure.h>
#include <HTTPClient.h>
#include <SPIFFS.h>
#include <time.h>
#include <vector>
#include <string>
#include <Adafruit_Fingerprint.h>
#include <Wire.h>
#include <RTClib.h>
#include <Adafruit_GFX.h>
#include <Adafruit_SSD1306.h>
#include <WebServer.h>
#include <DNSServer.h>
#include "esp_task_wdt.h"
#include <Update.h>
#include <ArduinoJson.h>

#include "freertos/FreeRTOS.h"
#include "freertos/task.h"
#include "freertos/semphr.h"

RTC_DS3231 rtc;
Adafruit_SSD1306 display(SCREEN_WIDTH, SCREEN_HEIGHT, &Wire, -1);

HardwareSerial r503Serial(2);
Adafruit_Fingerprint finger = Adafruit_Fingerprint(&r503Serial);

/* Synchronisation primitives */
// memQueueMutex removed (T2/T12): SPIFFS is now the sole queue; spiffsMutex guards it.
SemaphoreHandle_t memQueueSem   = NULL;  // binary signal: FingerprintTask → NetworkTask
SemaphoreHandle_t spiffsMutex   = NULL;
SemaphoreHandle_t enrollMutex   = NULL;
SemaphoreHandle_t enrollSem     = NULL;
SemaphoreHandle_t displayMutex  = NULL;  // guards displayName + the tier table below (Phase 3 OLED)

String wifiSSID = "";
String wifiPASS = "";

/* Runtime device identity — populated from SPIFFS or provisioning poll */
String deviceId      = "";
String institutionId = "";
String deviceSecret  = "";
String displayName   = "";
String provisioningToken = "";            // H7: required by /assignment-poll before secret release
volatile bool pendingAssignment = false;  // true until dashboard assigns this device

/* Per-institution device_config cache (Phase 2 OLED) — loaded from SPIFFS before any
 * task starts. Governs attendance-scan card rendering only; member names are already
 * in fid_map.csv regardless. See loadDeviceConfig()/saveDeviceConfig(). */
String deviceConfigNameDisplay = "first";  // compile-time default until a valid cache file overrides it
long   deviceConfigRevOnDisk   = 0;        // rev actually persisted to flash, not any pending value; 0 = never persisted (always "stale" to the server)
int    deviceConfigTzOffset    = 0;        // minutes east of UTC; refreshed on every poll response

/* ---- Display state mailbox (Phase 3 OLED) ----
 * NetworkTask/EnrollmentTask (Core 0) post/clear tier state here through
 * postDisplayState()/clearDisplayState() -- they never touch `display`
 * directly. FingerprintTask (Core 1) is the sole reader+drawer, via
 * renderDisplayIfDirty(). Guarded by displayMutex; tier 0 = highest priority.
 * Idle (TIER_IDLE) is always active as the base state so resolution never
 * lands on "nothing". */
enum DisplayTier {
  TIER_TAKEOVER    = 0,  // fatal init, captive portal, OTA, sensor missing -- exclusive, never sleeps
  TIER_INTERACTION = 1,  // enrollment prompts/outcomes, scan outcomes, master confirm -- timeboxed
  TIER_BLOCKED     = 2,  // awaiting assignment, provisioning error, decommissioned -- never sleeps
  TIER_DEGRADED    = 3,  // offline+queue depth, clock unsynced, dropped-record count -- banner over idle
  TIER_IDLE        = 4,  // clock, display name, link state -- always active as the fallback
  TIER_COUNT       = 5
};

// Phase 6: which Tier 2 (Blocked) state is currently posted, if any. Defined
// here (not next to setBlockedReason() itself, further down) so it's visible
// to that function's forward declaration in the block below.
enum BlockedReason { BLOCKED_NONE, BLOCKED_PENDING, BLOCKED_REJECTED, BLOCKED_REVOKED };
bool          displayAvailable      = false;  // false if SSD1306 init failed -- no hard dependency on the panel
volatile bool tierActive[TIER_COUNT]     = { false, false, false, false, true };
unsigned long tierExpiresAtMs[TIER_COUNT] = { 0, 0, 0, 0, 0 };  // 0 = no expiry
// Card content (Phase 4 OLED): headline is size-2 text, line2/line3 are size-1.
// Only TIER_INTERACTION has a poster so far (scan cards); tiers 0/2/3 remain
// content-less infrastructure until Phase 5/6.
String        tierHeadline[TIER_COUNT];
String        tierLine2[TIER_COUNT];
String        tierLine3[TIER_COUNT];
volatile bool displayDirty          = true;   // forces the first render once FingerprintTask starts
volatile bool displayAsleep         = false;
volatile bool displayWakeRequested  = false;  // set by any core; only Core 1 issues the actual I2C wake command
unsigned long displayLastActivityMs = 0;
unsigned long lastIdleRenderMs      = 0;

// Verdict channel (Phase 4): NetworkTask (Core 0, flushQueue) deposits the
// server's verdict for a scan_id here; FingerprintTask (Core 1) picks it up
// only if it matches the scan_id it's currently watching (pendingScanId,
// Core-1-exclusive, declared near FingerprintTask). Single slot -- flushing a
// backlog of dozens of records after a reconnect just overwrites this
// repeatedly, and the consumer ignores every one that doesn't match what it's
// actively waiting on. That's the entire batch-flush suppression mechanism;
// no special-case "am I in a batch" detection needed.
volatile bool verdictPending = false;
String        verdictScanId  = "";
String        verdictText    = "";

// Queue depth + dropped-record count (Phase 6 OLED) -- in-RAM only, never
// recomputed by counting SPIFFS lines on repaint. Written from Core 0
// (queueAndSignal is Core 1 via FingerprintTask, but flushQueue/
// trimSPIFFSQueue_locked run on NetworkTask, Core 0; trimSPIFFSQueue_locked
// can ALSO run on Core 1 when called from queueAndSignal's near-cap path) and
// read from Core 1 for the offline banner -- mutex-protected like everything
// else that crosses cores here. droppedRecordCount counts actual data loss
// only (stale-aged-out, permanently-failed, or cap-evicted entries), never
// successful sends.
long queueDepth         = 0;
long droppedRecordCount = 0;

// Device MAC (Phase 6): the dashboard's key for identifying an unassigned
// device, so the awaiting-assignment/rejected screens can show it. Populated
// once in setup() after WiFi.mode(WIFI_STA), Core-1-exclusive (single-
// threaded at that point) -- read-only from everywhere else afterward, so no
// mutex needed for reads either.
String deviceMac = "";

TaskHandle_t hFingerprint = NULL;
TaskHandle_t hNetwork     = NULL;
TaskHandle_t hEnrollment  = NULL;

std::vector<String> fidMap;
std::vector<String> fidMapRole;
std::vector<String> fidMapName;

struct EnrollJob {
  String id;
  String memberId;
  String uniqueId;
  String name;
  String fingerSlot;
  String command;
  int    requestedFid;
  bool   allowOverwrite;   // operator approved clobbering an occupied sensor slot
};
volatile bool enrollmentJobPending = false;
EnrollJob currentEnrollJob;

volatile bool otaInProgress = false;

static unsigned long lastScanMillis[MAX_FID + 1];
static bool fidEverScanned[MAX_FID + 1];

/* Pending-scan verdict watch (Phase 4 OLED) -- Core-1-exclusive (FingerprintTask
 * is the only reader/writer), no mutex needed. Set when a scan is posted online;
 * checkScanVerdict() consumes the cross-core verdictPending mailbox (which IS
 * mutex-protected -- see the globals near the tier table) only when it matches
 * pendingScanId. */
String        pendingScanId         = "";
String        pendingScanName       = "";
unsigned long pendingScanStartMs    = 0;
unsigned long pendingScanDeadlineMs = 0;  // pendingScanStartMs + 4000 (the correlation window)

/* Master-finger confirmation state machine (Phase 5 OLED, Q5) -- also
 * Core-1-exclusive. Armed on a first master-role press; a second press of
 * the SAME fid within the window confirms and launches the portal, a
 * DIFFERENT fid cancels and falls through to normal processing for that new
 * fid, and no-match/sensor-error events are ignored entirely (never reach
 * this state since they're not fid>0 matches). Timeout is checked
 * unconditionally every loop iteration, not nested inside a scan match --
 * otherwise an armed-but-idle window would only ever resolve whenever the
 * next scan attempt happened to land, not at the actual 8s deadline. */
bool          masterConfirmArmed       = false;
int           masterConfirmFid         = -1;
unsigned long masterConfirmDeadlineMs  = 0;

/* ---- Club mode: ad-hoc meetings (1.11.0, CLUB-MODE-PLAN.md §8 B) ----
 * A "session_master" finger opens an ad-hoc meeting with one press and closes
 * it with a confirmed second press -- online or OFFLINE. The device names the
 * meeting itself (mtgRef) the moment it opens, and the open event, the close
 * event, and every scan taken during it all carry that ref + the open time
 * through the ordinary SPIFFS queue, so whichever reaches the server first
 * creates the meeting: replay order, retries and lost replies don't matter.
 * The device also applies the idle / midnight auto-close itself (the server
 * can't: it never sees scans still queued here) and reports that close with
 * the deadline's timestamp.
 *
 * mtg* and meetingClose* are Core-1-exclusive (FingerprintTask: presses,
 * scans, auto-close, reconcile, idle screen), persisted to MEETING_STATE_FILE.
 * srvMtg is the server's view from the latest poll, written by EnrollmentTask
 * (Core 0) under meetingMutex and folded in on Core 1 by
 * reconcileMeetingWithServer(). */
#define MEETING_CONFIRM_MS    8000UL
#define MEETING_LIVE_FRESH_MS 90000UL   // trust a poll's "live" meeting this long when offline-ish

bool     mtgOpen         = false;
String   mtgRef          = "";      // also kept after close: the last meeting's ref
uint32_t mtgOpenedEpoch  = 0;       // UTC epoch, RTC timebase
uint32_t mtgLastEpoch    = 0;       // last scan in it (or the open) -- the idle rule
bool     mtgAcked        = false;   // the server has reported it open at least once
uint32_t mtgSeen[4]      = { 0, 0, 0, 0 };  // fids 0..127 scanned in it -> "N present"
int      mtgClub         = -1;      // from the poll: -1 unknown, 0 not a club, 1 club
int      mtgAutocloseMin = 240;     // from the poll: institutions.meeting_autoclose_minutes

bool          meetingCloseArmed      = false;
int           meetingCloseFid        = -1;
unsigned long meetingCloseDeadlineMs = 0;

SemaphoreHandle_t meetingMutex = NULL;
struct ServerMeetingView {
  bool          valid;
  unsigned long atMs;             // millis() of the poll -- also the "new view" marker
  int           club;             // 1 / 0
  int           autocloseMin;
  String        openRef;          // this device's ad-hoc meeting the server has open
  uint32_t      openOpenedEpoch;
  bool          live;             // a meeting a scan would land in right now
  String        liveTitle;
  String        liveOrigin;       // "scheduled" | "device"
  uint32_t      liveEnds;         // epoch; 0 for an open ad-hoc meeting
};
ServerMeetingView srvMtg = { false, 0, 0, 240, "", 0, false, "", "", 0 };
unsigned long srvMtgAppliedAtMs = 0;  // Core 1: the view last reconciled

/* Forward declarations */
void showReadyState();
void setSensorLED(uint8_t mode, uint8_t speed, uint8_t color);
int fingerSearch();
String makeScanId(const String &id);
void queueAndSignal(const String &payloadJson);
bool initFS();
bool loadFidMapFromFS();
bool saveFidMapToFS();
int findFidByUnique(const String &uniqueId);
void clearAllFidMap();
int enrollID_toFid(const EnrollJob &job, int requestedFid);
void enrollment_doRegister(const EnrollJob &job, const String &role);
void enrollment_doDeleteByFid(const EnrollJob &job, int fid);
void enrollment_doDeleteByUnique(const EnrollJob &job);
void reportEnrollUpdate(const String &jobId, const String &status, int fingerId,
                        const String &note, const String &fingerSlot, const String &memberId);
bool initRTC();
void syncRTCFromNTP();
String getRTCTimestamp();
bool parsePayloadAgeSec(const String &payload, long nowEpoch, long &outAgeSec);
void trimSPIFFSQueue_locked();
bool appendToSPIFFSQueue_locked(const String &line);
void flushQueue();
static void recoverInflightQueue();
static void seedQueueDepthFromDisk();

// Durable enrollment status reports (Core 0 flush; Core 1 append on POST failure).
void flushEnrollReports();
static void appendEnrollReport_locked(const String &line);
// Server-reachability watchdog. postJSONToUrl()/postJSONBootstrap() feed
// markPostResult(); NetworkTask reads it to escalate (re-associate, reboot)
// and the idle screen reads it for the "No server" indicator.
void markPostResult(bool ok);
bool getServerReachableSafe();
void getNetHealthSafe(bool &reachable, int &fails, unsigned long &lastOkMs);

#define POST_MAX_RETRIES   3
#define POST_BASE_DELAY_MS 500
#define POST_TIMEOUT_MS    30000

// Server-reachability watchdog. The link can stay associated while every HTTPS
// call is refused (heap fragmentation, mbedTLS arena exhaustion, a filtering
// middlebox). Before this the device just showed "Online" and went silent
// until a power cycle.
#define NET_UNREACHABLE_FAILS   5                       // consecutive failed POSTs (link still up) => "no server"
#define NET_REASSOC_INTERVAL_MS 60000UL                 // while unreachable, force a WiFi re-associate this often
#define NET_REBOOT_AFTER_MS     (5UL * 60UL * 1000UL)   // unreachable this long on a live link => ESP.restart()
#define NET_MIN_LARGEST_BLOCK   30000UL                 // largest free heap block below this can't fit a TLS arena => reboot
#define ENROLL_REPORT_QUEUE_FILE "/enroll_reports.txt"
#define ENROLL_REPORT_MAX_BYTES  (16UL * 1024UL)

bool postJSONToUrl(const String &jsonPayload, const char* targetUrl, int &outHttpCode, String &outBody);
bool postJSONBootstrap(const String &jsonPayload, const char* targetUrl, int &outHttpCode, String &outBody);
// displayName is read from Core 1 (display) but written from Core 0
// (registerDevice/pollAssignment/EnrollmentTask) once tasks are running --
// every access after task creation goes through these two (Phase 3 OLED).
void setDisplayName(const String &name);
String getDisplayNameSafe();
// Same story for deviceConfigNameDisplay/TzOffset -- written from Core 0
// (saveDeviceConfig), read from Core 1 as of Phase 3 (tz offset) / Phase 4
// (name policy).
String getDeviceConfigNameDisplaySafe();
int getDeviceConfigTzOffsetSafe();
bool loadDeviceIdentity();
void saveDeviceIdentity();
bool registerDevice();
bool pollAssignment();
bool loadProvisioning();
void saveProvisioning();
void clearProvisioning();
bool loadDeviceConfig();
void saveDeviceConfig(long ver, long rev, int tzOffset, const String &nameDisplay);

// Display mailbox (Phase 3/4 OLED) -- Core-0-safe, never touch `display` directly.
void postDisplayState(DisplayTier tier, unsigned long timeboxMs,
                      const String &headline, const String &line2, const String &line3);
void clearDisplayState(DisplayTier tier);
void postScanVerdict(const String &entryPayload, bool ok, const String &body);
// Queue-depth/dropped-record bookkeeping and Tier 2 state (Phase 6 OLED) --
// also Core-0-safe.
void queueDepthAdjust(long delta);
void droppedCountAdjust(long delta);
void getQueueStatsSafe(long &depth, long &dropped);
void setBlockedReason(BlockedReason reason);
// Core-1-only (called from FingerprintTask).
void renderDisplayIfDirty();
void renderIdleScreen();
void renderCard(DisplayTier tier);
void showBootSplash();
void checkScanVerdict();
void checkMasterConfirmTimeout();
String resolveScanCardName(const String &name, const String &sid);
// UTF-8-to-CP437-safe text for the display font. Not Core-restricted itself
// (pure string transform, no I2C) -- Phase 4+ scan/enrollment cards should
// route member/enrollee names through this too.
String sanitizeForDisplay(const String &s);
String transliterateCodepoint(uint32_t cp);

/* ---------------- LED helpers ---------------- */

void setSensorLED(uint8_t mode, uint8_t speed, uint8_t color) {
  finger.LEDcontrol(mode, speed, color);
}

void setSensorLED(int mode) {
  if (mode == 1) { setSensorLED(FINGERPRINT_LED_ON,        0,  FINGERPRINT_LED_GREEN); return; }
  if (mode == 2) { setSensorLED(FINGERPRINT_LED_BREATHING, 25, FINGERPRINT_LED_GREEN); return; }
  if (mode == 3) { setSensorLED(FINGERPRINT_LED_BREATHING, 25, FINGERPRINT_LED_RED);   return; }
  setSensorLED(FINGERPRINT_LED_OFF, 0, 0);
}

void showReadyState() {
  if (WiFi.status() == WL_CONNECTED) {
    setSensorLED(FINGERPRINT_LED_ON, 0, FINGERPRINT_LED_BLUE);
  } else {
    setSensorLED(FINGERPRINT_LED_ON, 0, FINGERPRINT_LED_PURPLE);
  }
}

/* ================== WiFi Credentials (SPIFFS) ================== */
bool loadWiFiCreds() {
  if (!SPIFFS.exists(WIFI_CREDS_FILE)) return false;
  File f = SPIFFS.open(WIFI_CREDS_FILE, FILE_READ);
  if (!f) return false;
  String ssid = "", pass = "";
  while (f.available()) {
    String ln = f.readStringUntil('\n');
    ln.trim();
    if (ln.startsWith("ssid=")) ssid = ln.substring(5);
    else if (ln.startsWith("pass=")) pass = ln.substring(5);
  }
  f.close();
  if (ssid.length() == 0) return false;
  wifiSSID = ssid;
  wifiPASS = pass;
  return true;
}

void saveWiFiCreds(const String &ssid, const String &pass) {
  File f = SPIFFS.open(WIFI_CREDS_FILE, FILE_WRITE);
  if (!f) { Serial.println("Failed to write WiFi creds"); return; }
  f.println("ssid=" + ssid);
  f.println("pass=" + pass);
  f.close();
  Serial.println("WiFi credentials saved.");
}
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
void loop() {
  delay(1000);
}

/* =================== END OF SKETCH =================== */

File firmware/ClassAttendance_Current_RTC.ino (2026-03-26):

/* 
  ESP32 Attendance client — R503 fingerprint edition (dual-core optimized)
  WITH enrollment polling + master-triggered enrollment mode + fid mapping in SPIFFS
  (LED: fingerprint-only feedback — green/red briefly; treat HTTP 400 as success)
  
  IMPORTANT: Edit WIFI_SSID, WIFI_PASS, SCRIPT_URL, CLASS_ID, SCRIPT_AUTH before use.
*/

/* ========= CONFIG - EDIT THESE ========== */
// WiFi
const char* WIFI_SSID = "";
const char* WIFI_PASS = "";

// Central Apps Script endpoint (single router web app)
const char* SCRIPT_URL = "https://script.google.com/macros/s/AKfycbxg_Dj_i-JrmNfHblrzBaxaxzwWArAsgzKSz0QNhfjhltZmwSYiZqXgY8FqCJYatfVM4g/exec";

// If you set SCRIPT_AUTH_KEY in Apps Script, put the same string here; otherwise leave empty
const char* SCRIPT_AUTH = ""; // e.g. "supersecret"

// Device identity / class
const char* CLASS_ID   = "2-SCI-2";
const char* CLASS_NAME = "2 Science 2";

/* Fingerprint UART pins (change to your wiring) */
#define R503_RX_PIN 16  // to sensor TX
#define R503_TX_PIN 17  // to sensor RX
#define R503_BAUD   57600

/* LED fallbacks (same as your original) */
#define FINGERPRINT_LED_OFF       0x00
#define FINGERPRINT_LED_ON        0x01
#define FINGERPRINT_LED_FLASHING  0x02
#define FINGERPRINT_LED_BREATHING 0x03

#define FINGERPRINT_LED_RED       0x01
#define FINGERPRINT_LED_BLUE      0x02
#define FINGERPRINT_LED_PURPLE    0x03
#define FINGERPRINT_LED_GREEN     0x04
#define FINGERPRINT_LED_WHITE     0x05
#define FINGERPRINT_LED_YELLOW    0x06

/* Constants */
#define MAX_FID 127
#define SCAN_COOLDOWN_MS 60000UL  // minimum ms between accepted scans per finger
#define ENROLL_POLL_MS 10000UL  // normal poll interval
#define ENROLL_POLL_FAST_MS 2000UL  // fast poll interval after a job is found
#define ENROLL_MODE_TIMEOUT_MS 120000UL // 2 minutes enrollment mode if triggered by master
#define QUEUE_FILE "/queue.txt"
#define FID_MAP_FILE "/fid_map.csv" // csv lines: fid,uniqueId,role,name

/* ============ TEACHER ID-RANGE CONFIG ============ */
/* Edit these to match how you enroll teacher fingerprints.
   Example: if you enroll students as 1..40 and teachers as 41..60,
   set TEACHER_FID_START = 41 and TEACHER_FID_END = 60.
*/
const int TEACHER_FID_START = 41;
const int TEACHER_FID_END   = 60;

/* Provide teacher unique IDs that correspond to the fingerprint IDs
   in the range TEACHER_FID_START..TEACHER_FID_END in order.
   This array is a fallback initial mapping only; fid_map.csv persisted values will override.
*/
const char* TEACHERS_IDS_FALLBACK[TEACHER_FID_END - TEACHER_FID_START + 1] = {
  /* 41 -> */ "T001", "T002", "T003", "T004", "T005",
  /* 46 -> */ "T006", "T007", "T008", "T009", "T010",
  /* 51 -> */ "T011", "T012", "T013", "T014", "T015",
  /* 56 -> */ "T016", "T017", "T018", "T019", "T020"
};

/* Master FID as requested by you */
const int MASTER_FID = 99;

/* Student range (explicit for clarity): 1..40 */
const int STUDENT_FID_START = 1;
const int STUDENT_FID_END = 40;

/* ============ END CONFIG ================ */

/* Libraries */
#include <WiFi.h>
#include "esp_wifi.h"
#include <WiFiClientSecure.h>
#include <HTTPClient.h>
#include <SPIFFS.h>
#include <time.h>
#include <vector>
#include <deque>
#include <string>
#include <Adafruit_Fingerprint.h>
#include <Wire.h>
#include <RTClib.h>

/* FreeRTOS primitives */
#include "freertos/FreeRTOS.h"
#include "freertos/task.h"
#include "freertos/semphr.h"

/*RTC*/
RTC_DS3231 rtc;

/* Hardware serial for fingerprint */
HardwareSerial r503Serial(2);
Adafruit_Fingerprint finger = Adafruit_Fingerprint(&r503Serial);

/* Globals */
SemaphoreHandle_t memQueueMutex = NULL;
SemaphoreHandle_t memQueueSem = NULL;
SemaphoreHandle_t spiffsMutex = NULL;
SemaphoreHandle_t enrollMutex = NULL;
SemaphoreHandle_t enrollSem = NULL;

std::deque<String> memQueue; // in-memory queue for attendance payloads
std::vector<String> fidMap;  // index 0 unused; fidMap[fid] == uniqueId (or empty)
std::vector<String> fidMapRole; // role per fid
std::vector<String> fidMapName; // name per fid

// Enrollment job struct
struct EnrollJob {
  int row; // sheet row number
  int requestedFid;
  String uniqueId;
  String name;
  String role; // student|teacher|master
  String command; // register|delete|clearall
};
volatile bool enrollmentJobPending = false;
EnrollJob currentEnrollJob;

// Enrollment mode (master triggered)
volatile bool enrollmentMode = false;
volatile unsigned long enrollmentModeTs = 0; // millis when enrollment mode started

static unsigned long lastScanMillis[MAX_FID + 1];
static bool fidEverScanned[MAX_FID + 1];

/* Forward declarations */
void showReadyState();
void setSensorLED(uint8_t mode, uint8_t speed, uint8_t color);
int fingerSearch();
String makeScanId(const String &id);
void sendOrQueuePayload(const String &payloadJson);
bool initFS();
bool loadFidMapFromFS();
bool saveFidMapToFS();
int findFidByUnique(const String &uniqueId);
void clearAllFidMap();
void applyFidMapToSerialPrint();
int enrollID_toFid(int requestedFid);
void enrollment_doRegister(int requestedFid, const String &uniqueId, const String &name, const String &role, int rowToReport);
void enrollment_doDeleteByFid(int fid, int rowToReport);
void enrollment_doDeleteByUnique(const String &uniqueId, int rowToReport);
void reportEnrollUpdate(int row, const String &status, int fingerId, const String &note);
bool initRTC();
void syncRTCFromNTP();
String getRTCTimestamp();

/* Networking helpers (copied/kept similar to your original) */
#define POST_MAX_RETRIES 3
#define POST_BASE_DELAY_MS 500
#define POST_TIMEOUT_MS 30000

bool postJSONToUrl(const String &jsonPayload, const char* targetUrl, int &outHttpCode, String &outBody);
String urlEncode(const String &str);
bool sendGETFallback(const String &studentId, const String &date, const String &ts, int &outHttpCode, String &outBody);

/* ---------------- Implementation ---------------- */

void setSensorLED(uint8_t mode, uint8_t speed, uint8_t color) {
  finger.LEDcontrol(mode, speed, color);
}

void setSensorLED(int mode) {
  if (mode == 1) {
    setSensorLED(FINGERPRINT_LED_ON, 0, FINGERPRINT_LED_GREEN);
    return;
  }
  if (mode == 2) {
    setSensorLED(FINGERPRINT_LED_BREATHING, 25, FINGERPRINT_LED_GREEN);
    return;
  }
  if (mode == 3) {
    setSensorLED(FINGERPRINT_LED_BREATHING, 25, FINGERPRINT_LED_RED);
    return;
  }
  setSensorLED(FINGERPRINT_LED_OFF, 0, 0);
}

void showReadyState() {
  if (WiFi.status() == WL_CONNECTED) {
    setSensorLED(FINGERPRINT_LED_ON, 0, FINGERPRINT_LED_BLUE);
  } else {
    setSensorLED(FINGERPRINT_LED_ON, 0, FINGERPRINT_LED_PURPLE);
  }
}
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

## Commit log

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2026-04-01 Revert "Update ClassAttendance_Current_RTC.ino"
    This reverts commit 72d3cfd028bf54c16a1765b352a23133351c1976.
    [ClassAttendance_Current_RTC.ino]
2026-04-01 Add WiFi captive portal and network refactor
    Introduce a captive portal to provision WiFi credentials and persist them to SPIFFS; device will restart after saving. Added load/save helpers (WIFI_CREDS_FILE), a WebServer + DNSServer portal with a simple HTML UI, and startCaptivePortal() which suspends other tasks and serves until credentials are stored. Refactor network/enrollment flows to use runtime wifiSSID/wifiPASS (loaded from SPIFFS) instead of hardcoded WIFI_SSID/WIFI_PASS and launch the portal on first boot or when configuration is missing.
    Other notable changes: adjust HTTP timeouts/retry/backoff and improve error handling for POST/GET requests; remove local master enrollment mode an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
    [ClassAttendance_Current_RTC.ino]
2026-04-02 Don't start captive portal on WiFi failure
    Remove redundant calls to setupFingerprint() and startCaptivePortal() from the WiFi-failure branch in setup(). The captive portal is still launched when no credentials are present, but on a failed connection the device now remains in offline mode (allowing master finger scan to reconfigure) instead of immediately starting the blocking captive portal/restart sequence.
    [ClassAttendance_Current_RTC.ino]
2026-04-03 Remove teacher FID fallbacks and simplify mapping
    Remove hardcoded teacher/student fingerprint ID ranges and the TEACHERS_IDS_FALLBACK array so the device no longer seeds fid_map from built-in fallbacks. loadFidMapFromFS() now starts with an empty map when fid_map file is missing and logs that state. Added finger.getParameters() in setupFingerprint() and printout of sensor capacity. Simplified FingerprintTask handling for unmatched FIDs to a single warning/RED-LED flow instead of applying teacher/student fallback logic. This makes mapping explicit (persisted fid_map or external enrollment) and avoids implicit assumptions about teacher ID ranges.
    [ClassAttendance_Current_RTC.ino]
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2026-04-06 Enclosure Fixes
    [Fingerprint Device Enclosure-Base.stl, Fingerprint Device Enclosure-Lid.stl, Fingerprint Device Enclosure.FCStd]
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2026-04-06 Revert "OTA update test"
    This reverts commit 4b48d43435ffae8945baa305c59cd97876fde186.
    [partitions.csv]
2026-04-07 Revert "Added OTA update capability"
    This reverts commit 272f0477120192fd8942094a5a46edab4f23ea1d.
    [ClassAttendance_Current_RTC.ino]
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2026-04-27 add OTA firmware update support with variant-based release management
    - Add checkAndApplyOTA() called at boot after sensor and tasks are initialized
    - Fetch latest release from GitHub Releases API and compare against FIRMWARE_VERSION
    - Parse browser_download_url from API response to locate .bin asset
    - Resolve GitHub CDN redirect manually before binary download to avoid begin() failure
    - Split API call, redirect resolution, and binary download into separate scopes to
    prevent heap exhaustion from concurrent WiFiClientSecure instances (~21KB headroom
    was insufficient; scoped destruction recovers ~40-50KB before download begins)
    - Stream binary directly into Update.writeStream() without int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
    [ClassAttendance_Current_RTC.ino]
2026-05-05 Fixed occasional record loss on power cut
    -Persisted all scan records to SPIFFS even when online.
    -Also updated NetworkTask to call flushQueue() immediately it starts.
    [ClassAttendance_Current_RTC.ino]
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2026-06-12 Added subtle improvements to academic page
    formatDate replaced with formatDateRange — produces 3 Sep – 15 Dec 2024 (start year omitted when same as end year)
    Term and Year merged into one cell: Term 1 · 2024 with the year in muted text
    Active term indicator is now a bg-muted chip
    Error row colSpan corrected from 4 → 3
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2026-06-14 Implement Phase 4: multi-tenant architecture, dynamic labels, and scan modes
    - Add institution_id to verifySession(); scope all dashboard queries per tenant
    - Load InstitutionConfig in layout; pass to sidebar, mobile nav, and page labels
    - Replace hardcoded OLAG branding and Student/Class/Term strings with dynamic
    institution labels (label_member/members/group/unit/period)
    - Rename /students → /members throughout (route, actions, revalidatePath, nav)
    - Devices: show unassigned (pending) devices for platform_admin; add AssignDevice
    dialog with full institution dropdown; add mode (present_absent / time_in_out)
    field to device add/edit
    - Members: add member_type (student/staff/member) c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
2026-06-14 feat: multi-tenant UI — office/school separation, remove member type, branch labels
    - Attendance page: staff member MultiSelect filter; type filter options driven by
    institution tracking config; platform_admin type filter reflects selected institution;
    student filter label reads "Students" for platform_admin; type filter resets on
    institution change; office institutions hide all student-related UI
    - Navigation: /members conditional on track_students; /staff conditional on
    track_staff (always visible for platform_admin); Academic and Promotion hidden for
    office institutions; mobile bottom nav regression fixed (Academic restored to primary
    nav for schools)
    - Settings form: Track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
2026-06-14 feat: two-phase device assignment — platform admin binds institution, institution admin configures group/unit
    Removes group/unit fields from AssignDeviceDialog (platform admin now only picks the institution).
    Adds "Pending setup" section for institution admins to configure group/unit on newly assigned devices.
    Removes "Add device" from institution admin view — devices enter the system through physical provisioning only.
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2026-06-15 Add batch of testing fixes across devices, members, accounts, and calendar
    Devices:
    - Add search + institution filtering to the devices page
    - Remove manual device creation; devices only enter via provisioning
    - Use searchable dropdown for institution assignment
    - Preserve linked records on device deletion (FKs ON DELETE SET NULL);
    deactivate the device's members before deletion
    Members & staff:
    - Platform admin must choose institution + unit when adding a member
    - Filter the members/staff list by institution
    - Fix "a/an" grammar for unit labels ("a unit", not "an unit")
    - "Member added" copy uses the institution's member terminology
    Accounts:
    - Platform admin must specify an institution w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
2026-06-15 Security hardening: tenant isolation, TLS, provisioning tokens, schema fixes
    Fixes from a full adversarial code review across frontend, backend, firmware, and DB.
    Auth & tenant isolation
    - verifySession() now fails closed — no silent role default (C1)
    - Public signup disabled in Supabase config (C1)
    - New ownership.ts guard applied to all mutating actions: members, staff,
    devices, academic, enrollment, users, promotion (C2/C3/H4/H5/H6/M6)
    - superAdminCount scoped per-institution; admin password change restricted
    to self-only; promotion blocked without institutionId
    Firmware (ESP32)
    - Replaced all setInsecure() with setCACert(ROOT_CA_BUNDLE); TLS now
    validates against a pinned root CA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
    [ClassAttendance_Current_RTC.ino]
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2026-06-16 Redesign dashboard UI with neutral design system, dark mode, and per-institution theming
    Full visual overhaul of the dashboard across every page, role, and institution
    type. Adopts a restrained, neutral-grayscale aesthetic (Linear/Vercel direction)
    while keeping all functionality and the shadcn/base-ui component library.
    Foundation:
    - Rewrite globals.css as a neutral OKLCH token system with full light + dark sets
    - Unify semantic status tokens (success/warning/destructive); drop hardcoded badge greens
    - Switch surfaces from rings to border + shadow-xs; switch UI font to Inter, Geist Mono for numerals
    - Add dependency-free dark mode: pre-paint inline script + ThemeToggle (sidebar, mobile, log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
2026-06-18 Update attendance-view.tsx
    Fixed 'absent' records changing to 'present' when filtered for a single member
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2026-06-27 Shop architecture: currency, offerings, deactivation, loyalty toggles
    - Per-institution ISO-4217 currency (institutions.currency); all money
    formatting routed through formatMoney(); reports + CSV exports honour
    tenant currency, takings export honours tenant timezone
    - Module-level offerings toggles (sell_products / sell_services) gating
    catalog page/tabs, sales picker, and nav
    - Institution lifecycle status (active/suspended/deactivated): enforced
    in verifySession() (dashboard chokepoint) and both device edge
    functions — log-attendance returns 403, mark-absent skips inactive
    tenants; adds /suspended landing page
    - Loyalty master switch (loyalty_enabled) gating rewards nav + /re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
2026-06-27 Shop architecture: loyalty eligibility engine + cashier-member link
    - Loyalty eligibility engine (lib/loyalty/eligibility.ts): pure evaluateReward()
    covering visit_count, service_count, product_count, total_amount_spent;
    three window types (lifetime, rolling_days, since_last_issuance); repeatable
    vs non-repeatable; scoped condition_service_id / condition_product_id.
    - Per-client loyalty dialog (client-loyalty-dialog.tsx): progress bars, eligible
    badge, issue-reward button for admins; cashiers see progress only.
    - getClientLoyalty() server action: builds LoyaltyEvent[] from attendance,
    transactions, and transaction_items (via transactions!inner join filtered by
    client_id); evaluat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
2026-06-27 Fix logo fallback, nav loader, shop labels, visit→sale flow, 404 redirect, and sales/rewards pagination
2026-06-28 Security hardening, queue durability, and UX fixes across firmware, edge functions, and frontend
    Schema (not yet applied):
    - Per-device secrets (devices.device_secret + revoked) replacing shared institution secret
    - profiles.assigned_device_id FK for teacher scoping with backfill
    - institution_activity watermark table + triggers on attendance/members/devices/periods
    - Remove REPLICA IDENTITY FULL / Realtime pub from tables no longer using SSE
    Edge functions:
    - assignment-poll: issues unique per-device secret on first assignment
    - log-attendance: dual-path auth (per-device secret preferred, shared secret fallback)
    - get-enrollment-job: per-device auth; decommission signal persists until re-re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
    [ClassAttendance_Current_RTC.ino]
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2026-07-03 Revert "Added Power Bank Slot"
    This reverts commit 138de974fe71cc9c1c9d8ca143d88786cf41069b.
    [Fingerprint Device Enclosure.FCStd]
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2026-07-31 Replace hand-rolled JSON parsing with ArduinoJson v7
    Every JSON parse and serialise site in the firmware used hand-rolled
    indexOf/substring scanning, with four near-identical extractStr lambdas
    duplicated across loadDeviceIdentity, loadProvisioning, registerDevice and
    pollAssignment. Replaced all of them with ArduinoJson v7 and deleted
    jsonEscape(), since the library escapes on serialise.
    Converted: loadDeviceIdentity, loadProvisioning, saveDeviceIdentity,
    saveProvisioning, registerDevice, pollAssignment, reportEnrollUpdate, the
    EnrollmentTask poll and job parse, the attendance payload, and the OTA
    release parse.
    Three correctness improvements beyond the cleanup:
    - Enrollment job fields are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
    [ClassAttendance_Current_RTC.ino]
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2026-07-31 Guard registerDevice() against an incomplete "assigned" response
    /register deliberately withholds institution_id/device_secret when a MAC
    is already assigned -- releasing them there would let anyone holding just
    the shared bootstrap secret re-extract a live device's credentials by MAC
    alone, no physical possession required.
    The firmware didn't account for that: it treated status=="assigned" as
    always complete and saved an identity file with empty institution_id/
    device_secret. Since deviceId is set as a side effect earlier in the
    function, the device would then never call registerDevice() again,
    bricking silently. Now validates both fields are non-empty before
    committing to saveDeviceIdenti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
    [ClassAttendance_Current_RTC.ino]
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2026-08-01 Send display_name unconditionally on every get-enrollment-job poll
    register/assignment-poll only ever set a device's display_name once, at
    initial assignment -- a later rename in the dashboard had no channel back
    to the device. Sent alongside the existing device_config_* fields (not
    gated on device_config_rev, since a rename doesn't touch config_rev) so
    firmware picks it up within one 10s poll cycle instead of never.
2026-08-01 Add SSD1306 display foundation (Phase 3 OLED)
    Wire.begin(21,22) and SSD1306 init move to the very top of setup(), before
    the captive portal branch and the up-to-15s WiFi connect -- the windows
    where the sensor LED isn't yet under our control and the device would
    otherwise look dead. No hard dependency on the panel: if init fails,
    displayAvailable stays false and every display.* call is a no-op.
    Adds a 5-tier state table + mailbox (postDisplayState()/clearDisplayState()),
    Core-0-safe -- NetworkTask/EnrollmentTask post tier state but never touch
    `display` directly. FingerprintTask (Core 1) is the sole owner: dirty-flag
    rendering, called every loop iteration but only actually flushing the ~1KB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
    [ClassAttendance_Current_RTC.ino]
2026-08-01 Sanitize UTF-8 text before rendering on the OLED
    Adafruit_GFX's default font only covers single-byte CP437-style glyphs.
    Printing a raw UTF-8 string prints one wrong glyph per byte -- an em dash
    (U+2014, encoded as 0xE2 0x80 0x94) rendered as three garbage characters,
    one of them pi, on the very first bench test of the idle screen.
    sanitizeForDisplay() decodes UTF-8 sequences and transliterates common
    smart punctuation (em/en dash, curly quotes, ellipsis) and the Latin-1
    Supplement accented-letter block to ASCII, falling back to '?' for
    anything else rather than rendering the wrong glyph. Applied at the
    render boundary only (showBootSplash/renderIdleScreen) -- the raw UTF-8
    stays in device_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
    [ClassAttendance_Current_RTC.ino]
2026-08-01 Add scan path display cards (Phase 4 OLED)
    Cards for matched+queued, matched-but-unmapped, no match, sensor error,
    and cooldown. Cooldown now actually shows the remaining seconds instead
    of computing and discarding them.
    Matched scans are a two-phase card: "SCANNED" + name immediately, patched
    to the real verdict (PRESENT/TIME IN/TIME OUT/NOT LOGGED/ERROR) when
    flushQueue's response comes back, correlated by scan_id with a single
    pending slot and a 4s window. That single-slot design is also the entire
    batch-flush suppression mechanism -- a backlog of dozens of records after
    a reconnect just overwrites the one-slot verdict mailbox repeatedly, and
    none of them match whatever scan is actively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
    [ClassAttendance_Current_RTC.ino]
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2026-08-13 Add persistent/degraded display states (Phase 6 OLED)
    Final phase of the OLED integration plan: offline+queue-depth banner
    over idle, awaiting-assignment/rejected/revoked Tier 2 cards keyed off
    the device MAC, a brief confirmation screen before decommission wipes
    identity, live OTA flash progress via Update.onProgress(), and direct-
    draw fallback screens for the two fatal while(1) init-failure paths.
    Queue depth/dropped-record counts are maintained as in-RAM counters
    (seeded from disk at boot, adjusted on enqueue/flush/drop/cap-eviction)
    rather than recomputed by scanning SPIFFS on every repaint.
    FIRMWARE_VERSION bumped to 1.8.0. Not compile-verified.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
    [ClassAttendance_Current_RTC.ino]
2026-08-14 Update client manuals for OLED display, WiFi provisioning, and CSV import
    The docs predated Phases 2-6 OLED work and never documented physical
    device setup at all (WiFi captive portal, master fingerprint, OLED/LED
    states), so a client had no accurate guide for onboarding a device.
    Verified against current firmware source, not assumptions:
    - Super_Admin_Manual: add first-time WiFi setup, master-finger
    enrollment (and the day-1-enrollment recommendation, since skipping
    it means WiFi changes later require a physical reflash), the
    master-finger WiFi-reconfigure flow, and full OLED/LED reference
    tables. Also document the CSV bulk-import feature under Members.
    - Admin_Manual: document CSV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
2026-08-14 Guard master-fingerprint slots and fix attendance column label for staff-only institutions
    The enrollment overwrite check only looked at members.fin1/fin2, so a
    register (or register-master, which skipped the check entirely) could
    silently clobber a device's master fingerprint slot with no warning.
    enrollment_jobs is the only record of master-fid occupancy (no
    dedicated table), so derive it from the latest completed
    register-master/delete-master job per device+fid and extend the
    existing confirm-before-overwrite flow to cover it.
    Also fix the attendance page's member-column header: it always started
    from label_member and only added label_staff when an institution
    tracked both types, so a st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
2026-08-17 Fix offline scans getting stuck absent after mark-absent runs
    log-attendance did a plain insert keyed on (member_id, date, scan_type),
    so a late-arriving offline scan that landed after mark-absent had already
    written an absent placeholder for that slot hit a unique-violation and
    was discarded as a "duplicate" -- leaving the member marked absent even
    though they actually scanned in. Now a conflict against an absent
    placeholder updates it to present instead of dropping the scan; a
    conflict against a real present row still counts as a true duplicate.
    Also fixes the same root cause in time_in_out mode, where an absent
    placeholder for scan_type "time_in" was counted as a completed time-in,
    misfi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
2026-08-17 Enable RLS on institution_activity
    The watermark table was created with RLS left disabled, which combined
    with the default anon/authenticated table grants left every
    institution's last_change_at fully readable and writable by anyone
    holding the public anon key. Flagged by the Supabase security linter.
    Adds a member-scoped select policy (mirrors institutions_member_select)
    and switches touch_institution_activity() to SECURITY DEFINER so the
    watermark trigger keeps working regardless of RLS on the table. The
    follow-up migration revokes the public EXECUTE grant that SECURITY
    DEFINER implicitly adds, which doesn't affect trigger firing.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
2026-08-23 Fix devices unique constraint to scope by institution
    devices_class_form_unique predated multi-tenancy and was never updated
    when group/unit columns were renamed and institution_id was added,
    so two devices in different institutions couldn't share the same
    group+unit combo. Scope the constraint to (institution_id, group_name,
    unit_name) instead.
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2026-09-02 Make the dashboard installable as a PWA
    Adds a home-screen install path for the Next.js dashboard so phones and
    tablets can launch it standalone instead of through a browser tab.
    - app/manifest.ts: web manifest served at /manifest.webmanifest
    (standalone display, platform-branded fingerprint icons, theme colours).
    It's fetched before login, so it carries no per-institution branding.
    - public/icons/: SVG sources + committed PNGs (192/512 any + maskable,
    180 apple). scripts/generate-icons.mjs rasterises them via sharp, which
    is already resolved as an optional dep of Next — no new package. Run
    with `npm run gen:icons` after editing a source SVG.
    - public/sw.js: a minimal service wo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
2026-09-02 Firmware: server-reachability watchdog + durable enrollment reports
    Two field failures, same root: the device could not tell "WiFi
    associated" from "server reachable", and enrollment status reports had
    no durability.
    Server-reachability watchdog:
    - postJSONToUrl() feeds markPostResult(); NET_UNREACHABLE_FAILS (5)
    consecutive failed POSTs on a live link => serverReachable=false.
    - The idle screen now shows "No server" (not a misleading "Online") and
    the Tier 3 degraded banner is raised.
    - NetworkTask escalates: force a WiFi re-associate every 60s, then
    ESP.restart() after 5 min of a live link with no successful POST.
    Never mid-OTA, mid-enrollment, or under a takeover screen.
    - Plus a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
    [ClassAttendance_Current_RTC.ino]
2026-09-02 Dashboard: retry / cancel controls for enrollment jobs
    Failed and stuck jobs were a dead end on the enrollment page — a red
    "failed" badge with a truncated raw note ("slot-occupied") and no way to
    act on it.
    - Failed jobs show last_error and a "Re-queue" button. When the failure
    was slot-occupied, a "+ overwrite" button re-queues with
    allow_overwrite=true — the escape hatch for a slot that reads free in
    the DB but the device rejected as in use (orphaned template).
    - in_progress jobs older than 2 minutes are flagged "No response for Nm"
    with Retry / Cancel. Retry inserts a fresh job and retires the stuck
    one; the DB status guard forbids resurrecting a terminal row, so retry
    i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
2026-09-02 Optionally bind an institution admin to a single device
    An admin account can now be pinned to one device: they see only that
    device's attendance / members / overview, and can run register / delete
    enrolment jobs for that device only — no master fingerprints, no
    clear-all, no other devices. Leaving the assignment blank keeps today's
    full-institution access (opt-in per account).
    - lib/supabase/dal.ts: resolveDeviceScope(session) — one place that
    resolves teacher/staff (always scoped) and admin (scoped when bound),
    FK-first with the legacy assigned_unit string as fallback. Returns
    'all' | { device } | 'none'.
    - users actions/dialog now persist profiles.assigned_device_id (the FK)
    a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
2026-09-02 Firmware: harden the two new reboot paths
    - job.memberId: read member_id and student_id as two separate
    ArduinoJson `| ""` fallbacks instead of chaining `a | b | c`, which
    isn't a documented form.
    - heap-fragmentation reboot: add a 5-minute post-boot grace window so a
    device that merely boots with a tight largest-free-block can't enter a
    reboot loop. A genuine fragmentation wedge takes hours to develop.
    [ClassAttendance_Current_RTC.ino]
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2026-09-28 Club mode Phase 4: ad-hoc meetings from the session-master finger, offline too
    The session-master finger opens a meeting with one press and closes it
    with a confirmed second press, with or without WiFi. The device names
    each meeting (device_ref); the open event, the close event and every
    scan taken during it carry that ref and the open time through the
    normal offline queue, so whichever reaches the server first creates the
    meeting. Replay order, retries and lost replies can't lose or duplicate
    it.
    Database (applied to cloud 2026-09-28):
    - meetings.device_ref + UNIQUE (device_id, device_ref).
    - device_meeting_event(): create-if-missing, closes only move closed_at
    earlier, one open ad-hoc m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
    [ClassAttendance_Current_RTC.ino]
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2026-09-30 Fixed the OLED screw hole distances. FINALLY (I hope)
    [Fingerprint Device Enclosure-OLED_Outer_Shell.3mf, Fingerprint Device Enclosure.FCStd]
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
